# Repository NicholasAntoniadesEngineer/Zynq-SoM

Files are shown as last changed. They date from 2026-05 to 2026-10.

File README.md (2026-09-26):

# Zynq-SoM

A Zynq-7000 system-on-module + carrier board, with `schgen` — a netlist-first
KiCad schematic **and PCB** generator migrating to C++ netlist definitions
into electrically-proven, hand-drawn-quality schematics and a placed,
DRC-clean board (component placement, 3D models, multi-angle renders).

## Native build and test entry point

The C++ migration's Python-free build, dependency bootstrap and complete native
CTest entry point are documented in [`native/ci/README.md`](native/ci/README.md).
Use that path for native production builds. The transitional Python extension
and its build script are retired. Native `schgen check --tests-dir BUILD` runs
the full board, mutation/determinism selftest and complete CTest inventory.
All 393 inventoried tracked Python sources and tests are retired, along with
their dependency and lint configuration. Clean-tree acceptance is still in
progress; the commands below use the native executable.
All verification remains local, as required by the repository's no-CI policy.
No hosted workflow or gate bypass is introduced.

## The layers

1. **`parts/`** — one folder per physical part, named by MPN, GENERATED from
   LCSC/EasyEDA (`native/bin/schgen part-import --parts-root parts --lcsc C…`):
   pin table, symbol, footprint, 3D.
   See `parts/README.md`.
2. **`subsystems/`** — project-agnostic subsystem assets: interface contracts,
   READMEs, SPICE subcircuits and independent reference data. C++ netlist
   factories live in `native/src/authoring_*.cpp`; project adapters supply
   `bind`/`expects`/`buses`/`notes` metadata through the native registry.
   Scaffold a new one with `native/bin/schgen subsystem-new <name>`. See
   `subsystems/README.md`.
3. **`carrier/subsystems/`** — board subsystem assets and generated circuit
   projections. C++ project factories and adapters in `native/src/project_*.cpp`
   define the netlists; the J1/J2/J3 connector contract is extracted live from
   the SoM. Parts are resolved by library identity and named pins. See
   `carrier/README.md` and `carrier/subsystems/README.md`.
4. **The board** — `schgen` derives ALL geometry from netlist topology,
   proves it (netlist-equivalence + ERC + zero-overlap visual gates) and
   links the sheets into one KiCad project.

Plus `som/` — the hand-authored Zynq SoM KiCad project (open
`som/Zynq_SoM.kicad_pro`, KiCad 9+; its custom libs live in `som/lib/`).
The SoM↔carrier contract `carrier/som_interface.json` is extracted
programmatically (`schgen som-interface`), never hand-edited.

## Native regeneration

```bash
native/bin/schgen board --project carrier --timing
native/bin/schgen board --project devkit_mini --timing
# Diagnostic generation without output renders:
native/bin/schgen board --project carrier --no-render --timing
```

`--no-render` is diagnostic: it skips output renders, not mandatory electrical,
geometry or source-policy gates. Omit it for rendered acceptance. Use `--timing`
to measure this native implementation; historical Python timings do not apply.

`schgen build <name>` gates a single sheet (preview into a tempdir, nothing
committed). `schgen board` regenerates the committed outputs in place:
`carrier/Zynq_Carrier.kicad_pro` (open in KiCad), `schematic/`, `renders/`
(golden-snapshot drift detection), `reports/`,
`manufacturing/` (JLC BOM + layout constraints), and
`fpga/Zynq_Carrier_pins.xdc` — Vivado PACKAGE_PIN + IOSTANDARD for every
carrier port on a Zynq PL ball, ball map live-extracted from the SoM and
cross-checked against `som_interface.json` (also standalone: `schgen xdc`).

## The gate model

Every build fails unless every gate passes — the gates are judges, not knobs.
Schematic gates: **netlist** (KiCad's extracted netlist == the declared netlist,
pin for pin, so a junction that merges two nets is caught as a short), **ERC**
(zero errors), **visual** (zero overlap, zero wire crossings, junction-aware
short detection, fits the page). PCB gates: **DRC** (zero KiCad errors),
**3D-model** coverage + placement, **ratsnest** subsystem clustering, and
**connector** mating-face / spacing (off-board mouths, edge-flush). Architecture
+ gate definitions: `schgen/DESIGN.md`.

Local generation always runs its gates; native CTest is an additional check,
not a replacement. `schgen selftest` mutation-tests the gates themselves:
it injects one defect per class (pin swap, deleted wire, relabel, stray
no-connect, foreign-net junction short) and proves a gate kills each, then
builds twice and byte-compares for determinism.

```bash
native/bin/schgen selftest
```

## Process + where to read more

- The working rules and process contract (the immutable LAWs, the gate stack,
  the worktree/commit discipline) live in
  [`WORKING_GUIDELINES.txt`](docs/WORKING_GUIDELINES.txt).
- Layer guides: [`parts/README.md`](parts/README.md),
  [`subsystems/README.md`](subsystems/README.md) (the reusable library),
  [`carrier/README.md`](carrier/README.md),
  [`carrier/subsystems/README.md`](carrier/subsystems/README.md),
  and the engine contract [`schgen/DESIGN.md`](schgen/DESIGN.md).

<!-- schgen:gallery -->
<!-- GENERATED by `schgen gallery` — edits between these markers are overwritten -->
## Generated board + schematics

`schgen board` regenerates the placed-board 3D views, the block diagram and all 37 carrier sheets,
each PNG passing the netlist, ERC and visual gates.

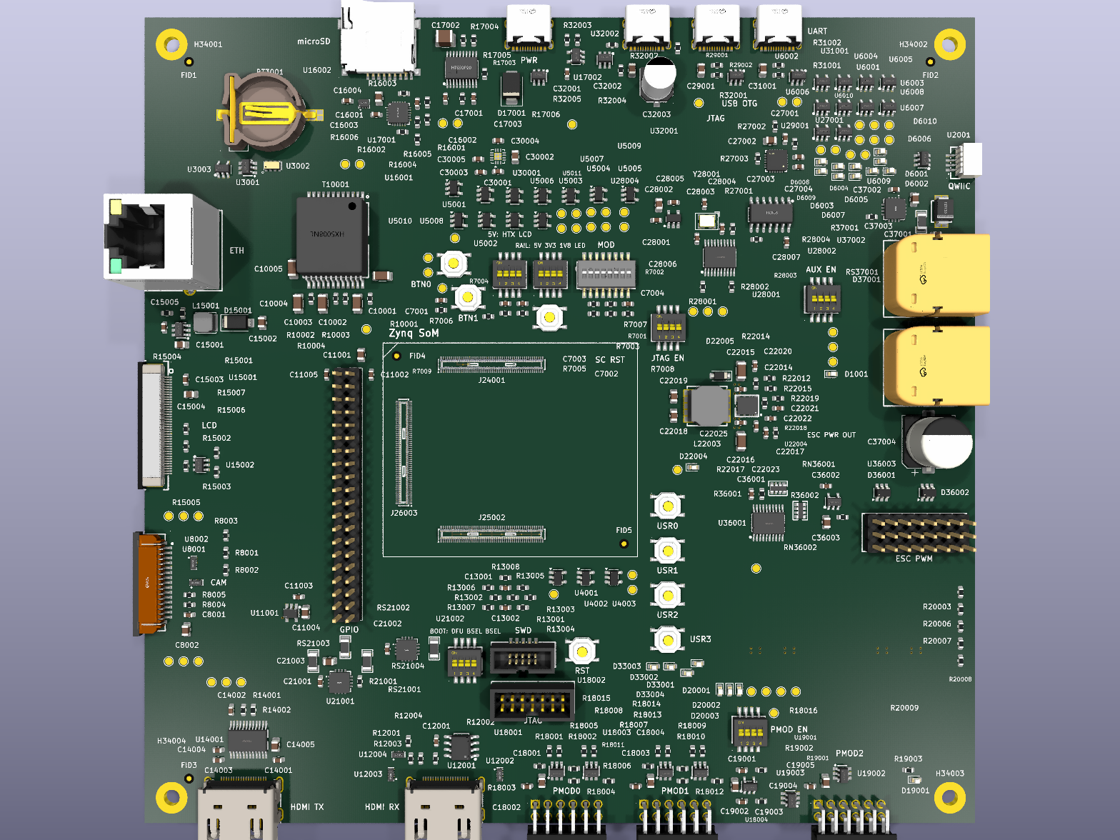
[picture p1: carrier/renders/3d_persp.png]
Generated 3D board render (perspective)


Generated block diagram

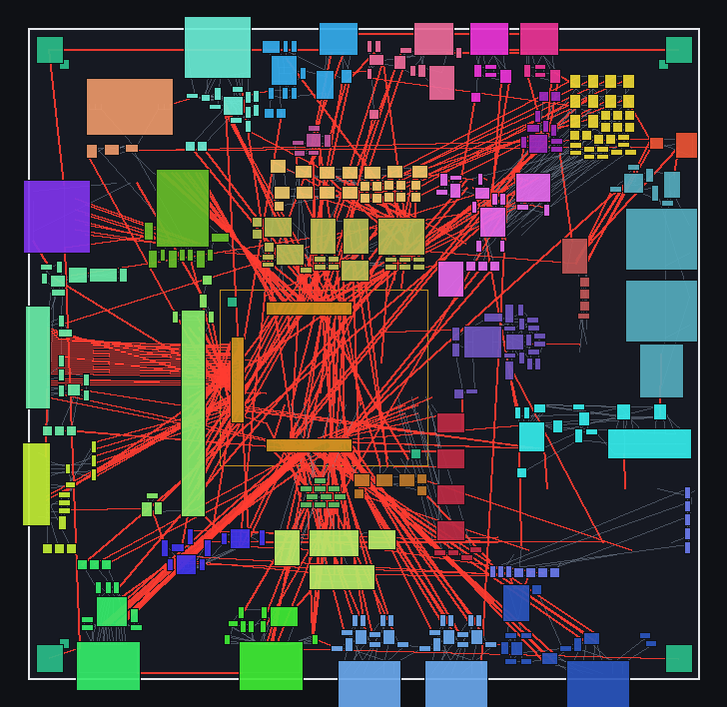
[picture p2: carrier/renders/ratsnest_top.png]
Board ratsnest (top)
[](carrier/README.md#ratsnest-views)<br>**[Ratsnest views](carrier/README.md#ratsnest-views)** — airwires per subsystem.

See **[carrier/README.md](carrier/README.md#generated-3d-board-views)** for all 8 board views + the full sheet gallery (thumbnails + descriptions).
<!-- /schgen:gallery -->

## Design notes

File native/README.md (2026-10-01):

# Native migration

The target is a complete C++ generator, including design loading, placement,
routing, emission, verification, CLI, and tests. The Python extension and the
393 inventoried Python sources/tests are retired. Native kernels alone do not complete the port.
Final acceptance requires zero repository-owned Python sources, tests, helpers,
bindings, or runtime dependencies. KiCad/design data, FPGA HDL, and generated
XDC/Tcl remain in their required hardware formats; generator/tooling code is C++.

## Build without Python

For the native-only full CTest workflow and offline dependency bootstrap, see
[`ci/README.md`](ci/README.md). That additive entry point needs CMake 3.28+ and
explicitly checks installed KiCad libraries. Native contracts retain independent
parity fixtures; no Python test runtime is required.

Install the pinned native zlib-ng compressor using the instructions in
[the manufacturing handoff](tests/data/manufacturing/README.md#explicit-native-installation-and-parent-wiring).
It must be the tested static/PIC compatibility build so existing PNG bytes remain
identical. Supply its installed prefix explicitly; CMake verifies the version
and a compression known-answer test rather than silently selecting system zlib.
The example below uses the local dependency installation under the ignored build
directory. From the repository root:

```sh
cmake -S native -B native/build/standalone -DSCHGEN_BUILD_PYTHON=OFF -DCMAKE_BUILD_TYPE=Release \
  -DSCHGEN_MANUFACTURING_ZLIB_PREFIX="$PWD/native/build/deps/zlib-ng"
cmake --build native/build/standalone --parallel
ctest --test-dir native/build/standalone --output-on-failure
native/bin/schgen --help
```

For repeated local C++ development with Ninja and ccache installed, run these
from `native/` (CMake 3.20+ for presets): `cmake --preset native-fast`, then
`cmake --build --preset native-fast` and `ctest --preset native-fast-offline`.
The preset keeps compiler caches under ignored `native/build/`; it neither
downloads dependencies nor enables Python. Ninja avoids Make's broad object
rebuilds when unrelated per-source compilation options change. Do not build
different build directories concurrently: they currently publish the same CLI
and catalogs in the source tree.

This is also the default configuration: enabling retired Python bindings is an error. The build
uses C++17, libxml2 (for KiCad netlists), native zlib-ng (for exact manufacturing PNGs),
and Poppler C++/libpng (for schematic rasterization), without discovering Python,
installing nanobind, or fetching dependencies. Live SoM extraction requires
`kicad-cli` on PATH; it is invoked directly, never through a shell.

The native CLI supports `self-check`, `catalog-compile`, `circuit-compile`,
`project-check`, `circuit-check`, `som-interface`, `link`, `bom`, `xdc`, `vivado`, `fpga`, and
`devicetree`, `design-rules`, `testpoints`, `constraints`, `powertree`, `thermal`,
`part-rules`, `bom-values`, `footprint-pads`, `pin-completeness`, `symbol-law`,
`spice`, `firmware`, `manual`, `scfw`, `testplan`, `power-sequence`, and `selftest`.
The native `board` command performs full generation with mandatory native audit
providers; its complete source-audit acceptance is still in progress. Other
integrated commands include `build`, the four-sheet `devkit` example, `nets`,
`subsystem-check`, `carrier-check`, and the native experiment commands.
`check --tests-dir BUILD` runs full board generation, mutation/determinism
selftest and every configured native CTest, requiring complete passing JUnit
evidence. It does not build its selected test directory or waive failing gates.
Unsupported commands fail.

`subsystem-new NAME` creates a C++ source/header/test package with retained
README, SPICE and JSON metadata. It never overwrites an existing destination.
New packages are opt-in with `-DSCHGEN_SUBSYSTEM_PACKAGES='name;another'`;
the generated CMake registration connects real factories to the immutable
native registry. The initial unimplemented builder deliberately fails its test.

The PCB verification aggregate now shares one geometry snapshot and MST across
the real placement, connector, ratsnest, fanout, return-stitch and escape gates.
Both live projects are checked against independent committed reports. This is
not yet the full-board verdict: external DRC and non-PCB gates remain separate.
The native DRC runner invokes KiCad directly with a bounded timeout and private
report directory. Missing/malformed reports and nonzero tool exits are errors,
not empty successful findings. Its transitional adapter contains no DRC logic.
Use `native/bin/schgen pcb-drc --project NAME` to check an existing board. The
full build reuses validated severity counts from its first DRC report instead
of refilling and checking the same board twice. Reports lacking severity retain
an explicit errors-only fallback; warning and unrouted findings remain visible.

`selftest` runs the complete 63-mutation suite through real KiCad exports, ERC,
native gates, geometry checks, and fresh native worker processes. It does not
invoke Python. Worker failures and missing footprint libraries fail the run;
they cannot count as mutation kills. The separate `self-check` remains only a
small kernel smoke test. Live contract tests carry the `live-kicad` CTest label.

The native core includes complete floorplan search/compose/export, immutable
PCB-check snapshots, and board/project/design-rule emission. Frozen independent
fixtures verify both projects' exact outputs and mutation/error cases. The
transitional PCB pipeline now uses the native writers and shares one prepared
snapshot across its PCB gates, avoiding repeated source parsing. Standalone gate
calls still prepare fresh inputs; no global cache hides placement or file edits.
The original return-path-v1 failures remain separate from return-stitch coverage;
this migration does not waive them. Standalone `floorplan` and `compose` are
registered native commands: floorplan writes documents or exports a spec;
compose measures, ranks repairs with `--repair --dry-run`, or applies a repair
subject to full board gates and rollback on failure. Their ordinary, live-KiCad
and apply contracts are registered in CTest. This is not a claim of complete
source-audit or whole-board acceptance.

```sh
native/bin/schgen project-check --project carrier
native/bin/schgen project-check --project devkit_mini
native/bin/schgen circuit-check --project devkit_mini
native/bin/schgen design-rules --project devkit_mini
native/bin/schgen testpoints --project devkit_mini
native/bin/schgen fpga --project carrier --output /tmp/carrier-fpga
native/bin/schgen devicetree --project carrier --output /tmp/carrier_pl.dtsi
native/bin/schgen bom --project carrier --qualified-refs --output /tmp/carrier-bom.csv
```

`fpga` generates XDC and Vivado Tcl from one live extraction, validating both
before publication. Each output is atomically replaced. Project selection is
explicit (`--project`), then `SCHGEN_PROJECT`, then `carrier`; use `--repo` when
running outside the repository root. Circuit discovery and loading require
canonical `<project>/subsystems/<name>/circuit.json`, not authoring Python.
Function/rail/strap policy is in each project's `som_mapping.json`.

`circuit-check` resolves actual library symbols and checks every pin and internal
input driver; JSON pin metadata is not a substitute for physical symbol pins.
`link` also enforces symbol-backed completeness before linking. The native core
now includes complete symbol loading, schematic emission, routing, netlist and visual
validation stages, tested against frozen inputs and output bytes. Netlist verification
shares the hardened KiCad process/XML boundary with SoM extraction, and checks
connectivity plus NC markers against embedded symbol geometry. Full board
orchestration is native; complete acceptance is tracked below.
The hierarchical schematic stage is independently available as
`native/bin/schgen board-schematic --project NAME -o DIRECTORY`. It generates
the real routed sheets and root hierarchy, preserves persistent reference bands,
and runs live KiCad connectivity checks. Per-sheet exports use bounded workers
with deterministic result collection. This command is not a substitute for the
remaining PCB, manufacturing and complete-board verification stages. Both
supported projects' native root and child schematics match the committed bytes.

The complete schematic placer now runs natively: topology classification,
fanout, regulator templates, chain layout, probe rows, retry expansion and
pagination all use the same typed engine and router. Frozen full-board and
isolated topology contracts cover ordered geometry and page boundaries. The
legacy Python engine is removed; remaining adapters preserve caller-owned
symbol snapshots and intermediate page metadata without reloading sources.
Native mutation proofs exercise missing-decoupler and incorrect clamp-layout
failures through the real completeness, routing and visual gates.

Design-rule verification (decoupling, I2C pull-ups, reset RC, configuration straps,
exposed pads), test-point coverage and their reports also run in C++. The native
commands print diagnostics, return nonzero on findings, and write a report only
when `--output` is supplied. They accept subsystem selection; board-wide pull-ups
outside the selected sheets are intentionally absent from that check.
Symbol-backed completeness remains a separate mandatory gate (`circuit-check`).
Power-tree analysis and SVG, thermal analysis with emitted-copper evidence, and
part-rating checks now execute in C++. Frozen report contracts cover both projects,
policy mutations and supplied power results. Thermal credit requires real copper
evidence; an absent PCB does not silently grant cooling credit. Transitional
adapters preserve caller-owned policy tables and typed numeric fields.
BOM-value normalization, footprint-pad coverage, pin/NC completeness, symbol
provenance and analytic/SPICE checks also run natively. Their frozen contracts
include poisoned values, disconnected pins and malformed geometry. Optional
ngspice cross-checks use a shell-free bounded process with private temporary
decks and real measurements; absence of ngspice retains the analytic gate.
Connectivity and symbol metadata are indexed once per snapshot. Mutable caller
inputs require a new snapshot; caches never silently reuse a previous board.

Bring-up facts, firmware contracts, SC scaffolds, the manual, test plan and
power-sequence SVG now use native typed inputs. Independent fixtures cover both
projects and changes to GPIOs, feedback values, addresses and required sheets.
Live U9 extraction remains authoritative. The sequence walker rejects reachable
cycles instead of looping indefinitely. Generated SC code still has a known
undefined FMC EEPROM macro, and RTC battery/charging guidance is inconsistent;
these pre-existing output defects are not treated as successful compile checks.

Carrier and devkit XDC/Tcl, and carrier BOM, match the established output bytes.
Device-tree output changes only generator/source provenance comments. Native
contract tests cover extraction, mapping, linking, project isolation, rendering
and validation failures. Clean native full-render acceptance passed for both
boards at `29d43472` on October 1, including the source and ledger audits
(66 C++ files, 155 registered transforms). The devkit's two missing
I2C pull-ups and nine uncovered probe requirements are corrected with physical
parts, without new waivers. Probe-only ports now export hierarchical sheet
connections; regulator discovery excludes measurement pads, and PCB placement
handles connector-sheet auxiliaries without moving the fixed mezzanines.

The transitional Python bindings and build script are retired. The standalone
CLI and native tests link the same `schgen_core` library; engine sources compile
once per build directory. Preserve the per-source floating-point settings:
these are part of the deterministic-output contract.

Build catalogs depend on their JSON inputs and regenerate when those inputs change.
Compilers publish complete catalogs by atomic replacement, so existing mapped
readers retain their snapshot during a rebuild. Close and reopen a catalog to
read its new version. Failed publication leaves the previous file untouched.
The transitional circuit adapter uses project-scoped `native/circuits.bin`
outputs under each project, while the parts catalog is shared. Native project
commands read validated JSON directly and do not depend on interpreter caches.
Build directories share the in-tree binary and catalog outputs, so build them
sequentially.

## Migration acceptance and remaining design work

`run_board_pipeline` is now compiled into the native library, with composed
schematic, electrical, PCB, document and audit stages. Its contracts compare
all 49 live-authored carrier/devkit circuit snapshots with canonical hardware IR,
exercise real KiCad connectivity/ERC, and reject missing mandatory stages.
The caller must open the part catalog before authoring. The native full-board
CLI installs reviewed ledger providers after loading actual board inputs.
Missing declarations or manifests fail explicitly. Clean full-render acceptance
now passes, with all 226 CTests having successful final coverage (222 from the
full run plus four corrected harness reruns, not a single 226/226 run).
See `benchmarks/2026-10-01-migration-acceptance.json` for pinned timings and scope.
Source auditing remains the dominant runtime cost. Advisory return-path,
golden-drift and coverage findings remain visible; neither board is fully routed
or claimed fabrication-ready. Coverage lint uses every wired-sheet part,
including unplaced parts. Successful migration does not certify every historical
hardware or generated-firmware design decision.

Firmware source provenance now reads canonical circuit JSON and compiled factory
registrations rather than checking for Python constructors. Independent source
inventories cover both projects, reject damaged/missing registered inputs, and
remain identical in a Python-free fixture tree. Live contracts separately check
the new provenance and unchanged generated hardware logic.

`part-import --parts-root DIRECTORY --from-json FILE` converts recorded EasyEDA
responses entirely in C++; offline mode never calls a transport. Use `--lcsc ID`
instead for an explicitly online import, `--name NAME` to override the part name,
and `--overwrite` only when replacing existing files is intended. Catalog refresh
is separate and opt-in via `--catalog FILE`. Publication validates all targets
first and replaces each file atomically, but is not a multi-file transaction.
The native tests compare 62 recorded parts (three model variants each) byte for
byte, exercise the real offline CLI and reject malformed input, HTTP failures,
oversized/truncated responses, duplicate models and symlink output targets.

The native `pcb-stage --project NAME -o DIRECTORY` command now performs live
KiCad netlist extraction, immutable input loading, floorplanning, placement,
escape planning and PCB/project/rules emission. It is a construction stage,
not a replacement for the independent full-board gates. Live contracts compare
both project PCBs byte-for-byte with their existing generated references.
Native manufacturing contracts cover assembly planning, Markdown and all 52
reference PNGs. Assembly rendering uses at most four workers with stable output
ordering; a measured 38-image carrier run improved from approximately 0.97 s to
0.39 s, including transitional transport and file publication. This is an image
stage measurement, not an end-to-end board-build speedup claim.
The equivalent ratsnest run (36 PNGs plus SVG) measured approximately 1.79 s
through the previous renderer and 0.68 s through the bounded parallel C++
renderer, with all output bytes unchanged.

Standalone `assembly`, `ratsnest`, `si-constraints`, `fab-profile` and `manifest`
commands now use native implementations. Explicit output directories retain the
project layout (`docs/`, `renders/`, `manufacturing/`). `preflight` uses native
stock/price/alternate analysis and a shell-free HTTPS-only `curl` subprocess;
it requires network access only when that optional command is invoked. Transport
errors fail explicitly instead of being reported as a confirmed missing part.
Its offline contracts use injected provider responses and never contact vendors.

Remaining work is native source-purity/audit integration, standalone geometry
commands, final Python consumer removal and clean-tree full-board acceptance.
The standalone Python experiment scripts are retired; use `chir-rung`,
`w11-sweep`, `w12-bound`, `w12-stageprobe` and `dump-circuits` on the native CLI.
Independent native contracts retain captured reference logic and negative cases.

Each stage must preserve electrical connectivity and its relevant gates, then
compare generated artifacts against the established reference. Record measured
end-to-end performance separately from kernel benchmarks. Remove Python source,
bindings, and Python build dependencies only once their consumers have moved.
Final acceptance requires generating both supported projects and running their
verification from a clean build without Python; pre-existing failures must be
reported, not suppressed.

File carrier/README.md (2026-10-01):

# carrier — the generated carrier board

Open `Zynq_Carrier.kicad_pro` with the KiCad version specified in
[`native/ci/README.md`](../native/ci/README.md). From the repository root,
regenerate the board outputs with `native/bin/schgen board --project carrier`
(the schematics, the placed
`Zynq_Carrier.kicad_pcb`, 3D renders, BOM, FPGA constraints, firmware contract,
and docs).

## Architecture (the locked decisions)

The carrier hosts a Zynq-7000 SoM over the J1/J2/J3 mezzanine:

- **Power input is USB-C PD only**, 20 V / 3 A via the FUSB302B, behind a
  TPS26631 eFuse with soft-start (controlled inrush + inlet OVP/OCP). No
  barrel jack.
- **The SoM is a 4.2–5 V module — it must NEVER see the 20 V rail** (P0, the
  most important electrical decision). An **always-on `+5V_SOM` buck**
  (its own `power_som` sheet) feeds the SoM's J1 VIN pins; always-on because
  PD negotiation is circular (the system controller must boot first).
- **Carrier bucks win over the SoM's exported rails** — the SoM's +3V3/+1V8
  on J1 are isolated (NC / TP-only); carrier rails are +5V, +3V3, +1V8, plus
  per-module **gated rails** (+5V_USB, +3V3_SD, the HDMI/LCD/CAM/PMOD/AUX
  rails) sourced by bring-up load switches.
- **Bring-up is staged with switches**: a DIP switch AND a system-controller
  GPIO override drive every regulator/module enable; per-rail power-good LEDs;
  rails come up one at a time. New board-services HW (ID-EEPROM, RTC, QWIIC,
  watchdog) sits behind the same gated `+3V3_AUX` rail and a PCA9306 I2C
  isolator (so the gated bus can never back-power the always-on management I2C).
- **microSD carries a mandatory 1.8 V ↔ 3.3 V level translator** (TXS02612):
  the SoM exposes SDIO at 1.8 V, but SD cards init at 3.3 V.
- **Stackup is JLCPCB 4-layer JLC04161H-7628**; its impedance geometry drives
  the exported layout constraints (90 Ω USB, 100 Ω TMDS/LVDS/MIPI). The user
  owns the PCB outline + placement — the floorplan kit is a suggestion.

## The subsystem / adapter pattern

A board sheet is one Python netlist under `subsystems/` — **the only
hand-written layer**. There are two flavours:

- **Thin adapters over the reusable library.** A portable subsystem lives in
  the project-agnostic top-level [`subsystems/`](../subsystems/README.md)
  library with ABSTRACT port/rail names; the carrier consumes it with a tiny
  adapter that declares ONE module-level `META` dict and forwards it —
  `return _lib.circuit(META)`. `META["bind"]` renames the abstract nets to the
  carrier's real net names (order-preserving, so the emitted sheet is
  byte-identical to a hand-written one); `expects` / `buses` / `notes` carry
  the project-specific linker deferrals, bus names and house-style prose. The
  contract is `schgen/core/subsystem.py` (`Meta`); a typo'd top-level key is a
  hard `CircuitError`. 17 subsystems use the reusable library this way (usb_pd, usbc_otg,
  uart_bridge, usb_jtag, ethernet, hdmi_tx, hdmi_rx, lcd, microsd, camera, pmod,
  pmod_expansion, pd_input, power, rj45_connector, usb_uart_connector,
  usb_jtag_connector) — see [`subsystems/README.md`](../subsystems/README.md).
- **Carrier-specific glue stays local.** Sheets that only make sense for this
  board — the J1/J2/J3 connector sheets, the bring-up + power + power-monitor
  sheets, the board-services HW, the carrier connectors — are authored directly
  under `subsystems/` as full netlists. See
  [`subsystems/README.md`](subsystems/README.md) for the authoring guide.

Either way the rule is the same: **the .py is the NETLIST, never geometry.**
No coordinates, no wire plans, no text positions; a purity gate AST-scans every
subsystem and fails the build if it defines `placer` or imports a geometry API.
All placement is derived from circuit topology by `schgen/layout/place.py`.

- `subsystems/` — the authored netlists (adapters + local glue), the only
  hand-written layer; see `subsystems/README.md`.
- `Zynq_Carrier.kicad_sch` + `schematic/` — the root sheet + sub-sheets
  (hierarchy mode, board-unique references), committed.
- `renders/` — one PNG per sheet, committed and reviewable on GitHub;
  `golden.json` holds perceptual hashes — drift warns, `schgen board
  --bless` accepts intentional changes.
- `reports/` — per-sheet ERC, gate verdicts, link report, board netlist
  gate: the proof travels with the design.
- `manufacturing/` — `bom_jlc.csv` + JLC04161H-7628 layout constraints.
- `fpga/` — `Zynq_Carrier_pins.xdc`, GENERATED Vivado pin constraints
  (`schgen xdc`): every carrier port on a Zynq PL ball through J2/J3,
  ball map live-extracted from the SoM project (never hand-typed),
  cross-checked against `som_interface.json` (stale contract = build
  FAIL), IOSTANDARD from the PLAN VCCO rail map.
- `som_interface.json` — the SoM↔carrier J1/J2/J3 contract, extracted
  programmatically (`schgen som-interface`), never hand-edited.
- `nets.py` — the GENERATED cross-sheet net-name contract
  (`schgen nets`).
- `research/` — the per-subsystem engineering dossiers (datasheet-grounded,
  hand-written): [`bringup_power_gating.md`](research/bringup_power_gating.md),
  [`camera_csi.md`](research/camera_csi.md),
  [`debug_boot_pmod.md`](research/debug_boot_pmod.md), [`fmc.md`](research/fmc.md),
  [`lcd_backlight.md`](research/lcd_backlight.md), [`power_mon.md`](research/power_mon.md),
  [`thermal_bucks.md`](research/thermal_bucks.md),
  [`usb_jtag_pmod_expansion.md`](research/usb_jtag_pmod_expansion.md),
  [`user_io.md`](research/user_io.md), [`wave3_function_map.md`](research/wave3_function_map.md).
- `docs/` — the design-documentation packet:
  [`DESIGN_SPEC.md`](docs/DESIGN_SPEC.md) (theory of operation: mezzanine
  interface, power architecture + sequencing, every subsystem),
  [`COMPLIANCE.md`](docs/COMPLIANCE.md) (per-interface checklists: HDMI,
  Gigabit Ethernet, USB 2.0, MIPI CSI-2, USB-PD, SoM bank-35 IO header),
  [`BRINGUP.md`](docs/BRINGUP.md), [`TEST_PLAN.md`](docs/TEST_PLAN.md),
  [`FLOORPLAN.md`](docs/FLOORPLAN.md), and the generated diagrams
  `block_diagram.svg` / `power_tree.svg` / `power_sequence.svg`.

## Assembly + bring-up procedure

Human steps the netlist cannot carry. Everything else — every component value
and every bind decision — is a registered basis entry in `carrier/basis.py`
(`REGISTRY` for values, `BINDS` for net binds), not prose.

**Before fab**

- **QWIIC pad order (`board_qwiic` J1).** Pads 1–4 are the QWIIC standard
  GND / +3V3 / SDA / SCL looking into the receptacle; pads 5/6 are the shell
  tabs. Confirm pad 1's location against the J1 footprint silk before release —
  a swapped power pad damages every external module plugged in.
- **Chassis star stitch (`mechanical`).** `GND` ↔ `CHASSIS_GND` must be joined
  at exactly one point in copper. See
  [`subsystems/mechanical/README.md`](subsystems/mechanical/README.md).

**Stuffing**

- **RTC backup cell (`board_services` BT1).** Fit a **rechargeable ML1220**
  (Mn-Li). The SC firmware enables the RV-3028 trickle charger, so the cell
  tops up whenever the board is powered. Do **NOT** fit a primary CR1220 (it
  would be charged) and do **NOT** fit a LIR Li-ion (its 4.2 V charge target
  exceeds the 3.3 V supply). The KH-CR1220-2 holder accepts both 12.5 mm
  chemistries, so the holder will not stop the wrong cell.
- **HDMI-RX termination (`hdmi_rx_term`).** The 8 × 49.9 Ω sink terminations
  belong physically next to Zynq bank 33, not at the connector. An optional
  0 Ω / ferrite may be fitted in the +3V3 → AVCC trace to island the supply.
- **Camera terminations (`camera` R1–R3).** Place the 100 Ω differential
  terminations at the **SoM-connector** end of the traces, not at the FFC.

**Powering up**

- Every rail and module enable is a DIP switch ANDed with a system-controller
  override, so a blank SC still boots "switches only". Bring rails up one at a
  time and read the per-rail power-good LED.
- `+5V_SOM`, `+3V3_SC` and the debug island (`+5V_DBG` / `+3V3_DBG`, alive only
  with the debug USB-C cable plugged) are **always-on by design** — they are not
  gated and will be live before you touch a switch.
- Probe every EN line and every gated rail at its own test point; the gated
  rails are probed at the SY6280 output, on the source side of the module
  connector.
- ESC leads on the `motor_pwm` header use SIG + GND only — keep the ESC's own
  BEC off the +5 V row.

## Build + gate discipline

There is **no CI** — instead every local `schgen build <sheet>` /
`schgen board` runs the full gate stack and exits non-zero on any failure, so
nothing un-gated ever gets committed. The committed `reports/` are the proof.
The gates (never edited to pass — LAW 4; strengthening one is the work,
loosening it is forbidden):

- **PURITY** — the subsystem source is netlist-only (no `placer`, no geometry
  import); AST-scanned before execution.
- **MODEL COMPLETENESS** — every pin is netted or explicitly `c.nc()`'d; every
  input is driven.
- **NETLIST** — KiCad's own extracted netlist == the declared netlist, pin for
  pin (the unfakeable electrical proof — catches shorts, opens, single-pin
  nets, NC-cheats, name drift).
- **ERC** — kicad-cli ERC, zero errors.
- **VISUAL** — zero overlap, zero crossings, fits the page (no exemptions).
- **CC short/open** — an independent net-blind union-find over the emitted
  geometry, a 2nd oracle that agrees with the netlist gate pin-for-pin.
- **BOARD GATE + LINK** — every linked net merges correctly across sheets;
  typed-port contract resolved (diff pairs, I2C, sd_bus levels, `expect=`
  deferrals).
- **POWER-TREE / TEST-POINT / THERMAL / DESIGN-RULE / SPICE** — per-regulator
  headroom, a probe per rail/bus, per-device Tj, decoupling/pull-up/strap
  completeness, and divider/feedback/ramp setpoints.
- **PCB** — the placed `Zynq_Carrier.kicad_pcb` passes DRC (zero KiCad errors),
  3D-model coverage + placement, ratsnest subsystem clustering, connector
  mating-face (off-board mouths) + spacing, and refdes-overlap; multi-angle 3D
  board renders are written for visual review.

`schgen selftest` mutation-tests the gates themselves (it injects one defect
per class — pin swap, deleted wire, relabel, stray NC, foreign-net junction
short — and proves a gate kills each) and builds twice for byte-determinism
(across PYTHONHASHSEED). Reusable subsystem packages also carry an offline
local `test_<name>.py`; cross-board gates stay aggregated at board level.

The working rhythm: build → read the gate verdicts → **open the render PNGs and
inspect them like a PCB reviewer** (the render is the deliverable) → commit per
verified unit. Heavy/parallel work runs in isolated git worktrees harvested
sequentially; deterministic output means a regen on the merged state produces
zero artifact diff. The full process contract is
[`../WORKING_GUIDELINES.txt`](../docs/WORKING_GUIDELINES.txt).

<!-- schgen:gallery -->
<!-- GENERATED by `schgen gallery` — edits between these markers are overwritten -->
## Generated 3D board views

The placed board rendered from 8 angles by `schgen board` (kicad-cli, the real component 3D models) — regenerated and committed every build, just like the sheets below.

| | | | |
|---|---|---|---|
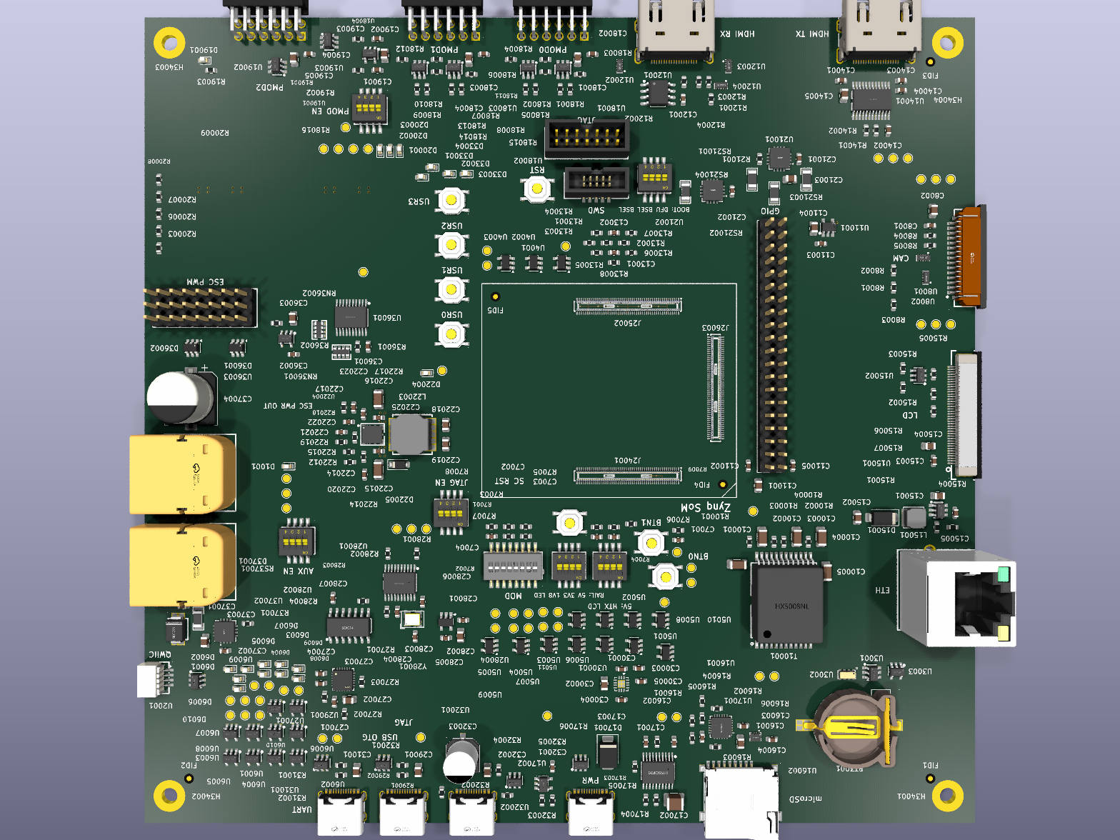
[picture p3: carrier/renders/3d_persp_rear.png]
Perspective (rear)
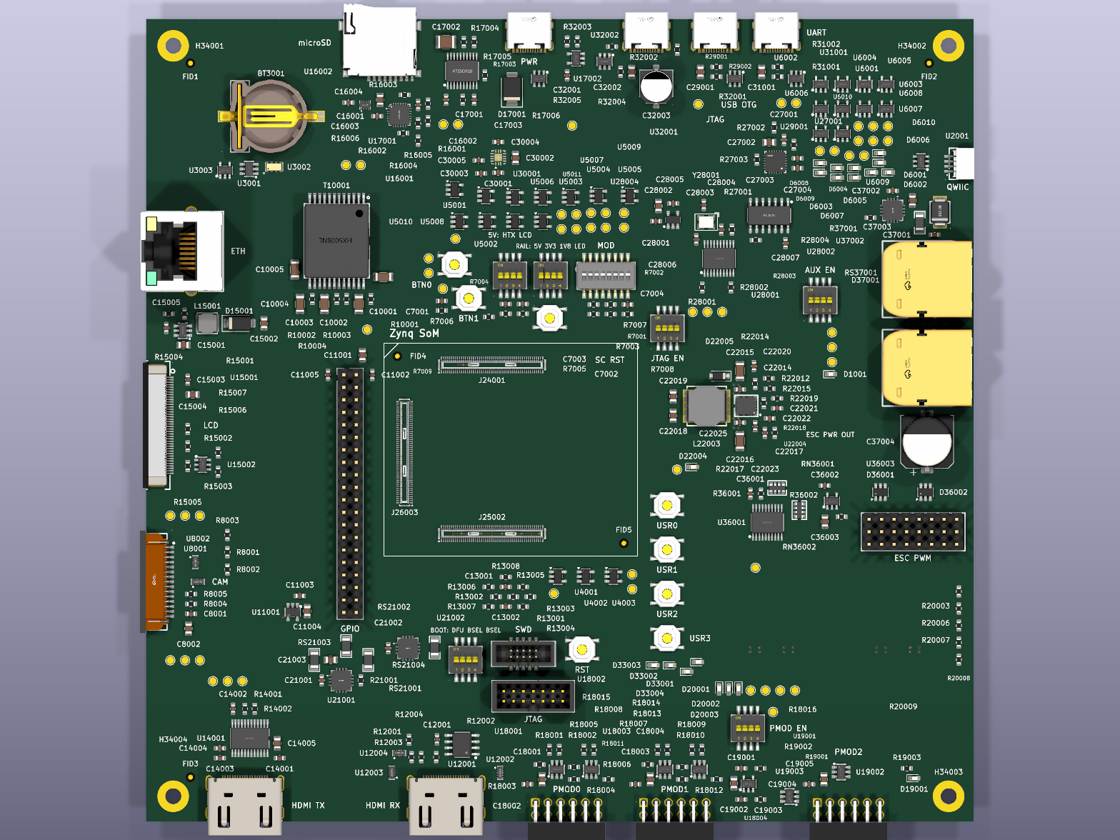
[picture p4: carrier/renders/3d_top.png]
Top
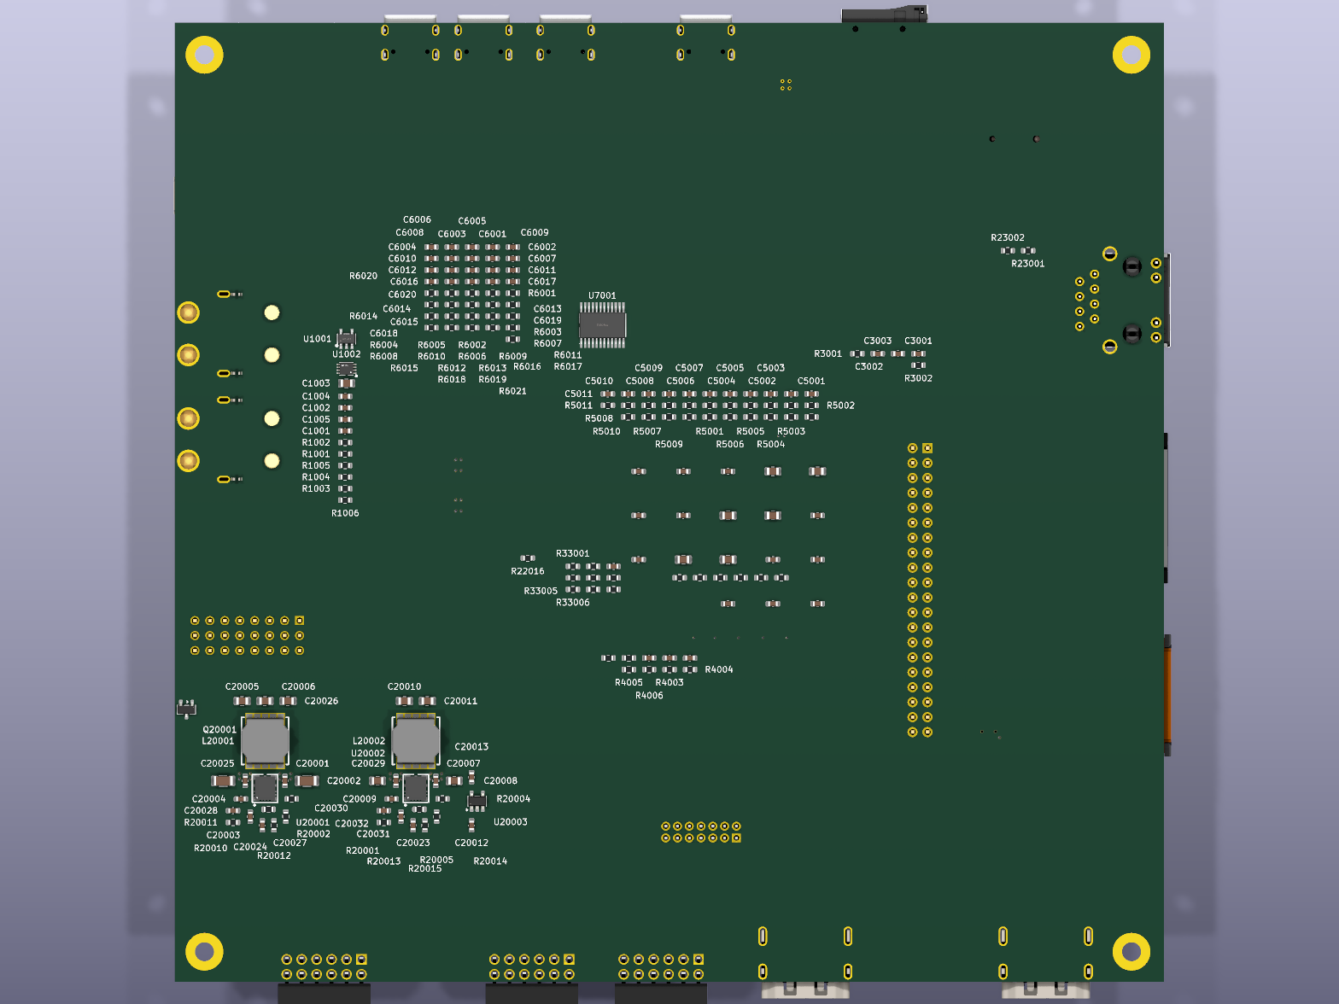
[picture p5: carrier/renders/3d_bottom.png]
Bottom
| [Perspective (front)](renders/3d_persp.png)<br>**Perspective (front)** | [](renders/3d_persp_rear.png)<br>**Perspective (rear)** | [](renders/3d_top.png)<br>**Top** | [](renders/3d_bottom.png)<br>**Bottom** |
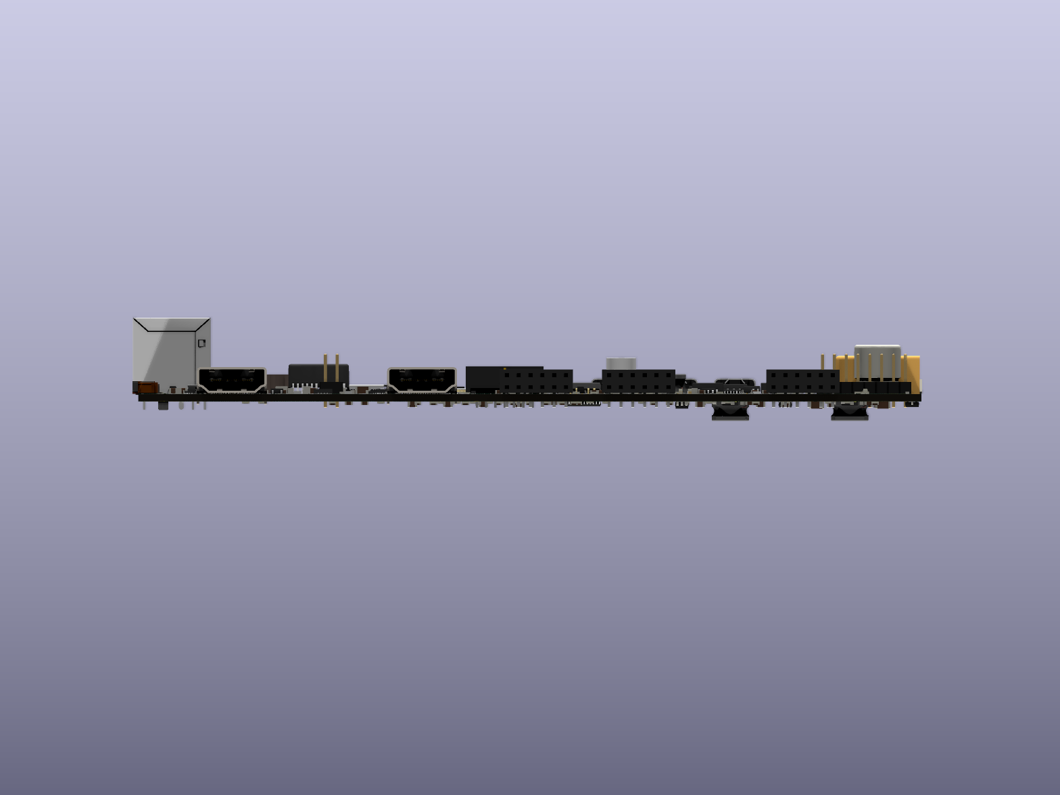
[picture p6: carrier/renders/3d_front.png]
Front edge
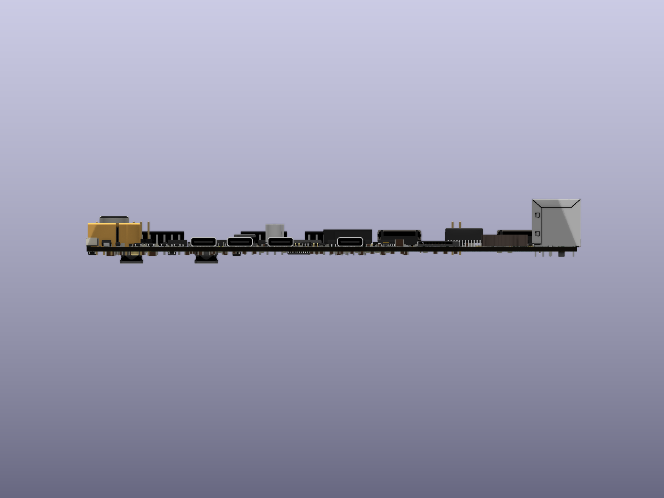
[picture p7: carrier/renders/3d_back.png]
Back edge
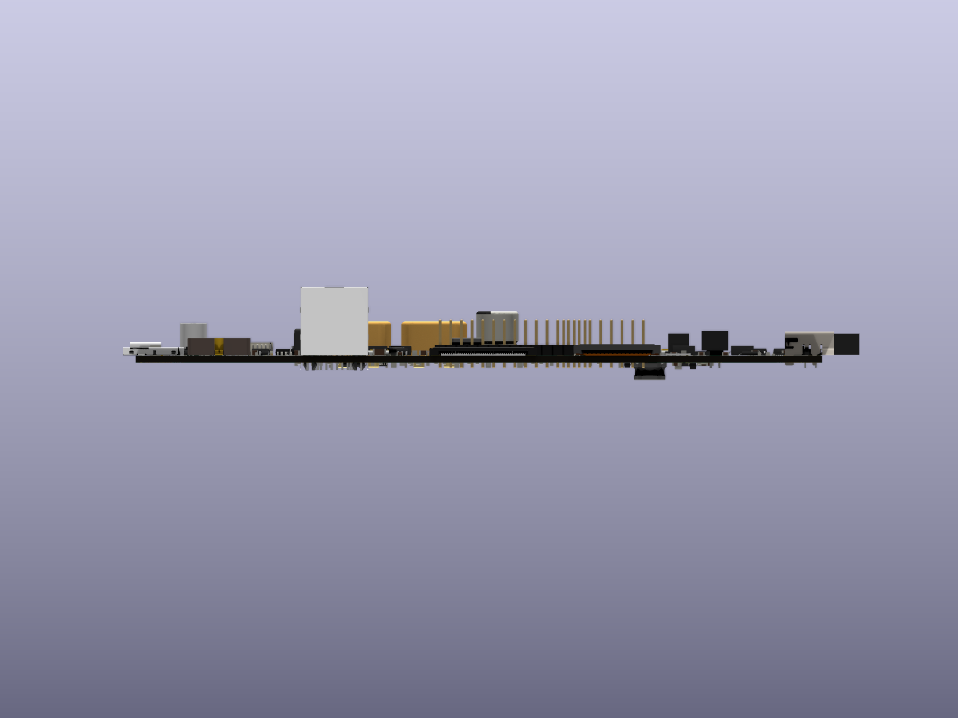
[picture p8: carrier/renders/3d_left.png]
Left edge
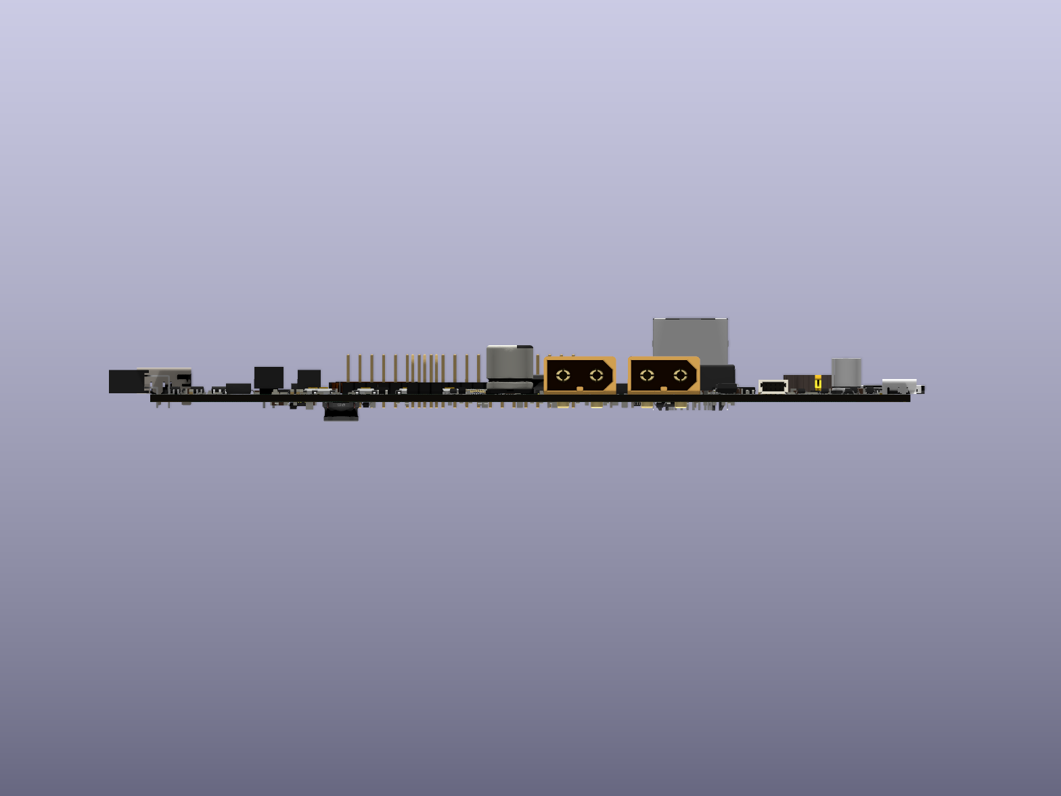
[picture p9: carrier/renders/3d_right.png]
Right edge
| [](renders/3d_front.png)<br>**Front edge** | [](renders/3d_back.png)<br>**Back edge** | [](renders/3d_left.png)<br>**Left edge** | [](renders/3d_right.png)<br>**Right edge** |

## Ratsnest views

Placed-board airwires, regenerated by `schgen board`: blue/orange = the subsystem's parts (top/bottom side), steel = SoM, green = intra-subsystem, red = to the SoM. `wired` = in `placement.wired_sheets`.

| | |
|---|---|
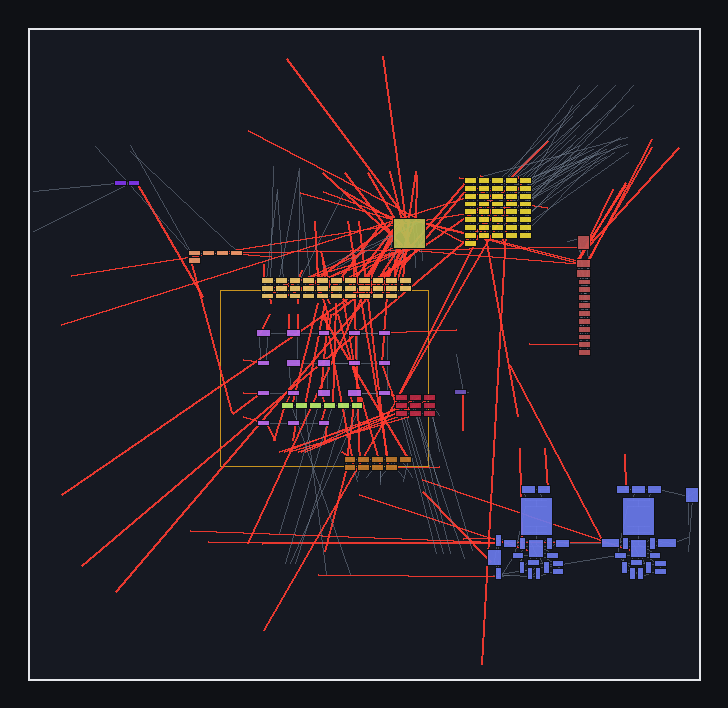
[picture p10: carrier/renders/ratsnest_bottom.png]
Board (bottom)
| [Board (top)](renders/ratsnest_top.png)<br>**Board (top)** | [](renders/ratsnest_bottom.png)<br>**Board (bottom)** |
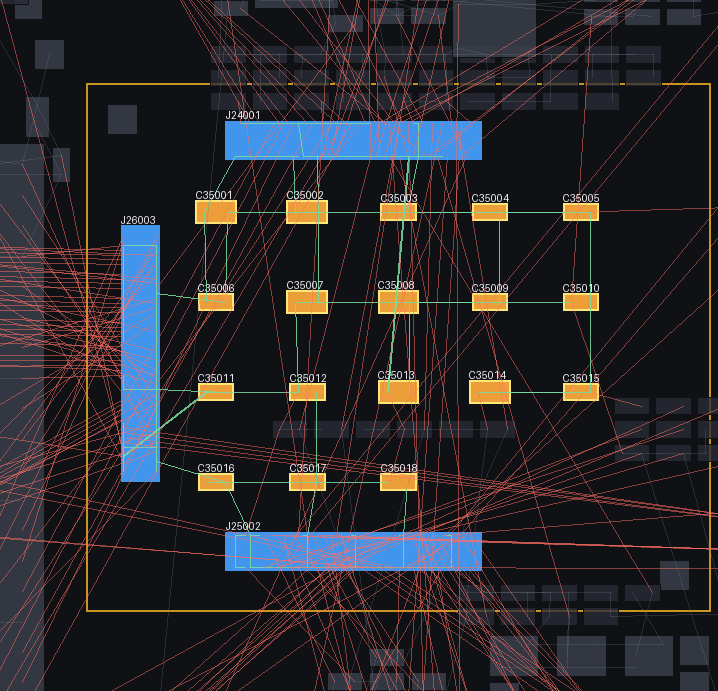
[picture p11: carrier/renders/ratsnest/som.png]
SoM region
| [](renders/ratsnest/som.png)<br>**SoM region** | |

| | | | |
|---|---|---|---|
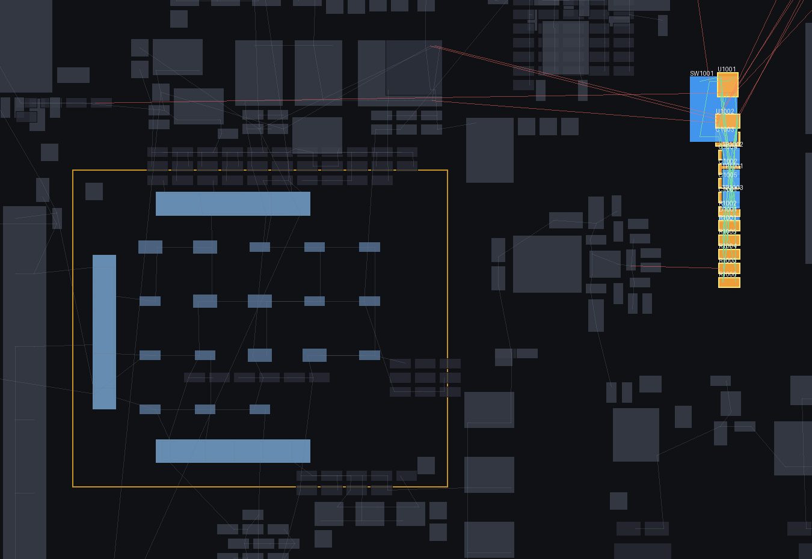
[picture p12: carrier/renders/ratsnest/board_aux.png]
board_aux
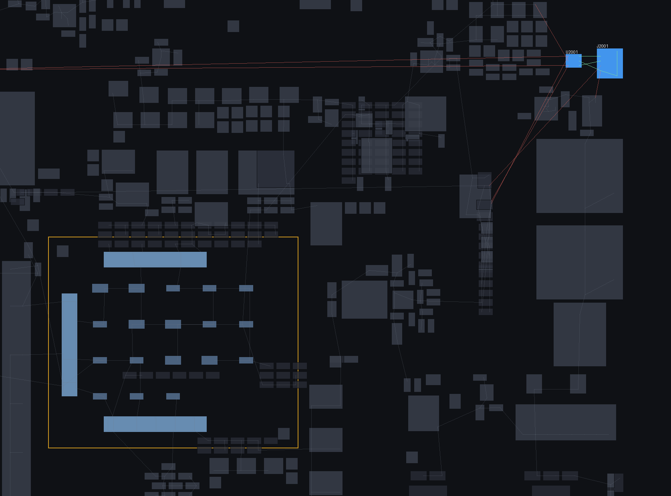
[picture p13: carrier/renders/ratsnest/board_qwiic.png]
board_qwiic
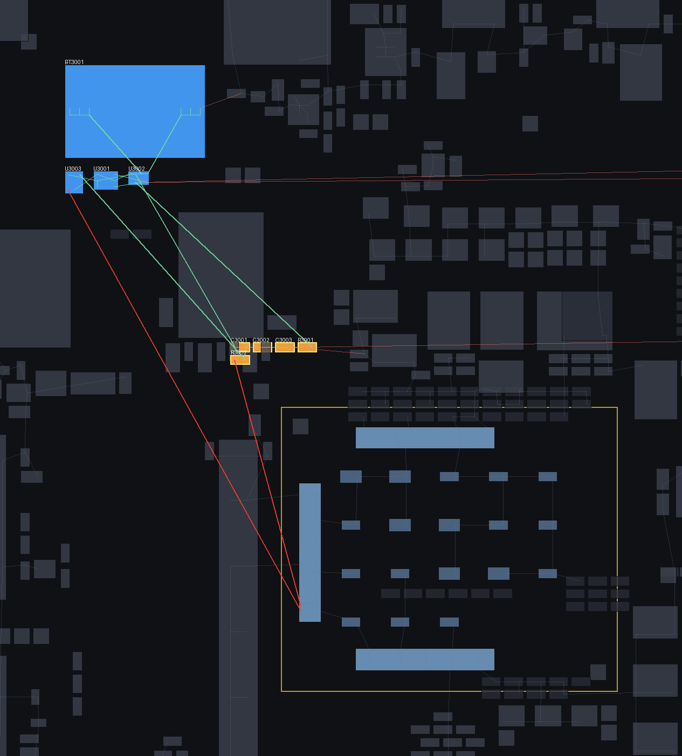
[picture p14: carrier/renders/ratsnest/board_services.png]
board_services
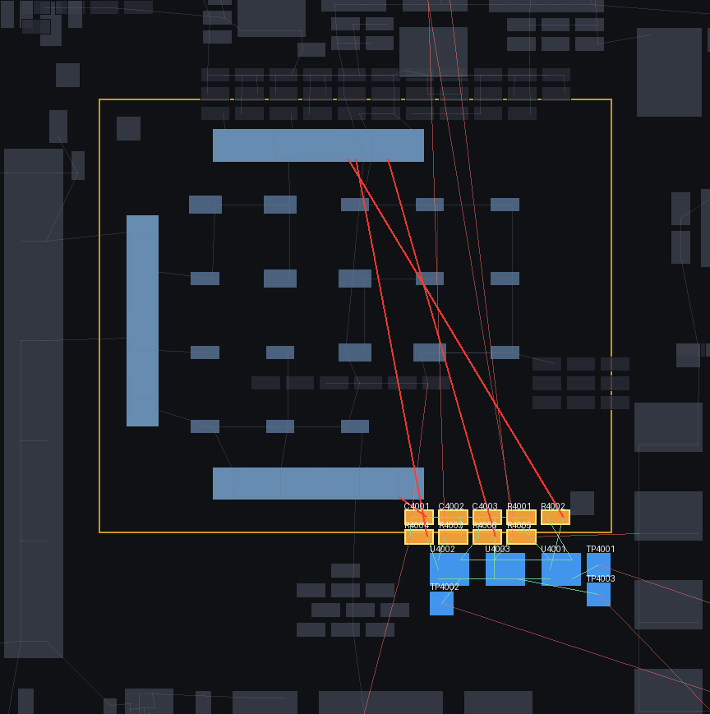
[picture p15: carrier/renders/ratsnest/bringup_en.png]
bringup_en
| [](renders/ratsnest/board_aux.png)<br>**board_aux** | [](renders/ratsnest/board_qwiic.png)<br>**board_qwiic** `wired` | [](renders/ratsnest/board_services.png)<br>**board_services** | [](renders/ratsnest/bringup_en.png)<br>**bringup_en** |
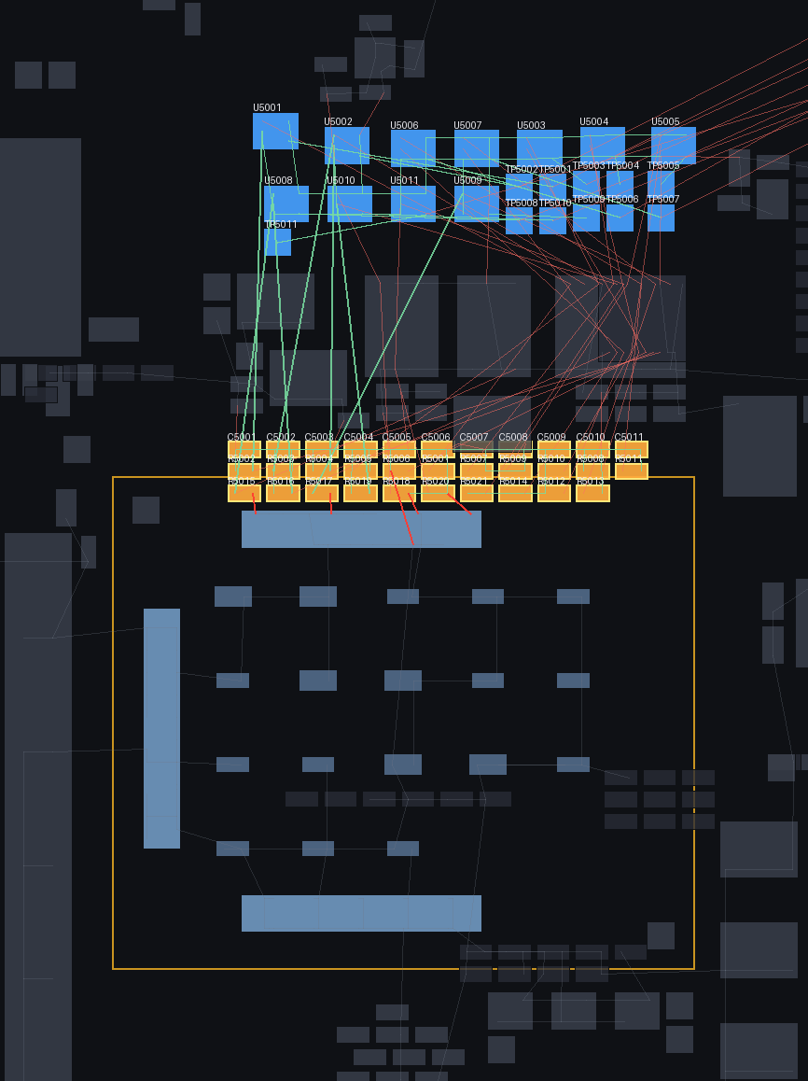
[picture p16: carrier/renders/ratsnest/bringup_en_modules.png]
bringup_en_modules
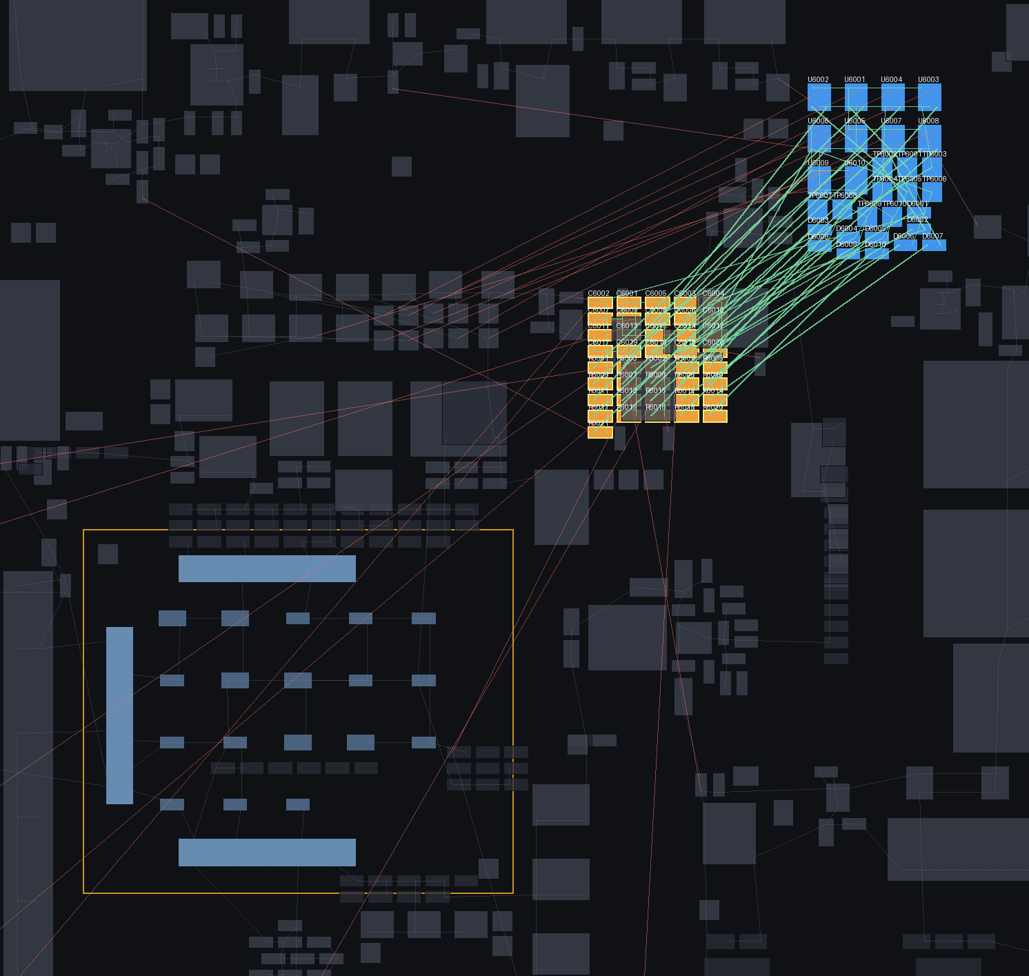
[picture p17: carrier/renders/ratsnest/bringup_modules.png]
bringup_modules
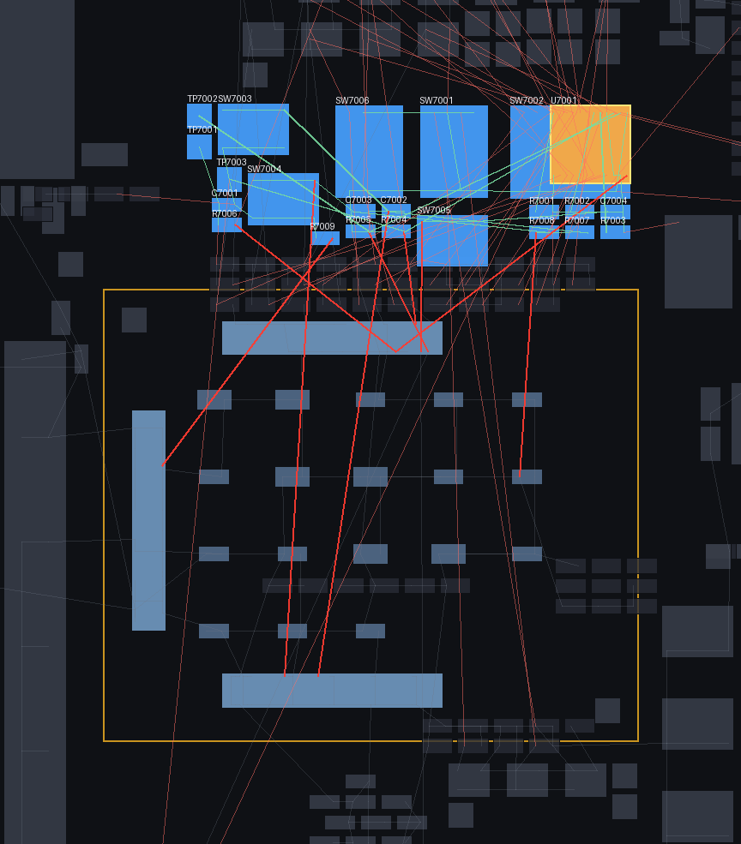
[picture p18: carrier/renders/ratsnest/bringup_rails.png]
bringup_rails
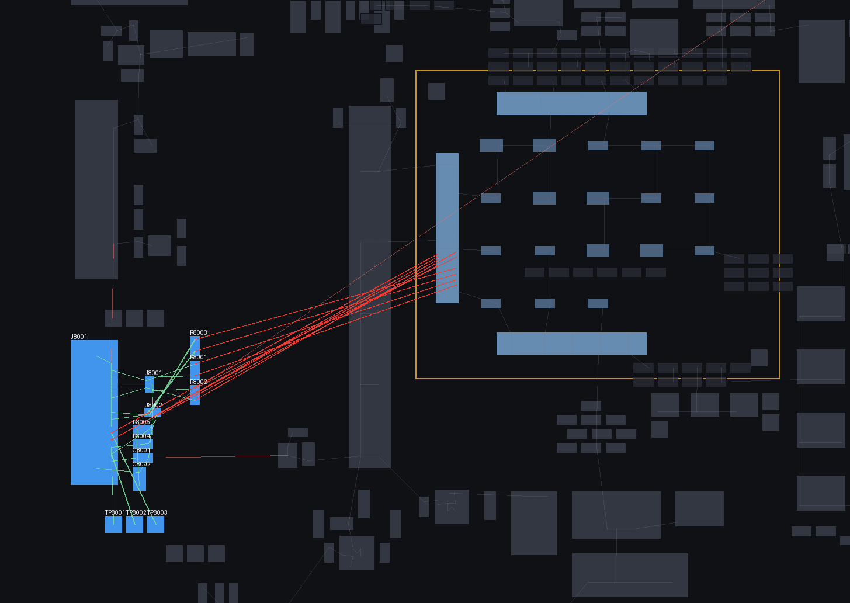
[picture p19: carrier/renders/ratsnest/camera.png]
camera
| [](renders/ratsnest/bringup_en_modules.png)<br>**bringup_en_modules** | [](renders/ratsnest/bringup_modules.png)<br>**bringup_modules** | [](renders/ratsnest/bringup_rails.png)<br>**bringup_rails** | [](renders/ratsnest/camera.png)<br>**camera** `wired` |
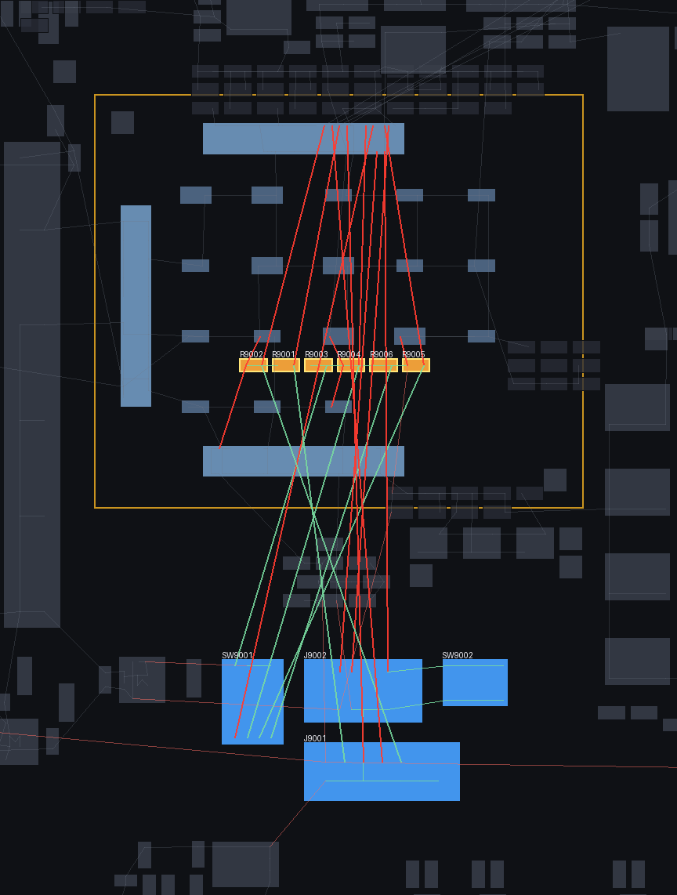
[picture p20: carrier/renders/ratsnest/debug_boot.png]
debug_boot
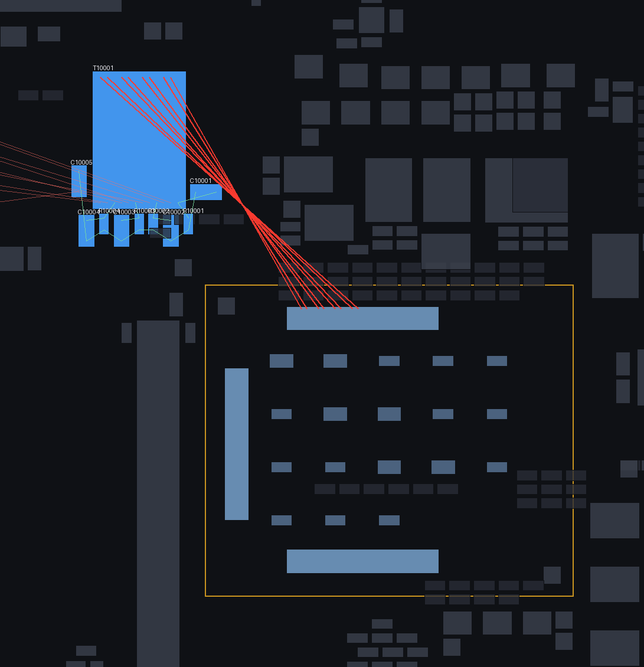
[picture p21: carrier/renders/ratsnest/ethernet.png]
ethernet
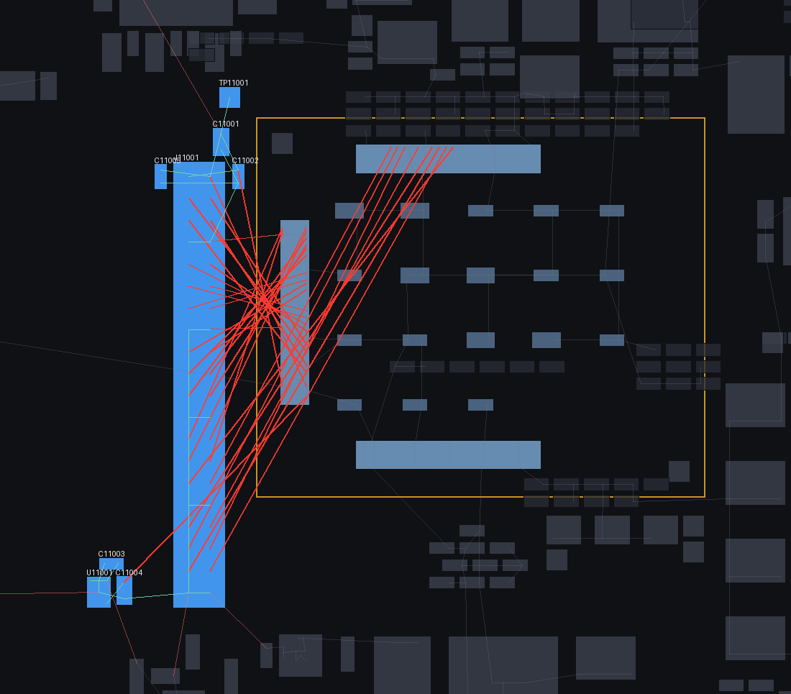
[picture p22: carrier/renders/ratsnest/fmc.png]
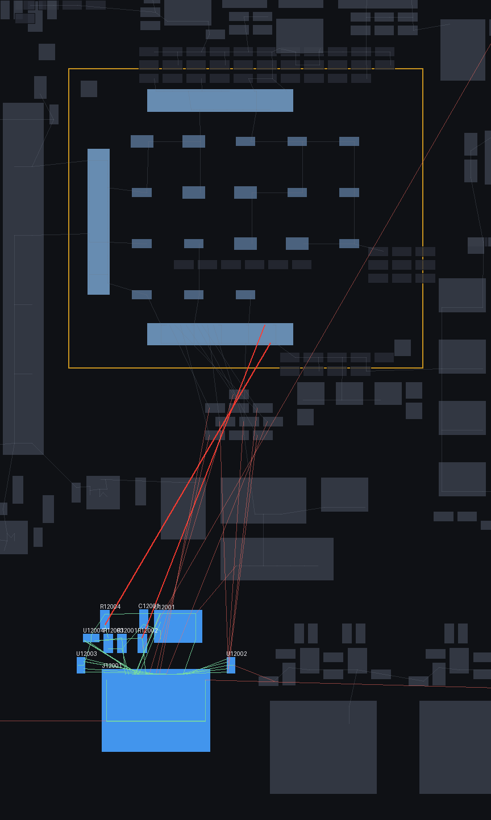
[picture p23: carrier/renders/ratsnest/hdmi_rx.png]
hdmi_rx
| [](renders/ratsnest/debug_boot.png)<br>**debug_boot** | [](renders/ratsnest/ethernet.png)<br>**ethernet** `wired` | [](renders/ratsnest/fmc.png)<br>**fmc** `wired` | [](renders/ratsnest/hdmi_rx.png)<br>**hdmi_rx** `wired` |
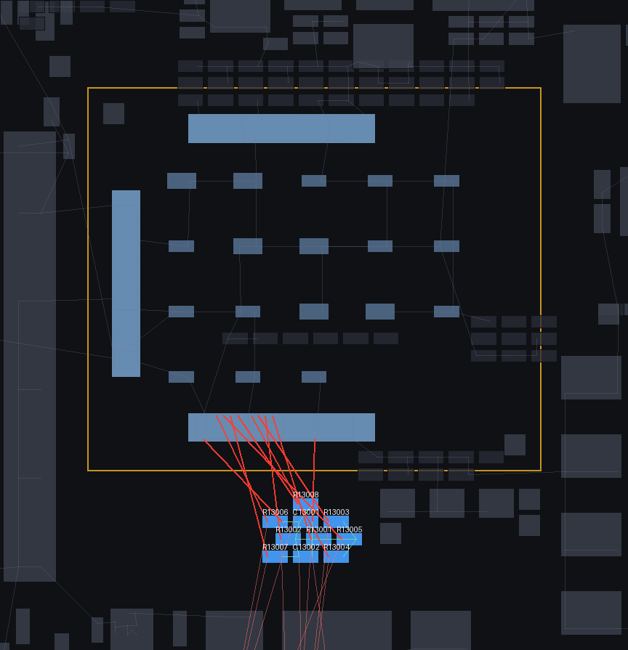
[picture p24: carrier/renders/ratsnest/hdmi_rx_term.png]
hdmi_rx_term
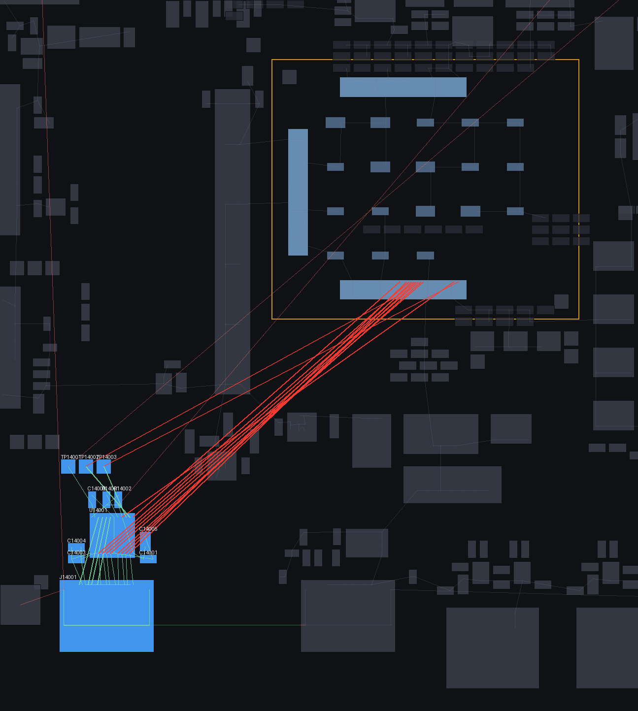
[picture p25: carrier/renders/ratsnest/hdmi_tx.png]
hdmi_tx
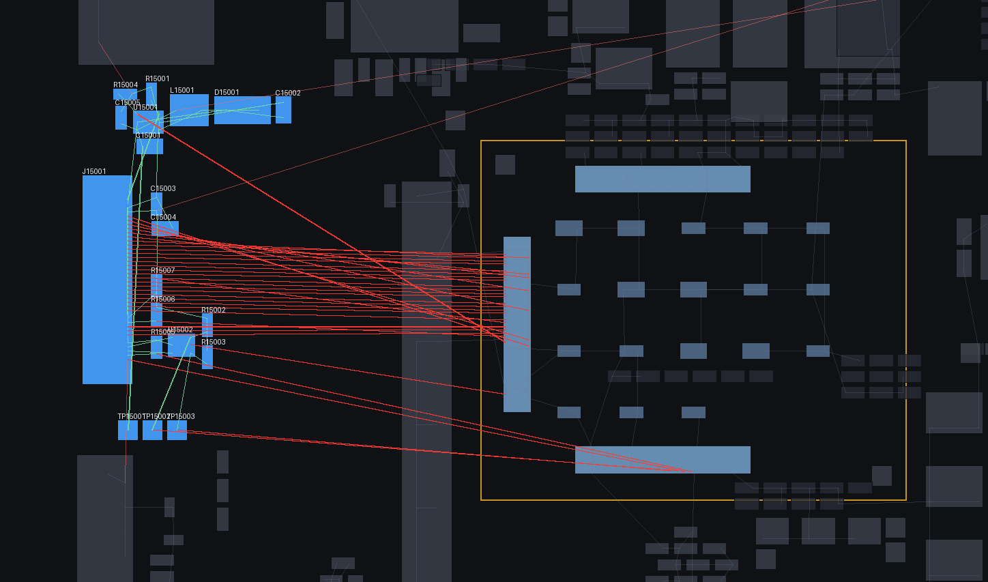
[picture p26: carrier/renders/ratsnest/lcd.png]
| [](renders/ratsnest/hdmi_rx_term.png)<br>**hdmi_rx_term** `wired` | [](renders/ratsnest/hdmi_tx.png)<br>**hdmi_tx** `wired` | [](renders/ratsnest/lcd.png)<br>**lcd** `wired` | [mechanical](renders/ratsnest/mechanical.png)<br>**mechanical** |
| [microsd](renders/ratsnest/microsd.png)<br>**microsd** `wired` | [motor_pwm](renders/ratsnest/motor_pwm.png)<br>**motor_pwm** `wired` | [motor_sense](renders/ratsnest/motor_sense.png)<br>**motor_sense** `wired` | [pd_input](renders/ratsnest/pd_input.png)<br>**pd_input** `wired` |
| [pmod](renders/ratsnest/pmod.png)<br>**pmod** `wired` | [pmod_expansion](renders/ratsnest/pmod_expansion.png)<br>**pmod_expansion** `wired` | [power](renders/ratsnest/power.png)<br>**power** `wired` | [power_mon](renders/ratsnest/power_mon.png)<br>**power_mon** `wired` |
| [power_som](renders/ratsnest/power_som.png)<br>**power_som** `wired` | [rj45_connector](renders/ratsnest/rj45_connector.png)<br>**rj45_connector** | [uart_bridge](renders/ratsnest/uart_bridge.png)<br>**uart_bridge** `wired` | [usb_jtag](renders/ratsnest/usb_jtag.png)<br>**usb_jtag** `wired` |
| [usb_jtag_connector](renders/ratsnest/usb_jtag_connector.png)<br>**usb_jtag_connector** `wired` | [usb_pd](renders/ratsnest/usb_pd.png)<br>**usb_pd** `wired` | [usb_uart_connector](renders/ratsnest/usb_uart_connector.png)<br>**usb_uart_connector** `wired` | [usbc_otg](renders/ratsnest/usbc_otg.png)<br>**usbc_otg** `wired` |
| [user_io](renders/ratsnest/user_io.png)<br>**user_io** | | | |

## Generated schematics

Block diagram and all 37 carrier sheets, regenerated by `schgen board` —
every PNG below passed the netlist, ERC and visual gates.

Generated block diagram

| | | |
|---|---|---|
| [board_aux](renders/board_aux.png)<br>**board_aux** | [board_qwiic](renders/board_qwiic.png)<br>**board_qwiic** | [board_services](renders/board_services.png)<br>**board_services** |
| [bringup_en](renders/bringup_en.png)<br>**bringup_en** | [bringup_en_modules](renders/bringup_en_modules.png)<br>**bringup_en_modules** | [bringup_modules](renders/bringup_modules.png)<br>**bringup_modules** |
| [bringup_rails](renders/bringup_rails.png)<br>**bringup_rails** | [camera](renders/camera.png)<br>**camera** | [debug_boot](renders/debug_boot.png)<br>**debug_boot** |
| [ethernet](renders/ethernet.png)<br>**ethernet** | [fmc](renders/fmc.png)<br>**fmc** | [hdmi_rx](renders/hdmi_rx.png)<br>**hdmi_rx** |
| [hdmi_rx_term](renders/hdmi_rx_term.png)<br>**hdmi_rx_term** | [hdmi_tx](renders/hdmi_tx.png)<br>**hdmi_tx** | [lcd](renders/lcd.png)<br>**lcd** |
| [mechanical](renders/mechanical.png)<br>**mechanical** | [microsd](renders/microsd.png)<br>**microsd** | [motor_pwm](renders/motor_pwm.png)<br>**motor_pwm** |
| [motor_sense](renders/motor_sense.png)<br>**motor_sense** | [pd_input](renders/pd_input.png)<br>**pd_input** | [pmod](renders/pmod.png)<br>**pmod** |
| [pmod_expansion](renders/pmod_expansion.png)<br>**pmod_expansion** | [power](renders/power.png)<br>**power** | [power_mon](renders/power_mon.png)<br>**power_mon** |
| [power_som](renders/power_som.png)<br>**power_som** | [rj45_connector](renders/rj45_connector.png)<br>**rj45_connector** | [som_decoupling](renders/som_decoupling.png)<br>**som_decoupling** |
| [som_j1](renders/som_j1.png)<br>**som_j1** | [som_j2](renders/som_j2.png)<br>**som_j2** | [som_j3](renders/som_j3.png)<br>**som_j3** |
| [uart_bridge](renders/uart_bridge.png)<br>**uart_bridge** | [usb_jtag](renders/usb_jtag.png)<br>**usb_jtag** | [usb_jtag_connector](renders/usb_jtag_connector.png)<br>**usb_jtag_connector** |
| [usb_pd](renders/usb_pd.png)<br>**usb_pd** | [usb_uart_connector](renders/usb_uart_connector.png)<br>**usb_uart_connector** | [usbc_otg](renders/usbc_otg.png)<br>**usbc_otg** |
| [user_io](renders/user_io.png)<br>**user_io** | | |

| sheet | description |
|---|---|
| [board_aux](renders/board_aux.png) | Board services: gated +3V3_AUX rail + PCA9306 I2C isolator |
| [board_qwiic](renders/board_qwiic.png) | QWIIC / STEMMA-QT expansion connector + USBLC6 ESD array |
| [board_services](renders/board_services.png) | Board services: ID-EEPROM, RTC, watchdog, QWIIC |
| [bringup_en](renders/bringup_en.png) | Bring-up EN cells: 3x SN74LVC1G08 rail DIP-AND-override |
| [bringup_en_modules](renders/bringup_en_modules.png) | Bring-up EN cells: 11x SN74LVC1G08 module DIP-AND-override |
| [bringup_modules](renders/bringup_modules.png) | Bring-up module gates: 10x SY6280 + status/user LEDs |
| [bringup_rails](renders/bringup_rails.png) | Bring-up controls: rail/module DIPs + TCA9535 + buttons |
| [camera](renders/camera.png) | RPi camera port: 2-lane MIPI CSI-2 (15P FFC) |
| [debug_boot](renders/debug_boot.png) | JTAG + SWD headers, boot-request DIP, reset |
| [ethernet](renders/ethernet.png) | Ethernet: HX5008NL magnetics + Bob-Smith |
| [fmc](renders/fmc.png) | SoM bank-35 IO breakout (2x20 2.54mm header, VADJ 2.5V) |
| [hdmi_rx](renders/hdmi_rx.png) | HDMI RX: HDMI-A sink + EDID EEPROM |
| [hdmi_rx_term](renders/hdmi_rx_term.png) | HDMI-RX TMDS sink termination (8x49.9R to AVCC=+3V3) |
| [hdmi_tx](renders/hdmi_tx.png) | HDMI TX: TPD12S016 + HDMI-A receptacle (source) |
| [lcd](renders/lcd.png) | 40-pin TTL RGB LCD + SY7201 backlight boost |
| [mechanical](renders/mechanical.png) | Mechanical: M3 mounts + chassis-GND bond (fiducials are PCB-only, emitted by the placer) |
| [microsd](renders/microsd.png) | microSD slot (1.8V SoM <-> 3.3V card, TXS02612) |
| [motor_pwm](renders/motor_pwm.png) | 8-ch PWM/ESC output buffer (5V, PL-isolating) |
| [motor_sense](renders/motor_sense.png) | ESC motor-rail telemetry: INA3221 + 10mR shunt (I2C 0x42) |
| [pd_input](renders/pd_input.png) | Power inlet: USB-C PD 20V/3A + TPS26631 eFuse |
| [pmod](renders/pmod.png) | 2x Pmod host ports (bank 13, 200R series, gated 3V3) |
| [pmod_expansion](renders/pmod_expansion.png) | Pmod expansion (2x6, bank 13, ESD, gated 3V3) |
| [power](renders/power.png) | Power: +VIN->+5V->+3V3 bucks + +1V8 LDO, PG LEDs |
| [power_mon](renders/power_mon.png) | Rail telemetry: 2x INA3221 + shunts (I2C 0x40/41) |
| [power_som](renders/power_som.png) | Power: +VIN -> +5V_SOM always-on buck |
| [rj45_connector](renders/rj45_connector.png) | RJ45 8P8C jack (plain, ext. magnetics) |
| [som_decoupling](renders/som_decoupling.png) | SoM power-entry decoupling under the DF40 mezzanine |
| [som_j1](renders/som_j1.png) | SoM J1: power / USB / STM32 / JTAG / SDIO / ETH MDI |
| [som_j2](renders/som_j2.png) | SoM J2: FPGA bank 13/33 IO + VCCO rails |
| [som_j3](renders/som_j3.png) | SoM J3: FPGA bank 33/34/35 IO + VCCO rails |
| [uart_bridge](renders/uart_bridge.png) | UART bridge: CP2102N USB-UART |
| [usb_jtag](renders/usb_jtag.png) | USB-JTAG/UART bridge: CH347T, isolated |
| [usb_jtag_connector](renders/usb_jtag_connector.png) | USB-C UFP debug port -> CH347T (protected) |
| [usb_pd](renders/usb_pd.png) | USB-PD: FUSB302B Type-C controller |
| [usb_uart_connector](renders/usb_uart_connector.png) | USB-C UFP console port -> CP2102N |
| [usbc_otg](renders/usbc_otg.png) | USB 2.0 HS OTG port (Type-C, host) |
| [user_io](renders/user_io.png) | User IO: 4 LEDs (gated rail) + 4 buttons, bank 13 |
<!-- /schgen:gallery -->

## Top-level file index

Authored build INPUTS (edit these):

| File | Role |
|---|---|
| `floorplan.json` | Declarative floorplan: connector edge lists (order = order along the edge) + interior anchors — drives the PCB placement |
| `som_interface.json` | The SoM DF40 pin contract (J1/J2/J3) every subsystem binds against |
| `nets.py` | Carrier net registry (generated by `schgen nets`, reviewed/committed) |
| `som_conn_gen.py` | Generator for the som_j* connector sheets |
| `subsystems/` | Carrier subsystems — flat `<name>.py`+`test_<name>.py` ADAPTER pairs bind the portable `subsystems/` library; carrier-only LOCALS are full folders (shape enforced by the hard `carrier-check` gate) |

Generated build OUTPUTS (rebuilt by `schgen board`, committed as the reviewed design):

| File | Role |
|---|---|
| `Zynq_Carrier.kicad_pro/.kicad_sch/.kicad_pcb` | The openable KiCad project / schematic / placed board |
| `sheet_index.json` | Frozen per-sheet refdes band index (the lib-ref -> board-ref rename) |
| `manifest.json` | Build manifest (inputs, hashes, gate verdicts) |
| `escape_block.json` | DF40 escape/return-stitch plan (LAW-0 — never hand-edit) |
| `schematic/` `renders/` `reports/` `docs/` `manufacturing/` `fpga/` `firmware/` | Per-sheet schematics, golden renders + 3D views, gate reports, floorplan/ratsnest docs, JLC BOM/CPL, XDC pins |

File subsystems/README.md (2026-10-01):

# subsystems — the reusable subsystem library

Project-agnostic, self-contained schgen subsystems. Each
`subsystems/<name>/` package declares its interface as **abstract** port and
rail names and knows nothing about any board: no carrier net names, no reads of
`carrier/nets.py` or `som_interface.json`. A consuming project drops the
subsystem onto its real nets with a thin adapter (e.g.
`carrier/subsystems/<name>.py`) that declares ONE module-level `META` dict and
forwards it to the library's `circuit(meta)`:

```python
from subsystems.usb_pd import usb_pd

META = {
    "bind":    {"+VDD_LOGIC": "+3V3_SC", "GND": "GND",
                "CC1": "USB_PD_CC1", "CC2": "USB_PD_CC2"},
    "expects": {"CC1": "usb_pd_connector"},     # per-port linker deferral
    "buses":   {"i2c": "STM32_I2C2"},           # rename a named bus group
    "notes":   {"draws": "FUSB302B VDD (<1 mA); ..."},  # house-style prose
}

def circuit():
    return usb_pd.circuit(META)
```

Called with `meta=None` (standalone) the library keeps its abstract names, so
each package's `test_<name>.py` runs offline against the abstract interface.

## The Meta contract

The adapter ↔ library contract is **`schgen/core/subsystem.py`** (the `Meta`
class). A `META` dict has exactly four legal top-level keys, all optional; any
other key is a hard `CircuitError`, so a typo like `"bus"` for `"buses"` can
never be silently dropped. Every value must be a `{str: str}` mapping.

- **`bind`** `{abstract_net: real_net}` — rename the externally-visible
  POWER / GROUND / PORT nets (a subsystem's rails and ports) to the project's
  real net names. Applied LAST, via `Meta.finish(c)` → `Circuit.bind`.
- **`expects`** `{abstract_port: deferral}` — attach an explicit linker
  deferral string to a port, declaring which of the project's other sheets
  will supply that net. Splatted into the port via `Meta.expect_kw(port)`.
- **`buses`** `{role: real_bus_name}` — rename a named bus group (e.g.
  `{"i2c": "STM32_I2C2"}`) so a board can place the subsystem on one of its own
  named buses. Read by the library via `Meta.bus(role, default)`.
- **`notes`** `{key: prose}` — house-style prose overrides (e.g. the
  power-tree `draws` note) so a project's derived artifacts stay byte-stable.
  Read by the library via `Meta.note(key, default)`.

### bind: rules and the byte-identical guarantee

`bind` is the binding half of the reuse contract, enforced by `Circuit.bind`:

- **Only externals are bindable.** POWER, GROUND and PORT nets are the
  subsystem's edge. A SIGNAL net is the subsystem's private internal wiring and
  is never renamed; a SIGNAL key in the map is a hard error.
- **A typo is a hard error.** An abstract name not present on the circuit
  raises `CircuitError` rather than passing silently. A binding may be the
  identity (`abstract == real`), and a project may bind a subset (unbound
  externals keep their abstract names).
- **No collisions.** Two distinct externals may not bind onto one real net
  (that would silently merge two nets — a LAW-0 short), and a bind target may
  not collide with an existing un-renamed net of a different name.
- **Byte-identical.** The rename is in place and order-preserving: the `nets`
  dict is rebuilt with the new keys in the same insertion order, and parts,
  refs, NCs, pins, port-type payloads and draw budgets are untouched. Binding
  the abstract names to the exact net names a hand-written sheet used yields a
  byte-for-byte identical emitted sheet.

## Package layout and the structure gate

Every `subsystems/<name>/` carries exactly four artifacts, enforced by the
structure gate `schgen/verify/subsystem_structure.py`:

| file | role |
|---|---|
| `<name>.py` | the netlist — `circuit(meta=None)` with abstract ports/rails and a declared `INTERFACE = RAILS + PORTS` |
| `README.md` | the abstract-interface table and design notes |
| `test_<name>.py` | the offline local-correctness test (gate slices on just this subsystem) |
| `<name>.cir` | the SPICE subckt — the passive network with the abstract ports as subckt pins |

Active parts are **referenced, never vendored**: symbol, footprint and LCSC
come from the global `parts/<MPN>/` dossier (or a deliberate stock-symbol
override declared in the library file). Cross-board gates (link, full SI
constraints, board ERC, board netlist merge, power-tree headroom) stay
aggregated at board level and are not duplicated in the package tests.

Scaffold a new native C++ package, then run the package gate from the repository root:

```bash
native/bin/schgen subsystem-new <name>
native/bin/schgen subsystem-check
```

The scaffold writes C++ source/header/test, SPICE, metadata, CMake and README
files, never overwriting an existing package. Follow its generated README to
select and build the package; its initial unimplemented builder intentionally
fails acceptance. The Python package shape above describes the former model,
not the current scaffold output.

## The library

| package | purpose |
|---|---|
| [`camera`](camera/README.md) | RPi 15-pin FFC, 2-lane MIPI CSI-2 camera port |
| [`ethernet`](ethernet/README.md) | HX5008NL 1000BASE-T magnetics + Bob-Smith termination |
| [`hdmi_rx`](hdmi_rx/README.md) | HDMI sink port (low-cap TMDS RX ESD + EDID EEPROM) |
| [`hdmi_tx`](hdmi_tx/README.md) | TPD12S016 HDMI source port |
| [`lcd`](lcd/README.md) | 40-pin TTL RGB888 panel + SY7201 backlight boost + touch I2C |
| [`microsd`](microsd/README.md) | TXS02612 microSD slot (1.8 V SoM ↔ 3.3 V card translator) |
| [`pd_input`](pd_input/README.md) | USB-C PD power inlet (receptacle + TPS26631 eFuse → +VIN) |
| [`pmod`](pmod/README.md) | 2× Digilent-standard Pmod host ports |
| [`pmod_expansion`](pmod_expansion/README.md) | manual-gated Digilent Pmod expansion port |
| [`power`](power/README.md) | +VIN → +5V buck (LM61460) → +3V3 buck (LM61460) → +1V8 LDO (AP2112K), each rail with an enable port and a power-good LED |
| [`rj45_connector`](rj45_connector/README.md) | RJ45 jack (line-side MDI pairs + housing LEDs) |
| [`uart_bridge`](uart_bridge/README.md) | CP2102N USB-to-UART bridge |
| [`usb_jtag`](usb_jtag/README.md) | CH347T USB-JTAG/UART debug bridge |
| [`usb_jtag_connector`](usb_jtag_connector/README.md) | USB-C UFP debug receptacle + ESD (for `usb_jtag`) |
| [`usb_pd`](usb_pd/README.md) | FUSB302B USB Type-C / Power-Delivery sink PHY |
| [`usb_uart_connector`](usb_uart_connector/README.md) | USB-C receptacle + ESD (for `uart_bridge`) |
| [`usbc_otg`](usbc_otg/README.md) | USB 2.0 HS OTG port (USB-C receptacle, host-capable) |

Carrier-specific sheets that only make sense for this board (the SoM-mezzanine
connectors, bring-up sequencing, the power-monitor / always-on SoM buck,
board-services hardware, FMC, user IO) are not in this library; they live under
`carrier/subsystems/` as hand-written local glue. See
[`carrier/subsystems/README.md`](../carrier/subsystems/README.md).

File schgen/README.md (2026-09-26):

# schgen — netlist-first KiCad schematic + PCB generator

> Migration note: the Python interfaces/examples here are retained for parity.
> Current Python-free build/CTest instructions and the infrastructure retirement
> checklist live in [`native/ci/README.md`](../native/ci/README.md). Do not remove
> the Python tests or their dependencies until their independent coverage has
> been accepted in native contracts.

`schgen` turns hand-authored Python **netlists** into electrically-correct,
visually-clean KiCad schematics **and a placed PCB** for the Zynq-7000 SoM
**carrier** board. You author one subsystem (an active part + all its passives)
as a single `.py` file that declares every part and every pin→net assignment;
`schgen` places and routes the schematic, emits each `.kicad_sch`, places the
board (footprints + 3D models, edge-flush connectors), and **gates** every
artifact against immutable judges.

It is the source of truth for the board: the committed `carrier/` schematics,
BOM, FPGA constraints, firmware contract, bring-up manual, power tree, and
renders are all **generated** — never hand-edited.

> Deep architecture & rationale: [`DESIGN.md`](DESIGN.md). This README is the
> entry point — what it is, how to run it, and where things live.

---

## The laws (immutable — the gates are judges, not knobs)

1. **LAW 0 — electrical integrity.** The netlist is sacred. The netlist KiCad
   extracts from the emitted sheet must be **graph-identical** to the netlist
   the `.py` declared — net-by-net, pin-by-pin (`kicad-cli sch export netlist`,
   not gameable "ERC=0"). A short or an open is the worst possible defect. An
   exposed/thermal pad is a **real pad + pin + GND net**, never a prose layout
   note.
2. **LAW 1 — visual correctness.** Datasheet-reference-circuit style, wire-heavy,
   hand-drawn quality. **Zero** overlap of anything; **zero** wire crossings.
3. **LAW 4 — never soften a validator.** If a route/label/derate fails, place or
   route it better, or expand the candidate set — never suppress, exempt, or
   relax the rule. Improving the algorithm is the work. Every waiver is explicit,
   author-declared, and printed verbatim in the gate report.

A change is done only when **every focused sheet is hand-drawn-clean in the
render AND every gate is green.**

---

## Quickstart

```bash
# Build + gate ONE subsystem sheet into a throwaway dir (preview/CI of one sheet):
python3 -m schgen build power            # model -> place -> route -> emit -> 3 gates -> render

# Build the WHOLE board (the authoritative regen of everything committed under carrier/):
python3 -m schgen board                  # every sheet gated + link + KiCad project + BOM
                                         # + xdc + firmware + manual + power tree + renders ...

# The full regression bar (run before every commit — see scripts/check.sh):
scripts/check.sh                         # board + selftest (mutation+determinism) + m1_rc + pytest
```

`build` persists nothing (transient tempdir, auto-removed) — pass `-o OUTDIR` to
keep its artifacts. Only `schgen board` writes the committed `carrier/` tree.

---

## Authoring model

A subsystem lives in `carrier/subsystems/<name>.py` and returns a `Circuit`.
Every part and net is explicit; helper macros expand to parts+nets so authoring
stays concise but the result is always a fully-explicit netlist:

```python
def circuit() -> Circuit:
    c = Circuit("power", "+VIN -> +5V buck")
    c.use_part("LM61460AANRJRR", ref="U1")           # FAITHFUL dossier symbol (no override)
    c.net("+VIN_SYS", "U1.8", "U1.12")               # VIN1/VIN2 -> rail
    c.net("GND", "U1.9", "U1.11", "U1.3")            # PGND1/PGND2/AGND -> GND (LAW 0 heat path)
    c.port("EN_5V0", "U1.7", expect=EXPECT_BRINGUP)  # EN/SYNC -> external interface (hier label)
    c.decouple("U1.8", "10u")                        # macro: cap pin->GND
    return c
```

Net classes drive everything downstream: `POWER` (+3V3, +VIN…), `GROUND` (GND
family), `SIGNAL` (internal), `PORT` (external interface → hier label + the
board-level link graph). `port(..., expect=...)` declares which other sheet (or
the SoM J-connector) supplies the peer — the linker and the board's
undriven-input gate honor it.

---

## The pipeline (correct by construction)

Per sheet (schematic):
```
 model.py        place.py            route.py          emit.py           verify/
 ────────        ────────            ────────          ───────           ───────
 Circuit  ──▶  feasibility-loop ──▶  exclusive-grid ──▶ .kicad_sch  ──▶  netlist == declared
 (explicit     placement            wire router        (content-          ERC errors == 0
  netlist)     (templates per       (no two nets        derived            visual zero-overlap,
               part topology)        share a track)     uuid5 ids)         junction-aware)
```

Then the board (PCB): `generate/pcb.py` places every footprint (subsystem
clustering, connectors edge-flush with mating faces off-board), embeds the real
3D models, emits `Zynq_Carrier.kicad_pcb`, and gates it (DRC, 3D-model coverage +
placement, ratsnest grouping, connector mating-face / spacing);
`output/render3d.py` renders the multi-angle 3D views.

Geometry is **derived from** the netlist, never the source of electrical truth.
Emission is deterministic: ids are content-derived `uuid5`, so the same model
emits byte-identical output across runs and `PYTHONHASHSEED`s.

---

## Command surface

Run `python3 -m schgen <cmd> --help` for any command.

**Build / board**
| command | does |
|---|---|
| `build <sheet>` | generate + 3-gate one subsystem (preview; writes nothing unless `-o`) |
| `board` | the authoritative whole-board regen: every sheet gated + link + KiCad project + all downstream artifacts (`--bless` rebaselines the render goldens) |
| `link` | board-level port graph + constraints + block diagram + hierarchical root |
| `nets` | regenerate `carrier/nets.py` (the cross-sheet net-name contract) |

**Generated artifacts** (all netlist-derived, all under `carrier/`)
| command | output |
|---|---|
| `bom` | JLCPCB assembly CSV (Comment,Designator,Footprint,LCSC) |
| `xdc` | `fpga/Zynq_Carrier_pins.xdc` — PACKAGE_PIN + IOSTANDARD per port (Zynq ball map live-extracted from the SoM) |
| `vivado` | `fpga/create_project.tcl` |
| `firmware` | `firmware/zynq_carrier_contract.h` — SC-firmware HW contract (J1 pins, STM32 GPIOs, BOOTSEL decode, I2C map, rail/module EN map) |
| `devicetree` | `firmware/carrier_pl.dtsi` |
| `manual` | `docs/BRINGUP.md` — ordered bring-up procedure derived from the netlists |
| `floorplan` | `docs/FLOORPLAN.svg` + `.md` — to-scale 2D placement suggestion |
| `manifest` | `manifest.json` |
| `testplan` | `docs/TEST_PLAN.md` — probe/measure plan from the spice gate |
| `gallery` | render-gallery sections in `README.md` + `carrier/README.md` |

**Gates** (also run inside `board`; standalone for focused checks)
| command | judges |
|---|---|
| `design-rules` | completeness: every IC supply pin bypassed, every i2c bus pulled, every reset has its RC, no floating config strap, **every exposed pad netted to GND** |
| `part-rules` | per-part datasheet ratings: CAP_VOLTAGE derate, IC_VIN abs-max, RES_POWER |
| `powertree` | rail budget: every rail sourced, no regulator/eFuse over its current limit (series-shunt-aware) |
| `thermal` | per-device junction temperature vs guard band |
| `spice` | analytic + ngspice `.op` cross-check on every divider (1% agreement) |
| `selftest` | **gate mutation testing** (every injected fault must be killed) + cross-`PYTHONHASHSEED` build determinism |
| `preflight` | consolidated readiness report |

`schgen board` additionally enforces the **PCB gates** — DRC (zero KiCad errors),
3D-model coverage + placement, ratsnest subsystem clustering, connector
mating-face / spacing, refdes-overlap — and `schgen render3d` writes the
multi-angle 3D board views.

**Parts pipeline**
| command | does |
|---|---|
| `part add <LCSC>` | import a part from LCSC/EasyEDA into `parts/<MPN>/` (symbol + footprint + 3D + pins), with allowlist-keyed EP-pad and polarity-silk synthesis |

---

## Package layout (by concern)

The modules live in role-named subpackages under `schgen/`:

- **`core/`** — `model.py` (`Circuit`, parts, nets, macros, waivers, `subset`),
  `symbols.py` (KiCad symbol library + pin tables), `link.py` (board port graph),
  `sexpr.py` (S-expression read/write), `som_interface.py` (SoM J-connector contract).
- **`layout/`** — `place.py` (`_Engine`, per-topology templates:
  regulator / stack-columns / chain / connector-fan / shunt cells; congestion
  auto-pagination), `route.py` (exclusive-grid router), `textmetrics.py`.
- **`output/`** — `emit.py` (deterministic content-derived uuid5),
  `render.py` (kicad-cli schematic PNG), `render3d.py` (multi-angle 3D board
  renders), `diagram.py` (block diagram).
- **`verify/`** — schematic gates: `netlist_gate.py`, `visual_gate.py`,
  `design_rules.py`, `part_rules.py`, `cc_gate.py`, `powertree.py`,
  `thermal.py`, `spice.py`, `ratings.py` (LCSC-keyed datasheet limits),
  `testpoints.py`, `pin_completeness.py`, `symbol_law.py`, `bom_values.py`.
  PCB gates: `model3d_gate.py` (3D coverage + placement), `ratsnest_gate.py`
  (subsystem clustering), `connector_model_gate.py` / `connector_spacing_gate.py`
  (mating-face / spacing), `placement_mech.py`, `refdes_overlap_gate.py`,
  `footprint_pads.py`. Structure: `carrier_structure.py`,
  `subsystem_structure.py`. Meta: `selftest.py` (mutation + determinism),
  `preflight.py`.
- **`generate/`** — `board.py` (whole-board orchestrator), **`pcb.py`** (board
  footprint placement + 3D-model embed + `.kicad_pcb` emit), `ratsnest.py`,
  `si_constraints.py`, `power_sequence.py`, `firmware.py`, `manual.py`,
  `testplan.py`, `floorplan.py`, `gallery.py`, `devicetree.py`, `manifest.py`,
  `xdc.py`, `vivado.py`, `constraints.py`, `bringup_facts.py` (shared
  netlist-derived facts the firmware/manual/testplan generators consume).
- **`partlib/`** — `part_gen.py` (LCSC/EasyEDA → `parts/<MPN>/` conversion).
- **CLI (package root)** — `__main__.py`.

---

## Determinism & the regression bar

`scripts/check.sh` is the bar that must be green before every commit:

1. **board** — every sheet gated (netlist==declared, ERC=0, visual zero-overlap)
   + the board-level cross-sheet link/merge gate + a geometry-only connected-
   components short/open detector.
2. **selftest** — gate mutation testing (every injected defect must be killed by
   a gate) + byte-identical determinism across `PYTHONHASHSEED ∈ {0, …}`.
3. **m1_rc** — the M1 RC-spine smoke sheet (engine sanity).
4. **pytest** — unit tests (model, gates, part_gen EP synthesis, pagination, …).

Local only — no online CI by project policy.

---

## Where things are

- `carrier/subsystems/*.py` — the authored subsystems (the input).
- `carrier/research/*.md` — per-subsystem engineering dossiers (the "why").
- `carrier/` — the generated, committed output (schematics, BOM, fpga, firmware,
  docs, reports, renders).
- `parts/<MPN>/` — the imported part library (symbol, footprint, 3D, pins).
- `schgen/tests/` — pytest suite.

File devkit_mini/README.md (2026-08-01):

<!-- schgen:gallery -->
<!-- GENERATED by `schgen gallery` — edits between these markers are overwritten -->
## Generated 3D board views

The placed board rendered from 8 angles by `schgen board` (kicad-cli, the real component 3D models) — regenerated and committed every build, just like the sheets below.

| | | | |
|---|---|---|---|
| [Perspective (front)](renders/3d_persp.png)<br>**Perspective (front)** | [Perspective (rear)](renders/3d_persp_rear.png)<br>**Perspective (rear)** | [Top](renders/3d_top.png)<br>**Top** | [Bottom](renders/3d_bottom.png)<br>**Bottom** |
| [Front edge](renders/3d_front.png)<br>**Front edge** | [Back edge](renders/3d_back.png)<br>**Back edge** | [Left edge](renders/3d_left.png)<br>**Left edge** | [Right edge](renders/3d_right.png)<br>**Right edge** |

## Ratsnest views

Placed-board airwires, regenerated by `schgen board`: blue/orange = the subsystem's parts (top/bottom side), steel = SoM, green = intra-subsystem, red = to the SoM. `wired` = in `placement.wired_sheets`.

| | |
|---|---|
| [Board (top)](renders/ratsnest_top.png)<br>**Board (top)** | [Board (bottom)](renders/ratsnest_bottom.png)<br>**Board (bottom)** |
| [SoM region](renders/ratsnest/som.png)<br>**SoM region** | |

| | | | |
|---|---|---|---|
| [debug_boot](renders/ratsnest/debug_boot.png)<br>**debug_boot** | [mechanical](renders/ratsnest/mechanical.png)<br>**mechanical** | [pd_input](renders/ratsnest/pd_input.png)<br>**pd_input** `wired` | [power](renders/ratsnest/power.png)<br>**power** `wired` |
| [power_mon](renders/ratsnest/power_mon.png)<br>**power_mon** | [power_som](renders/ratsnest/power_som.png)<br>**power_som** | [uart_bridge](renders/ratsnest/uart_bridge.png)<br>**uart_bridge** `wired` | [usb_uart_connector](renders/ratsnest/usb_uart_connector.png)<br>**usb_uart_connector** `wired` |

## Generated schematics

Block diagram and all 12 devkit_mini sheets, regenerated by `schgen board` —
every PNG below passed the netlist, ERC and visual gates.

Generated block diagram

| | | |
|---|---|---|
| [debug_boot](renders/debug_boot.png)<br>**debug_boot** | [mechanical](renders/mechanical.png)<br>**mechanical** | [pd_input](renders/pd_input.png)<br>**pd_input** |
| [power](renders/power.png)<br>**power** | [power_mon](renders/power_mon.png)<br>**power_mon** | [power_som](renders/power_som.png)<br>**power_som** |
| [som_decoupling](renders/som_decoupling.png)<br>**som_decoupling** | [som_j1](renders/som_j1.png)<br>**som_j1** | [som_j2](renders/som_j2.png)<br>**som_j2** |
| [som_j3](renders/som_j3.png)<br>**som_j3** | [uart_bridge](renders/uart_bridge.png)<br>**uart_bridge** | [usb_uart_connector](renders/usb_uart_connector.png)<br>**usb_uart_connector** |

| sheet | description |
|---|---|
| [debug_boot](renders/debug_boot.png) | JTAG + SWD headers, boot-request DIP, reset |
| [mechanical](renders/mechanical.png) | Mechanical: M3 mounts + chassis-GND bond (fiducials are PCB-only, emitted by the placer) |
| [pd_input](renders/pd_input.png) | Power inlet: USB-C PD 20V/3A + TPS26631 eFuse |
| [power](renders/power.png) | Power: +VIN->+5V->+3V3 bucks + +1V8 LDO, PG LEDs |
| [power_mon](renders/power_mon.png) | Rail telemetry: 2x INA3221 + shunts (I2C 0x40/41) |
| [power_som](renders/power_som.png) | Power: +VIN -> +5V_SOM always-on buck |
| [som_decoupling](renders/som_decoupling.png) | SoM power-entry decoupling under the DF40 mezzanine |
| [som_j1](renders/som_j1.png) | SoM J1: power / USB / STM32 / JTAG / SDIO / ETH MDI |
| [som_j2](renders/som_j2.png) | SoM J2: FPGA bank 13/33 IO + VCCO rails |
| [som_j3](renders/som_j3.png) | SoM J3: FPGA bank 33/34/35 IO + VCCO rails |
| [uart_bridge](renders/uart_bridge.png) | UART bridge: CP2102N USB-UART |
| [usb_uart_connector](renders/usb_uart_connector.png) | USB-C UFP console port -> CP2102N |
<!-- /schgen:gallery -->

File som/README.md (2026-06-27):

# som/ — Zynq-7000 System-on-Module

A hand-authored Zynq-7000 system-on-module (SoM) KiCad project. Open
`som/Zynq_SoM.kicad_pro` in KiCad 9 or later. This project is maintained by
hand in the KiCad schematic and board editors; it is not generated.

## Layout

```
som/
  Zynq_SoM.kicad_pro / .kicad_sch / .kicad_pcb   # the module project
  Zynq_SoM.pdf                                    # rendered schematic
  schematic/                                      # the 16 hierarchical sub-sheets
  lib/                                            # custom symbols, footprints, 3D models
  manufacturing/                                  # fabrication + assembly outputs
  fp-lib-table                                    # project footprint library table
  Zynq_SoM.kicad_dru                              # design-rule constraints
  Jobset.kicad_jobset                             # KiCad jobset for output generation
```

`Zynq_SoM.kicad_sch` is the root sheet; the design is split across the 16
hierarchical sub-sheets in `schematic/`, organized by function: the Zynq PS/PL
banks (`zynq_PS_b500_b501`, `zynq_PL_b13`, `zynq_b33_b34_b35`, `zynq_config`,
`zynq_ddr`, `zynq_power`), DDR3L memory (`DDR3L`), Ethernet PHY, USB HS PHY,
eMMC, power (`Power`, `power_architecture`), the system controller, sensors,
and the J1/J2/J3 mezzanine connectors (`connectors`).

## Custom libraries (`lib/`)

The project pins its own libraries so the design is self-contained:

- `lib/zynq_eda.kicad_sym` — schematic symbols for the SoM's parts (Zynq,
  DDR, PHYs, sensors, regulators).
- `lib/generated/` — generated interface symbols (FMC, HDMI, MIPI, PMOD,
  LVDS-LCD, XADC, STM32 breakout) and the `connector_banks/` symbols that
  pin out the mezzanine connector banks.
- `lib/zynq_som.pretty/` — the custom footprints, including the
  `HRS_DF40C-100DP-0.4V_51_` mezzanine connector and the Zynq/DDR BGAs.
  Registered via `fp-lib-table` as the `fp` library.
- `lib/3d/` — STEP/WRL models for the custom and passive footprints.

## SoM ↔ carrier interface contract

The SoM mates to the carrier board over three Hirose DF40 100-pin mezzanine
connectors, **J1**, **J2**, and **J3** — 300 pins total. The pin assignment on
these connectors is the electrical contract between the two boards:

- J1 carries the supply rails (VIN, +3V3, +1V8), USB, JTAG, SDIO, the STM32
  system-controller signals, and the Ethernet MDI pairs.
- J2 and J3 carry the Zynq bank I/O (VCCO rails plus the bank 13/33/34/35
  IO_Lxx differential and single-ended lines).

This contract is **extracted programmatically** from this project, never
hand-copied. `schgen som-interface` reads `som/Zynq_SoM.kicad_sch` and writes
`carrier/som_interface.json` — the per-connector pin→net map the carrier
subsystems bind against. The carrier's FPGA pin constraints
(`carrier/fpga/Zynq_Carrier_pins.xdc`, produced by `schgen xdc`) are derived
and cross-checked against the same contract, so the Vivado pin map cannot drift
from the module's actual pinout.

The dependency runs one way: this SoM project is the upstream source of truth.
Edits here flow into `som_interface.json` and the carrier on the next
extraction; the SoM is never edited to match the carrier.

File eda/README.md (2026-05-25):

# zynq_eda — Programmatic KiCad schematic generator

Generates production-grade KiCad 9.0 `.kicad_sch` projects for the Zynq-SoM
carrier (today) and other Zynq-family boards (future). Driven by Python; the
output is pristine, ERC-clean, BOM-ready KiCad — no manual layout pass needed
after generation.

## Install

From `eda/`:

```bash
make install        # editable install + hidden-flag fix
make install-dev    # + pytest, ruff
make test
```

The `Makefile` wraps `pip install -e . --config-settings editable_mode=compat`
and strips the macOS `UF_HIDDEN` flag that hatchling sets on its `.pth` file
(Python 3.13+ silently refuses to load hidden `.pth` files).

## Run

```bash
python -m zynq_eda --board carrier --output boards/carrier
python -m zynq_eda --board carrier --audit-only          # Stage 0: completeness check
python -m zynq_eda --board carrier --only power          # build a single block
python -m zynq_eda --board carrier --skip-erc            # skip kicad-cli ERC
```

## Package layout

```
src/zynq_eda/
  core/         # board-agnostic infrastructure (model, layout, route, rules, emit, validate)
  catalog/      # shared component catalog (parts, refcircuits, datasheets, symbols)
  projects/     # per-board project definitions (carrier, som)
```

See the top-level repo `README.md` for the full architecture and roadmap.

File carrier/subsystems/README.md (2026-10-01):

# carrier/subsystems — the carrier design layer

This directory is the only hand-written layer of the carrier board. Everything
else (placement, routing, the KiCad schematic, the PCB, the renders) is
generated. Here you author the **electrical design**: one Python netlist per
schematic sheet, and nothing else.

A netlist is **netlist-only** — it declares parts and nets and ports. It carries
no coordinates, no wire plans, no text positions. The placement engine derives
all geometry from the netlist's topology. This is enforced (see [Purity](#purity)
below), not a convention.

## Two kinds of carrier sheet

Every name in this directory is exactly one of two kinds. The kind is mechanical:
a sheet is an **adapter** if and only if a reusable library package exists at
`../../subsystems/<name>/`; otherwise it is a carrier **local**. The two kinds
have different on-disk shapes, and the gate below proves each one matches.

### Adapter — a thin bind over the reusable library

When the design is portable, its circuit lives once in the project-agnostic
library at [`../../subsystems/<name>/`](../../subsystems/README.md) with abstract
net names. The library package already owns the README, the SPICE model, and the
tests, so the carrier side must not duplicate them. An adapter is therefore a
**flat pair**, not a folder:

```
carrier/subsystems/<name>.py        the bind (circuit() + META)
carrier/subsystems/test_<name>.py   the local bind guard
```

The `.py` declares one module-level `META` dict and forwards it:

```python
from subsystems.ethernet import ethernet as _lib
from schgen.core.model import Circuit

META = {
    "bind":    {"MDI0_P": "ETH_PHY_MDI0_P", "MDI0_N": "ETH_PHY_MDI0_N", ...},
    "expects": {"MX0_P": "rj45_connector (wave 2)", ...},
}

def circuit() -> Circuit:
    return _lib.circuit(META)
```

`META["bind"]` maps each abstract library net to this carrier's real net name,
so the emitted sheet matches a hand-written one. `META["expects"]` records
deferrals — ports that bind on another sheet — so a standalone link reports them
as awaiting that sheet instead of a silent open. The contract is
`schgen.core.subsystem.Meta`; an unknown top-level key is a hard error.

Current adapters: `camera`, `ethernet`, `hdmi_rx`, `hdmi_tx`, `lcd`, `microsd`,
`pd_input`, `pmod`, `pmod_expansion`, `rj45_connector`, `uart_bridge`,
`usb_jtag`, `usb_jtag_connector`, `usb_pd`, `usb_uart_connector`, `usbc_otg`.

### Local — carrier-specific glue authored from `parts/`

When a sheet only makes sense for this board, there is no library to point at.
It is authored here directly, composed from the generated `parts/` folders, and
kept as a self-contained **foldered package** with the same four-artifact parity
the library uses:

```
carrier/subsystems/<name>/<name>.py        the netlist
carrier/subsystems/<name>/__init__.py      re-exports circuit()
carrier/subsystems/<name>/README.md        purpose / interface / parts
carrier/subsystems/<name>/test_<name>.py   the local correctness test
carrier/subsystems/<name>/<name>.cir       the SPICE passive network
```

The locals cover the things unique to this carrier:

- **Mezzanine** — `som_j1`, `som_j2`, `som_j3`: the three DF40 SoM connectors.
  Their pinout is generated from `carrier/som_interface.json`, not hand-typed.
- **Power** — `power_som` (always-on +VIN→+5V_SOM buck feeding the SoM),
  `power_mon` (INA3221 rail telemetry), `som_decoupling` (power-entry decoupling
  under the mezzanine).
- **Bring-up** — `bringup_rails`, `bringup_en`, `bringup_en_modules`,
  `bringup_modules`: the DIP-switch / STM32-override gate cells, per-module power
  gates, and status LEDs.
- **Board services** — `board_aux` (gated +3V3_AUX rail), `board_services`
  (board-management peripherals on that rail), `debug_boot` (JTAG/SWD headers,
  boot-request DIP, reset).
- **Carrier connectors and IO** — `fmc`, `board_qwiic`, `user_io`, `mechanical`
  (mounting holes + chassis bond), `motor_pwm`, `motor_sense`, `hdmi_rx_term`.

## Purity

A subsystem `.py` is netlist-only, enforced by an AST scan of the source before
the module is even imported. The build fails if the source:

- defines or binds a name `placer` (manual placement is banned — the engine
  derives all geometry from topology), or
- imports any geometry / placement API.

The runtime is checked too: a module that exposes a `placer` attribute fails.
Because the scan is on the source, a broken geometry import is still rejected.

## The structure gate

`schgen/verify/carrier_structure.py` is a hard gate (it fails the board). For
every subsystem it determines the kind — adapter iff `../../subsystems/<name>/`
exists, else local — and proves:

- the on-disk shape the kind requires is present (an adapter is the flat pair and
  has **no** leftover folder; a local is the foldered four-artifact package),
- `circuit()` is importable and runs without raising, and
- an adapter additionally exposes a `META` dict.

Run it standalone:

```bash
native/bin/schgen carrier-check --project carrier
```

The generic library packages under `../../subsystems/` are policed by the mirror
gate `schgen/verify/subsystem_structure.py`.

## Adding a sheet

The following describes the historical Python adapter layout, not native
registration. For a new native library package, run
`native/bin/schgen subsystem-new <name>` from the repository root and follow
its generated README for explicit CMake selection and builder registration.

In the former implementation there was no registration list: every
non-test `.py` module and every folder here is a subsystem. Expose a top-level
`def circuit() -> Circuit:` and name the circuit to match
(`Circuit("<name>", "…")`); the circuit name becomes the sheet and render name.

- A new **adapter**: scaffold the portable circuit into the library
  (the former `schgen subsystem <name>` command), then add the flat `<name>.py` bind plus
  `test_<name>.py` here.
- A new **local**: create the `<name>/` folder with all four artifacts and
  compose the netlist from `parts/`.

Build one sheet (all gates) or the whole board:

```bash
native/bin/schgen build <name> --project carrier
native/bin/schgen board --project carrier
```

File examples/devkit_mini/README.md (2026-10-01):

# devkit_mini — a second consumer of the `subsystems/` library

`devkit_mini` is a small, hypothetical baseboard whose purpose is to be a second,
independent consumer of the project-agnostic `subsystems/` library — alongside the
real `carrier/`. It imports the same library packages the carrier imports and binds
them to a deliberately different set of project net names. The only project-specific
code is the per-subsystem `META` dict in `devkit_mini.py`; the library files under
`subsystems/<name>/` are unchanged. If the subsystem abstraction holds, the same
`circuit()` builds onto two different boards with no library edits.

This is not a manufacturable board: it has no SoM, no power tree, and no connector
glue sheets. It is a portability proof — the four library subsystems compose into a
believable mini devkit under a fresh net-name binding, and the gates pass on the
composed result.

## Structure

| path | role |
|---|---|
| `devkit_mini.py` | the consumer: one thin adapter per subsystem (import the library module, declare a `META` dict, forward it to `circuit(META)`), plus `subsystem_circuits()` returning all bound `Circuit`s and `PROJECT` / `SHARED_RAILS` declarations |
| `__init__.py` | re-exports `PROJECT`, `subsystem_circuits`, and the four `*_circuit()` builders |
| `test_devkit_mini.py` | offline reuse proof (no kicad-cli, no network) |
| `schematic/<name>.kicad_sch` | per-subsystem schematics emitted by the build |
| `renders/<name>.png` | per-sheet PNG renders emitted by the build |
| `reports/` | gate outputs: `cc_gate.txt`, `board_gate.txt`, `board.erc.rpt` |
| `devkit_mini.kicad_pro`, `devkit_mini.kicad_prl`, `devkit_mini.kicad_sch` | the openable KiCad hierarchy project (root + per-sheet schematics) |

## The four reused subsystems

`devkit_mini.py` binds four library packages, in this order (`PROJECT`):

| `subsystems/<name>/` | function | key parts |
|---|---|---|
| `usb_pd` | FUSB302B USB Type-C / PD sink PHY | FUSB302BMPX |
| `usbc_otg` | USB 2.0 HS host port (Type-C) | TYPE-C receptacle, TPS2051C power switch, USBLC6-2SC6 ESD |
| `microsd` | TXS02612 level-translated microSD slot | TXS02612, microSD socket, TPD6E001 ESD |
| `uart_bridge` | CP2102N USB-UART console bridge | CP2102N-A02-GQFN24R |

Each adapter is the same shape as `carrier/subsystems/<name>.py`: import the library
module, declare one module-level `META` (`bind` / `expects` / `buses` / `notes`, the
`schgen.core.subsystem.Meta` contract), and return `_lib.circuit(META)`.

## Net-naming convention (distinct from the carrier)

The devkit chooses its own project net names so the re-bind is genuine rather than a
copy of the carrier's map. The devkit's host is treated as a hypothetical FPGA SoC,
which is why the host-side names read `+1V8_FPGA` and `FPGA_UART0_*`.

### Rails

| library abstract | devkit net | carrier net | meaning |
|---|---|---|---|
| `+VDD_LOGIC` (usb_pd, usbc_otg) | `+3V3_MINI` | `+3V3_SC` | shared 3.3 V logic rail |
| `+VDD_IO` (uart_bridge) | `+3V3_MINI` | `+3V3` | same shared rail |
| `+VDD_CARD` (microsd) | `+3V3_MINI` | `+3V3_SD` | same shared rail (carrier keeps a dedicated SD rail) |
| `+VDD_HOST` (microsd) | `+1V8_FPGA` | `+1V8` | SDIO host-signalling level |
| `+VBUS_SUPPLY` (usbc_otg) | `+5V_DEV` | `+5V_USB` | 5 V sourced onto the OTG cable |
| `+VBUS_SENSE` (usb_pd) | `+VBUS_RAW` | `+VBUS_IN` | raw receptacle VBUS the PD PHY senses |
| `GND`, `CHASSIS_GND` | `GND`, `CHASSIS_GND` | identity | the nets every board agrees on |

The defining choice: the carrier spreads its 3.3 V-class supplies over three rails
(`+3V3_SC`, `+3V3`, `+3V3_SD`), while the devkit collapses them onto one `+3V3_MINI`
rail shared by all four subsystems. That shared rail, together with `GND`, is the
cross-subsystem composition the test and the board netlist gate verify (`+3V3_MINI`
spans 4 sheets / 26 pins; `GND` spans 4 sheets / 37 pins).

### Buses and signal groups

| library abstract | devkit name | carrier name |
|---|---|---|
| I2C bus (`buses["i2c"]`) | `MINI_I2C0` | `STM32_I2C2` |
| `CC1` / `CC2` | `PD_CC1` / `PD_CC2` | `STM32_USB_CC1/2` |
| `SD_CLK/CMD/D0..D3` | `SD0_CLK/CMD/DAT0..3` | `SDIO_*` |
| `UART_TXD/RXD/RTS_N/CTS_N` | `FPGA_UART0_*` (post-crossover) | `ZYNQ_PS_UART0_*` |
| USB data / VBUS | `USB2_HOST_*` / `USB2_UART_*` | `USB_D+/-`, `USB_UART_*` |

The bridge↔host UART null-modem crossover (bridge `TXD` → host `RXD`, bridge `RTS_N`
→ host `CTS_N`, and vice versa) lives in the devkit's bind map, exactly as it lives
in the carrier's. Host-side wiring is a consumer decision, not part of the library.

## Build it

```sh
native/bin/schgen devkit --output /absolute/private/devkit-example
# Add --no-render to skip the PNGs; run from the repository root.
```

The native `devkit` command builds the four bound library subsystems through
`native/src/example_devkit_build.cpp`, using shared schematic placement,
emission, hierarchy, gate and rendering machinery. This example is distinct from
the full 12-sheet `board --project devkit_mini` project. The carrier-specific
steps (SoM DF40 contract, `sheet_index.json`,
carrier-structure gate, SoM-centered floorplan) do not apply because the devkit has
no SoM.

It writes under the required `--output` directory:

- `schematic/<name>.kicad_sch` — one schematic per subsystem,
- the `devkit_mini.kicad_pro` hierarchy root that opens them together,
- `renders/<name>.png` — per-sheet renders (best-effort; skipped with `--no-render`),
- `reports/cc_gate.txt`, `reports/board_gate.txt` and `reports/example_devkit.txt` — gate/build results.

The build passes only if every gate passes:

- the board netlist gate (`build_board`) confirms every linked net merges across
  sheets — the shared `+3V3_MINI` and `GND` rails span all four sheets, root ERC is
  clean;
- the geometry-only connected-components gate (`cc_gate`) confirms 0 shorts and 0
  opens across the composed board (each sheet's declared nets agree with its emitted
  geometry components).

## Test it

```sh
ctest --test-dir native/build/ci --output-on-failure --no-tests=error \
  -R '^native_example_devkit(_live)?_contracts$'
```

Configure and build first using [the native build guide](../../native/ci/README.md).
The native contracts are in `native/tests/example_devkit_contracts.cpp`; the live
contract requires KiCad and checks the hierarchy and mutations with rendering
disabled. These focused tests are not a
substitute for whole-board acceptance.

The retired `test_devkit_mini.py` supplied the historical offline coverage below,
parametrized over all four subsystems unless noted:

1. each library subsystem builds under the devkit `META` with no library edit;
2. every external net is a devkit name — no abstract interface name leaks (except
   identity-bound `GND`/`CHASSIS_GND`), and no carrier name appears (a real re-bind);
3. binding is a pure rename: bound rails still classify POWER/GROUND, bound ports
   still classify PORT;
4. the bind contract holds — it rejects an unknown name, a private SIGNAL net, a
   collision of two externals onto one net, and a typo'd top-level `META` key;
5. local gate slices pass on each bound circuit — `design_rules` DECAP/EP/STRAP,
   `part_rules`, and model completeness (every pin netted or NC); the DECAP rule is
   confirmed non-trivial at the project aggregate (`checked["decap"] >= 1`);
6. the bind is byte-stable — same parts, refs, and no-connects, and the net
   insertion order is preserved versus the standalone abstract build, so each power
   draw budget follows its renamed rail;
7. composition — `+3V3_MINI` and `GND` are the same net (same name, same class)
   across all four subsystems, and the only externals shared between subsystems are
   those two declared shared rails (no accidental private-signal clash);
8. library unchanged — binding the same `usb_pd.circuit()` to the carrier's names
   versus the devkit's names yields the carrier versus devkit net sets from one
   untouched source; the two sets overlap only on `GND`, and the part topology is
   identical;
9. the four bound subsystems place, route, and compose into one board with 0 shorts
   / 0 opens (`cc_gate`).

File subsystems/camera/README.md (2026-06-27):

# camera — Raspberry-Pi 15-pin FFC, 2-lane MIPI CSI-2 port (reusable subsystem)

A project-agnostic, self-contained schgen subsystem: a Raspberry-Pi 15-pin FFC
camera port carrying **2 data + 1 clock** MIPI CSI-2 D-PHY lanes, with fixed
external host-side differential terminations, low-capacitance ESD clamps, a
camera-control I2C bus, and a gated module-power rail. It declares its interface
as **abstract** port + rail names and knows nothing about any consuming board; a
project supplies a **bind map** (`abstract -> real net`) to drop it onto real
nets. It is the camera input for the Zynq-7000 SoM carrier.

## Interface

A consuming project supplies one standard `META` dict (`schgen.core.subsystem.Meta`)
and forwards it to `camera.circuit(META)`. The four keys are universal across every
reusable subsystem; an unknown top-level key is a hard `CircuitError`.

| key | role |
|-----|---|
| `bind` | `{abstract_net: board_net}` — rebinds every externally-visible net (`+VDD_CAM`, `GND`, and the 10 ports) to the project's real names. Applied last, order-preserving, so binding to a hand-written sheet's names yields a byte-identical sheet. POWER/GROUND/PORT only; a SIGNAL key or a collision is a hard error. |
| `expects` | `{abstract_port: deferral}` — attaches an explicit linker deferral declaring which project sheet binds a deferred port (CSI lanes / control lines). |
| `buses` | `{"i2c": name}` — the camera-control I2C bus-group name for `CAM_SCL`/`CAM_SDA` (defaults to abstract `CAM_CCI`, 400 kHz). |
| `notes` | `{"draws": prose}` — the power-tree draw-note prose (defaults to the RPi V2/IMX219 budget). |

With `meta=None` the subsystem keeps its abstract names so `test_camera.py` runs offline.

### Rails

| abstract | class | meaning / constraint |
|---|---|---|
| `+VDD_CAM` | POWER  | gated camera module rail (3.3 V class), FFC pin 15. A project **must** supply a gated rail here: the I2C pull-ups land on it, so a powered-down camera is not back-fed through its own bus pull-ups. Local 100n + 10u bypass at the connector live in this subsystem. Budget ~300 mA. |
| `GND` | GROUND | ground — FFC grounds (1/4/7/10), the two mounting-plate tabs (16/17), and the ESD-array GND pads. |

### Ports

| abstract | type | FFC pin(s) | meaning |
|---|---|---|---|
| `CSI_D0_P` / `CSI_D0_N` | diff_pair @100R | 3 / 2 | CSI-2 data lane 0 (N before P on the FFC). |
| `CSI_D1_P` / `CSI_D1_N` | diff_pair @100R | 6 / 5 | CSI-2 data lane 1. |
| `CSI_CLK_P` / `CSI_CLK_N` | diff_pair @100R | 9 / 8 | CSI-2 clock lane. |
| `CAM_SCL` / `CAM_SDA` | i2c (bus `CAM_CCI`, 400 kHz) | 13 / 14 | camera-control I2C (MIPI CCI class); 4k7 pull-ups to `+VDD_CAM` live here. |
| `CAM_EN`  | single | 11 | module power-enable / shutdown (RPi `CAM_GPIO0`). |
| `CAM_LED` | single | 12 | LED indicator (RPi `CAM_GPIO1`, v1-module only — kept routed). |

D-PHY pairs are **not** polarity-swappable (P→P, N→N). The diff-pair typing is
authored reciprocally so a router/linker sees the pairing both ways; binding
preserves it, keeping the derived `layout_constraints.csv` pair_with / length-match
group and the XDC pair byte-stable.

## Design

- **Reference connector — Amphenol SFW15R-1STE1LF (LCSC C3168538).** 1.0 mm pitch,
  15-position, **bottom-contact** FFC (contact orientation verified against Amphenol
  drawing 10172241). FFC pad *n* = RPi camera FFC pin *n*; the bare-number FFC pins
  stay numeric. The connector symbol/footprint and MPN come from the global parts
  library entry, and the board-level netlist gate proves KiCad sees every FFC pad.

- **HS-RX termination (Xilinx XAPP894).** The host uses the Xilinx XAPP894
  "7-series + external passives" topology to receive MIPI D-PHY: a **fixed external
  100R** differential termination per pair (R1–R3), placed at the FPGA/SoM-connector
  **end** of each trace — not at the FFC. R1–R3 stay **populated**: a 7-series HR-bank
  RX cannot gate `DIFF_TERM`, so the fixed 100R is required for HS reception and is
  not redundant. Low-Power (LP) observability — driving/sensing the lanes single-ended
  below the HS burst — is handled by the XAPP894 LP resistor-divider DNP stuffing
  option, which lives off this FFC sheet (CAM-1).

- **ESD — two TI TPD4E02B04DQAR low-cap arrays (LCSC C106794).** 0.2 pF/line typ
  (well under the D-PHY budget), 8 kV contact / IEC 61000-4-2. U1 clamps the 4 CSI
  data lines (D0 + D1, channels IO1–IO4); U2 clamps the CLK pair (IO1/IO2). The two
  spare U2 channels (IO3 = pad 4, IO4 = pad 5) clamp the cable-facing I2C control
  lines `CAM_SCL`/`CAM_SDA` — the same FFC, so the slow lines get GND-referenced ESD
  for free (0.2 pF negligible at 400 kHz). All clamps are DC-coupled **shunt taps**
  added to the existing line nets (never in series), so the netlist proves
  `{J1.pin, term, U.IOn}` per line. The arrays are GND-referenced (no VCC), so they
  remain valid and cannot be back-powered when the gated `+VDD_CAM` is off. The
  remaining USON-10 spare pads stay NC (U1: 6/7/9/10; U2: 6/7/9/10). `CAM_EN`/`CAM_LED`
  stay unclamped — no spare channels remain, an accepted trade for static GPIO.

- **Gated rail + pull-ups (back-feed).** The 4k7 I2C pull-ups (R4, R5) tie to the
  gated `+VDD_CAM`, so a powered-down camera is not back-fed through its own bus
  pull-ups. `CAM_EN` gives a logic-level shutdown independent of the rail gate. At
  the connector: 100n (C1) + 10u (C2) local bypass.

- **Bring-up.** Testpoints on `CAM_SCL`, `CAM_SDA`, and `CAM_EN` make the control
  bus and the module enable probeable. Power-tree budget: 300 mA on `+VDD_CAM`
  (RPi V2/IMX219 typ ~250 mA incl. the I2C pull-ups).

## Parts

| ref | value | lib / part | LCSC |
|-----|---|---|---|
| J1 | SFW15R-1STE1LF | `parts/SFW15R-1STE1LF/` (1.0 mm 15P bottom-contact FFC) | C3168538 |
| R1–R3 | 100R | `Device:R` (D-PHY diff terminations) | C22775 |
| R4, R5 | 4k7 | `Device:R` (`CAM_SCL`/`CAM_SDA` pull-ups to `+VDD_CAM`) | C23162 |
| C1 | 100n | `Device:C` (`+VDD_CAM` bypass) | C14663 |
| C2 | 10u  | `Device:C` (`+VDD_CAM` bulk) | C15850 |
| U1, U2 | TPD4E02B04DQAR | `parts/TPD4E02B04DQAR/` (low-cap 4-ch ESD array, 0.2 pF/line) | C106794 |

## Build & test

`test_camera.py` runs the subsystem-local slices offline: declared abstract
interface, reciprocal diff-pair typing, model completeness (every FFC pad netted),
the I2C-pull-up design rule, part-rating + per-rail cap-derating coverage, the SPICE
subckt ↔ netlist passive match, and the bind/meta contract. Cross-board gates (link
graph, full power-tree headroom, board ERC, netlist merge) run at board level via
`schgen board`.

```bash
PYTHONPATH=. python3 -m pytest subsystems/camera/test_camera.py -q
```

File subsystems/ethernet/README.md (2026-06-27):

# ethernet — HX5008NL 1000BASE-T magnetics + Bob-Smith termination

A project-agnostic, reusable schgen subsystem providing the Pulse HX5008NL single-port
1:1 gigabit Ethernet magnetics module with its media-side Bob-Smith (IEEE 802.3 §40.7.1)
HF common-mode termination. It supplies the transformer isolation between the Zynq-7000
SoM's PHY and the RJ45 jack on the carrier. The RJ45 jack itself is a separate subsystem
(`rj45_connector`); this package owns only the magnetics and the Bob-Smith network and
exposes the media-side pairs as ports for the jack to bind.

## Interface

The subsystem declares its interface as abstract net names and knows nothing about any
consuming board. A project supplies the standard `META` dict (`schgen.core.subsystem.Meta`)
and forwards it to `ethernet.circuit(meta)`.

- `bind` — `{abstract_net: real_board_net}`, renames every externally-visible net in
  place, order-preserving. POWER/GROUND/PORT only; a SIGNAL key, a typo, or a collision is
  a hard `CircuitError`. Binding to the exact names a hand-written sheet uses yields a
  byte-identical emitted sheet.
- `expects` — `{abstract_port: deferral}`, threads a project's linker deferral onto a port
  via `meta.expect_kw`. Used to tell the linker which sheet binds the media-side pairs
  (the `rj45_connector` sheet). Only the P net of a pair is named; the reciprocal N
  inherits the deferral.

With `meta=None` the subsystem keeps its abstract names so `test_ethernet.py` runs offline.

**Rail (GROUND)**

| abstract | meaning |
|---|---|
| `CHASSIS_GND` | chassis-ground island, kept separate from any signal GND; the Bob-Smith trunk bypasses to it through the single barrier cap C5. Star-bonded to signal ground by the consuming board. |

**Ports (PORT — all 100 Ω differential pairs)**

| abstract | side | meaning |
|---|---|---|
| `MDI0_P/N` … `MDI3_P/N` | CHIP (PHY-facing) | the four 1000BASE-T pairs facing the SoC/PHY; bind to the host PHY's MDI lanes. |
| `MX0_P/N` … `MX3_P/N` | MEDIA (RJ45-facing) | the four pairs facing the RJ45 jack; bind to the `rj45_connector` subsystem via `expects`. |

The 1:1 winding is in phase, so `+` couples to `+` (`MDIn_P ↔ MXn_P`).

`MCT1..MCT4` (media centre taps) and `BS_COMMON` (the Bob-Smith trunk) are private SIGNAL
wiring and are never part of the interface.

The carrier adapter is `carrier/subsystems/ethernet.py`.

## Design

- **Magnetics part.** T1 is the Pulse HX5008NLT (LCSC C962544), a 24-pad single-port 1:1
  gigabit magnetics module, referenced from the global `parts/HX5008NLT/` dossier (verified
  pad-for-pad against Pulse datasheet PS-0118.001-D Rev A, Sheet 2). Its `ALT_LCSC` field
  carries the HX5008NLTP-CND clone C47575004 as a stock-floor fallback. The pinout is:

  ```
      CHIP / PHY side                MEDIA / RJ45 side
      1  TCT1                        24 MCT1
      2  TD1+   3  TD1-              23 MX1+   22 MX1-
      4  TCT2                        21 MCT2
      5  TD2+   6  TD2-              20 MX2+   19 MX2-
      7  TCT3                        18 MCT3
      8  TD3+   9  TD3-              17 MX3+   16 MX3-
      10 TCT4                        15 MCT4
      11 TD4+  12 TD4-              14 MX4+   13 MX4-
  ```

  Per channel the chip pair `TDn` maps to abstract `MDIn`, the media pair `MXn` to abstract
  `MXn`, the media centre tap `MCTn` to the Bob-Smith trunk, and the chip centre tap `TCTn`
  to a no-connect.

- **Differential typing.** Every MDI and MX pair is typed as a 100 Ω `diff_pair` for
  1000BASE-T. Typing is done in abstract names; `bind` rebinds each pair's `pair_with`
  complement through the rename map so bound pairs stay consistent for the SI pair-join.

- **Bob-Smith termination.** Each media centre tap carries a 75 Ω ∥ 1 nF into the shared
  `BS_COMMON` trunk (IEEE 802.3 §40.7.1 common-mode HF return). The trunk bypasses to the
  chassis island through one 1 nF / 2 kV barrier cap (C5). C5 is the single element bridging
  the signal and chassis domains and is the isolation barrier.

- **Caps are 2 kV.** All five 1 nF caps (C1..C5) are genuine 2 kV X7R 1206 parts
  (IEC 60950/62368 hi-pot); the 2 kV rating forces the 1206 body. The value is drawn `1n`
  for schematic economy.

- **Chip-side centre taps are no-connects.** A voltage-mode-driver PHY (e.g. RTL8211F)
  self-biases its own transmit common mode, and a typical mezzanine exposes only the MDI
  pairs, so the four chip-side taps (pins 1/4/7/10) are explicit no-connects.

- **Chassis ground.** `CHASSIS_GND` is a separate island, star-bonded to signal ground by
  the consuming board; it is not a signal GND. It is the only externally-visible non-port
  net, since the magnetics are passive and self-isolating.

## Parts

| ref | value | lib / part | LCSC |
|-----|---|---|---|
| T1 | HX5008NLT | `parts/HX5008NLT/` (24-pad 1:1 gigabit magnetics) | C962544 (alt C47575004) |
| R1..R4 | 75R | `Device:R` 0603 (Bob-Smith) | C4275 |
| C1..C4 | 1n | `Device:C` 1206 / 2 kV (Bob-Smith HF) | C9196 |
| C5 | 1n | `Device:C` 1206 / 2 kV (BS trunk → chassis, the isolation barrier) | C9196 |

## Build & test

`test_ethernet.py` runs the subsystem-local gate slices offline (abstract interface and
net classes, the pin-faithful HX5008NL mapping, model completeness, diff-pair typing, the
Bob-Smith network, part ratings incl. the 2 kV caps, the SPICE-subckt ↔ netlist passive
match, and the bind contract). Cross-board gates (link/port-driver graph, full SI
constraint set, board ERC, netlist merge) run at board level via `schgen board`.

```bash
PYTHONPATH=. python3 -m pytest subsystems/ethernet/test_ethernet.py -q
```

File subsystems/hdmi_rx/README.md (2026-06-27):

# hdmi_rx — HDMI Type-A sink: receptacle + TMDS-RX ESD + EDID EEPROM

A project-agnostic, reusable schgen subsystem providing an HDMI Type-A receptacle
as a video **sink** on the Zynq-7000 SoM carrier. It carries the four DC-coupled
TMDS RX lanes into the receiver bank behind low-cap ESD, a cable-5V-powered EDID
EEPROM on the source-mastered DDC bus, passive hot-plug-detect assert, a 5V
presence divider, and CEC. It declares its interface as abstract port/rail names
and knows nothing about any board; a consuming project supplies a bind map.

## Interface

The subsystem exposes abstract net names; a consuming project binds them via the
standard `META` adapter contract (`schgen.core.subsystem.Meta`). Rails classify by
name (leading `+` → POWER; `GND`/`CHASSIS_GND` → GROUND), so standalone and bound
builds share net classes. `bind` rebinds externally-visible nets in place and
order-preserving, so binding to the names a hand-written sheet used yields a
byte-identical emitted sheet.

**Rails:** `+VDD_LOGIC` (POWER, gated module rail — only the CEC pull-up draws
here), `GND`, `CHASSIS_GND` (the four HDMI shell legs; star-bonded to `GND` by
the consuming board).

**Ports:** `TMDS_RX_{D2,D1,D0,CLK}_{P,N}` (four RX differential pairs, typed
`tmds_pair`, into the receiver bank), `HDMI_5V_DET` (cable-5V presence-detect
divider output), `CEC` (3V3-domain CEC to the receiver).

The DDC I2C (`HDMI_RX_SDA`/`HDMI_RX_SCL`), HPD assert (`HDMI_RX_HPD`) and the
cable-5V quasi-rail (`HDMI_RX_5V`) are **private SIGNAL wiring** — they run
entirely connector ↔ EEPROM ↔ ESD on this sheet and are never part of the
contract. HDMI pin 14 (HEC/Utility) is reserved → author no-connect.

```python
from subsystems.hdmi_rx import hdmi_rx

META = {
    "bind": {
        "+VDD_LOGIC": "+3V3_HDMI_RX", "GND": "GND", "CHASSIS_GND": "CHASSIS_GND",
        "TMDS_RX_D2_P": "MY_TMDS_2_P", "TMDS_RX_D2_N": "MY_TMDS_2_N",
        # ... D1 / D0 / CLK ...
        "HDMI_5V_DET": "MY_5V_DET", "CEC": "MY_CEC",
    },
    # optional: tell the linker which sheet binds a deferred port
    # (the P line of each TMDS pair carries the pair's deferral)
    "expects": {"TMDS_RX_D2_P": "my_connector", "CEC": "my_connector"},
    # optional power-tree draw-note override
    "notes": {"draws": "CEC 27k pull-up (...)"},
}

def circuit():
    return hdmi_rx.circuit(META)
```

The carrier adapter is `carrier/subsystems/hdmi_rx.py`.

## Design

**Connector.** J1 is the SOFNG HDMI-019S receptacle, drawn from its faithful
`parts/HDMI-019S/` dossier symbol. The dossier box lays its 23 pins out by package
edge (1–9 left, 10–23 right, +5V top, GND bottom), with each shield pad distinct:
TMDS shields (2/5/8/11) and pin 17 to `GND`; the four shell tabs (20–23) to
`CHASSIS_GND`. Pin 14 is reserved → no-connect.

**DC-coupled TMDS RX + ESD.** Each of the eight single-ended TMDS lines is one net
from the receptacle to the receiver bank — DC-coupled, with ESD applied as a shunt
TAP, not a series break (the netlist proves each lane is `{J1.pin, U.IOn}`). Two
TI TPD4E02B04DQAR 4-channel GND-referenced arrays cover the eight lines (D2+D1 on
U2, D0+CLK on U3); chosen for 0.2 pF/line typ I/O capacitance (≪ the 0.5 pF/line
TMDS budget) and 8 kV contact (IEC 61000-4-2). Spare USON-10 pads are no-connect.

**Sink termination lives at the receiver.** TMDS sink termination (2×49.9 Ω/pair
to a local 3.3 V AVCC island, 8 R for the 4 pairs) is a mandatory **layout
requirement placed at the FPGA bank balls**, not on this sheet. A 7-series HR bank
cannot self-terminate TMDS_33 (only HP banks implement DIFF_TERM, UG471), so
external sink termination is required — but terminating at the far connector end
would stub the line and reflect, so it must sit at the receiver end.

**EDID EEPROM, cable-5V powered.** U1 is an ST M24C02 (2-Kbit I2C EEPROM, stock
`Memory_EEPROM:M24C02-WMN` symbol) on the source-mastered DDC bus. It runs from
the cable's +5V (pin 18) so the sink presents EDID even when the consuming board
is off (HDMI 1.4 §8.5). E0/E1/E2 are grounded (address 0xA0/0x50). DDC pull-ups
live on the source side per spec — none are duplicated here. C1 (100n) bypasses
the EEPROM VCC.

**EDID write-protect.** WC# (U1.7) is hardwired to the EEPROM's own cable-5V VCC
node (U1.8), so a runtime DDC write can never corrupt the fixed EDID. This is a
permanently write-protected EDID by design, with no field-reprogram path. A gated
3.3 V rail would be wrong twice — domain (dead in the board-off EDID-read case →
WC# floats → write-enabled) and level (the 5 V-VCC EEPROM's VIH(min) =
0.7·VCC ≈ 3.5 V > 3.3 V).

**HPD assert + presence detect.** R1 (1k) from cable 5V to HPD (pin 19) asserts
hot-plug passively, so a plugged source reads EDID with zero board involvement.
HPD is 5-V-domain and stays private (not routed to a 3V3 bank). R3/R4 form a
10k/15k divider on the cable 5V giving `HDMI_5V_DET` (3.15 V max at 5.25 V,
LVCMOS33-safe) for off-sheet source-presence sensing.

**CEC.** Routed to the receiver with the spec 27k pull-up (R2) to the gated module
rail `+VDD_LOGIC` — the only load on that rail (~0.12 mA when CEC is driven low).

**Slow-line ESD.** U4 is one TI TPD4E05U06DQAR (4-channel, GND-referenced, no VCC
pin) protecting the four slow lines as detached shunt taps: D1+ = SCL, D1- = SDA
(DDC, 3.3 V); D2+ = CEC (3.3 V), D2- = HPD (5 V). Its VRWM = 5.5 V is above the
5.25 V max cable rail, so the one part safely serves both the 3.3 V DDC pair and
the 5 V CEC/HPD lines (a 3.6 V-standoff part would conduct at 5 V, which is why
the TMDS array is not reused here). 0.5 pF/line typ, ±12 kV IEC 61000-4-2. Spare
USON-10 pads are no-connect.

## Parts

| ref | value | lib / part | LCSC |
|-----|---|---|---|
| J1 | HDMI-019S | `HDMI-019S:HDMI-019S` (dossier) | C111617 |
| U1 | M24C02-WMN6TP | `Memory_EEPROM:M24C02-WMN` | C7562 |
| U2 | TPD4E02B04DQAR | `TPD4E02B04DQAR` (dossier) | C106794 |
| U3 | TPD4E02B04DQAR | `TPD4E02B04DQAR` (dossier) | C106794 |
| U4 | TPD4E05U06DQAR | `TPD4E05U06DQAR` (dossier) | C138714 |
| R1 | 1k | `Device:R` | C21190 |
| R2 | 27k | `Device:R` | C22967 |
| R3 | 10k | `Device:R` | C25804 |
| R4 | 15k | `Device:R` | C22809 |
| C1 | 100n | `Device:C` | C14663 |

LCSC for J1/U1/U2/U3/U4 come from the global `parts/<MPN>/` dossiers.

## Build & test

`test_hdmi_rx.py` runs the subsystem-local electrical slices offline: abstract
interface + TMDS-pair types, model completeness (every pin netted-or-NC, ESD pads
NC), the EDID WC#-to-cable-5V hardwire, decoupling/strap rules, part-rating
coverage, the SPICE-subckt ↔ netlist passive match, the dossier symbol, and the
bind contract. Cross-board gates (DDC source pull-ups, receiver TMDS termination,
link graph, power-tree headroom, ERC, board netlist merge) run at board level.

```bash
PYTHONPATH=. python3 -m pytest subsystems/hdmi_rx/test_hdmi_rx.py -q
```

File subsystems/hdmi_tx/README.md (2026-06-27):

# hdmi_tx — HDMI source port (TPD12S016 + HDMI Type-A receptacle)

This subsystem is the HDMI **source** front-end for the Zynq-7000 SoM carrier: a
TI **TPD12S016** level-shift / ESD-clamp / +5V load-switch device driving a
**HDMI Type-A receptacle** (SOFNG HDMI-019S). The host TMDS lines flow through
the TPD's clamps to the connector, while DDC/CEC/HPD pass through its level
shifters between the controller-side V_CCA domain and the cable's 5 V. It is a
project-agnostic, reusable subsystem: it declares its interface as abstract port
and rail names and knows nothing about any consuming board.

## Interface

A consuming project supplies a single standard `META` dict
(`schgen.core.subsystem.Meta`) and forwards it to `circuit(meta)`. With
`meta=None` the abstract names are kept so `test_hdmi_tx.py` runs offline.

**Rails** (classified POWER/GROUND by name; leading `+` = POWER):
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

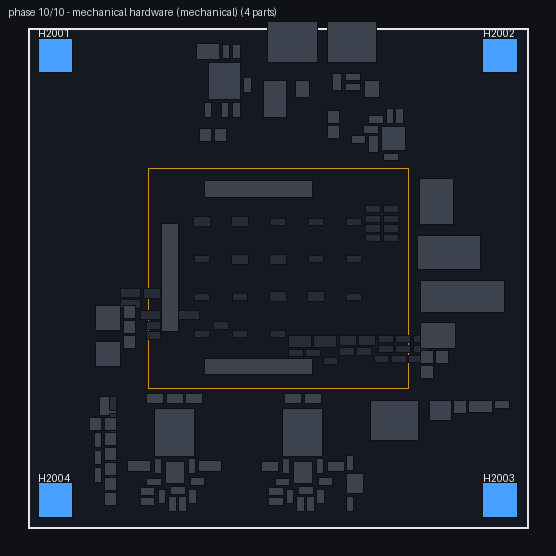
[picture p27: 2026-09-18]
devkit_mini/renders/assembly/phase_10_mechanical.png

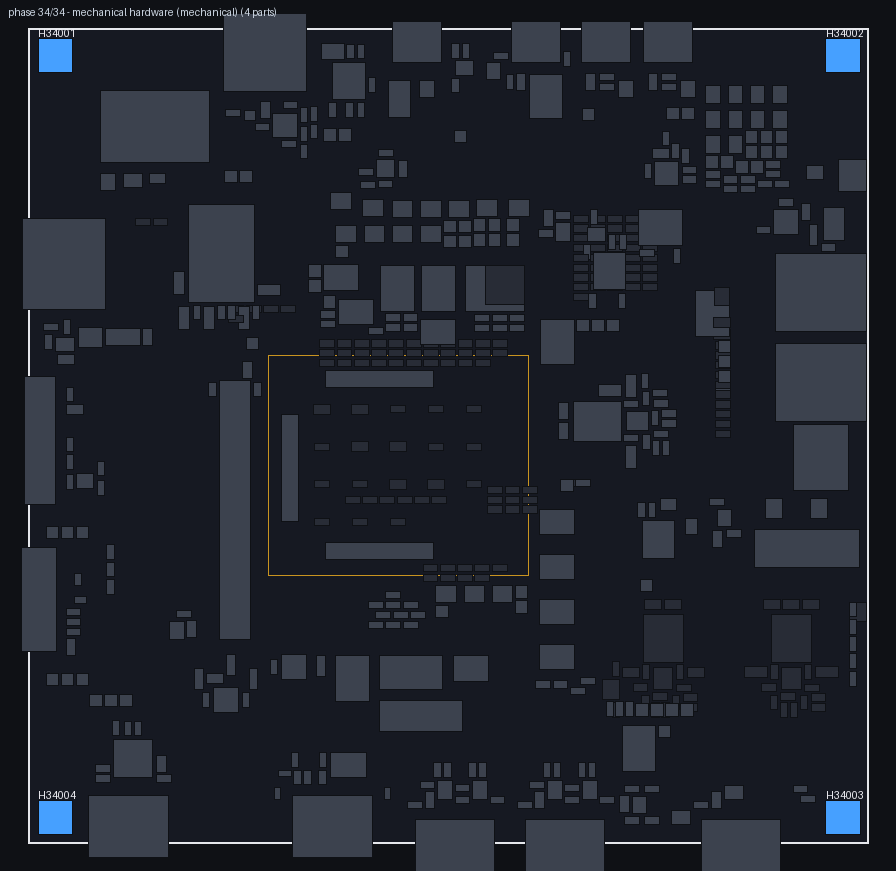
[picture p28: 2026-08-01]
carrier/renders/assembly/phase_34_mechanical.png

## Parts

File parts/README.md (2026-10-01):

# parts/ — the component library

One folder per physical component, named by its **manufacturer part number**
(MPN). Each folder is self-contained and fully **generated** from the part's
LCSC/EasyEDA data — nothing here is hand-edited; re-run the generator to update
a part.

```
parts/FUSB302BMPX/
  part.json                 # metadata + pin table (compiled into native/catalog.bin)
  FUSB302BMPX.kicad_sym     # schematic symbol
  FUSB302BMPX.kicad_mod     # footprint (pads exact to the physical part)
  FUSB302BMPX.step          # 3D model (MCAD)
  FUSB302BMPX.wrl           # 3D model (KiCad viewer)
  FUSB302BMPX.easyeda.json  # raw EasyEDA API response (provenance + offline regen)
```

`part.json` is the authored electrical contract (`schema: schgen.part/1`).
The native CMake build described in [the build guide](../native/ci/README.md)
compiles every `parts/*/part.json` into
`native/catalog.bin` (interned strings, pin tables, mmap). Runtime `use_part`
looks up that binary — it does not parse JSON or exec Python. Required fields:
`mpn`, `safe_name`, `lcsc`, `description`, `manufacturer`, `package`,
`jlc_class`, `prefix`, `datasheet`, `product_url`, `lib_id`, `footprint`,
`models_3d`, and `pins` (`num` / `name` / `etype`). Unknown keys fail the
compile. Footprint copper stays in `.kicad_mod` (sexpr).

## Adding a part

Find the part on lcsc.com / jlcpcb.com/parts, note its `C`-number, and run:

```bash
native/bin/schgen part-import --parts-root parts --lcsc C132291 --catalog native/catalog.bin
```

This is the native part-import pipeline: fetch the CAD
payload from the public EasyEDA component API, parse it, and write the
`parts/<MPN>/` folder. It either produces a complete folder or fails — no
partial package output. Existing packages require explicit `--overwrite`.
The optional `--catalog` refresh happens after package publication; a catalog
refresh failure returns an error but does not undo the published package.

For a network-free, byte-stable regeneration, point it at the cached payload:

```bash
native/bin/schgen part-import --parts-root parts \
  --from-json parts/FUSB302BMPX/FUSB302BMPX.easyeda.json \
  --overwrite --catalog native/catalog.bin
```

Run these commands from the repository root. The cached-payload command explicitly
replaces an existing package; omit `--overwrite` when replacement is not intended.
To refresh only the catalog after changing part metadata:

```sh
native/bin/schgen catalog-compile parts native/catalog.bin
```

## What the generator produces

- **Symbol (`.kicad_sym`)** — drawn by the generator's own layout rules, not a
  copy of the EasyEDA drawing. Every pin connection point sits on the 1.27 mm
  grid; pins are grouped left = inputs, right = outputs/signals, top = power
  rails, bottom = GND/NC; the body is sized so pin-name text from opposite sides
  can never collide. Two-pin parts and R/C/L/FB prefixes are forced `passive`,
  and protection/ESD arrays that EasyEDA mislabels as all-`input` are
  normalized to `passive` (an all-input table is electrically impossible).
  Before the folder is accepted the symbol is loaded through
  `schgen.core.symbols.Library`, so the build never ships a symbol its own
  loader would reject.

- **Footprint (`.kicad_mod`)** — a faithful conversion of the EasyEDA land:
  pad positions, shapes, drills, slots, and silk/fab/courtyard graphics are
  converted exactly; only decorative lead/paste fills are dropped. A large SMD
  pad (>= 2.0 mm on both sides — exposed/thermal pads, connector tabs) gets
  copper + mask plus a windowed paste grid instead of one full aperture, so it
  does not float or squeeze out under reflow (IPC-7525 paste-volume control).

- **3D model (`.step` + `.wrl`)** — downloaded from EasyEDA when hosted. The
  footprint references the `.wrl` for the KiCad viewer and carries the `.step`
  for MCAD export. An implausible model offset (an EasyEDA unit mismatch that
  would plant a centered package a metre off its pads) is reset to the origin.

### Synthesized EP pad and polarity silk

Some EasyEDA lands omit a center exposed/thermal pad that the datasheet does
dimension, or drop a polarity `+` glyph on the import. The generator
re-synthesizes these from a **datasheet-cited, LCSC-keyed allowlist**
(`PACKAGE_EP`, `PACKAGE_SILK_PLUS` in `part_gen.py`), so the EP lands as a real
pad **and** a real symbol pin nettable to GND — never a prose layout note — and
the `+` lands on `F.SilkS` so a polarized part cannot be inserted reversed. Any
part not on the allowlist regenerates byte-identically; this keeps both fixes
auditable and scoped to the exact parts that need them.

## How parts are used

Subsystems never vendor a symbol into a sheet. They reference a part by MPN:

```python
self.use_part("FUSB302BMPX", "U1")
```

`use_part()` (`schgen/core/model.py`) mmaps `native/catalog.bin` and takes the
`lib_id`, `footprint`, reference prefix, LCSC code, and the **named** pin table
from the compiled record. Inline part metadata is rejected. A missing
`part.json` or a stale/absent catalog is a build error that names
the native import/catalog workflow above. Because the pin table is named,
sheets wire pins by name and the build validates them against the symbol. The
`LCSC` code carried on every part keys the BOM and the datasheet ratings
checks, so a part's orderable identity can never drift from its library folder.

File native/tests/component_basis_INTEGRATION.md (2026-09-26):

# Native component basis and copper provenance

Worker scope: new audit sources, native contracts and authoring adapter cleanup.
Parent owns CMake, module, CLI, catalogs, shared builds and commits.

## Parent integration

Add exactly these new sources to `schgen_core`:

* `src/component_basis.cpp`
* `src/component_basis_registry.cpp`
* `src/copper_debt.cpp`

Use strict C++17 and `-Wall -Wextra -Wpedantic -Werror -ffp-contract=off`.
No third-party dependency, subprocess, Python interpreter or source parser is
needed by these production sources. Existing thermal/PCB/authoring core APIs
are reused. Do not add `circuit_helpers.cpp` or other authoring sources again.

Transitional extension: include `schgen/authoring_audit_bindings.hpp` in module.cpp
and call `schgen::bind_authoring_audits(m)` once. The header reuses existing
thermal/emitter policy transports; it does not register those bindings twice.
It exposes `component_basis_policy`, `component_basis_inputs`,
`component_basis_audit`, `copper_debt_scan`, `copper_debt_analyze`, and
`copper_debt_report`.

Add contract executables from `tests/component_basis_contracts.cpp` and
`tests/copper_debt_contracts.cpp`, linked to schgen_core. Both take one argument:
the absolute repository path. Register as CTest tests with the same strict
flags. The worker-only runner `run_component_basis_contracts.sh` builds private
executables against a copied archive; `AUTHORING_AUDIT_UBSAN=1` instruments the
new audit sources and contracts without modifying shared binaries.

## Native pipeline calls

Open the current part catalog through the normal explicit boundary. Build the
66 live circuits using `author_component_basis_inputs(repository)`, or supply
caller-owned `ComponentBasisInput {scope, sheet, circuit}` records.
Call `audit_component_basis(inputs)`; a false `ok()` must fail the component
basis gate. Publish `component_basis_report(result)` if desired.

The scopes library/carrier/devkit_mini are independently manifested. Missing,
extra or duplicate sheets fail. For a selected scope, pass its explicit set;
include every sheet expected by that scope. No empty/unrecognized-scope PASS.
The default registry contains 214 declarations and 685 expanded obligations.
The obligations are independent of the authoring functions: changing a builder
does not silently update its expectations.

For copper provenance, `author_copper_debt_sources(repository)` creates the live
global claim universe plus native policies. Before analysis, replace matching
project circuits with the actual IR sent to netlisting, and supply the actual
board's `ThermalPolicy`, `PcbEmitPolicy`, and researched differential geometry.
Do not overwrite caller edits by reloading circuit snapshots.

Scan actual output with `scan_thermal_copper(pcb_path)`, then call
`analyze_copper_debt(&scan, sources)`; a null scan preserves UNMEASURED status.
`CopperProvenanceError` is a hard provenance failure; emitted/partial/nothing
debt remains report-only. Write `copper_debt_report(result) + "\n"` to the normal
report location using the pipeline's atomic publication helper.

This is a global claim ledger: a claim can describe a component absent on one
board (e.g. FMC on devkit). Its native library/project definition is still
verified, and the actual PCB scan determines the reported copper evidence.
The provenance never searches C++ strings or trusts a source filename as proof.
Native claim lines are diagnostic source links only.

## Compatibility and rollout

The parent has integrated the sources, contract targets and extension bindings.
The Python adapters now use them: native component basis replaces the default
repository census, and native copper scanning/analysis/reporting replaces the
production Python ledger. Explicit custom-Python-package source census and
`_where` helper APIs retain compatibility for existing callers/tests; neither
is a fallback after native failure, and standalone gates never call them.
Public Python component constants/registrations remain API-compatible.
The 64 inactive constructor/helper bodies (2,044 lines) have been removed
without deleting their modules or changing immutable fixtures.

Parent-owned Python CLI wiring: change the ledger call to
`copper_debt.run(rep_dir, _pcb_file, sheets=sheets)`. The optional `project=`
argument identifies the project scope when it differs from PROJECT_ROOT.name.
The entire supplied project replaces its native default scope, so missing/extra
sheets cannot be concealed by filling gaps from factory defaults. Mutations in
the actual netlisted connections are verified before copper reporting.

Copper report titles, assumptions, statuses, emitted evidence, risks and
inventory remain Python-equivalent. Native source locations and the provenance
introduction intentionally change, so both copper_debt reports and their
manifest hashes need the parent's normal artifact-validation/commit workflow.

## Current stable handoff

The native audit suites pass 1,936 component-basis and 1,522 copper-debt
contracts with strict C++17 and again with UBSan. Binding-header syntax was
checked with the same warning policy. All three fixture hashes are unchanged.
Audit adapters and legacy-constructor cleanup are now implemented and tested.

The separate twin-parity fix is ready: all 43 Python project adapters obtain
`PROJECT` from their owning project's basis module, whose key is derived from
its own file location. Detached gate copies retain their owner through that
import; their asset root still comes from the adapter's own location.
No process-selected project or original-root fallback is used.

Ten actual source twins retain the original verbatim parity check. Power,
debug_boot and power_mon deliberately differ between boards and now have
complete independent pre-migration IR comparisons instead of a false claim of
source identity. Equivalent fixture checks also cover the shared circuits.
The post-cleanup authoring suite passes 991 existing focused tests: all library
and project package tests, twin/variant parity, detached adapters, Circuit
model/IR/meta helpers, structure, component basis, copper and thermal gates.
New `schgen/tests/test_authoring_native_audits.py` covers every original library
parameter case through both dict and Meta transport, all 49 project circuits,
eight dynamic connector cases, live registration/constant/component drift,
actual netlisted connection edits and policy drift. It also proves production
audits do not call the retained Python-source compatibility helpers.
No board artifacts were rewritten. Use fresh pytest processes after import
changes; a process that cached the old basis module lacks its PROJECT export.

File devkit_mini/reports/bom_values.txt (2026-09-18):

bom value gate (LCSC actual value == declared value)
============================================================
catalog: 102 LCSC codes; 106 inline-passive checks
mismatches: none

UNVERIFIED — reported, NOT failing (3):
  som_j1:J1 'DF40C-100DP-0.4V(51)' LCSC C531031 (not in catalog)
  som_j2:J2 'DF40C-100DP-0.4V(51)' LCSC C531031 (not in catalog)
  som_j3:J3 'DF40C-100DP-0.4V(51)' LCSC C531031 (not in catalog)

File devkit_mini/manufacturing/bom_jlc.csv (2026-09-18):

Comment | Designator | Footprint | LCSC
100R | debug_boot:R3 | Resistor_SMD:R_0603_1608Metric | C22775
100k | pd_input:R3,pd_input:R6,power:R8 | Resistor_SMD:R_0603_1608Metric | C25803
100n | pd_input:C1,power:C1,power:C25,power:C29,power:C4,power:C7,power:C9,power_mon:C1,power_mon:C2,power_som:C14,power_som:C17,power_som:C20,power_som:C25,som_decoupling:C10,som_decoupling:C11,som_decoupling:C12,som_decoupling:C15,som_decoupling:C16,som_decoupling:C17,som_decoupling:C18,som_decoupling:C3,som_decoupling:C4,som_decoupling:C5,som_decoupling:C6,som_decoupling:C9,uart_bridge:C1,uart_bridge:C3,uart_bridge:C4 | Capacitor_SMD:C_0603_1608Metric | C14663
10R | power:R11,power:R13,power_som:R17 | Resistor_SMD:R_0603_1608Metric | C22859
10k | debug_boot:R4,debug_boot:R5,debug_boot:R6,power:R2,power:R5,power_mon:R1,power_som:R12 | Resistor_SMD:R_0603_1608Metric | C25804
10mR | power_mon:RS1,power_mon:RS2,power_mon:RS3 | RLM12FTCMR010:RLM12FTCMR010 | C188070
10u | power_mon:C3,uart_bridge:C2,usb_uart_connector:C1 | Capacitor_SMD:C_0805_2012Metric | C15850
10u | power:C2,power:C3,power_som:C15,power_som:C16 | Capacitor_SMD:C_1206_3216Metric | C13585
10u | pd_input:C2 | Capacitor_SMD:C_1210_3225Metric | C596319
10uH | power:L1,power:L2,power_som:L3 | SWPA8040S100MT:SWPA8040S100MT | C37429
13k | power_som:R15 | Resistor_SMD:R_0603_1608Metric | C22797
1k | power:R12,power:R15,power:R3,power:R7,power_som:R16,power_som:R19,uart_bridge:R1 | Resistor_SMD:R_0603_1608Metric | C21190
1u | power:C12,power:C13,power:C24,power:C28,power:C31,power:C32,power_som:C22,power_som:C23 | Capacitor_SMD:C_0603_1608Metric | C15849
20mR | power_mon:RS4 | RLM12FTCMR020:RLM12FTCMR020 | C393094
22k | power:R10,power:R14,power_som:R18 | Resistor_SMD:R_0603_1608Metric | C31850
22k1 | uart_bridge:R2 | Resistor_SMD:R_0603_1608Metric | C25961
22p | power:C23,power:C27,power_som:C21 | Capacitor_SMD:C_0603_1608Metric | C1653
22u | power:C10,power:C11,power:C26,power:C30,power:C5,power:C6,power:C8,power_som:C18,power_som:C19,som_decoupling:C1,som_decoupling:C13,som_decoupling:C14,som_decoupling:C2,som_decoupling:C7,som_decoupling:C8 | Capacitor_SMD:C_0805_2012Metric | C45783
23.2k | power:R4 | Resistor_SMD:R_0603_1608Metric | C23346
330R | power:R6,power:R9 | Resistor_SMD:R_0603_1608Metric | C23138
40.2k | power:R1 | Resistor_SMD:R_0603_1608Metric | C12447
47.5k | power_som:R14 | Resistor_SMD:R_0603_1608Metric | C23061
47k5 | uart_bridge:R3 | Resistor_SMD:R_0603_1608Metric | C23061
47n | pd_input:C3 | Capacitor_SMD:C_0603_1608Metric | C1622
4k7 | debug_boot:R1,debug_boot:R2,debug_boot:R7,debug_boot:R8 | Resistor_SMD:R_0603_1608Metric | C23162
5.1k | pd_input:R5,usb_uart_connector:R1,usb_uart_connector:R2 | Resistor_SMD:R_0603_1608Metric | C23186
5.49k | pd_input:R4 | Resistor_SMD:R_0603_1608Metric | C188263
878311420 | debug_boot:J1 | 878311420:878311420 | C240854
AO3400A | power:Q1 | Package_TO_SOT_SMD:SOT-23 | C20917
AP2112K-1.8 | power:U3 | Package_TO_SOT_SMD:SOT-23-5 | C176944
CP2102N-A02 | uart_bridge:U1 | CP2102N-A02-GQFN24R:CP2102N-A02-GQFN24R | C969151
DF40C-100DP-0.4V(51) | som_j1:J1,som_j2:J2,som_j3:J3 | DF40C-100DP-0.4V_51:DF40C-100DP-0.4V_51 | C531031
DIP-4 | debug_boot:SW1 | DSHP04TSGER:DSHP04TSGER | C3293144
HX_JN1.27-2x5 | debug_boot:J2 | HX_JN1.27-2x5_TP_H4.9:HX_JN1.27-2x5_TP_H4.9 | C42372555
INA3221AIRGVR | power_mon:U1,power_mon:U2 | INA3221AIRGVR:INA3221AIRGVR | C181255
LM61460AANRJRR | power:U1,power:U2,power_som:U4 | LM61460AANRJRR:LM61460AANRJRR | C2864505
MMSZ5231B | power_som:D5 | Diode_SMD:D_SOD-123 | C85181
RESET | debug_boot:SW2 | TS-1187A-B-A-B:TS-1187A-B-A-B | C318884
SMBJ22A | pd_input:D1 | Diode_SMD:D_SMB | C10214
TPS26631PWPR | pd_input:U1 | TPS26631PWPR:TPS26631PWPR | C2866319
TYPE-C-31-M-12 | pd_input:J1,usb_uart_connector:J1 | TYPE-C-31-M-12:TYPE-C-31-M-12 | C165948
USBLC6-2SC6 | pd_input:U2,usb_uart_connector:U1 | USBLC6-2SC6:USBLC6-2SC6 | C7519
red | power:D1,power:D2,power:D3,power_som:D4 | LED_SMD:LED_0603_1608Metric | C2286

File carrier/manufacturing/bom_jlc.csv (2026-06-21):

Comment | Designator | Footprint | LCSC
1.5R | lcd:R1 | Resistor_SMD:R_0603_1608Metric | C22769
100R | camera:R1,camera:R2,camera:R3,debug_boot:R3 | Resistor_SMD:R_0603_1608Metric | C22775
100k | board_aux:R2,board_aux:R4,bringup_en:R1,bringup_en:R2,bringup_en:R3,bringup_en:R4,bringup_en:R5,bringup_en:R6,bringup_en_modules:R1,bringup_en_modules:R10,bringup_en_modules:R11,bringup_en_modules:R12,bringup_en_modules:R13,bringup_en_modules:R14,bringup_en_modules:R15,bringup_en_modules:R16,bringup_en_modules:R17,bringup_en_modules:R18,bringup_en_modules:R19,bringup_en_modules:R2,bringup_en_modules:R20,bringup_en_modules:R21,bringup_en_modules:R3,bringup_en_modules:R4,bringup_en_modules:R5,bringup_en_modules:R6,bringup_en_modules:R7,bringup_en_modules:R8,bringup_en_modules:R9,bringup_rails:R1,bringup_rails:R2,bringup_rails:R3,lcd:R4,lcd:R5,microsd:R1,microsd:R2,microsd:R3,microsd:R4,microsd:R5,pd_input:R3,pd_input:R6,pmod_expansion:R2,power:R8,usb_jtag:R4,usbc_otg:R3,usbc_otg:R5 | Resistor_SMD:R_0603_1608Metric | C25803
100n | board_aux:C1,board_aux:C2,board_aux:C4,board_aux:C5,board_services:C1,board_services:C2,board_services:C3,bringup_en:C1,bringup_en:C2,bringup_en:C3,bringup_en_modules:C1,bringup_en_modules:C10,bringup_en_modules:C11,bringup_en_modules:C2,bringup_en_modules:C3,bringup_en_modules:C4,bringup_en_modules:C5,bringup_en_modules:C6,bringup_en_modules:C7,bringup_en_modules:C8,bringup_en_modules:C9,bringup_modules:C1,bringup_modules:C10,bringup_modules:C11,bringup_modules:C12,bringup_modules:C13,bringup_modules:C14,bringup_modules:C15,bringup_modules:C16,bringup_modules:C17,bringup_modules:C18,bringup_modules:C19,bringup_modules:C2,bringup_modules:C20,bringup_modules:C3,bringup_modules:C4,bringup_modules:C5,bringup_modules:C6,bringup_modules:C7,bringup_modules:C8,bringup_modules:C9,bringup_rails:C1,bringup_rails:C2,bringup_rails:C3,bringup_rails:C4,camera:C1,fmc:C2,fmc:C5,hdmi_rx:C1,hdmi_rx_term:C1,hdmi_tx:C1,hdmi_tx:C2,hdmi_tx:C3,lcd:C3,microsd:C1,microsd:C2,microsd:C4,motor_pwm:C1,motor_pwm:C2,motor_sense:C1,motor_sense:C2,pd_input:C1,pmod:C1,pmod:C3,pmod_expansion:C1,pmod_expansion:C3,pmod_expansion:C4,power:C1,power:C25,power:C29,power:C4,power:C7,power:C9,power_mon:C1,power_mon:C2,power_som:C14,power_som:C17,power_som:C20,power_som:C25,som_decoupling:C10,som_decoupling:C11,som_decoupling:C12,som_decoupling:C15,som_decoupling:C16,som_decoupling:C17,som_decoupling:C18,som_decoupling:C3,som_decoupling:C4,som_decoupling:C5,som_decoupling:C6,som_decoupling:C9,uart_bridge:C1,uart_brid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 | Capacitor_SMD:C_0603_1608Metric | C14663
100u | usbc_otg:C3 | RVT1C101M0605_100UF_16V:RVT1C101M0605_100UF_16V | C970684
10R | power:R11,power:R13,power_som:R17 | Resistor_SMD:R_0603_1608Metric | C22859
10k | board_services:R1,bringup_modules:R21,bringup_rails:R6,bringup_rails:R7,bringup_rails:R8,bringup_rails:R9,debug_boot:R4,debug_boot:R5,debug_boot:R6,hdmi_rx:R3,hdmi_tx:R1,hdmi_tx:R2,lcd:R6,microsd:R6,motor_pwm:R1,motor_sense:R1,power:R2,power:R5,power_mon:R1,power_som:R12,usb_jtag:R1,usb_jtag:R2,usb_jtag:R3,user_io:R5,user_io:R6,user_io:R7,user_io:R8 | Resistor_SMD:R_0603_1608Metric | C25804
10mR | motor_sense:RS1,power_mon:RS1,power_mon:RS2,power_mon:RS3 | RLM12FTCMR010:RLM12FTCMR010 | C188070
10u | board_aux:C3,camera:C2,fmc:C1,fmc:C4,hdmi_tx:C5,lcd:C1,lcd:C4,motor_pwm:C3,motor_sense:C3,pmod:C2,pmod:C4,pmod_expansion:C2,pmod_expansion:C5,power_mon:C3,uart_bridge:C2,usb_jtag:C2,usb_jtag_connector:C1,usb_pd:C2,usb_uart_connector:C1 | Capacitor_SMD:C_0805_2012Metric | C15850
10u | power:C2,power:C3,power_som:C15,power_som:C16 | Capacitor_SMD:C_1206_3216Metric | C13585
10u | pd_input:C2 | Capacitor_SMD:C_1210_3225Metric | C596319
10uH | lcd:L1 | SWPA4030S100MT:SWPA4030S100MT | C38117
10uH | power:L1,power:L2,power_som:L3 | SWPA8040S100MT:SWPA8040S100MT | C37429
13k | board_aux:R1,bringup_modules:R1,bringup_modules:R13,bringup_modules:R15,bringup_modules:R17,bringup_modules:R3,bringup_modules:R7,motor_pwm:R2,pmod_expansion:R1,power_som:R15 | Resistor_SMD:R_0603_1608Metric | C22797
15k | hdmi_rx:R4 | Resistor_SMD:R_0603_1608Metric | C22809
16p | usb_jtag:C5,usb_jtag:C6 | Capacitor_SMD:C_0603_1608Metric | C162205
1k | board_services:R2,bringup_modules:R12,bringup_modules:R18,bringup_modules:R20,hdmi_rx:R1,power:R12,power:R15,power:R3,power:R7,power_som:R16,power_som:R19,uart_bridge:R1,usbc_otg:R4,user_io:R1 | Resistor_SMD:R_0603_1608Metric | C21190
1n | ethernet:C1,ethernet:C2,ethernet:C3,ethernet:C4,ethernet:C5 | Capacitor_SMD:C_1206_3225Metric | C9196
1u | fmc:C3,hdmi_rx_term:C2,hdmi_tx:C4,lcd:C5,power:C12,power:C13,power:C24,power:C28,power:C31,power:C32,power_som:C22,power_som:C23,usb_jtag:C1 | Capacitor_SMD:C_0603_1608Metric | C15849
2.2u | lcd:C2 | Capacitor_SMD:C_0805_2012Metric | C125847
200R | pmod:R1,pmod:R10,pmod:R11,pmod:R12,pmod:R13,pmod:R14,pmod:R15,pmod:R16,pmod:R2,pmod:R3,pmod:R4,pmod:R5,pmod:R6,pmod:R7,pmod:R8,pmod:R9,user_io:R2,user_io:R3,user_io:R4 | Resistor_SMD:R_0603_1608Metric | C8218
200p | usb_pd:C4,usb_pd:C5 | Capacitor_SMD:C_0603_1608Metric | C113796
20mR | power_mon:RS4 | RLM12FTCMR020:RLM12FTCMR020 | C393094
22R | lcd:R7 | Resistor_SMD:R_0603_1608Metric | C23345
22k | power:R10,power:R14,power_som:R18 | Resistor_SMD:R_0603_1608Metric | C31850
22k1 | uart_bridge:R2 | Resistor_SMD:R_0603_1608Metric | C25961
22p | power:C23,power:C27,power_som:C21 | Capacitor_SMD:C_0603_1608Metric | C1653
22u | microsd:C3,power:C10,power:C11,power:C26,power:C30,power:C5,power:C6,power:C8,power_som:C18,power_som:C19,som_decoupling:C1,som_decoupling:C13,som_decoupling:C14,som_decoupling:C2,som_decoupling:C7,som_decoupling:C8,usbc_otg:C2 | Capacitor_SMD:C_0805_2012Metric | C45783
23.2k | power:R4 | Resistor_SMD:R_0603_1608Metric | C23346
24AA025E48T-I/OT | board_services:U1 | 24AA025E48T-I_OT:24AA025E48T-I_OT | C129895
27k | hdmi_rx:R2 | Resistor_SMD:R_0603_1608Metric | C22967
330R | board_aux:R3,bringup_modules:R10,bringup_modules:R14,bringup_modules:R16,bringup_modules:R2,bringup_modules:R4,bringup_modules:R6,bringup_modules:R8,pmod_expansion:R3,power:R6,power:R9,rj45_connector:R1,rj45_connector:R2 | Resistor_SMD:R_0603_1608Metric | C23138
40.2k | power:R1 | Resistor_SMD:R_0603_1608Metric | C12447
47.5k | power_som:R14 | Resistor_SMD:R_0603_1608Metric | C23061
470uF/35V | motor_sense:C4 | Capacitor_SMD:CP_Elec_10x10.5 | C976030
47k5 | uart_bridge:R3 | Resistor_SMD:R_0603_1608Metric | C23061
47n | pd_input:C3 | Capacitor_SMD:C_0603_1608Metric | C1622
49.9R | hdmi_rx_term:R1,hdmi_rx_term:R2,hdmi_rx_term:R3,hdmi_rx_term:R4,hdmi_rx_term:R5,hdmi_rx_term:R6,hdmi_rx_term:R7,hdmi_rx_term:R8 | Resistor_SMD:R_0603_1608Metric | C114625
4D03WGJ0330T5E | motor_pwm:RN1,motor_pwm:RN2 | 4D03WGJ0330T5E:4D03WGJ0330T5E | C25508
4k7 | board_aux:R5,board_aux:R6,bringup_rails:R4,bringup_rails:R5,camera:R4,camera:R5,debug_boot:R1,debug_boot:R2,lcd:R2,lcd:R3 | Resistor_SMD:R_0603_1608Metric | C23162
5.1k | pd_input:R5,usb_jtag_connector:R1,usb_jtag_connector:R2,usb_uart_connector:R1,usb_uart_connector:R2 | Resistor_SMD:R_0603_1608Metric | C23186
5.49k | pd_input:R4 | Resistor_SMD:R_0603_1608Metric | C188263
56k | usbc_otg:R1,usbc_otg:R2 | Resistor_SMD:R_0603_1608Metric | C23206
6.8k | bringup_modules:R11,bringup_modules:R19,bringup_modules:R5,bringup_modules:R9 | Resistor_SMD:R_0603_1608Metric | C23212
75R | ethernet:R1,ethernet:R2,ethernet:R3,ethernet:R4 | Resistor_SMD:R_0603_1608Metric | C4275
878311420 | debug_boot:J1 | 878311420:878311420 | C240854
8MHz | usb_jtag:Y1 | 1C208000BC0R:1C208000BC0R | C57131
AFC07-S40FCA-00 | lcd:J1 | AFC07-S40FCA-00:AFC07-S40FCA-00 | C262572
AO3400A | power:Q1 | Package_TO_SOT_SMD:SOT-23 | C20917
AP2112K-1.8 | power:U3 | Package_TO_SOT_SMD:SOT-23-5 | C176944
AP2112K-3.3TRG1 | usb_jtag:U4 | AP2112K-3.3TRG1:AP2112K-3.3TRG1 | C51118
CH347T | usb_jtag:U1 | CH347T:CH347T | C5122332
CP2102N-A02 | uart_bridge:U1 | CP2102N-A02-GQFN24R:CP2102N-A02-GQFN24R | C969151
DF40C-100DP-0.4V(51) | som_j1:J1,som_j2:J2,som_j3:J3 | DF40C-100DP-0.4V_51:DF40C-100DP-0.4V_51 | C531031
DIP-4 | debug_boot:SW1 | DSHP04TSGER:DSHP04TSGER | C3293144
DS1024-2x6R2 | pmod:J1,pmod:J2,pmod_expansion:J1 | DS1024-2x6R2:DS1024-2x6R2 | C49284652
DSHP04TSGER | board_aux:SW1,bringup_rails:SW1,bringup_rails:SW6,pmod_expansion:SW1,usb_jtag:SW1 | DSHP04TSGER:DSHP04TSGER | C3293144
DSHP08TSGER | bringup_rails:SW2 | DSHP08TSGER:DSHP08TSGER | C3293147
FUSB302BMPX | usb_pd:U1 | Package_DFN_QFN:WQFN-14-1EP_2.5x2.5mm_P0.5mm_EP1.45x1.45mm | C132291
HDMI-019S | hdmi_rx:J1,hdmi_tx:J1 | HDMI-019S:HDMI-019S | C111617
HX PZ2.54-3x8P ZZ | motor_pwm:J1 | HX_PZ2.54-3x8P_ZZ:HX_PZ2.54-3x8P_ZZ | C32713295
HX5008NLT | ethernet:T1 | HX5008NLT:HX5008NLT | C962544
HX_JN1.27-2x5 | debug_boot:J2 | HX_JN1.27-2x5_TP_H4.9:HX_JN1.27-2x5_TP_H4.9 | C42372555
Header_2x20_2.54mm | fmc:J1 | Connector_PinHeader_2.54mm:PinHeader_2x20_P2.54mm_Vertical
INA3221AIRGVR | motor_sense:U2,power_mon:U1,power_mon:U2 | INA3221AIRGVR:INA3221AIRGVR | C181255
KH-5224-8P8C-D | rj45_connector:J1 | KH-5224-8P8C-D:KH-5224-8P8C-D | C2828085
KH-CR1220-2 | board_services:BT1 | KH-CR1220-2:KH-CR1220-2 | C5365933
LM61460AANRJRR | power:U1,power:U2,power_som:U4 | LM61460AANRJRR:LM61460AANRJRR | C2864505
M24C02-WMN6TP | hdmi_rx:U1 | M24C02-WMN6TP:M24C02-WMN6TP | C7562
MMSZ5231B | power_som:D5 | Diode_SMD:D_SOD-123 | C85181
PCA9306DCUR | board_aux:U2 | PCA9306DCUR:PCA9306DCUR | C33196
RESET | debug_boot:SW2 | TS-1187A-B-A-B:TS-1187A-B-A-B | C318884
RV-3028-C7-32.768kHz-1ppm-TA-QC | board_services:U2 | RV-3028-C7-32.768kHz-1ppm-TA-QC:RV-3028-C7-32.768kHz-1ppm-TA-QC | C3019759
SFW15R-1STE1LF | camera:J1 | SFW15R-1STE1LF:SFW15R-1STE1LF | C3168538
SMBJ22A | pd_input:D1 | Diode_SMD:D_SMB | C10214
SMBJ28A | motor_sense:D1 | SMBJ28A:SMBJ28A | C42440491
SN74HCT245PWR | motor_pwm:U1 | SN74HCT245PWR:SN74HCT245PWR | C6779
SN74LVC125ADR | usb_jtag:U2 | SN74LVC125ADR:SN74LVC125ADR | C7661
SN74LVC1G08 | bringup_en:U1,bringup_en:U2,bringup_en:U3,bringup_en_modules:U1,bringup_en_modules:U10,bringup_en_modules:U11,bringup_en_modules:U2,bringup_en_modules:U3,bringup_en_modules:U4,bringup_en_modules:U5,bringup_en_modules:U6,bringup_en_modules:U7,bringup_en_modules:U8,bringup_en_modules:U9 | Package_TO_SOT_SMD:SOT-23-5 | C7666
SRV05-4 | motor_pwm:D1,motor_pwm:D2 | Package_TO_SOT_SMD:SOT-23-6 | C2836319
SS34 | lcd:D1 | Diode_SMD:D_SMA | C8678
SY6280AAC | board_aux:U1,bringup_modules:U1,bringup_modules:U10,bringup_modules:U2,bringup_modules:U3,bringup_modules:U4,bringup_modules:U5,bringup_modules:U6,bringup_modules:U7,bringup_modules:U8,bringup_modules:U9,motor_pwm:U3,pmod_expansion:U1 | SY6280AAC:SY6280AAC | C55136
SY7201ABC | lcd:U1 | SY7201ABC:SY7201ABC | C82173
TCA9535PWR | bringup_rails:U1 | TCA9535PWR:TCA9535PWR | C130204
TF-01A | microsd:J1 | TF-01A:TF-01A | C91145
TLV75725PDYDR | fmc:U1 | TLV75725PDYDR:TLV75725PDYDR | C35209004
TPD12S016PWR | hdmi_tx:U1 | TPD12S016PWR:TPD12S016PWR | C201665
TPD4E02B04DQAR | camera:U1,camera:U2,hdmi_rx:U2,hdmi_rx:U3 | TPD4E02B04DQAR:TPD4E02B04DQAR | C106794
TPD4E05U06DQAR | hdmi_rx:U4 | TPD4E05U06DQAR:TPD4E05U06DQAR | C138714
TPD4E1U06 | pmod:U1,pmod:U2,pmod:U3,pmod:U4,pmod_expansion:U2,pmod_expansion:U3 | TPD4E1U06DBVR:TPD4E1U06DBVR | C124691
TPD6E001RSER | microsd:U2 | TPD6E001RSER:TPD6E001RSER | C1973318
TPS2051CDBVR | usbc_otg:U1 | TPS2051CDBVR:TPS2051CDBVR | C129581
TPS26631PWPR | pd_input:U1 | TPS26631PWPR:TPS26631PWPR | C2866319
TPS3823-33DBVR | board_services:U3 | TPS3823-33DBVR:TPS3823-33DBVR | C7719
TS-1187A-B-A-B | bringup_rails:SW3,bringup_rails:SW4,bringup_rails:SW5 | TS-1187A-B-A-B:TS-1187A-B-A-B | C318884
TXS02612RTWR | microsd:U1 | TXS02612RTWR:TXS02612RTWR | C140276
TYPE-C-31-M-12 | pd_input:J1,usb_jtag_connector:J1,usb_uart_connector:J1,usbc_otg:J2 | TYPE-C-31-M-12:TYPE-C-31-M-12 | C165948
USBLC6-2SC6 | board_qwiic:U1,lcd:U2,pd_input:U2,usb_jtag_connector:U1,usb_uart_connector:U1,usbc_otg:U2 | USBLC6-2SC6:USBLC6-2SC6 | C7519
USER | user_io:SW1,user_io:SW2,user_io:SW3,user_io:SW4 | TS-1187A-B-A-B:TS-1187A-B-A-B | C318884
XT60PW-M | motor_sense:J2,motor_sense:J3 | XT60PW-M:XT60PW-M | C98732
ZX-SH1.0-4PWT | board_qwiic:J1 | ZX-SH1.0-4PWT:ZX-SH1.0-4PWT | C7430446
blue | user_io:D3 | LED_SMD:LED_0603_1608Metric | C2288
green | user_io:D2 | LED_SMD:LED_0603_1608Metric | C12624
red | board_aux:D1,bringup_modules:D1,bringup_modules:D10,bringup_modules:D2,bringup_modules:D3,bringup_modules:D4,bringup_modules:D5,bringup_modules:D6,bringup_modules:D7,bringup_modules:D8,bringup_modules:D9,pmod_expansion:D1,power:D1,power:D2,power:D3,power_som:D4,user_io:D1 | LED_SMD:LED_0603_1608Metric | C2286
white | user_io:D4 | LED_SMD:LED_0603_1608Metric | C2290

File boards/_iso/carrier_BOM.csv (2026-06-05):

Reference | Qty | Value | Footprint | LCSC | MPN | Description | Datasheet
R103, R104, R203, R303 | 4 | 100k | Resistor_SMD:R_0402_1005Metric | C60491 | RC0402FR-07100KL | 100 kohm 1% 1/16W 0402 (HPD pull-up) | https://datasheet.lcsc.com/lcsc/YAGEO-RC0402FR-07100KL_C60491.pdf
C101, C102, C108, C110, C200, C202, C302 | 7 | 100n | Capacitor_SMD:C_0402_1005Metric | C1525 | CL05B104KO5NNNC | 100nF 16V X7R MLCC 0402 | https://www.lcsc.com/datasheet/lcsc_datasheet_2304140030_Samsung-Electro-Mechanics-CL05B104KO5NNNC_C1525.pdf
C107, C109 | 2 | 10u | Capacitor_SMD:C_0603_1608Metric | C19702 | CL10A106KP8NNNC | 10uF 6.3V X7R MLCC 0603 (VCONN bulk) | https://datasheet.lcsc.com/lcsc/1810181513_Samsung-Electro-Mechanics-CL10A106KP8NNNC_C19702.pdf
R103 | 1 | 1M | Resistor_SMD:R_0402_1005Metric | C25741 | 0402WGF1004TCE | 1 Mohm 1% 1/16W 0402 (shield to GND, high-impedance) | https://datasheet.lcsc.com/lcsc/UNI-ROYAL-Uniroyal-Elec-0402WGF1004TCE_C25741.pdf
R101, R103, R105, R107, R108 | 5 | 1n_2kV | Capacitor_SMD:C_0603_1608Metric | C70133 | GRM188R72E102KW07D | 1nF 250V X7R safety MLCC 0603 (Bob Smith termination) | https://datasheet.lcsc.com/lcsc/GRM188R72E102KW07D_C70133.pdf
C100, C101, C200, C201, C300, C301 | 6 | 1u | Capacitor_SMD:C_0402_1005Metric | C52923 | CL05A105KP5NNNC | 1uF 10V X5R MLCC 0402 | https://datasheet.lcsc.com/lcsc/1810171717_Samsung-Electro-Mechanics-CL05A105KP5NNNC_C52923.pdf
C105, C106 | 2 | 200p | Capacitor_SMD:C_0402_1005Metric | C1546 | 0402CG201J500NT | 200pF 50V C0G MLCC 0402 (USB-PD CC cReceiver) | https://datasheet.lcsc.com/lcsc/FH-Guangdong-Fenghua-AdvanTech-0402CG201J500NT_C1546.pdf
R111, R112, R113 | 3 | 4k7 | Resistor_SMD:R_0402_1005Metric | C25900 | 0402WGF4701TCE | 4.7 kohm 1% 1/16W 0402 (I2C pull-up) | https://datasheet.lcsc.com/lcsc/UNI-ROYAL-Uniroyal-Elec-0402WGF4701TCE_C25900.pdf
R100, R102, R104, R106 | 4 | 75R | Resistor_SMD:R_0603_1608Metric | C22790 | 0603WAF750JT5E | 75 ohm 1% 1/10W 0603 (Bob Smith Ethernet termination) | https://datasheet.lcsc.com/lcsc/UNI-ROYAL-Uniroyal-Elec-0603WAF750JT5E_C22790.pdf
U1 | 1 | FUSB302BMPX | Package_DFN_QFN:WQFN-14-1EP_2.5x2.5mm_P0.5mm_EP1.45x1.45mm | C442699 | FUSB302BMPX | USB Type-C PD controller, I2C, WQFN-14 (2.5x2.5mm) | https://www.onsemi.com/pdf/datasheet/fusb302b-d.pdf
T1 | 1 | HX5008NLT | Package_SO:SOIC-24W_7.5x15.4mm_P1.27mm | C962544 | HX5008NLT | 1000BASE-T 4-port LAN magnetics module, SOIC-24 | https://productfinder.pulseeng.com/files/datasheets/HX5008NL.pdf
J1 | 1 | RJHSE5380 | Connector_RJ:RJ45_Amphenol_RJHSE5380_Horizontal | C464586 | RJHSE5380 | RJ45 8P8C bare shielded jack, integrated LEDs (no magnetics) | https://www.amphenol-cs.com/product-series/rjhse5380.html
U3 | 1 | TLV75718PDBVR | Package_TO_SOT_SMD:SOT-23-5 | C507270 | TLV75718PDBVR | 1.8V 1A LDO SOT-23-5 (VCCO 1.8V bank supply) | https://www.ti.com/lit/ds/symlink/tlv757p.pdf
U2 | 1 | TLV75725PDBVR | Package_TO_SOT_SMD:SOT-23-5 | C2872563 | TLV75725PDBVR | 2.5V 1A LDO SOT-23-5 (VCCO 2.5V bank supply) | https://www.ti.com/lit/ds/symlink/tlv757p.pdf
U1 | 1 | TLV75733PDBVR | Package_TO_SOT_SMD:SOT-23-5 | C485517 | TLV75733PDBVR | 3.3V 1A LDO SOT-23-5 (VCCO 3.3V bank supply, default) | https://www.ti.com/lit/ds/symlink/tlv757p.pdf
J1 | 1 | TYPE-C-31-M-12 | Connector_USB:USB_C_Receptacle_HRO_TYPE-C-31-M-12 | C165948 | TYPE-C-31-M-12 | USB Type-C 16-pin SMD receptacle, USB 2.0 + power | https://datasheet.lcsc.com/lcsc/2304140030_Korean-Hroparts-Elec-TYPE-C-31-M-12_C165948.pdf
U2 | 1 | USBLC6-4SC6 | Package_TO_SOT_SMD:SOT-23-6 | C111212 | USBLC6-4SC6 | USB 2.0 ESD protection 4-line SOT-23-6 (rev 6) | https://www.st.com/resource/en/datasheet/usblc6-4.pdf

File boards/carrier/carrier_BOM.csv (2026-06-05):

Reference | Qty | Value | Footprint | LCSC | MPN | Description | Datasheet
#PWR800 | 1 | +VADJ |  | ? | ?
R100 | 1 | 0R01 | Resistor_SMD:R_2010_5025Metric | C7126 | RL2010FK-070R01L | 10 milliohm 1% 0.5W 2010 current-sense shunt (INA226 R_SENSE for rails up to 8A) | https://datasheet.lcsc.com/lcsc/YAGEO-RL2010FK-070R01L_C7126.pdf
J1 | 1 | 1.0-15P | Connector_FFC-FPC:FFC_15P_1mm | ? | ?
R103, R104, R203, R303 | 4 | 100k | Resistor_SMD:R_0402_1005Metric | C60491 | RC0402FR-07100KL | 100 kohm 1% 1/16W 0402 (HPD pull-up) | https://datasheet.lcsc.com/lcsc/YAGEO-RC0402FR-07100KL_C60491.pdf
C100, C101, C102, C103, C104, C108, C110, C200, C202, C302 | 10 | 100n | Capacitor_SMD:C_0402_1005Metric | C1525 | CL05B104KO5NNNC | 100nF 16V X7R MLCC 0402 | https://www.lcsc.com/datasheet/lcsc_datasheet_2304140030_Samsung-Electro-Mechanics-CL05B104KO5NNNC_C1525.pdf
C102 | 1 | 100u | Capacitor_SMD:C_1206_3216Metric | C15008 | CL31A107MQHNNNE | 100uF 6.3V X5R MLCC 1206 | https://datasheet.lcsc.com/lcsc/1810181513_Samsung-Electro-Mechanics-CL31A107MQHNNNE_C15008.pdf
R100, R101, R102, R103, R104 | 5 | 10k | Resistor_SMD:R_0402_1005Metric | C25744 | 0402WGF1002TCE | 10 kohm 1% 1/16W 0402 (general pull-up) | https://datasheet.lcsc.com/lcsc/UNI-ROYAL-Uniroyal-Elec-0402WGF1002TCE_C25744.pdf
C107, C109 | 2 | 10u | Capacitor_SMD:C_0603_1608Metric | C19702 | CL10A106KP8NNNC | 10uF 6.3V X7R MLCC 0603 (VCONN bulk) | https://datasheet.lcsc.com/lcsc/1810181513_Samsung-Electro-Mechanics-CL10A106KP8NNNC_C19702.pdf
R103 | 1 | 1M | Resistor_SMD:R_0402_1005Metric | C25741 | 0402WGF1004TCE | 1 Mohm 1% 1/16W 0402 (shield to GND, high-impedance) | https://datasheet.lcsc.com/lcsc/UNI-ROYAL-Uniroyal-Elec-0402WGF1004TCE_C25741.pdf
R107 | 1 | 1k | Resistor_SMD:R_0402_1005Metric | C11702 | 0402WGF1001TCE | 1 kohm 1% 1/16W 0402 | https://datasheet.lcsc.com/lcsc/UNI-ROYAL-Uniroyal-Elec-0402WGF1001TCE_C11702.pdf
R101, R103, R105, R107, R108 | 5 | 1n_2kV | Capacitor_SMD:C_0603_1608Metric | C70133 | GRM188R72E102KW07D | 1nF 250V X7R safety MLCC 0603 (Bob Smith termination) | https://datasheet.lcsc.com/lcsc/GRM188R72E102KW07D_C70133.pdf
C100, C101, C200, C201, C300, C301 | 6 | 1u | Capacitor_SMD:C_0402_1005Metric | C52923 | CL05A105KP5NNNC | 1uF 10V X5R MLCC 0402 | https://datasheet.lcsc.com/lcsc/1810171717_Samsung-Electro-Mechanics-CL05A105KP5NNNC_C52923.pdf
C105, C106 | 2 | 200p | Capacitor_SMD:C_0402_1005Metric | C1546 | 0402CG201J500NT | 200pF 50V C0G MLCC 0402 (USB-PD CC cReceiver) | https://datasheet.lcsc.com/lcsc/FH-Guangdong-Fenghua-AdvanTech-0402CG201J500NT_C1546.pdf
R105 | 1 | 22k1 | Resistor_SMD:R_0402_1005Metric | C25768 | 0402WGF2212TCE | 22.1 kohm 1% 1/16W 0402 (CP2102N VBUS sense divider upper) | https://datasheet.lcsc.com/lcsc/UNI-ROYAL-Uniroyal-Elec-0402WGF2212TCE_C25768.pdf
U2 | 1 | 24LC256T-I/SN | Package_SO:SOIC-8_3.9x4.9mm_P1.27mm | C5458 | 24LC256T-I/SN | 256 kbit I2C EEPROM (board ID / EDID), SOIC-8 | https://ww1.microchip.com/downloads/aemDocuments/documents/MPD/ProductDocuments/DataSheets/21203P.pdf
R106 | 1 | 47k5 | Resistor_SMD:R_0402_1005Metric | C25819 | 0402WGF4752TCE | 47.5 kohm 1% 1/16W 0402 (CP2102N VBUS sense divider lower) | https://datasheet.lcsc.com/lcsc/UNI-ROYAL-Uniroyal-Elec-0402WGF4752TCE_C25819.pdf
R102, R103, R104, R111, R112, R113 | 6 | 4k7 | Resistor_SMD:R_0402_1005Metric | C25900 | 0402WGF4701TCE | 4.7 kohm 1% 1/16W 0402 (I2C pull-up) | https://datasheet.lcsc.com/lcsc/UNI-ROYAL-Uniroyal-Elec-0402WGF4701TCE_C25900.pdf
C100, C102 | 2 | 4u7 | Capacitor_SMD:C_0402_1005Metric | C368809 | CL05A475KP5NRNC | 4.7uF 10V X5R MLCC 0402 | https://datasheet.lcsc.com/lcsc/1809181722_Samsung-Electro-Mechanics-CL05A475MP5NSNC_C368809.pdf
R100, R102, R104, R106 | 4 | 75R | Resistor_SMD:R_0603_1608Metric | C22790 | 0603WAF750JT5E | 75 ohm 1% 1/10W 0603 (Bob Smith Ethernet termination) | https://datasheet.lcsc.com/lcsc/UNI-ROYAL-Uniroyal-Elec-0603WAF750JT5E_C22790.pdf
U1 | 1 | CP2102N-A02-GQFN24R | Package_DFN_QFN:QFN-24-1EP_4x4mm_P0.5mm_EP2.6x2.6mm | C969151 | CP2102N-A02-GQFN24R | USB-to-UART bridge, internal oscillator, QFN-24 | https://www.silabs.com/documents/public/data-sheets/cp2102n-datasheet.pdf
J1 | 1 | DM3AT-SF-PEJM5 | Connector_Card:microSD_HiroseDM3AT-SF-PEJM5_Push-Push | C114218 | DM3AT-SF-PEJM5 | microSD push-push socket with card-detect switch | https://www.hirose.com/en/product/document?clcode=CL0540-1284-2-51&productname=DM3AT-SF-PEJM5(51)&series=DM3
SW1 | 1 | DS-04P | Switch_SMD:DIP_Switch_x4 | ? | ?
J5A, J5B | 1 | FPC-05F-40PH20 | Connector_FFC-FPC:FPC-05F-40PH20 | ? | ?
U1 | 1 | FUSB302BMPX | Package_DFN_QFN:WQFN-14-1EP_2.5x2.5mm_P0.5mm_EP1.45x1.45mm | C442699 | FUSB302BMPX | USB Type-C PD controller, I2C, WQFN-14 (2.5x2.5mm) | https://www.onsemi.com/pdf/datasheet/fusb302b-d.pdf
J1A, J2A, J3A, J4A, J1B, J2B, J3B, J4B, J1C, J2C, J3C, J4C | 4 | FX10A-168P-SV(91) | Connector_FFC-FPC:FX10A-168P-SV1 | ? | ?
J1 | 1 | HDMI-019S | Connector_HDMI:HDMI_A_SOFNG_HDMI-019S | C111617 | HDMI-019S | HDMI Type-A receptacle 19-pin SMD right-angle | https://datasheet.lcsc.com/lcsc/SOFNG-HDMI-019S_C111617.pdf
J2 | 1 | HX-PZ1.27-2x5P-TP | Connector_PinHeader_1.27mm:PinHeader_2x05_P1.27mm_Vertical | ? | ?
T1 | 1 | HX5008NLT | Package_SO:SOIC-24W_7.5x15.4mm_P1.27mm | C962544 | HX5008NLT | 1000BASE-T 4-port LAN magnetics module, SOIC-24 | https://productfinder.pulseeng.com/files/datasheets/HX5008NL.pdf
U1 | 1 | INA226AIDGSR | Package_SO:VSSOP-10_3x3mm_P0.5mm | C49851 | INA226AIDGSR | Bidirectional I2C current/power monitor, 36V common-mode | https://www.ti.com/lit/ds/symlink/ina226.pdf
J1, J2 | 2 | PM254R-12-08-H85 | Connector_PinHeader_2.54mm:PinHeader_2x06_P2.54mm_Vertical | C53026548 | PM254R-12-08-H85 | 2x6 0.1in pin header right-angle (Digilent PMOD) | https://datasheet.lcsc.com/lcsc/XFCN-PM254R-12-08-H85_C53026548.pdf
J1 | 1 | RJHSE5380 | Connector_RJ:RJ45_Amphenol_RJHSE5380_Horizontal | C464586 | RJHSE5380 | RJ45 8P8C bare shielded jack, integrated LEDs (no magnetics) | https://www.amphenol-cs.com/product-series/rjhse5380.html
U3 | 1 | TLV75718PDBVR | Package_TO_SOT_SMD:SOT-23-5 | C507270 | TLV75718PDBVR | 1.8V 1A LDO SOT-23-5 (VCCO 1.8V bank supply) | https://www.ti.com/lit/ds/symlink/tlv757p.pdf
U2 | 1 | TLV75725PDBVR | Package_TO_SOT_SMD:SOT-23-5 | C2872563 | TLV75725PDBVR | 2.5V 1A LDO SOT-23-5 (VCCO 2.5V bank supply) | https://www.ti.com/lit/ds/symlink/tlv757p.pdf
U1 | 1 | TLV75733PDBVR | Package_TO_SOT_SMD:SOT-23-5 | C485517 | TLV75733PDBVR | 3.3V 1A LDO SOT-23-5 (VCCO 3.3V bank supply, default) | https://www.ti.com/lit/ds/symlink/tlv757p.pdf
U1 | 1 | TPD12S016PWR | Package_SO:TSSOP-24_4.4x7.8mm_P0.65mm | C201665 | TPD12S016PWR | HDMI companion: I2C level shifter, 12-ch ESD, 5V load switch | https://www.ti.com/lit/ds/symlink/tpd12s016.pdf
U1 | 1 | TPS2051CDBVR | Package_TO_SOT_SMD:SOT-23-5 | C129581 | TPS2051CDBVR | USB load switch 0.5A current-limit, fault flag, SOT-23-5 | https://www.ti.com/lit/ds/symlink/tps2051c.pdf
SW2 | 1 | TS-1002S-06026C | Button_Switch_SMD:SW_SPST_Tactile_6x6mm | ? | ?
J1 | 1 | TYPE-C-31-M-12 | Connector_USB:USB_C_Receptacle_HRO_TYPE-C-31-M-12 | C165948 | TYPE-C-31-M-12 | USB Type-C 16-pin SMD receptacle, USB 2.0 + power | https://datasheet.lcsc.com/lcsc/2304140030_Korean-Hroparts-Elec-TYPE-C-31-M-12_C165948.pdf
U2 | 1 | USBLC6-4SC6 | Package_TO_SOT_SMD:SOT-23-6 | C111212 | USBLC6-4SC6 | USB 2.0 ESD protection 4-line SOT-23-6 (rev 6) | https://www.st.com/resource/en/datasheet/usblc6-4.pdf
J1 | 1 | ZX-PM2.54-2-7PY | Connector_PinHeader_2.54mm:PinHeader_2x07_P2.54mm_Vertical | C7499342 | ZX-PM2.54-2-7PY | 2x7 0.1in pin header (Xilinx JTAG header) | https://datasheet.lcsc.com/lcsc/Megastar-ZX-PM2-54-2-7PY_C7499342.pdf

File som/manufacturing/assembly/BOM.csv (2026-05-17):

Comment | Designator | Footprint | LCSC Part # | Qty | Manufacturer Part | Status
4u7 | C1,C7,C8,C9,C10,C11,C12,C15,C32,C34,C36,C38,C40,C44,C45,C52,C57,C59,C66,C70,C71,C77,C78,C79,C87,C88,C95,C97,C103,C123,C128,C129,C139,C141 | C_0402_1005Metric | C368809 | 34 |  | JLCPCB
100n | C2,C3,C4,C5,C6,C16,C17,C18,C19,C20,C21,C22,C138,C142 | C_0402_1005Metric | C1525 | 14 |  | JLCPCB
470n | C13,C23,C33,C35,C37,C39,C41,C43,C46,C47,C48,C50,C53,C54,C55,C56,C61,C62,C67,C69,C72,C76,C80,C81,C82,C83,C84,C85,C89,C90,C91,C92,C94,C98,C99,C100,C101,C102,C107,C108,C112,C114,C130,C131,C132,C133,C134,C135,C136,C137 | C_0201_0603Metric | C85926 | 50 |  | JLCPCB
100n | C14 | C_0402_1005Metric |  | 1 |  | DNP
47u | C24,C27,C28,C29,C31,C49,C73,C74,C75,C86,C127 | C_0805_2012Metric | C16780 | 11 |  | JLCPCB
22u | C25,C26,C30 | C_0805_2012Metric | C98190 | 3 |  | JLCPCB
100u | C42,C51,C58,C60,C63,C64,C68,C93,C96 | C_1206_3216Metric | C15008 | 9 |  | JLCPCB
10u | C65 | C_0402_1005Metric | C15525 | 1 |  | JLCPCB
47n | C104,C105,C106,C109,C110,C111,C113,C118,C119,C120,C121,C122,C124,C125,C126 | C_0201_0603Metric | C85925 | 15 |  | JLCPCB
LED_Small | D2 | LED_0603_1608Metric | C19273151 | 1 |  | JLCPCB
MountingHole | H1,H2,H3,H4 | MountingHole_2.7mm_M2.5_ISO14580_MOD |  | 4 |  | DNP
DF40C-100DS-0.4V_51 | J1,J2,J3 | HRS_DF40C-100DS-0.4V_51_ | C597931 | 3 | DF40HC(3.0)-100DS-0.4V(51) | JLCPCB
3u3 | L1 | L_0806_2.0x1.6mm | C3002532 | 1 |  | JLCPCB
120R | L2,L3,L4,L6,L7,L8,L9 | L_0402_1005Metric | C275478 | 7 |  | JLCPCB
600@100MHz | L5 | L_0402_1005Metric | C337875 | 1 |  | JLCPCB
NMOS | Q3 | SOT-23 | C8545 | 1 |  | JLCPCB
10k | R1,R5,R6,R13,R15,R39,R40,R41,R42,R43,R44,R74,R75,R76,R77,R86,R87,R88,R89,R90,R92,R93,R94,R97,R100 | R_0402_1005Metric | C25744 | 25 |  | JLCPCB
22R | R2,R20,R21,R22,R49,R51,R52,R53,R54,R55,R56,R57,R58,R59,R60,R61,R62,R63,R64,R65,R66,R67,R68,R69,R70,R71,R72,R73,R95,R96 | R_0402_1005Metric | C25105 | 30 |  | JLCPCB
1k5 | R3,R4,R14 | R_0402_1005Metric | C25867 | 3 |  | JLCPCB
4k7 | R7,R8,R9,R10,R11,R12,R17,R18,R19,R48,R98,R99 | R_0402_1005Metric | C25900 | 12 |  | JLCPCB
2k49 | R16 | R_0402_1005Metric | C25884 | 1 |  | JLCPCB
100k | R23,R27,R28,R29,R30,R31,R32,R35,R36,R78,R79,R80,R81,R82,R83,R84,R85 | R_0402_1005Metric | C60491 | 17 |  | JLCPCB
8k06 | R24 | R_0402_1005Metric | C25923 | 1 |  | JLCPCB
28k7 | R25 | R_0402_1005Metric | C26972 | 1 |  | JLCPCB
200k | R26,R33,R37 | R_0402_1005Metric | C137903 | 3 |  | JLCPCB
44k2 | R34 | R_0402_1005Metric | C25895 | 1 |  | JLCPCB
160k | R38 | R_0402_1005Metric | C25757 | 1 |  | JLCPCB
240R | R45 | R_0402_1005Metric | C25094 | 1 |  | JLCPCB
100R | R46,R47 | R_0201_0603Metric | C270336 | 2 |  | JLCPCB
100R | R50 | R_0402_1005Metric | C25076 | 1 |  | JLCPCB
330 | R91 | R_0402_1005Metric | C25104 | 1 |  | JLCPCB
TestPoint | TP1,TP2,TP3,TP4,TP5,TP6,TP7,TP8,TP9,TP10,TP11,TP12,TP13,TP14,TP15,TP16 | TestPoint_Pad_D0.7mm |  | 16 |  | DNP
MT41K256M16TW-107_P | U1 | BGA96C80P9X16_1400X800X120 | C253882 | 1 |  | JLCPCB
XC7Z020-CLG484 | U2 | CLG484_XIL-L_new | C1519066 | 1 |  | JLCPCB
RTL8211F | U3 | RTL8211F-CG_RTK-L | C187932 | 1 |  | JLCPCB
MPM3834 | U4,U6 | MPM3834 | C6675417 | 2 | MPM3834CGPA-Z | JLCPCB
USB3318 | U5 | QFN-24-1EP_4x4mm_P0.5mm_EP2.6x2.6mm |  | 1 | USB3318C-CP-TR | Consign
IS21ES08G | U7 | BGA153N50P14X14_1150X1300X100 | C499918 | 1 | IS21ES08GA-JCLI-TR | JLCPCB
TPSM82864 | U8 | B0QFN_RDJ | C5219321 | 1 |  | JLCPCB
STM32G431CBUx | U9 | STM32G431CBU6 | C529356 | 1 |  | JLCPCB
MPM3822 | U10 | QFN_2p5x3p5x1p6_MNP | C5799652 | 1 |  | JLCPCB
W25Q128JVS | U11 | WSON-8-1EP_8x6mm_P1.27mm_EP3.4x4.3mm |  | 1 | W25Q128JVPIQ | Consign
TPS7A20 | U13 | TLV707 | C2862740 | 1 |  | JLCPCB
BMI323 | U14 | BMI323_BOS | C5368700 | 1 |  | JLCPCB
ASCO | X1 | Oscillator_SMD_Kyocera_4PIN_2.0x1.6mm |  | 1 | KC2016Z13.0000C1KX00 | Consign
ASE-xxxMHz | X2 | Oscillator_SMD_Kyocera_4PIN_2.0x1.6mm | C669080 | 1 | KC2016Z25.0000C1KX00 | JLCPCB
CMOS_OSC | X3 | Oscillator_SMD_Kyocera_4PIN_2.0x1.6mm |  | 1 | KC2016Z33.0000C15XXK | Consign

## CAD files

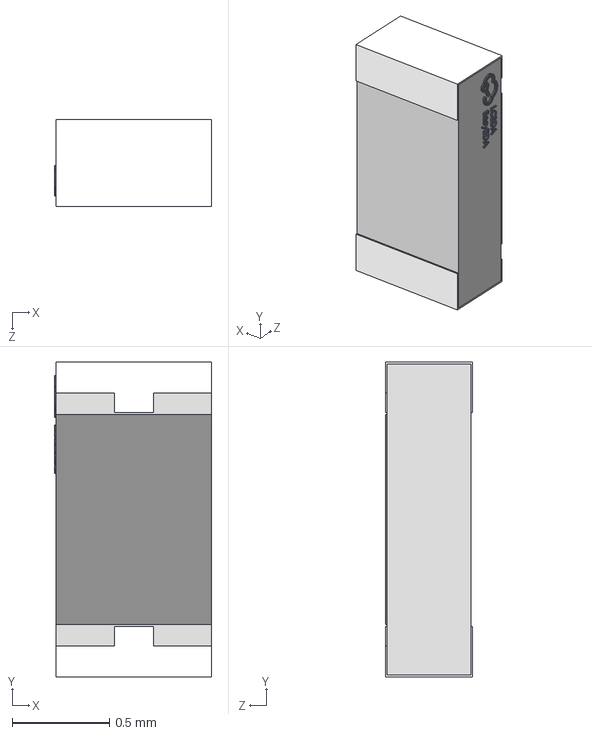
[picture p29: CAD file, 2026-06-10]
parts/0603WAF1001T5E/0603WAF1001T5E.step
0.81 x 1.62 x 0.45 mm

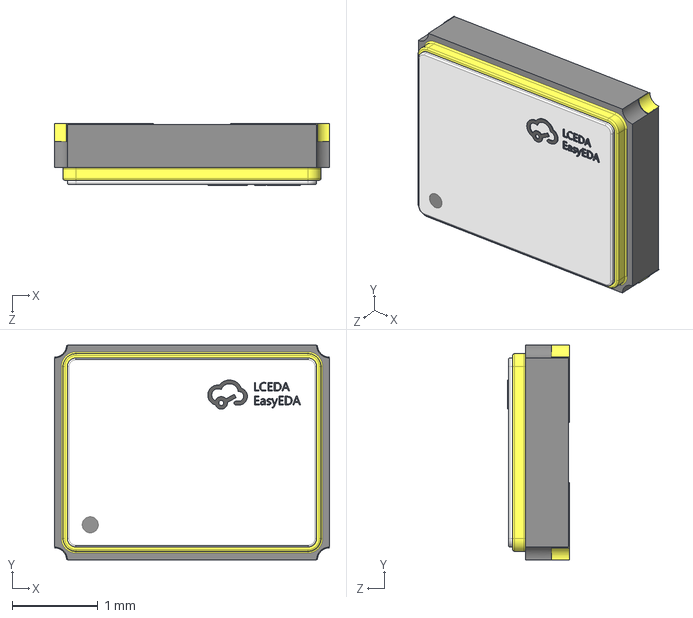
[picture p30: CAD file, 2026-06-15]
parts/1C208000BC0R/1C208000BC0R.step
3.20 x 2.50 x 0.72 mm

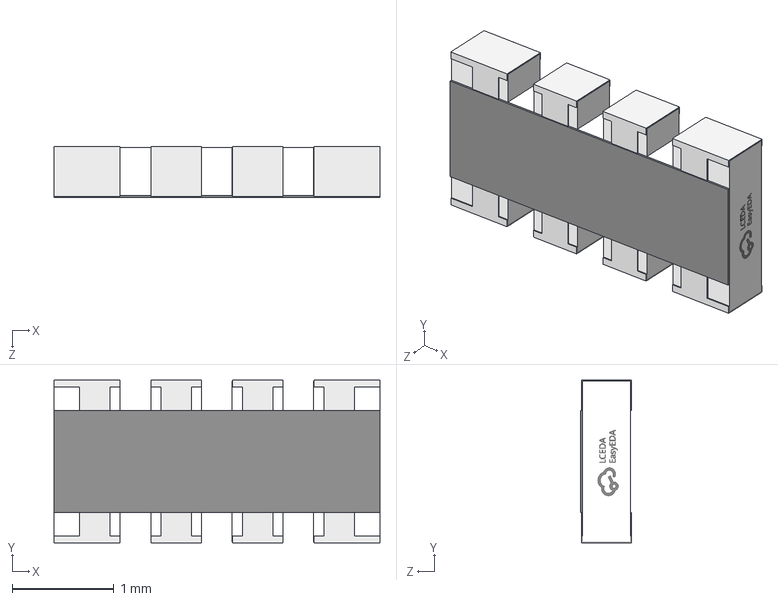
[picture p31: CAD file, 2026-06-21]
parts/4D03WGJ0330T5E/4D03WGJ0330T5E.step
3.20 x 1.60 x 0.5 mm

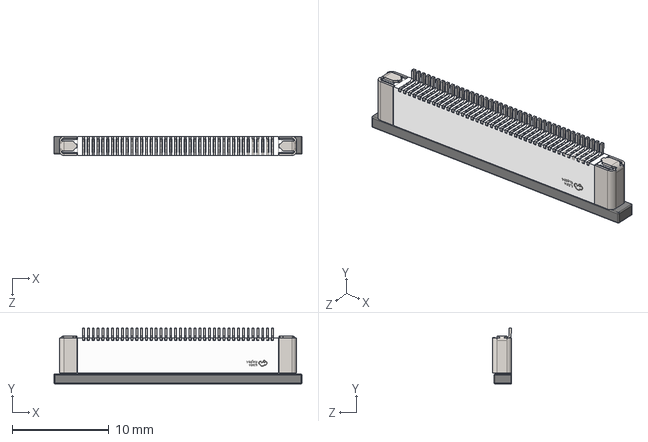
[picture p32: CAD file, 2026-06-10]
parts/AFC07-S40FCA-00/AFC07-S40FCA-00.step
25.6 x 5.75 x 2.01 mm

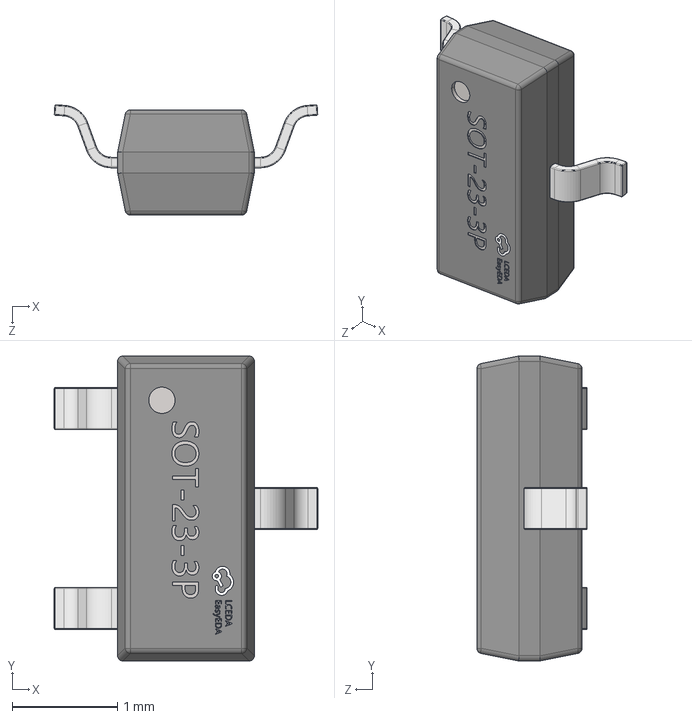
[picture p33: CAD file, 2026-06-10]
parts/AO3400A/AO3400A.step
2.51 x 2.90 x 1.05 mm

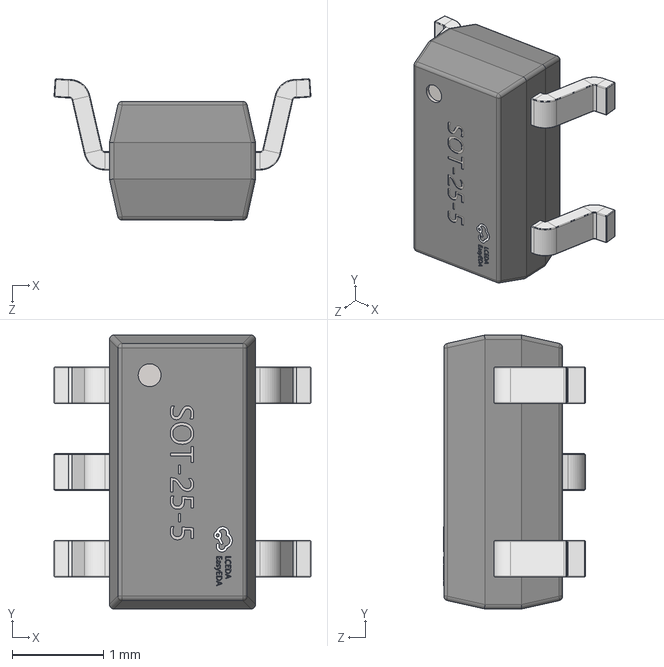
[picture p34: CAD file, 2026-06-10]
parts/AP2112K-1.8TRG1/AP2112K-1.8TRG1.step
2.81 x 3.00 x 1.55 mm

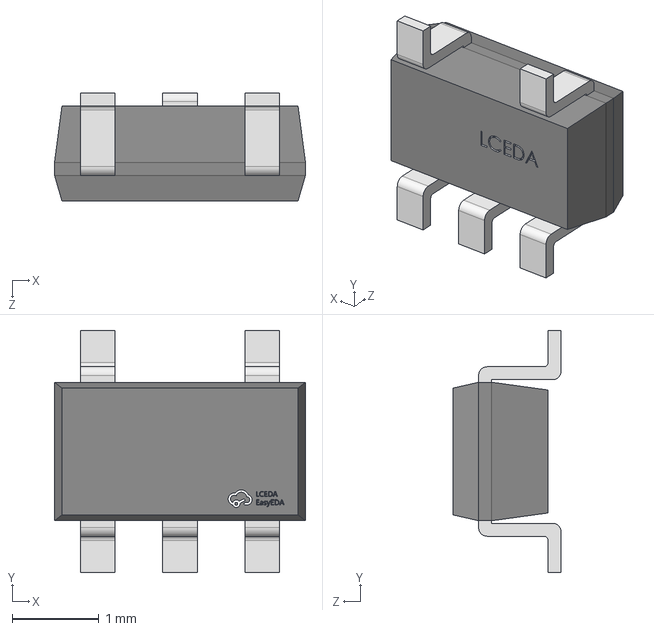
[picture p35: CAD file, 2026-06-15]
parts/AP2112K-3.3TRG1/AP2112K-3.3TRG1.step
2.90 x 2.80 x 1.25 mm

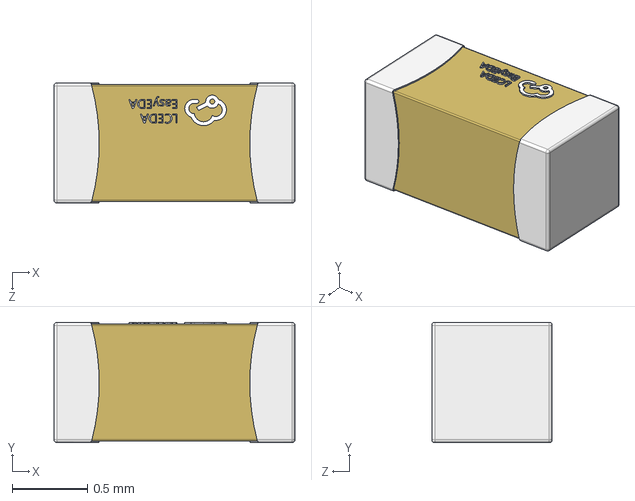
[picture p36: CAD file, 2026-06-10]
parts/CC0603KRX7R9BB104/CC0603KRX7R9BB104.step
1.60 x 0.8 x 0.8 mm

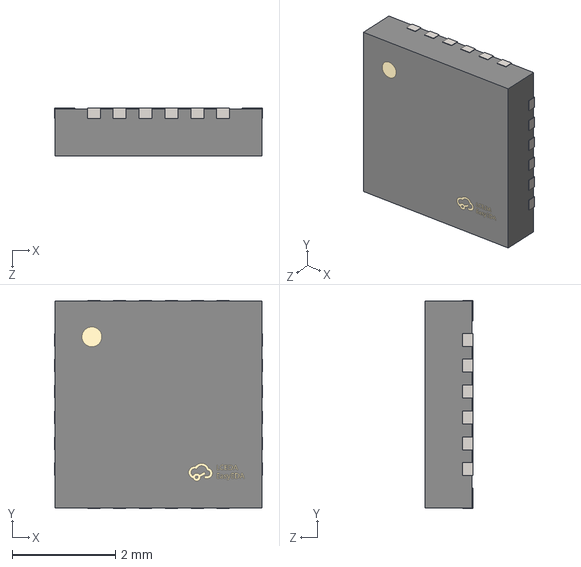
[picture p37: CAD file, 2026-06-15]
parts/CP2102N-A02-GQFN24R/CP2102N-A02-GQFN24R.step
4.02 x 4.02 x 0.92 mm

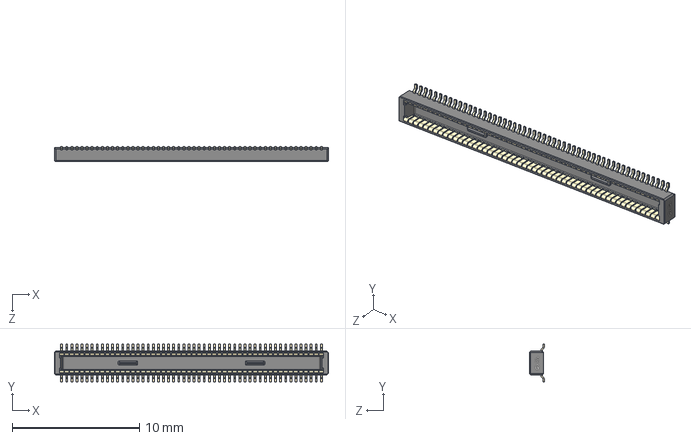
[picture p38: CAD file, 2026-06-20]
parts/DF40C-100DP-0.4V_51/DF40C-100DP-0.4V_51.step
21.5 x 2.97 x 1.14 mm
DF40C-100DP翋极
DF40C-100DP竘褐 x 52

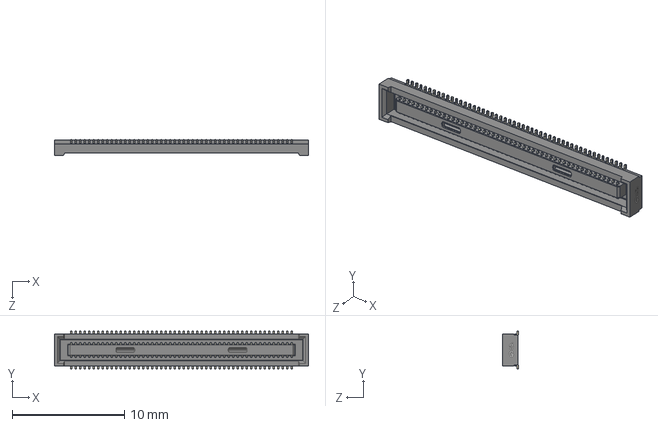
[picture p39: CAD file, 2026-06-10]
parts/DF40C-100DS-0.4V_51/DF40C-100DS-0.4V_51.step
22.6 x 3.38 x 1.45 mm

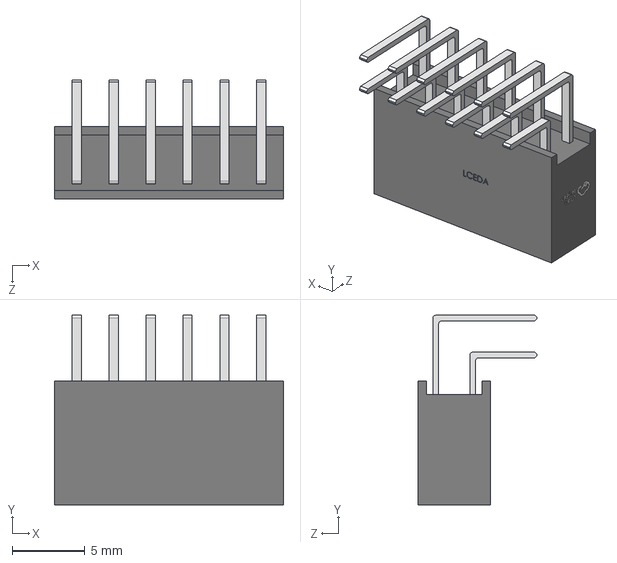
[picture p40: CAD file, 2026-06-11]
parts/DS1024-2x6R2/DS1024-2x6R2.step
15.8 x 13.0 x 8.20 mm

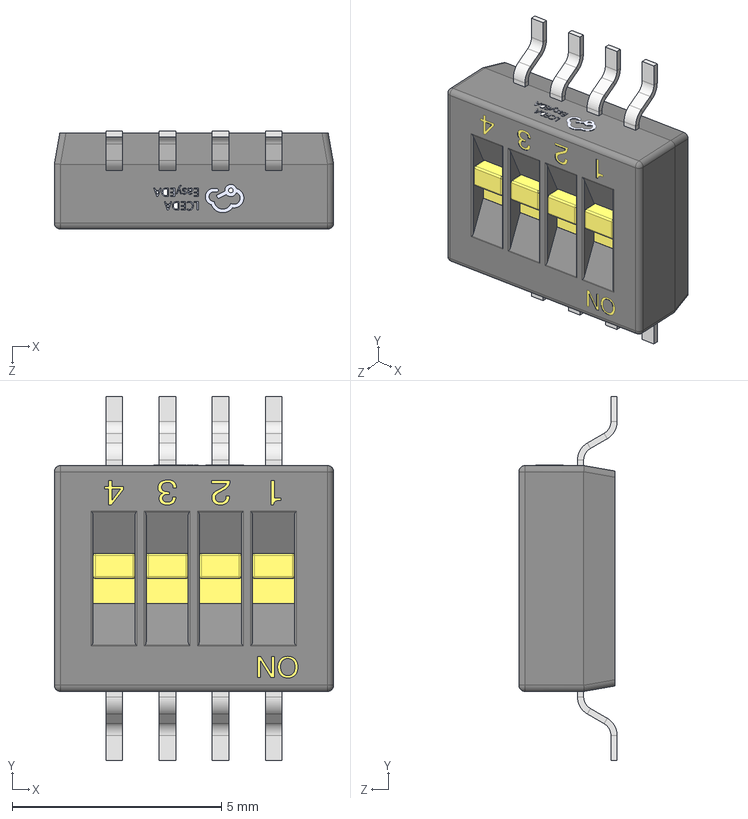
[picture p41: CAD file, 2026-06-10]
parts/DSHP04TSGER/DSHP04TSGER.step
6.68 x 8.70 x 2.35 mm

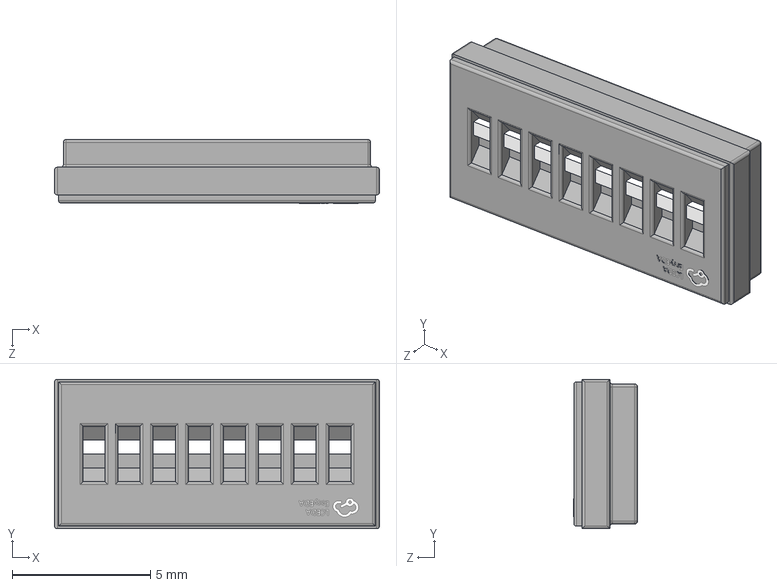
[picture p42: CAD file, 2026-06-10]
parts/DSHP08TSGER/DSHP08TSGER.step
11.7 x 5.40 x 2.31 mm

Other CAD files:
parts/FUSB302BMPX/FUSB302BMPX.step
parts/HDMI-019S/HDMI-019S.step
parts/878311420/878311420.step
parts/HX5008NLT/HX5008NLT.step
parts/HX_JN1.27-2x5_TP_H4.9/HX_JN1.27-2x5_TP_H4.9.step
parts/INA3221AIRGVR/INA3221AIRGVR.step
parts/KH-5224-8P8C-D/KH-5224-8P8C-D.step
parts/KH-CR1220-2/KH-CR1220-2.step
parts/LM61460AANRJRR/LM61460AANRJRR.step
parts/M24C02-WMN6TP/M24C02-WMN6TP.step
parts/PCA9306DCUR/PCA9306DCUR.step
parts/RLM12FTCMR010/RLM12FTCMR010.step
parts/RLM12FTCMR020/RLM12FTCMR020.step
parts/RV-3028-C7-32.768kHz-1ppm-TA-QC/RV-3028-C7-32.768kHz-1ppm-TA-QC.step
parts/RVT1C101M0605_100UF_16V/RVT1C101M0605_100UF_16V.step
parts/SFW15R-1STE1LF/SFW15R-1STE1LF.step
parts/SMBJ28A/SMBJ28A.step
parts/SN74HCT245PWR/SN74HCT245PWR.step
parts/SN74LVC125ADR/SN74LVC125ADR.step
parts/SWPA4030S100MT/SWPA4030S100MT.step
parts/SWPA8040S100MT/SWPA8040S100MT.step
parts/TCA9535PWR/TCA9535PWR.step
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

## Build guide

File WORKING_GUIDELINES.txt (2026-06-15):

================================================================================
 WORKING GUIDELINES — Zynq SoM Carrier + schgen
 The complete set of instructions, rules, restrictions, and process discipline
 the AI assistant operates under for this repository.
 Written 2026-06-12. This is a human-readable contract, not a generated file.
================================================================================

This document exists so that anyone (human or AI) picking up this project knows
EXACTLY the rules the work has been done under. It is verbose on purpose. If any
instruction here ever conflicts with a newer explicit instruction from the repo
owner, the newer explicit instruction wins — but it should then be recorded here
and in the archived decision log (carrier/HISTORY.md, formerly carrier/PLAN.md).

--------------------------------------------------------------------------------
0. WHAT THIS PROJECT IS
--------------------------------------------------------------------------------
Three things live at the top level, deliberately separated:

  som/      The Zynq-7000 System-on-Module. HAND-AUTHORED KiCad project. It is
            the upstream SOURCE OF TRUTH: the carrier extracts its J1/J2/J3
            mezzanine contract and its FPGA pin/ball map LIVE from this project
            (never hand-copied). Edits here ripple downstream; the dependency
            runs one way only.

  carrier/  The carrier board. Its schematics are GENERATED, never hand-drawn.
            carrier/subsystems/*.py are the only hand-written design files (pure
            netlists). Everything else under carrier/ (schematic/, renders/,
            reports/, manufacturing/, fpga/, firmware/, docs/, the .kicad_pro)
            is generated by the tool and committed for review.

  schgen/   The schematic generator and the entire toolchain (model, place,
            route, emit, gates, board assembler, and the system-output
            generators: BOM, XDC, firmware header, bring-up manual, gallery,
            floorplan, selftest, power-tree / test-point / SPICE gates).

  parts/    The component library: ONE folder per physical part, named by
            manufacturer part number (MPN), everything in it generated from LCSC.

The origin story (THE RESET): the previous generator was abandoned by owner
decree — "everything can be reworked, no backwards compatibility." The goal of
the rebuild: model one active component plus all its passives as a .py file and
have a KiCad schematic generated that is (a) ELECTRICALLY correct — proven by
KiCad's own extracted netlist equalling the declared netlist, not merely "0 ERC
errors" (the old AI cheated that) — and (b) VISUALLY correct, as if a human
engineer drew it.

--------------------------------------------------------------------------------
1. THE IMMUTABLE LAWS (highest authority, never weakened)
--------------------------------------------------------------------------------
These were established by the owner and are stored in the assistant's persistent
memory. They outrank convenience, speed, and token cost.

LAW 0 — ELECTRICAL INTEGRITY OUTRANKS EVERYTHING.
  The netlist is sacred. A render that shorts or opens nets is WORSE than
  useless, no matter how clean it looks. A junction is legal ONLY where the SAME
  net merges; a junction at the crossing of two DIFFERENT nets is a short, and
  ERC=0 / overlap=0 do NOT catch it. The netlist must be proven (KiCad's own
  extraction == the declared netlist, pin for pin) BEFORE any visual claim is
  made. Text/label changes must never move a wire or a junction.

LAW 1 — VISUAL CORRECTNESS IS THE ONLY JUDGE.
  The rendered PNG is the supreme and only arbiter. ZERO overlap of anything: no
  wire over a wire, no label over a label or over pin/value/reference text, no
  symbol over a symbol. NO wire crossings at all — never "resolved" by a junction
  dot (that is a short risk, LAW 0). Validator "overlap=0" / "ERC=0" are
  NECESSARY BUT NOT SUFFICIENT. Every render is opened and inspected like a human
  PCB engineer would. If two things touch in the render, it is wrong.

LAW 2 — NEVER STOP UNTIL IT IS ACTUALLY, VERIFIABLY DONE.
  Execute continuously to the done-bar. No premature stopping, no asking for
  permission to continue obvious next steps. "Done" means every targeted sheet is
  hand-drawn-clean in the render AND every gate is green. Stopping early with work
  left undone is the failure mode to avoid.

LAW 3 — FOCUS (historical, from the early phase).
  Originally: drive the most complex sheets (ethernet, usb_pd, power) to 100%
  before the rest. Now satisfied — the entire board is built — but the principle
  stands: finish a thing to perfection before spreading attention.

LAW 4 — NEVER SOFTEN A VALIDATOR.
  Gates stay strict. If a route/label/placement fails, place or route it better,
  or widen the candidate set — never suppress, exempt, or relax a rule to make it
  pass. STRENGTHENING a gate to catch more is encouraged and is "the work";
  loosening one is forbidden. When a strengthened gate exposes an existing
  defect, fix the defect, do not weaken the gate.

--------------------------------------------------------------------------------
2. OWNER STANDING DIRECTIVES (explicit, repeated instructions)
--------------------------------------------------------------------------------
- FULL AUTONOMY, NO QUESTIONS (granted 2026-06-12). Decide and solve everything
  independently based on the deep context already established. When choosing
  between options, take the best one (historically the assistant's recommended
  option has matched the owner's choice every time). Record each non-trivial
  decision in the decision log (carrier/HISTORY.md, the archived carrier/PLAN.md)
  tagged "(autonomous, per full-autonomy directive)" with its rationale, so it
  can be audited after the fact.

- COMMIT AND PUSH AFTER EVERY VERIFIED STEP. After each unit of work whose gates
  are green and whose render has been eyeballed: commit and push to origin
  immediately. Never batch many milestones unpushed (a power-loss lesson). The
  branch in use is the active feature branch (currently holistic-placement-
  rebuild); the default/main branch is master.

- NO CI, EVER — BUT EVERY GENERATION MUST PASS ALL GATES. There is no CI service.
  Instead, every local `schgen build` / `schgen board` enforces ALL gates and
  exits non-zero on any failure. The gates are the safety net; they run locally,
  every time.

- RESEARCH EVERY PART AND SUBSYSTEM INDEPENDENTLY. Do not blindly copy a previous
  design. Read datasheets. Every part must be available on LCSC/JLCPCB so the
  board can be manufactured quickly (the owner does the PCB layout). Prefer JLC
  "Basic" parts; record the LCSC C-number; verify stock live (ghosts exist — a
  C-number from memory has been wrong before, so each is checked against the live
  JLC API for value + package before use).

- EVERYTHING PROGRAMMATICALLY GENERATED. No hand-assembled implementations, no
  hand-copied pinouts. Pin maps and contracts are extracted from source projects
  by the tool. "Nothing legacy must be kept."

- VISUALLY CHECK EVERY GENERATED SCHEMATIC. The assistant opens and reviews every
  render PNG itself; the render is the deliverable.

- TOKEN-WINDOW AWARENESS. The owner is on a time-boxed token plan. Do not over-
  parallelise: too many concurrent threads have, in the past, all stalled at once
  and made zero progress. The ceiling is ~3 disjoint agents at a time.

--------------------------------------------------------------------------------
3. ARCHITECTURAL RULES (how the generator must be built)
--------------------------------------------------------------------------------
- NETLIST-FIRST, CORRECT BY CONSTRUCTION. The .py Circuit IS the spec. Geometry
  is DERIVED from netlist topology by the engine — it is never authored by hand.

- NO MANUAL PLACEMENT (owner-caught violation, now a hard gate). A subsystem .py
  contains the NETLIST plus, at most, declarative hints (e.g. c.hint(net,
  "trunk")) — NEVER coordinates, wire plans, or text positions. A PURITY GATE
  AST-scans every subsystem before executing it and FAILS the build if it defines
  a `placer` or imports any geometry API. All placement patterns (signal-flow
  chains, trunk buses, regulator stages, connector fans, divider stacks, probe
  rows, etc.) are derived generically by schgen/place.py from circuit topology.

- EXCLUSIVE-OWNERSHIP ROUTER. A grid cell belongs to at most one net, ever — so
  shorts and crossings are STRUCTURALLY impossible, not merely checked-for. Pins
  land exactly on the 1.27 mm grid; there is exactly one coordinate transform; no
  epsilon fudging anywhere.

- LIBRARY-FIRST AUTHORING ("authoring v2"). Active parts come from parts/<MPN>/
  via c.use_part("MPN", ref="U1"); lib_id / footprint / LCSC / pin table all come
  from the part folder. Pins connect BY NAME (e.g. "U1.SDA"), validated against
  the part's pin table (bare-number connector pins may stay numeric). A missing
  passive folder is a build error that prints the exact `schgen part add C…` fix.
  use_part(lib_id=…, footprint=…) is the explicit-override form for the few parts
  that deliberately draw a different symbol than their folder's.

- DETERMINISTIC OUTPUT. Every emitted UUID is content-derived; building twice
  produces byte-identical files. Generated outputs are committed; a regen must
  produce zero git diff. Generated files carry DO-NOT-EDIT provenance headers.

- SINGLE SOURCE OF TRUTH, GENERATED EVERYTHING DOWNSTREAM. The board project,
  renders, reports, BOM, FPGA .xdc, firmware contract header, bring-up manual,
  README gallery, and floorplan are all PROJECTIONS of the same gated netlists,
  so they cannot drift from each other or from the schematic.

--------------------------------------------------------------------------------
4. THE GATES (the immutable judges — never edited to pass)
--------------------------------------------------------------------------------
Run on every build; non-zero exit on any failure:

  PURITY            subsystem source is netlist-only (no placer / geometry).
  MODEL COMPLETENESS every pin is netted or explicitly c.nc()'d; inputs driven.
  NETLIST           KiCad's extracted netlist == the declared netlist, pin for
                    pin (catches shorts, opens, single-pin nets, NC-cheats,
                    name drift). This is the unfakeable electrical proof.
  ERC               kicad-cli ERC, zero errors.
  VISUAL            zero overlap, zero crossings, fits the page — no exemptions.
  BOARD GATE        every linked net merges correctly across sheets in the
                    assembled hierarchy.
  LINK              typed-port contract: diff pairs, I2C, sd_bus levels, every
                    cross-sheet expect= deferral resolved (target: 0 unresolved).
  POWER-TREE        per-regulator current headroom proven from declared draws;
                    fails on overrun; emits a numbered power-tree diagram.
  TEST-POINT        every rail and key bus has a probe point or an explicit
                    waiver.
  SPICE / ANALYTIC  dividers, RC ramps, feedback setpoints, ISET, BOOT0 VIH —
                    closed-form gate plus an ngspice cross-check when available.
  SELFTEST          gate MUTATION testing: injected pin-swaps, dropped wires, net
                    aliases, stray NCs, junction shorts, and geometry defects
                    must ALL be caught by the gate stack; plus a build-twice
                    byte-determinism check. This is the "who watches the
                    watchmen" answer in lieu of CI.

--------------------------------------------------------------------------------
5. DESIGN DECISIONS LOCKED (summary; full detail in carrier/HISTORY.md)
--------------------------------------------------------------------------------
- Power input: USB-C PD only, 20 V / 3 A, via FUSB302, behind a TPS26631 eFuse
  with soft-start (controlled inrush, OVP/OCP at the inlet). No barrel jack.
- P0 (critical, fixed): the SoM is a 4.2–5 V module; it must NEVER see the 20 V
  rail. An ALWAYS-ON +5V_SOM buck feeds the SoM's J1 VIN pins (always-on because
  PD negotiation is circular — the system controller must boot first).
- Carrier rails: +5V, +3V3, +1V8; gated per-module rails (+5V_USB, +3V3_SD, the
  HDMI/LCD/CAM/PMOD/USER_LED rails) sourced by bring-up load switches.
- Bring-up architecture: DIP switches AND STM32 override into every regulator and
  module enable; per-rail power-good LEDs; staged power-on.
- Subsystems on the board: USB-PD, USB-C OTG, UART bridge, Ethernet (Bob-Smith,
  2 kV barrier caps), HDMI TX + RX, 40-pin TTL LCD + backlight boost, microSD
  (with mandatory 1.8 V<->3.3 V level translator), RPi camera (CSI), PMOD x2,
  user IO, power monitor (INA3221), debug/boot (JTAG + SWD + boot DIP), FMC LPC,
  power tree, bring-up, and the J1/J2/J3 connector sheets.
- Stackup: JLCPCB 4-layer JLC04161H-7628; impedance geometry drives the exported
  layout constraints.
- The owner does the PCB layout. The floorplan kit is a SUGGESTION, not a
  constraint.

--------------------------------------------------------------------------------
6. PROCESS / WORKFLOW DISCIPLINE (how multi-agent work is run)
--------------------------------------------------------------------------------
- ISOLATED WORKTREES. Heavy or parallel work runs in isolated git worktrees so it
  cannot disturb the main checkout.

- COMMIT PER UNIT / PER GROUP. Each agent commits after every verified unit, so a
  stall or kill (which has happened) can never wipe more than the in-flight step.
  An agent that bundles too much into one un-committed run risks losing
  everything — this has happened and is explicitly designed against.

- AT MOST ~3 DISJOINT AGENTS AT ONCE. They must touch non-overlapping files. At
  most ONE pusher per wave; the others commit locally and are harvested. This
  ceiling exists because larger fan-outs have stalled the entire fleet on the
  token window.

- HARVEST PATTERN. When an agent finishes: cherry-pick its SOURCE changes onto the
  current origin tip, then REGENERATE all artifacts fresh on the merged state
  (deterministic, so this avoids artifact merge conflicts), re-run the full gate
  stack + selftest, eyeball any changed render, then commit and push.

- STALL WATCHERS. Long agents are monitored; a transcript idle beyond a threshold
  is treated as a stall and the work is recovered from its worktree or relaunched
  (smaller-scoped) rather than waited on indefinitely.

- READ-ONLY RECON vs FIX AGENTS. Audits run first as read-only reconnaissance that
  returns VERIFIED findings (each reproduced, not speculative); fixes are then
  applied by separate agents, each finding re-verified, every fix behind the full
  gate stack.

- DECISIONS ARE RECORDED. Every meaningful decision goes into the decision log
  (carrier/HISTORY.md, the archived carrier/PLAN.md) with rationale; cross-session
  state and the rules go into the assistant's persistent memory.

--------------------------------------------------------------------------------
7. GENERAL SAFETY / CONDUCT RESTRICTIONS (always in force)
--------------------------------------------------------------------------------
- Report outcomes FAITHFULLY. If a gate fails, say so with the output. If a step
  was skipped, say that. State "done and verified" only when it actually is.
  Honesty about state is non-negotiable, even under pressure to show progress.

- NO SILENT SOFTENING OR FAKING. Never make something appear to work that does
  not (this is the exact sin of the abandoned old generator). A WIP commit that
  honestly quotes the error it is blocked on is preferred over a green-looking
  lie.

- HARD-TO-REVERSE OR OUTWARD-FACING ACTIONS get confirmed unless already durably
  authorized for this project. Pushing to the owner's own branch and committing
  are pre-authorized here; anything that publishes outside this repo, deletes
  owner-created content, or is otherwise hard to undo is treated with care and
  surfaced rather than assumed.

- SECURITY POSTURE: defensive / authorized work only. This is a hardware design
  repo; the assistant assists with the design, tooling, and documentation, and
  does not produce anything outside that scope.

- DON'T DESTROY WHAT YOU DIDN'T CREATE without looking. Before deleting or
  overwriting, inspect the target; if it contradicts how it was described, or was
  not assistant-created, surface it instead of proceeding. (A LICENSE file was
  once nearly lost to a bulk delete and had to be restored — hence this rule.)

--------------------------------------------------------------------------------
8. QUICK REFERENCE — KEY FILES
--------------------------------------------------------------------------------
  carrier/HISTORY.md .............. the archived decision log (was carrier/PLAN.md
                                    + OVERNIGHT_PLAN.md + MORNING_REPORT.md) —
                                    read it for the WHY behind the design
  schgen/DESIGN.md ................ the engine architecture contract
  README.md / carrier/README.md ... how to generate; the layer READMEs
  parts/README.md ................. how to add a part from LCSC
  subsystems/README.md ............ the reusable subsystem-library index
  subsystems/<name>/README.md ..... a reusable subsystem's abstract interface
  carrier/subsystems/README.md .... how to author/adapt a subsystem (the META
                                    adapter -> reusable library contract)
  carrier/research/*.md ........... per-subsystem engineering dossiers
  WORKING_GUIDELINES.txt .......... this file

  Generate one sheet:   PYTHONPATH=. python -m schgen build <name>
  Generate everything:  PYTHONPATH=. python -m schgen board
  Audit the gates:      PYTHONPATH=. python -m schgen selftest

================================================================================
 End of WORKING_GUIDELINES.txt
================================================================================

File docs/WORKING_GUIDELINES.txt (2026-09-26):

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

This document exists so that anyone (human or AI) picking up this project knows
EXACTLY the rules the work has been done under. It is verbose on purpose. If any
instruction here ever conflicts with a newer explicit instruction from the repo
owner, the newer explicit instruction wins — but it should then be recorded here
and in the archived decision log (HISTORY.md, formerly carrier/PLAN.md).

CURRENT OWNER AMENDMENTS (2026-09 migration):
  - Replace all repository Python tooling, generators, tests and runtime
    dependencies with C++; retain required hardware/design formats, HDL,
    XDC/Tcl and generated firmware. Historical .py authoring references below
    describe the old implementation, not permission to retain it indefinitely.
  - Work on the existing perf-native migration branch; commit proven changes
    in reasonably large coherent batches. Preserve unrelated uncommitted work.
  - At most FIVE active subagents going forward (supersedes the historical
    three-agent ceiling). Existing idle agents need not be closed.
  - Electrical, visual and source-policy gates remain mandatory; never claim
    completion from a partial test run or remove reference coverage unproven.
  - The no-hosted-CI directive remains in force. CMake/CTest aggregation is local.

--------------------------------------------------------------------------------
0. WHAT THIS PROJECT IS
--------------------------------------------------------------------------------
Three things live at the top level, deliberately separated:

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

--------------------------------------------------------------------------------
2. OWNER STANDING DIRECTIVES (explicit, repeated instructions)
--------------------------------------------------------------------------------
- FULL AUTONOMY, NO QUESTIONS (granted 2026-06-12). Decide and solve everything
  independently based on the deep context already established. When choosing
  between options, take the best one (historically the assistant's recommended
  option has matched the owner's choice every time). Record each non-trivial
  decision in the decision log (HISTORY.md, the archived carrier/PLAN.md)
  tagged "(autonomous, per full-autonomy directive)" with its rationale, so it
  can be audited after the fact.

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

--------------------------------------------------------------------------------
5. DESIGN DECISIONS LOCKED (summary; full detail in HISTORY.md)
--------------------------------------------------------------------------------
- Power input: USB-C PD only, 20 V / 3 A, via FUSB302, behind a TPS26631 eFuse
  with soft-start (controlled inrush, OVP/OCP at the inlet). No barrel jack.
- P0 (critical, fixed): the SoM is a 4.2–5 V module; it must NEVER see the 20 V
  rail. An ALWAYS-ON +5V_SOM buck feeds the SoM's J1 VIN pins (always-on because
  PD negotiation is circular — the system controller must boot first).
- Carrier rails: +5V, +3V3, +1V8; gated per-module rails (+5V_USB, +3V3_SD, the
  HDMI/LCD/CAM/PMOD/USER_LED rails) sourced by bring-up load switches.
- Bring-up architecture: DIP switches AND STM32 override into every regulator and
  module enable; per-rail power-good LEDs; staged power-on.
- Subsystems on the board: USB-PD, USB-C OTG, UART bridge, Ethernet (Bob-Smith,
  2 kV barrier caps), HDMI TX + RX, 40-pin TTL LCD + backlight boost, microSD
  (with mandatory 1.8 V<->3.3 V level translator), RPi camera (CSI), PMOD x2,
  user IO, power monitor (INA3221), debug/boot (JTAG + SWD + boot DIP), FMC LPC,
  power tree, bring-up, and the J1/J2/J3 connector sheets.
- Stackup: JLCPCB 4-layer JLC04161H-7628; impedance geometry drives the exported
  layout constraints.
- The owner does the PCB layout. The floorplan kit is a SUGGESTION, not a
  constraint.

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

- DECISIONS ARE RECORDED. Every meaningful decision goes into the decision log
  (HISTORY.md, the archived carrier/PLAN.md) with rationale; cross-session
  state and the rules go into the assistant's persistent memory.

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

--------------------------------------------------------------------------------
8. QUICK REFERENCE — KEY FILES
--------------------------------------------------------------------------------
  HISTORY.md .............. the archived decision log (was carrier/PLAN.md
                                    + OVERNIGHT_PLAN.md + MORNING_REPORT.md) —
                                    read it for the WHY behind the design
  schgen/DESIGN.md ................ the engine architecture contract
  README.md / carrier/README.md ... how to generate; the layer READMEs
  parts/README.md ................. how to add a part from LCSC
  subsystems/README.md ............ the reusable subsystem-library index
  subsystems/<name>/README.md ..... a reusable subsystem's abstract interface
  carrier/subsystems/README.md .... how to author/adapt a subsystem (the META
                                    adapter -> reusable library contract)
  carrier/research/*.md ........... per-subsystem engineering dossiers
  WORKING_GUIDELINES.txt .......... this file

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

================================================================================
 End of WORKING_GUIDELINES.txt
================================================================================

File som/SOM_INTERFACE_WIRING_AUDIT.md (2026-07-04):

# SOM Interface & Wiring Audit

> **Run:** 65-agent adversarial interface-by-interface verification (`.som_interfaces.js`), 2.58 M tokens — every Zynq↔peripheral bus traced at the pin / bit-order / direction / protocol level vs UG585 + device datasheets.
>
> **Orchestrator reconciliation (checked vs netlist + prior passes — read this first):**
> - ✅ **All high-speed data buses CLEAN** (verified): DDR addr/cmd/ctrl/clk, QSPI bit-order, eMMC 4-bit, RGMII (no swaps, delay self-consistent), ULPI (data order + CLK direction), BMI323 SPI, Zynq↔STM32 I2C, JTAG TAP, clocks/reset domains. This is the main result — the wiring of the chip-to-peripheral interfaces is sound.
> - ✅ **BOOT_MODE[2]/[0] no fixed POR strap → HIGH, CONFIRMED & VALID.** `R1`/`R6` are 10k *series* to STM32 PA7/PB2 with no rail pull; `PS_POR_B` is pulled to +3V3 by `R100`, releasing independent of the STM32 → cold-boot the BootROM can sample floating MIO4/MIO5. Fix: add ~20k strap (MIO4↓, MIO5↑) keeping R1/R6 series for STM32 override. **This supersedes Pass-3's INFO rating.**
> - ⚠️ **DONE no pull-up → real, MEDIUM (corrects Pass-1).** `ZYNQ_PL_DONE` has no pull-up (only Q3 gate/TP3/U2.T12); UG585 Table 6-21 requires an external pull-up to VCCO_0. The Q3 DONE-indicator can't pull high without it. Pass-1's "internal pull-up makes it fine" was optimistic. Fix: add pull-up to +3V3.
> - ❌ **PS_SRST_B 3.3V→1.8V "overdrive" (claimed HIGH) — DISMISSED.** The schematic carries an explicit **DESIGN NOTE: "configure …ZYNQ_PS_SRST… as open drain"** — so 3.3V open-drain + R94 1.8V pull-up is correct by design. Firmware-conformance only (matches Pass-2's ruling). Not a hardware defect.
> - ❌ **eMMC DAT4-7 floating (claimed MEDIUM) — reconciled DOWN.** 4-bit is the correct max for Zynq PS SDIO; DAT4-7 NC is right (Pass-2 already settled this). At most LOW.
>
> Net new actionable from this pass: **1 HIGH (boot-strap determinism)** + **1 MEDIUM (DONE pull-up)**. Everything else either confirms a bus is clean or was already covered. Full agent report below.

# SOM Interface & Wiring Audit

## Executive summary

Interface-level verification (every chip↔peripheral pin/bit/direction/protocol-level traced end-to-end against UG585 v1.7, the device datasheets, and the emitted netlist `/tmp/som_netlist.net`) **did find new wiring defects beyond the two known board-dead DDR CRITICALs**, but all of them are in the **boot/config/reset/strap supervision domain**, not in the high-speed data paths. The bulk-data interfaces are clean.

Counts by severity (NEW, beyond the prior-audit knowns):

| Severity | Count | Items |
|---|---|---|
| CRITICAL | 0 | — |
| HIGH | 3 | PS_SRST_B 3.3V-into-1.8V overdrive; PL DONE has no pull-up; BOOT_MODE[2]/[0] have no fixed POR strap (boot-device undefined at cold POR) |
| MEDIUM | 2 | (same boot-strap root cause, restated from the boot-determinism angle); eMMC DAT4–7 + DS left floating |
| LOW | 2 | BMI323 SPI lines no external idle pull; STM32 config supervisor open-loop (DONE/INIT_B not fed back) |
| INFO | 3 | U11 value W25Q128JVS vs WSON LCSC; eMMC RST MCU-owned; MIO6 PLL strap set indirectly via QSPI_CLK pull |

**Single most important NEW finding:** the boot-device select straps **BOOT_MODE[2] (MIO4) and BOOT_MODE[0] (MIO5) have no fixed pull resistor to any rail** — they are biased only through 10k *series* resistors out to STM32 GPIOs (PA7/PB2), while `PS_POR_B` is held high by R100→+3V3 and therefore releases on power-good **independent of STM32 state**. At a cold power-up where the STM32 has not yet driven the straps, the BootROM samples two floating boot-select bits and the boot source is undefined. This is the closest thing to a board-bring-up blocker in this pass.

**Clean interfaces — stated explicitly:** DDR addr/cmd/ctrl/clock (address A0–A14, BA0–2, RAS/CAS/WE/CS/CKE/ODT, CK_P/CK_N polarity, ZQ=240R, VREF=VDDQ/2) is **CLEAN**; QSPI bus bit-order is **CLEAN** (only the strap *bias mechanism* is suspect); eMMC 4-bit data path (D0–D3/CMD/CLK) is **CLEAN**; RGMII (all 12 data/ctrl + MDC/MDIO, delay strategy self-consistent) is **CLEAN**; ULPI/USB (8-bit data, DIR/STP/NXT/CLK direction, REFCLK level, RBIAS, DP/DM polarity) is **CLEAN**; BMI323 SPI4W (SDI/SDO/SCK/CS not swapped) is **CLEAN**; Zynq↔STM32 I2C0 is **CLEAN**; JTAG TAP (no TDI/TDO swap) is **CLEAN**; clocks/reset domains all match their banks.

---

## NEW confirmed wiring defects

### HIGH-1 — PS_SRST_B (1.8V VCCO_MIO1 input) driven directly by a 3.3V STM32 GPIO — input overdrive
- **What/where:** `NET ZYNQ_PS_SRST` = {R94.2 (10k), TP5.1, **U2.C9 [PS_SRST_B_501]**, **U9.26 [PB13]**}. R94.1 sits in `NET +1V8`. No series resistor, no level shifter between PB13 and PS_SRST_B. By contrast the sibling `NET ZYNQ_PS_POR` = {R100→+3V3, U2.B5, U9.PB12} — correctly matched to 3.3V.
- **Why:** UG585 Table 2-2 (verified, line ~2318): **PS_SRST_B `Voltage Node = VCCO_MIO1`**; on this SOM VCCO_MIO1 = +1V8 (R94 pulls to +1V8, consistent). The same table's CAUTION (line ~2304): "the allowable Vin High level voltage depends on the settings of … [IO_Type]/[DisableRcvr] … Damage to the input buffer can occur when the limits are exceeded." The STM32 runs on +3V3_SC and a push-pull GPIO swings to 3.3V — well above a 1.8V-banked input's recommended VIH (the absolute limit is set by the Zynq-7000 DC datasheet).
- **Impact:** If STM32 firmware configures PB13 as push-pull and drives it high, ~3.3V is forced into the 1.8V-domain PS_SRST_B input → long-term input-buffer damage / leakage / out-of-spec operation. Correctness then silently depends on firmware always using open-drain.
- **Fix:** Drive PB13 as **open-drain** (low / Hi-Z only) and let R94's 1.8V pull-up form the high level — mirroring the PS_POR_B 3.3V-domain approach; enforce in firmware. Or add an open-drain buffer / level shifter. A hard 3.3V push-pull drive is incompatible with the 1.8V bank.
- **Panel vote:** 3/3.

### HIGH-2 — PL DONE has no pull-up to VCCO_0; config-done can never read High
- **What/where:** `NET ZYNQ_PL_DONE` = {Q3.2 [G] (NMOS gate, high-Z), TP3.1, **U2.T12 [DONE_0]**}. There is **no pull-up resistor anywhere on the net** (verified — only 3 nodes).
- **Why:** UG585 Table 6-21 (verified verbatim, line 11409–11412): "DONE — Active-High open-drain output … The PL drives the DONE signal Low until the PL is successfully configured. **Board Connection: External 330 kΩ pull-up resistor to VCCO_0.**" VCCO_0 on this board = +3V3. DONE releases (tri-states) after config and *requires* an external pull-up to be read High.
- **Impact:** After successful PL configuration the DONE net floats instead of going High → the done-indicator LED (via Q3) never lights, and any supervisor/FSBL/JTAG-programmer/carrier logic polling DONE mis-reads "not done." Configuration itself still completes (the Low→release is internal); only done-status sensing is broken.
- **Fix:** Add a pull-up from `ZYNQ_PL_DONE` to +3V3 (VCCO_0) — 330k per UG585 (a stronger 4.7k–10k is commonly used and also fine).
- **Panel vote:** 3/3.

### HIGH-3 — BOOT_MODE[2] (MIO4) and BOOT_MODE[0] (MIO5) have NO fixed POR strap; boot device is undefined at cold POR
- **What/where:** `NET QSPI_D2{slash}BM2` = {R1.2 (10k), U11.3 [IO2], **U2.E4 [PS_MIO4]**}; `NET QSPI_D3{slash}BM0` = {R6.2 (10k), U11.7 [IO3], **U2.A3 [PS_MIO5]**}. R1.1/R6.1 do **not** go to a rail — they go to `NET ZYNQ_BMODE_2` (={R1.1, TP9, **U9.15 PA7**}) and `NET ZYNQ_BMODE_0` (={R6.1, TP10, **U9.19 PB2**}). So R1/R6 are 10k **series** isolators to STM32 GPIOs; neither MIO4 nor MIO5 has any pull to +3V3/GND. By contrast MIO2 (R76→GND), MIO3 (R77→GND), MIO6 (via QSPI_CLK→R13→GND) *are* statically strapped. `NET ZYNQ_PS_POR` is held high by R100→+3V3, so POR deasserts on power-good regardless of STM32 readiness.
- **Why:** UG585 §6.2.5 / Chapter 2 (verified, line ~2660): "The strapping pins are sampled a few PS_CLK clock cycles after the PS_POR_B reset signal de-asserts. **The board design ties these signals to VCC or ground using 20 KΩ pull-up and pull-down resistors.**" Per Table 6-4, Quad-SPI boot needs {MIO5,MIO4,MIO3} = {BOOT_MODE[0],[2],[1]} = {1,0,0} — i.e. **MIO5 must be pulled UP** and MIO4 pulled down. The Zynq provides no internal default on strap pins; ST confirms STM32 GPIOs are Hi-Z floating inputs out of the MCU's own reset.
- **Impact:** At a cold power cycle, if U9 firmware has not driven PA7=0 / PB2=1 before PS_POR_B releases, MIO4/MIO5 float and the BootROM samples indeterminate BOOT_MODE[2]/[0] → boot device undefined (may resolve to JTAG/NAND/SD/QSPI by noise/leakage). The board can fail to boot or boot from the wrong source on a fraction of power-ups. It is a race between U9 readiness and Zynq POR with no hardware QSPI fallback.
- **Fix (preferred = boots with no MCU):** Strap directly on the MIO pin and keep the STM32 series-isolated: add a ~20k pull-**down** on MIO4 (=0) and a ~20k pull-**up** on MIO5 (=1) to the bank rail, keeping R1/R6 as the dominant series so PA7/PB2 can still override. Alternative: change R100 to a pull-**down** so PS_POR_B defaults asserted (Zynq held in reset) until firmware sets the straps and releases PB12 — and verify the ordering. Also confirm U9 tri-states PA7/PB2 after POR sampling so they do not inject through 10k into flash IO2/IO3 during quad reads.
- **Panel vote:** 3/3. (The two MEDIUM entries "QSPI boot-mode straps…no passive pull" and "Boot-device straps MIO4/MIO5…no fail-safe default" are the same root cause restated from the boot-*determinism* angle; treat them as the MEDIUM-severity framing of HIGH-3, not independent defects.)

### MEDIUM — eMMC U7 DAT4–DAT7 and DS left floating (no pull/termination) on an 8-bit-capable part
- **What/where:** U7 = IS21ES08G (8-bit-capable eMMC). Verified single-node floating nets: `unconnected-(U7C-DAT4-PadB3)`, `…DAT5-PadB4`, `…DAT6-PadB5`, `…DAT7-PadB6`, `…DS-PadH5`. The 4-bit lower byte is correct: D0–D3/CMD each carry a 10k pull-up to +1V8 (R39–R43), CLK correctly un-pulled.
- **Why:** Per JEDEC eMMC, DAT lines are high-Z after reset; any DAT line not driven by the host must be biased to a defined level (pull-up to VCCQ conventional). DAT4–7/DS are real device I/O on this part, not true NC pins. The host can only run 4-bit anyway: the Zynq PS SDIO1 MIO mux exposes only DATA[0:3] (UG585 SDIO1 options DATA0={10,22,34,46}…DATA3={15,27,39,51}); there is no MIO path for DATA[4:7].
- **Impact:** Floating CMOS inputs on the eMMC die → idle leakage / possible indeterminate internal state / reduced EMC-SI margin (not boot-fatal). Also permanently caps throughput at 4-bit.
- **Fix:** Add 10k pull-ups to VCCQ(+1V8) on DAT4(B3)/DAT5(B4)/DAT6(B5)/DAT7(B6) and on DS(H5); pin the FSBL/u-boot eMMC bus width to 4-bit (no `MMC_CAP_8_BIT_DATA`). 8-bit on XC7Z020 would require routing CLK/CMD/DAT[7:0] via EMIO to PL pins — a respin, not a stuff option.
- **Panel vote:** 2/3.

### LOW — BMI323 SPI CSB (and SDX/SCX/SDO) have no external idle pull during the PL-unconfigured window
- **What/where:** `NET IO_L9_DQS_N_33` = {U14.12 [CSB], U2.Y21} — a pure 2-pin net, no resistor. SDX/SCX/SDO likewise pure point-to-point. PL SelectIO is tri-stated from power-up until the bitstream loads (can be 100s of ms–seconds).
- **Why:** Bosch BMI323 DS §7.2.1: powers up in I2C; "a rising edge on CSB is needed before starting SPI." During the float window CSB is held only by the internal 75/100/140k pull-up to VDDIO (keeps the safe I2C-default), and the first firmware CSB low→high supplies the SPI-arming edge — so the part won't latch the wrong protocol. Best practice is still an explicit external pull-up on CSB against pre-config noise.
- **Impact:** Not board-dead; functions once the PL drives the bus. Residual robustness risk only.
- **Fix:** Add ~10k pull-up on CSB to +VCCO_33 (=VDDIO), or constrain the PL IO with PULLUP + defined initial drive (no-cost FPGA-config alternative). No change to SDX/SCX/SDO required.
- **Panel vote:** 3/3.

### LOW — STM32 config supervisor is open-loop (DONE and INIT_B not routed back)
- **What/where:** STM32 drives PROGRAM_B (PA6→`ZYNQ_PL_PROGB`), PS_POR_B, PS_SRST_B, and the straps, but `ZYNQ_PL_DONE` (only Q3 gate + TP3) and `ZYNQ_PL_INITB` (only R99 4k7→+3V3 + TP2) reach **no** STM32 GPIO.
- **Why:** A controller that pulses PROGRAM_B normally monitors INIT_B (config-cleared/error) and DONE (complete) to sequence/detect failures — recommended supervisory practice (not strictly required by UG585 for boot to function).
- **Impact:** STM32 cannot detect a failed/aborted PL config or know when config finished → no recovery/retry/fault reporting from the system controller. Functional gap, not a boot-blocker.
- **Fix:** If respun, route DONE and INIT_B to spare STM32 GPIOs (both are 3.3V bank-0 config pins, compatible). Otherwise document that config supervision is open-loop.
- **Panel vote:** 3/3.

### INFO items
- **U11 value W25Q128JVS (SOIC) vs footprint+LCSC WSON (W25Q128JVEIQ, C401662):** label-only; same die/pinout/2.7–3.6V, footprint correctly WSON-8. Update the value string. (3/3)
- **eMMC RST_n owned by STM32 PC4** (`eMMC_~{RST}` = {R97→+1V8, U7.K5, U9.16/PC4}): single driver, pull-up holds it deasserted (JEDEC-safe), Zynq PS-SDIO has no RST MIO. Correct-but-unusual: Zynq cannot independently hardware-reset the eMMC. Document as MCU-owned. (2/3)
- **MIO6 PLL strap set indirectly via QSPI_CLK:** `NET QSPI_CLK_T/BM4` = {R95.2 (22R), U2.A4}; R95.1 joins `QSPI_CLK` which has R13(10k)→GND. Net MIO6 = 0 = PLL enabled (correct), but strapped through the shared clock node rather than a dedicated 20k. Reliable because the flash CLK is idle at strap sampling. Accept or add a dedicated 20k for clarity. (2/3)

---

## Per-interface verdict table

| Interface | Verdict | Key evidence |
|---|---|---|
| **DDR addr/cmd/ctrl/clk** | **CLEAN** | A0–A14 via 22R series R53–R67 (1:1 names), BA0–2 via R68/69/70, RAS/CAS/WE/CS/CKE/ODT each via series R to correct U1 pin; CK_P=U2.N4→U1.J7(CK), CK_N=U2.N5→U1.K7(CK#) correct polarity, R50=100R diff term; ZQ=U1.L8→R45 240R→GND; VREF=+0V675=VDDQ/2 to all four VREF pins. No swap/inversion/missing. (DDR x16-byte-lane + VRP/VRN R46/R47 swap are the *prior-audit* CRITICALs, excluded here.) |
| **QSPI (U11 W25Q128)** | **CLEAN bus / strap mechanism SUSPECT** | CS=MIO1, IO0=MIO2, IO1=MIO3, IO2=MIO4, IO3=MIO5, CLK=MIO6 — exact ascending bit-order, canonical QSPL0 single-device boot group (UG585 ~9968-9970), CS pull-up R44→+3V3, CLK 22R(R95)+10k(R13)→GND. Only defect = MIO4/MIO5 strap bias (HIGH-3). |
| **eMMC (U7 SDIO1)** | **DEFECT (MEDIUM)** | D0→MIO46, D1→MIO49, D2→MIO50, D3→MIO51, CMD→MIO47, CLK→MIO48 — each in its own UG585 SDIO1 index-locked set, pull-ups R39–R43→+1V8 (=VCCQ, bank 501), CLK un-pulled. DAT4–7+DS floating (MEDIUM). RST MCU-owned (INFO). |
| **RGMII (U3 RTL8211F)** | **CLEAN** | TXC=MIO16, TXD0–3=MIO17–20, TXCTL=MIO21, RXC=MIO22, RXD0–3=MIO23–26, RXCTL=MIO27, MDC=MIO52, MDIO=MIO53 (R14 1.5k→+1V8). No Tx/Rx group swap, no nibble swap; PHYAD=001; both 2ns delays sourced by PHY (rxdly/txdly straps up) → GEM must be plain `rgmii`. X2 25MHz 1.8Vpp amplitude is the *prior-audit* HIGH, excluded. |
| **ULPI (U5 USB3318)** | **CLEAN** | DATA0–7 → MIO32/33/34/35/28/37/38/39 (UG585 Table 15-50 1:1, no transposition); DIR=MIO29(in), NXT=MIO31(in), STP=MIO30(out); CLK = PHY CLKOUT→R22→MIO36(in) (output-clock mode correct); REFCLK 13MHz X1→R21, threshold scales with 1.8V VDD18 so 1.8Vpp compliant; RBIAS R24=8.06k; RESETB R5→+1V8; DP/DM polarity preserved to J1, not crossed with STM32 USB. |
| **BMI323 SPI (PL bank33)** | **CLEAN (LOW idle-pull note)** | SDI=pin14→Y21, SCK=pin13→Y22-area(AA22), SDO=pin1→AA21, CSB=pin12→Y21; MOSI/MISO and SCK/CS not swapped; INT1/INT2 on real PL IO; VDDIO=+VCCO_33 matches the PL bank rail. Only LOW = no external idle pull. |
| **Zynq↔STM32** | **CLEAN (I2C) / reset has HIGH-1** | I2C0 SCL=MIO14(via R96 22R)+R86 10k→+3V3, SDA=MIO15+R87 10k→+3V3; dedicated 2-node bus, no address collision, all 3.3V. PS_POR_B 3.3V-matched (correct); PS_SRST_B = HIGH-1 overdrive. |
| **Config/JTAG** | **DEFECT (DONE) / rest CLEAN** | TCK/TMS/TDI/TDO → bank-0 dedicated JTAG pins, TDO is output, no swap, route to J1. PROGRAM_B R98 4k7→+3V3 ✓, INIT_B R99 4k7→+3V3 ✓ (UG585 Table 6-21), CFGBVS=+3V3 ✓. **DONE = HIGH-2 (no 330k pull-up).** MIO4/5 straps = HIGH-3. VMODE: MIO7→R75→GND=LVCMOS33 (bank500=3V3 ✓), MIO8→R74→+3V3=LVCMOS18 (bank501=1V8 ✓) — consistent. |
| **Clocks/reset** | **CLEAN** | X1 13MHz(1V8)→USB REFCLK, X2 25MHz(1V8)→PHY EXT_CLK (XTAL_IN=GND, single-ended), X3 33MHz(3V3)→PS_CLK MIO bank500=3V3 (domain match), all 22R series, all EN tied to own Vdd (free-running). Resets: POR/SRST/PHY/USB/eMMC pulls all match their banks; DDR_RST R48 4k7→GND (asserted-safe); STM32_NRST RC. No clock on non-clock pin, no stuck reset, no domain mismatch (except SRST drive = HIGH-1). |
| **Pulls/term/power (cross)** | **CLEAN + reset domain HIGH-1** | Bank VCCO map: 500=+3V3, 501=+1V8, 502=+1V35; 13/33/34/35 carrier-supplied. All pull rails match their bank/peripheral I/O supply; decoupling present on every rail. RTL8211F INT/PMEB pulled to carrier +VCCO_35 = *prior-audit* LOW. |

---

## Rejected candidates (panel-killed)

1. **"MIO6 BOOT_MODE[4]/PLL strap floats at sampling" (HIGH, 0/3 — REFUTED).** `NET QSPI_CLK_T/BM4` = {R95.2 (22R series), U2.A4}; R95.1 joins `NET QSPI_CLK` = {R13.1 (10k), R95.1, TP11, U11.6 [CLK]}; R13.2 is in GND. So MIO6 *is* DC-held to 0 (PLL enabled) through the 22R+10k path; the flash CLK is idle at strap sampling. Not floating. (Captured as INFO instead.)
2. **"RTL8211F INT/PMEB pulled to carrier VCCO_35 → PHY overstress if 3.3V" (LOW, 0/3 — REFUTED).** Per the RTL8211F pin table, INT/PMEB is open-drain and tolerant; the receiver (Zynq bank-35 PL pin) shares the same +VCCO_35 pull rail, so it is domain-self-consistent. Already noted as a carrier-supplied documentation item in the prior audit.
3. **"eMMC on SDIO1 is non-bootable → eMMC boot fails silently" (INFO/MEDIUM, 1/3 — premises true, severity rejected).** Confirmed: eMMC is on SDIO1 (MIO46-51) which the BootROM cannot boot from (SD boot is hardcoded to SDIO0/MIO40-45 → carrier SD on J1). But primary boot is QSPI by design; FSBL mounts the eMMC afterward. Correct-but-noted topology, not a wiring defect → downgraded to a documentation INFO.
4. **"STM32 PA7/PB2 stay DC-coupled to flash IO2/IO3 through 10k" (LOW, 1/3).** Netlist reproduced exactly (R1/R6 are series), but the residual injection is folded into HIGH-3's fix note (tri-state PA7/PB2 after POR), so not raised as a standalone defect.

---

**Verification basis:** every NEW finding and every CLEAN verdict above was re-derived from `/tmp/som_netlist.net` / `/tmp/som_nets.txt` and cross-checked against `/tmp/ug585.txt` primary lines (Table 2-2 reset domains ~2300-2325; strap-20k/POR-sampling ~2658-2664; Table 6-21 DONE 330k @ 11409-11412) plus the device datasheets — no claim is taken on faith from the input JSON. Source files of record: `/Users/nicholasantoniades/Documents/GitHub/Zynq-SoM/som/Zynq_SoM.kicad_sch`, prior reports `/Users/nicholasantoniades/Documents/GitHub/Zynq-SoM/som/SOM_ELECTRICAL_AUDIT.md` and `/Users/nicholasantoniades/Documents/GitHub/Zynq-SoM/som/SOM_CARRIER_COORDINATION.md`.

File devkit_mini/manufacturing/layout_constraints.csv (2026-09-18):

net | sheet | kind | net_class | impedance_ohm | track_width_mm | pair_gap_mm | pair_with | length_match_group | match_tolerance_mm | notes
ETH_PHY_MDI0_N | som_j1 | diff_pair | DP100_DIFF | 100 | 0.2052 | 0.2032 | ETH_PHY_MDI0_P | PAIR:ETH_PHY_MDI0_N/ETH_PHY_MDI0_P | 1.27 | JLCPCB calculator, JLC04161H-7628 outer/L2; skew: IEEE 802.3 Clause 40 (1000BASE-T, 100Ω±15% MDI); ANSI/TIA-568 link; PHY-vendor (RTL8211F / TI SNLA387) layout: intra-pair ≤ 50 mil, inter-pair ≤ 50 mm (~330 ps)
ETH_PHY_MDI0_P | som_j1 | diff_pair | DP100_DIFF | 100 | 0.2052 | 0.2032 | ETH_PHY_MDI0_N | PAIR:ETH_PHY_MDI0_N/ETH_PHY_MDI0_P | 1.27 | JLCPCB calculator, JLC04161H-7628 outer/L2; skew: IEEE 802.3 Clause 40 (1000BASE-T, 100Ω±15% MDI); ANSI/TIA-568 link; PHY-vendor (RTL8211F / TI SNLA387) layout: intra-pair ≤ 50 mil, inter-pair ≤ 50 mm (~330 ps)
ETH_PHY_MDI1_N | som_j1 | diff_pair | DP100_DIFF | 100 | 0.2052 | 0.2032 | ETH_PHY_MDI1_P | PAIR:ETH_PHY_MDI1_N/ETH_PHY_MDI1_P | 1.27 | JLCPCB calculator, JLC04161H-7628 outer/L2; skew: IEEE 802.3 Clause 40 (100Ω±15%); RTL8211F/TI SNLA387 layout: intra-pair ≤50 mil, inter-pair ≤50 mm
ETH_PHY_MDI1_P | som_j1 | diff_pair | DP100_DIFF | 100 | 0.2052 | 0.2032 | ETH_PHY_MDI1_N | PAIR:ETH_PHY_MDI1_N/ETH_PHY_MDI1_P | 1.27 | JLCPCB calculator, JLC04161H-7628 outer/L2; skew: IEEE 802.3 Clause 40 (100Ω±15%); RTL8211F/TI SNLA387 layout: intra-pair ≤50 mil, inter-pair ≤50 mm
ETH_PHY_MDI2_N | som_j1 | diff_pair | DP100_DIFF | 100 | 0.2052 | 0.2032 | ETH_PHY_MDI2_P | PAIR:ETH_PHY_MDI2_N/ETH_PHY_MDI2_P | 1.27 | JLCPCB calculator, JLC04161H-7628 outer/L2; skew: IEEE 802.3 Clause 40 (100Ω±15%); RTL8211F/TI SNLA387 layout: intra-pair ≤50 mil, inter-pair ≤50 mm
ETH_PHY_MDI2_P | som_j1 | diff_pair | DP100_DIFF | 100 | 0.2052 | 0.2032 | ETH_PHY_MDI2_N | PAIR:ETH_PHY_MDI2_N/ETH_PHY_MDI2_P | 1.27 | JLCPCB calculator, JLC04161H-7628 outer/L2; skew: IEEE 802.3 Clause 40 (100Ω±15%); RTL8211F/TI SNLA387 layout: intra-pair ≤50 mil, inter-pair ≤50 mm
ETH_PHY_MDI3_N | som_j1 | diff_pair | DP100_DIFF | 100 | 0.2052 | 0.2032 | ETH_PHY_MDI3_P | PAIR:ETH_PHY_MDI3_N/ETH_PHY_MDI3_P | 1.27 | JLCPCB calculator, JLC04161H-7628 outer/L2; skew: IEEE 802.3 Clause 40 (100Ω±15%); RTL8211F/TI SNLA387 layout: intra-pair ≤50 mil, inter-pair ≤50 mm
ETH_PHY_MDI3_P | som_j1 | diff_pair | DP100_DIFF | 100 | 0.2052 | 0.2032 | ETH_PHY_MDI3_N | PAIR:ETH_PHY_MDI3_N/ETH_PHY_MDI3_P | 1.27 | JLCPCB calculator, JLC04161H-7628 outer/L2; skew: IEEE 802.3 Clause 40 (100Ω±15%); RTL8211F/TI SNLA387 layout: intra-pair ≤50 mil, inter-pair ≤50 mm
STM32_USB_D_N | pd_input | usb_hs_pair | DP90_USB | 90 | 0.2611 | 0.2032 | STM32_USB_D_P | PAIR:STM32_USB_D_N/STM32_USB_D_P | 3.81 | JLCPCB calculator, JLC04161H-7628 outer/L2; skew: USB 2.0 Spec Sec 7.1.1.3 / 7.1.6 (90Ω±15%); USB-IF HS layout intra-pair ≤150 mil
STM32_USB_D_P | pd_input | usb_hs_pair | DP90_USB | 90 | 0.2611 | 0.2032 | STM32_USB_D_N | PAIR:STM32_USB_D_N/STM32_USB_D_P | 3.81 | JLCPCB calculator, JLC04161H-7628 outer/L2; skew: USB 2.0 Spec Sec 7.1.1.3 / 7.1.6 (90Ω±15%); USB-IF HS layout intra-pair ≤150 mil
STM32_USB_D_N | som_j1 | usb_hs_pair | DP90_USB | 90 | 0.2611 | 0.2032 | STM32_USB_D_P | PAIR:STM32_USB_D_N/STM32_USB_D_P | 3.81 | JLCPCB calculator, JLC04161H-7628 outer/L2; skew: USB 2.0 Spec Sec 7.1.1.3 / 7.1.6 (90Ω±15%); USB-IF HS layout intra-pair ≤150 mil
STM32_USB_D_P | som_j1 | usb_hs_pair | DP90_USB | 90 | 0.2611 | 0.2032 | STM32_USB_D_N | PAIR:STM32_USB_D_N/STM32_USB_D_P | 3.81 | JLCPCB calculator, JLC04161H-7628 outer/L2; skew: USB 2.0 Spec Sec 7.1.1.3 / 7.1.6 (90Ω±15%); USB-IF HS layout intra-pair ≤150 mil
USB_D+ | som_j1 | usb_hs_pair | DP90_USB | 90 | 0.2611 | 0.2032 | USB_D- | PAIR:USB_D+/USB_D- | 3.81 | JLCPCB calculator, JLC04161H-7628 outer/L2; skew: USB 2.0 Spec Sec 7.1.1.3 / 7.1.6 (90Ω±15% differential HS); USB-IF/HS layout: intra-pair ≤150 mil (~1.6 mm), target ≤5 mm
USB_D- | som_j1 | usb_hs_pair | DP90_USB | 90 | 0.2611 | 0.2032 | USB_D+ | PAIR:USB_D+/USB_D- | 3.81 | JLCPCB calculator, JLC04161H-7628 outer/L2; skew: USB 2.0 Spec Sec 7.1.1.3 / 7.1.6 (90Ω±15% differential HS); USB-IF/HS layout: intra-pair ≤150 mil (~1.6 mm), target ≤5 mm
USB_UART_DM | uart_bridge | usb_hs_pair | DP90_USB | 90 | 0.2611 | 0.2032 | USB_UART_DP | PAIR:USB_UART_DM/USB_UART_DP | 3.81 | deferred: usb_uart_connector (wave 2); JLCPCB calculator, JLC04161H-7628 outer/L2; skew: USB 2.0 Spec Sec 7.1.1.3 (90Ω±15% diff); USB-IF FS/HS layout intra-pair ≤150 mil
USB_UART_DP | uart_bridge | usb_hs_pair | DP90_USB | 90 | 0.2611 | 0.2032 | USB_UART_DM | PAIR:USB_UART_DM/USB_UART_DP | 3.81 | deferred: usb_uart_connector (wave 2); JLCPCB calculator, JLC04161H-7628 outer/L2; skew: USB 2.0 Spec Sec 7.1.1.3 (90Ω±15% diff); USB-IF FS/HS layout intra-pair ≤150 mil
USB_UART_DM | usb_uart_connector | usb_hs_pair | DP90_USB | 90 | 0.2611 | 0.2032 | USB_UART_DP | PAIR:USB_UART_DM/USB_UART_DP | 3.81 | JLCPCB calculator, JLC04161H-7628 outer/L2; skew: USB 2.0 Spec Sec 7.1.1.3 (90Ω±15% diff); USB-IF FS/HS layout intra-pair ≤150 mil
USB_UART_DP | usb_uart_connector | usb_hs_pair | DP90_USB | 90 | 0.2611 | 0.2032 | USB_UART_DM | PAIR:USB_UART_DM/USB_UART_DP | 3.81 | JLCPCB calculator, JLC04161H-7628 outer/L2; skew: USB 2.0 Spec Sec 7.1.1.3 (90Ω±15% diff); USB-IF FS/HS layout intra-pair ≤150 mil
STM32_BOOT0 | debug_boot | single | Default |  |  |  |  |  |  | deferred: som_j1_connector
STM32_GPIO5 | debug_boot | single | Default |  |  |  |  |  |  | deferred: som_j1_connector
STM32_GPIO6 | debug_boot | single | Default |  |  |  |  |  |  | deferred: som_j1_connector
STM32_GPIO7 | debug_boot | single | Default |  |  |  |  |  |  | deferred: som_j1_connector
STM32_GPIO8 | debug_boot | single | Default |  |  |  |  |  |  | deferred: som_j1_connector
STM32_NRST | debug_boot | single | Default |  |  |  |  |  |  | deferred: som_j1_connector
VBUS_OUT_EN | debug_boot | single | Default |  |  |  |  |  |  | deferred: som_j1_connector
ZYNQ_TCK | debug_boot | single | Default |  |  |  |  |  |  | deferred: som_j1_connector
ZYNQ_TDI | debug_boot | single | Default |  |  |  |  |  |  | deferred: som_j1_connector
ZYNQ_TDO | debug_boot | single | Default |  |  |  |  |  |  | deferred: som_j1_connector
ZYNQ_TMS | debug_boot | single | Default |  |  |  |  |  |  | deferred: som_j1_connector
PD_FLT_N | pd_input | single | Default |  |  |  |  |  |  | deferred: bringup (TCA9535 expander port P15)
STM32_USB_CC1 | pd_input | single | Default
STM32_USB_CC2 | pd_input | single | Default
EN_1V8 | power | single | Default |  |  |  |  |  |  | deferred: bringup (wave 2 rail-enable cells, dossier section 3.1)
EN_3V3 | power | single | Default |  |  |  |  |  |  | deferred: bringup (wave 2 rail-enable cells, dossier section 3.1)
EN_5V0 | power | single | Default |  |  |  |  |  |  | deferred: bringup (wave 2 rail-enable cells, dossier section 3.1)
PMON_ALERT_N | power_mon | single | Default |  |  |  |  |  |  | deferred: bringup (TCA9535 spare port P11)
ETH_LED1 | som_j1 | single | Default
ETH_LED2 | som_j1 | single | Default
IO_0_35 | som_j1 | single | Default
IO_L1_N_35 | som_j1 | single | Default
IO_L1_P_35 | som_j1 | single | Default
IO_L2_N_35 | som_j1 | single | Default
IO_L4_N_35 | som_j1 | single | Default
IO_L4_P_35 | som_j1 | single | Default
IO_L5_N_35 | som_j1 | single | Default
IO_L5_P_35 | som_j1 | single | Default
IO_L6_P_35 | som_j1 | single | Default
IO_L6_VREF_N_35 | som_j1 | single | Default
STM32_BOOT0 | som_j1 | single | Default
STM32_GPIO1 | som_j1 | single | Default
STM32_GPIO2 | som_j1 | single | Default
STM32_GPIO3 | som_j1 | single | Default
STM32_GPIO4 | som_j1 | single | Default
STM32_GPIO5 | som_j1 | single | Default
STM32_GPIO6 | som_j1 | single | Default
STM32_GPIO7 | som_j1 | single | Default
STM32_GPIO8 | som_j1 | single | Default
STM32_I2C2_SCL | som_j1 | single | Default
STM32_I2C2_SDA | som_j1 | single | Default
STM32_NRST | som_j1 | single | Default
STM32_USB_CC1 | som_j1 | single | Default
STM32_USB_CC2 | som_j1 | single | Default
USB_ID | som_j1 | single | Default
USB_VBUS | som_j1 | single | Default
VBUS_OUT_EN | som_j1 | single | Default
ZYNQ_PS_MIO0 | som_j1 | single | Default
ZYNQ_PS_MIO12 | som_j1 | single | Default
ZYNQ_PS_MIO7/VM0 | som_j1 | single | Default
ZYNQ_PS_MIO8\VM1 | som_j1 | single | Default
ZYNQ_PS_MIO9 | som_j1 | single | Default
ZYNQ_PS_UART0_RXD | som_j1 | single | Default
ZYNQ_PS_UART0_TXD | som_j1 | single | Default
ZYNQ_TCK | som_j1 | single | Default
ZYNQ_TDI | som_j1 | single | Default
ZYNQ_TDO | som_j1 | single | Default
ZYNQ_TMS | som_j1 | single | Default
IO_25_13 | som_j2 | single | Default
IO_25_33 | som_j2 | single | Default
IO_L10_N_13 | som_j2 | single | Default
IO_L10_N_33 | som_j2 | single | Default
IO_L10_P_13 | som_j2 | single | Default
IO_L10_P_33 | som_j2 | single | Default
IO_L11_SRCC_N_13 | som_j2 | single | Default
IO_L11_SRCC_N_33 | som_j2 | single | Default
IO_L11_SRCC_P_13 | som_j2 | single | Default
IO_L11_SRCC_P_33 | som_j2 | single | Default
IO_L12_MRCC_N_13 | som_j2 | single | Default
IO_L12_MRCC_N_33 | som_j2 | single | Default
IO_L12_MRCC_P_13 | som_j2 | single | Default
IO_L12_MRCC_P_33 | som_j2 | single | Default
IO_L13_MRCC_N_13 | som_j2 | single | Default
IO_L13_MRCC_P_13 | som_j2 | single | Default
IO_L14_N_SRCC_13 | som_j2 | single | Default
IO_L14_P_SRCC_13 | som_j2 | single | Default
IO_L14_SRCC_N_33 | som_j2 | single | Default
IO_L14_SRCC_P_33 | som_j2 | single | Default
IO_L15_N_33 | som_j2 | single | Default
IO_L15_P_13 | som_j2 | single | Default
IO_L15_P_33 | som_j2 | single | Default
IO_L16_N_13 | som_j2 | single | Default
IO_L16_N_33 | som_j2 | single | Default
IO_L16_P_13 | som_j2 | single | Default
IO_L17_N_13 | som_j2 | single | Default
IO_L17_N_33 | som_j2 | single | Default
IO_L17_P_13 | som_j2 | single | Default
IO_L17_P_33 | som_j2 | single | Default
IO_L18_N_33 | som_j2 | single | Default
IO_L18_P_33 | som_j2 | single | Default
IO_L19_P_13 | som_j2 | single | Default
IO_L19_P_33 | som_j2 | single | Default
IO_L19_VREF_N_33 | som_j2 | single | Default
IO_L1P_13 | som_j2 | single | Default
IO_L1_N_13 | som_j2 | single | Default
IO_L20_N_33 | som_j2 | single | Default
IO_L20_P_33 | som_j2 | single | Default
IO_L21_DQS_N_33 | som_j2 | single | Default
IO_L21_DQS_P_33 | som_j2 | single | Default
IO_L21_P_13 | som_j2 | single | Default
IO_L22_N_33 | som_j2 | single | Default
IO_L22_P_13 | som_j2 | single | Default
IO_L22_P_33 | som_j2 | single | Default
IO_L23_N_13 | som_j2 | single | Default
IO_L23_N_33 | som_j2 | single | Default
IO_L23_P_13 | som_j2 | single | Default
IO_L23_P_33 | som_j2 | single | Default
IO_L24_N_13 | som_j2 | single | Default
IO_L24_N_33 | som_j2 | single | Default
IO_L24_P_13 | som_j2 | single | Default
IO_L24_P_33 | som_j2 | single | Default
IO_L2_N_13 | som_j2 | single | Default
IO_L2_P_13 | som_j2 | single | Default
IO_L3_N_13 | som_j2 | single | Default
IO_L3_P_13 | som_j2 | single | Default
IO_L4_N_13 | som_j2 | single | Default
IO_L4_P_13 | som_j2 | single | Default
IO_L5P_13 | som_j2 | single | Default
IO_L5_N_13 | som_j2 | single | Default
IO_L6_N_VREF_13 | som_j2 | single | Default
IO_L6_P_13 | som_j2 | single | Default
IO_L6_P_33 | som_j2 | single | Default
IO_L7_N_13 | som_j2 | single | Default
IO_L7_P_13 | som_j2 | single | Default
IO_L8_N_13 | som_j2 | single | Default
IO_L8_P_13 | som_j2 | single | Default
IO_L9_DQS_N_13 | som_j2 | single | Default
IO_L9_DQS_P_13 | som_j2 | single | Default
ZYNQ_PS_UART0_CTS_N | som_j2 | single | Default
ZYNQ_PS_UART0_RTS_N | som_j2 | single | Default
IO_L10_N_34 | som_j3 | single | Default
IO_L10_N_35 | som_j3 | single | Default
IO_L10_P_34 | som_j3 | single | Default
IO_L10_P_35 | som_j3 | single | Default
IO_L11_SRCC_N_34 | som_j3 | single | Default
IO_L11_SRCC_N_35 | som_j3 | single | Default
IO_L11_SRCC_P_34 | som_j3 | single | Default
IO_L11_SRCC_P_35 | som_j3 | single | Default
IO_L12_MRCC_N_34 | som_j3 | single | Default
IO_L12_MRCC_N_35 | som_j3 | single | Default
IO_L12_MRCC_P_34 | som_j3 | single | Default
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

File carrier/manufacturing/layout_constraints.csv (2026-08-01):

net | sheet | kind | net_class | impedance_ohm | track_width_mm | pair_gap_mm | pair_with | length_match_group | match_tolerance_mm | notes
CAM_CLK_N | camera | diff_pair | DP100_DIFF | 100 | 0.2052 | 0.2032 | CAM_CLK_P | PAIR:CAM_CLK_N/CAM_CLK_P | 0.508 | deferred: som_j3_connector (PL bank 35, LVDS_25, +VCCO_35=2.5V); JLCPCB calculator, JLC04161H-7628 outer/L2; skew: MIPI D-PHY (CSI-2): Zdiff=100Ω±20%; HS-RX 100Ω diff termination at receiver; clock-to-data lane skew is the timing reference, intra-pair tight (~±0.5 mm / 20 mil)
CAM_CLK_P | camera | diff_pair | DP100_DIFF | 100 | 0.2052 | 0.2032 | CAM_CLK_N | PAIR:CAM_CLK_N/CAM_CLK_P | 0.508 | deferred: som_j3_connector (PL bank 35, LVDS_25, +VCCO_35=2.5V); JLCPCB calculator, JLC04161H-7628 outer/L2; skew: MIPI D-PHY (CSI-2): Zdiff=100Ω±20%; HS-RX 100Ω diff termination at receiver; clock-to-data lane skew is the timing reference, intra-pair tight (~±0.5 mm / 20 mil)
CAM_D0_N | camera | diff_pair | DP100_DIFF | 100 | 0.2052 | 0.2032 | CAM_D0_P | PAIR:CAM_D0_N/CAM_D0_P | 0.508 | deferred: som_j3_connector (PL bank 35, LVDS_25, +VCCO_35=2.5V); JLCPCB calculator, JLC04161H-7628 outer/L2; skew: MIPI D-PHY (CSI-2): Zdiff=100Ω±20%; lane-to-clock skew budget governs inter-lane match; intra-pair ~±0.5 mm
CAM_D0_P | camera | diff_pair | DP100_DIFF | 100 | 0.2052 | 0.2032 | CAM_D0_N | PAIR:CAM_D0_N/CAM_D0_P | 0.508 | deferred: som_j3_connector (PL bank 35, LVDS_25, +VCCO_35=2.5V); JLCPCB calculator, JLC04161H-7628 outer/L2; skew: MIPI D-PHY (CSI-2): Zdiff=100Ω±20%; lane-to-clock skew budget governs inter-lane match; intra-pair ~±0.5 mm
CAM_D1_N | camera | diff_pair | DP100_DIFF | 100 | 0.2052 | 0.2032 | CAM_D1_P | PAIR:CAM_D1_N/CAM_D1_P | 0.508 | deferred: som_j3_connector (PL bank 35, LVDS_25, +VCCO_35=2.5V); JLCPCB calculator, JLC04161H-7628 outer/L2; skew: MIPI D-PHY (CSI-2): Zdiff=100Ω±20%; intra-pair ~±0.5 mm; inter-lane match to clock
CAM_D1_P | camera | diff_pair | DP100_DIFF | 100 | 0.2052 | 0.2032 | CAM_D1_N | PAIR:CAM_D1_N/CAM_D1_P | 0.508 | deferred: som_j3_connector (PL bank 35, LVDS_25, +VCCO_35=2.5V); JLCPCB calculator, JLC04161H-7628 outer/L2; skew: MIPI D-PHY (CSI-2): Zdiff=100Ω±20%; intra-pair ~±0.5 mm; inter-lane match to clock
ETH_LINE_MDI_0_N | ethernet | diff_pair | DP100_DIFF | 100 | 0.2052 | 0.2032 | ETH_LINE_MDI_0_P | PAIR:ETH_LINE_MDI_0_N/ETH_LINE_MDI_0_P | 1.27 | deferred: rj45_connector (wave 2); JLCPCB calculator, JLC04161H-7628 outer/L2; skew: IEEE 802.3 Clause 40 (100Ω±15% MDI); TIA-568 1000BASE-T pair order; Bob-Smith term IEEE 802.3 Sec 40.7.1
ETH_LINE_MDI_0_P | ethernet | diff_pair | DP100_DIFF | 100 | 0.2052 | 0.2032 | ETH_LINE_MDI_0_N | PAIR:ETH_LINE_MDI_0_N/ETH_LINE_MDI_0_P | 1.27 | deferred: rj45_connector (wave 2); JLCPCB calculator, JLC04161H-7628 outer/L2; skew: IEEE 802.3 Clause 40 (100Ω±15% MDI); TIA-568 1000BASE-T pair order; Bob-Smith term IEEE 802.3 Sec 40.7.1
ETH_LINE_MDI_1_N | ethernet | diff_pair | DP100_DIFF | 100 | 0.2052 | 0.2032 | ETH_LINE_MDI_1_P | PAIR:ETH_LINE_MDI_1_N/ETH_LINE_MDI_1_P | 1.27 | deferred: rj45_connector (wave 2); JLCPCB calculator, JLC04161H-7628 outer/L2; skew: IEEE 802.3 Clause 40 (100Ω±15%); TIA-568; 802.3 Sec 40.7.1
ETH_LINE_MDI_1_P | ethernet | diff_pair | DP100_DIFF | 100 | 0.2052 | 0.2032 | ETH_LINE_MDI_1_N | PAIR:ETH_LINE_MDI_1_N/ETH_LINE_MDI_1_P | 1.27 | deferred: rj45_connector (wave 2); JLCPCB calculator, JLC04161H-7628 outer/L2; skew: IEEE 802.3 Clause 40 (100Ω±15%); TIA-568; 802.3 Sec 40.7.1
ETH_LINE_MDI_2_N | ethernet | diff_pair | DP100_DIFF | 100 | 0.2052 | 0.2032 | ETH_LINE_MDI_2_P | PAIR:ETH_LINE_MDI_2_N/ETH_LINE_MDI_2_P | 1.27 | deferred: rj45_connector (wave 2); JLCPCB calculator, JLC04161H-7628 outer/L2; skew: IEEE 802.3 Clause 40 (100Ω±15%); TIA-568; 802.3 Sec 40.7.1
ETH_LINE_MDI_2_P | ethernet | diff_pair | DP100_DIFF | 100 | 0.2052 | 0.2032 | ETH_LINE_MDI_2_N | PAIR:ETH_LINE_MDI_2_N/ETH_LINE_MDI_2_P | 1.27 | deferred: rj45_connector (wave 2); JLCPCB calculator, JLC04161H-7628 outer/L2; skew: IEEE 802.3 Clause 40 (100Ω±15%); TIA-568; 802.3 Sec 40.7.1
ETH_LINE_MDI_3_N | ethernet | diff_pair | DP100_DIFF | 100 | 0.2052 | 0.2032 | ETH_LINE_MDI_3_P | PAIR:ETH_LINE_MDI_3_N/ETH_LINE_MDI_3_P | 1.27 | deferred: rj45_connector (wave 2); JLCPCB calculator, JLC04161H-7628 outer/L2; skew: IEEE 802.3 Clause 40 (100Ω±15%); TIA-568; 802.3 Sec 40.7.1
ETH_LINE_MDI_3_P | ethernet | diff_pair | DP100_DIFF | 100 | 0.2052 | 0.2032 | ETH_LINE_MDI_3_N | PAIR:ETH_LINE_MDI_3_N/ETH_LINE_MDI_3_P | 1.27 | deferred: rj45_connector (wave 2); JLCPCB calculator, JLC04161H-7628 outer/L2; skew: IEEE 802.3 Clause 40 (100Ω±15%); TIA-568; 802.3 Sec 40.7.1
ETH_PHY_MDI0_N | ethernet | diff_pair | DP100_DIFF | 100 | 0.2052 | 0.2032 | ETH_PHY_MDI0_P | PAIR:ETH_PHY_MDI0_N/ETH_PHY_MDI0_P | 1.27 | JLCPCB calculator, JLC04161H-7628 outer/L2; skew: IEEE 802.3 Clause 40 (1000BASE-T, 100Ω±15% MDI); ANSI/TIA-568 link; PHY-vendor (RTL8211F / TI SNLA387) layout: intra-pair ≤ 50 mil, inter-pair ≤ 50 mm (~330 ps)
ETH_PHY_MDI0_P | ethernet | diff_pair | DP100_DIFF | 100 | 0.2052 | 0.2032 | ETH_PHY_MDI0_N | PAIR:ETH_PHY_MDI0_N/ETH_PHY_MDI0_P | 1.27 | JLCPCB calculator, JLC04161H-7628 outer/L2; skew: IEEE 802.3 Clause 40 (1000BASE-T, 100Ω±15% MDI); ANSI/TIA-568 link; PHY-vendor (RTL8211F / TI SNLA387) layout: intra-pair ≤ 50 mil, inter-pair ≤ 50 mm (~330 ps)
ETH_PHY_MDI1_N | ethernet | diff_pair | DP100_DIFF | 100 | 0.2052 | 0.2032 | ETH_PHY_MDI1_P | PAIR:ETH_PHY_MDI1_N/ETH_PHY_MDI1_P | 1.27 | JLCPCB calculator, JLC04161H-7628 outer/L2; skew: IEEE 802.3 Clause 40 (100Ω±15%); RTL8211F/TI SNLA387 layout: intra-pair ≤50 mil, inter-pair ≤50 mm
ETH_PHY_MDI1_P | ethernet | diff_pair | DP100_DIFF | 100 | 0.2052 | 0.2032 | ETH_PHY_MDI1_N | PAIR:ETH_PHY_MDI1_N/ETH_PHY_MDI1_P | 1.27 | JLCPCB calculator, JLC04161H-7628 outer/L2; skew: IEEE 802.3 Clause 40 (100Ω±15%); RTL8211F/TI SNLA387 layout: intra-pair ≤50 mil, inter-pair ≤50 mm
ETH_PHY_MDI2_N | ethernet | diff_pair | DP100_DIFF | 100 | 0.2052 | 0.2032 | ETH_PHY_MDI2_P | PAIR:ETH_PHY_MDI2_N/ETH_PHY_MDI2_P | 1.27 | JLCPCB calculator, JLC04161H-7628 outer/L2; skew: IEEE 802.3 Clause 40 (100Ω±15%); RTL8211F/TI SNLA387 layout: intra-pair ≤50 mil, inter-pair ≤50 mm
ETH_PHY_MDI2_P | ethernet | diff_pair | DP100_DIFF | 100 | 0.2052 | 0.2032 | ETH_PHY_MDI2_N | PAIR:ETH_PHY_MDI2_N/ETH_PHY_MDI2_P | 1.27 | JLCPCB calculator, JLC04161H-7628 outer/L2; skew: IEEE 802.3 Clause 40 (100Ω±15%); RTL8211F/TI SNLA387 layout: intra-pair ≤50 mil, inter-pair ≤50 mm
ETH_PHY_MDI3_N | ethernet | diff_pair | DP100_DIFF | 100 | 0.2052 | 0.2032 | ETH_PHY_MDI3_P | PAIR:ETH_PHY_MDI3_N/ETH_PHY_MDI3_P | 1.27 | JLCPCB calculator, JLC04161H-7628 outer/L2; skew: IEEE 802.3 Clause 40 (100Ω±15%); RTL8211F/TI SNLA387 layout: intra-pair ≤50 mil, inter-pair ≤50 mm
ETH_PHY_MDI3_P | ethernet | diff_pair | DP100_DIFF | 100 | 0.2052 | 0.2032 | ETH_PHY_MDI3_N | PAIR:ETH_PHY_MDI3_N/ETH_PHY_MDI3_P | 1.27 | JLCPCB calculator, JLC04161H-7628 outer/L2; skew: IEEE 802.3 Clause 40 (100Ω±15%); RTL8211F/TI SNLA387 layout: intra-pair ≤50 mil, inter-pair ≤50 mm
FMC_CLK0_M2C_N | fmc | diff_pair | DP100_DIFF | 100 | 0.2052 | 0.2032 | FMC_CLK0_M2C_P | PAIR:FMC_CLK0_M2C_N/FMC_CLK0_M2C_P | 0.127 | deferred: som_j3/j1 bank-35 pin map (dossier fmc.md section 1, P3 linker); JLCPCB calculator, JLC04161H-7628 outer/L2; skew: ANSI/VITA 57.1 FMC (LA/CLK differential pairs 100Ω); Samtec/TE FMC layout guideline: 100Ω diff, intra-pair ±5 mil, tight inter-pair within LA bus
FMC_CLK0_M2C_P | fmc | diff_pair | DP100_DIFF | 100 | 0.2052 | 0.2032 | FMC_CLK0_M2C_N | PAIR:FMC_CLK0_M2C_N/FMC_CLK0_M2C_P | 0.127 | deferred: som_j3/j1 bank-35 pin map (dossier fmc.md section 1, P3 linker); JLCPCB calculator, JLC04161H-7628 outer/L2; skew: ANSI/VITA 57.1 FMC (LA/CLK differential pairs 100Ω); Samtec/TE FMC layout guideline: 100Ω diff, intra-pair ±5 mil, tight inter-pair within LA bus
FMC_CLK1_M2C_N | fmc | diff_pair | DP100_DIFF | 100 | 0.2052 | 0.2032 | FMC_CLK1_M2C_P | PAIR:FMC_CLK1_M2C_N/FMC_CLK1_M2C_P | 0.127 | deferred: som_j3/j1 bank-35 pin map (dossier fmc.md section 1, P3 linker); JLCPCB calculator, JLC04161H-7628 outer/L2; skew: ANSI/VITA 57.1 FMC (100Ω diff); Samtec/TE layout: intra-pair ±5 mil
FMC_CLK1_M2C_P | fmc | diff_pair | DP100_DIFF | 100 | 0.2052 | 0.2032 | FMC_CLK1_M2C_N | PAIR:FMC_CLK1_M2C_N/FMC_CLK1_M2C_P | 0.127 | deferred: som_j3/j1 bank-35 pin map (dossier fmc.md section 1, P3 linker); JLCPCB calculator, JLC04161H-7628 outer/L2; skew: ANSI/VITA 57.1 FMC (100Ω diff); Samtec/TE layout: intra-pair ±5 mil
FMC_LA00_CC_N | fmc | diff_pair | DP100_DIFF | 100 | 0.2052 | 0.2032 | FMC_LA00_CC_P | PAIR:FMC_LA00_CC_N/FMC_LA00_CC_P | 0.127 | deferred: som_j3/j1 bank-35 pin map (dossier fmc.md section 1, P3 linker); JLCPCB calculator, JLC04161H-7628 outer/L2; skew: ANSI/VITA 57.1 (LA pairs 100Ω diff); Samtec/TE FMC layout: 100Ω, intra-pair ±5 mil, match LA bus to CLK
FMC_LA00_CC_P | fmc | diff_pair | DP100_DIFF | 100 | 0.2052 | 0.2032 | FMC_LA00_CC_N | PAIR:FMC_LA00_CC_N/FMC_LA00_CC_P | 0.127 | deferred: som_j3/j1 bank-35 pin map (dossier fmc.md section 1, P3 linker); JLCPCB calculator, JLC04161H-7628 outer/L2; skew: ANSI/VITA 57.1 (LA pairs 100Ω diff); Samtec/TE FMC layout: 100Ω, intra-pair ±5 mil, match LA bus to CLK
FMC_LA01_CC_N | fmc | diff_pair | DP100_DIFF | 100 | 0.2052 | 0.2032 | FMC_LA01_CC_P | PAIR:FMC_LA01_CC_N/FMC_LA01_CC_P | 0.127 | deferred: som_j3/j1 bank-35 pin map (dossier fmc.md section 1, P3 linker); JLCPCB calculator, JLC04161H-7628 outer/L2; skew: ANSI/VITA 57.1 (100Ω diff); Samtec/TE layout ±5 mil
FMC_LA01_CC_P | fmc | diff_pair | DP100_DIFF | 100 | 0.2052 | 0.2032 | FMC_LA01_CC_N | PAIR:FMC_LA01_CC_N/FMC_LA01_CC_P | 0.127 | deferred: som_j3/j1 bank-35 pin map (dossier fmc.md section 1, P3 linker); JLCPCB calculator, JLC04161H-7628 outer/L2; skew: ANSI/VITA 57.1 (100Ω diff); Samtec/TE layout ±5 mil
FMC_LA02_N | fmc | diff_pair | DP100_DIFF | 100 | 0.2052 | 0.2032 | FMC_LA02_P | PAIR:FMC_LA02_N/FMC_LA02_P | 0.127 | deferred: som_j3/j1 bank-35 pin map (dossier fmc.md section 1, P3 linker); JLCPCB calculator, JLC04161H-7628 outer/L2; skew: ANSI/VITA 57.1 (100Ω diff); Samtec/TE FMC layout ±5 mil
FMC_LA02_P | fmc | diff_pair | DP100_DIFF | 100 | 0.2052 | 0.2032 | FMC_LA02_N | PAIR:FMC_LA02_N/FMC_LA02_P | 0.127 | deferred: som_j3/j1 bank-35 pin map (dossier fmc.md section 1, P3 linker); JLCPCB calculator, JLC04161H-7628 outer/L2; skew: ANSI/VITA 57.1 (100Ω diff); Samtec/TE FMC layout ±5 mil
FMC_LA03_N | fmc | diff_pair | DP100_DIFF | 100 | 0.2052 | 0.2032 | FMC_LA03_P | PAIR:FMC_LA03_N/FMC_LA03_P | 0.127 | deferred: som_j3/j1 bank-35 pin map (dossier fmc.md section 1, P3 linker); JLCPCB calculator, JLC04161H-7628 outer/L2; skew: ANSI/VITA 57.1 (100Ω diff); Samtec/TE FMC layout ±5 mil
FMC_LA03_P | fmc | diff_pair | DP100_DIFF | 100 | 0.2052 | 0.2032 | FMC_LA03_N | PAIR:FMC_LA03_N/FMC_LA03_P | 0.127 | deferred: som_j3/j1 bank-35 pin map (dossier fmc.md section 1, P3 linker); JLCPCB calculator, JLC04161H-7628 outer/L2; skew: ANSI/VITA 57.1 (100Ω diff); Samtec/TE FMC layout ±5 mil
FMC_LA04_N | fmc | diff_pair | DP100_DIFF | 100 | 0.2052 | 0.2032 | FMC_LA04_P | PAIR:FMC_LA04_N/FMC_LA04_P | 0.127 | deferred: som_j3/j1 bank-35 pin map (dossier fmc.md section 1, P3 linker); JLCPCB calculator, JLC04161H-7628 outer/L2; skew: ANSI/VITA 57.1 (100Ω diff); Samtec/TE FMC layout ±5 mil
FMC_LA04_P | fmc | diff_pair | DP100_DIFF | 100 | 0.2052 | 0.2032 | FMC_LA04_N | PAIR:FMC_LA04_N/FMC_LA04_P | 0.127 | deferred: som_j3/j1 bank-35 pin map (dossier fmc.md section 1, P3 linker); JLCPCB calculator, JLC04161H-7628 outer/L2; skew: ANSI/VITA 57.1 (100Ω diff); Samtec/TE FMC layout ±5 mil
FMC_LA05_N | fmc | diff_pair | DP100_DIFF | 100 | 0.2052 | 0.2032 | FMC_LA05_P | PAIR:FMC_LA05_N/FMC_LA05_P | 0.127 | deferred: som_j3/j1 bank-35 pin map (dossier fmc.md section 1, P3 linker); JLCPCB calculator, JLC04161H-7628 outer/L2; skew: ANSI/VITA 57.1 (100Ω diff); Samtec/TE FMC layout ±5 mil
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

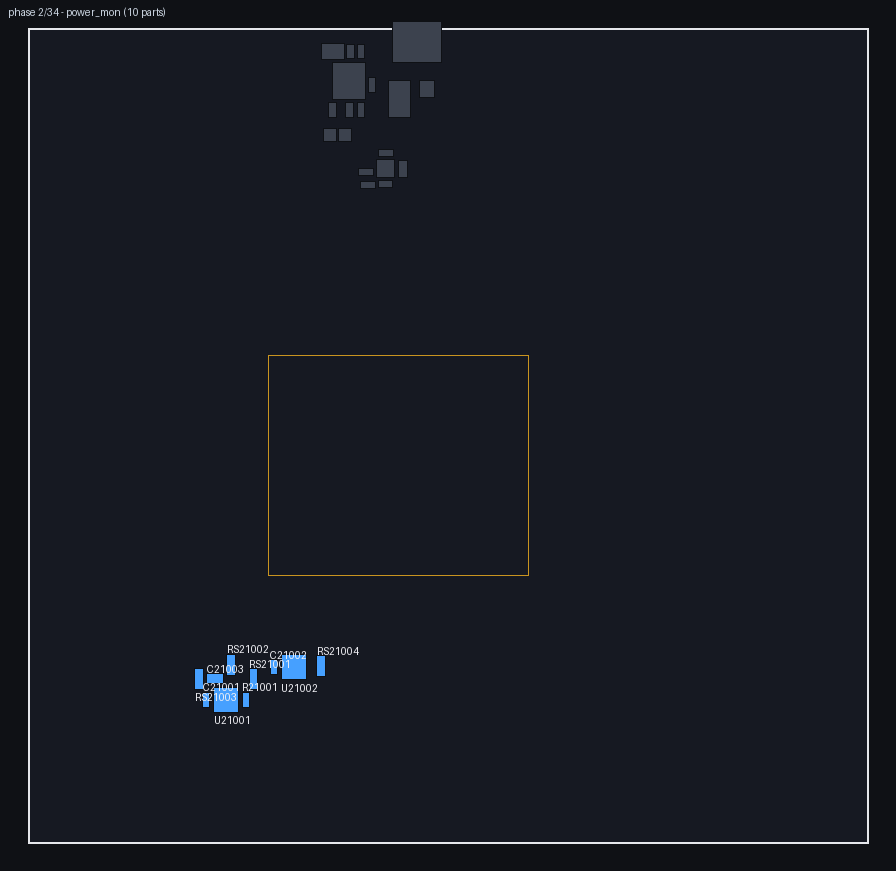
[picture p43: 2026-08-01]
carrier/renders/assembly/phase_02_power_mon.png

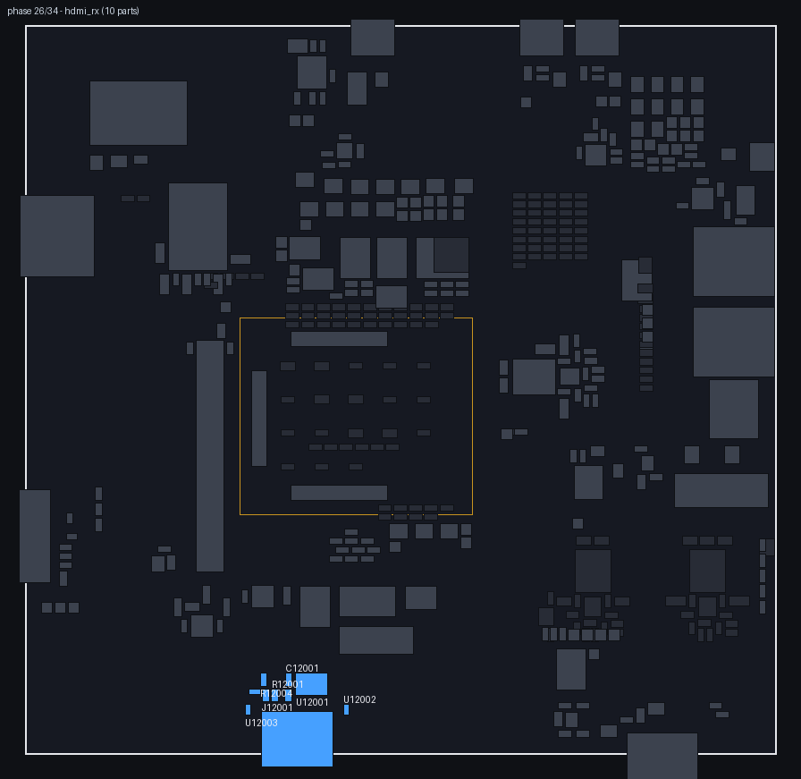
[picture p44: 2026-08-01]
carrier/renders/assembly/phase_26_hdmi_rx.png

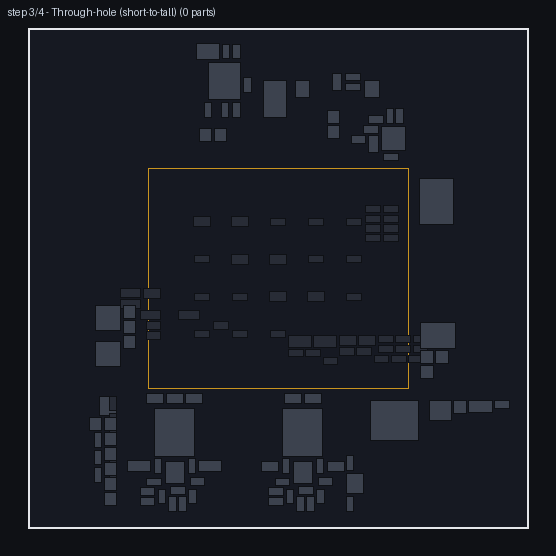
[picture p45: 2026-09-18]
devkit_mini/renders/assembly/step_3_tht.png

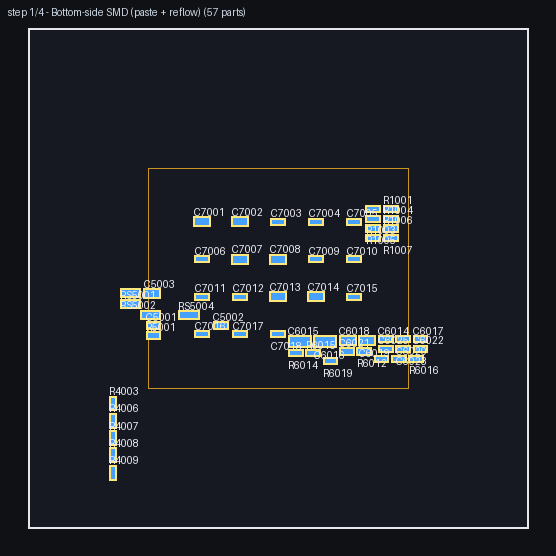
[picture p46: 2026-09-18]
devkit_mini/renders/assembly/step_1_bottom_smd.png

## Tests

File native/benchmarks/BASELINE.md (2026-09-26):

# Migration performance baseline

The owner's sole authorized comparison baseline is
`0e9bbc913bab77f9cd228940db2a332d25d6bfa1`.

Earlier observations against `4bd47c33` are retained as historical evidence,
not as the requested Python-versus-C++ comparison. That later revision already
used native geometry kernels and must not substitute for the authorized commit.

## Measurement rules

- Run the original baseline implementation in its exact isolated checkout.
  Do not copy later geometry extensions, authoring code, fixtures or generated
  inputs into it. Keep the active migration checkout Python-free.
- Measure carrier and devkit_mini separately, sequentially, with the same
  render policy and external tool versions. Keep all required checks enabled.
- Record full command wall time, exit status, gate results, revision, runtime,
  concurrency and raw log paths. Never call a failed or incomplete run a
  successful build. Never substitute README estimates for observations.
- Record clean generator compilation separately from each board invocation.
  The native generator is shared by both boards, not compiled once per board.
- Native timing rows are exclusive wall intervals: nested scopes pause their
  parent and parallel work is measured around launch/join, not by adding worker
  CPU times. Source auditing, authoring auditing and actual generation calls
  are separately labelled. Mixed generation/validation stages remain mixed.
- The baseline's built-in lap labels are not pure operation timings: its PCB
  worker overlaps document/validation work, and the later PCB lap includes only
  the remaining join wait. Its lap total also excludes final ledger validation.
  External process time is the complete-command measurement.
- Original baseline and current designs differ. Preserve both original
  workloads and disclose sheet/part/net counts, dimensions and design-input
  differences; revision-to-revision elapsed changes are not by themselves
  same-input language speedups.
- Percentage change is `(current_seconds - baseline_seconds) /
  baseline_seconds * 100`; negative is faster. Publish no percentage until
  both named measurements exist, and retain every raw sample.

Timing instrumentation never disables a gate or turns a failed audit green.

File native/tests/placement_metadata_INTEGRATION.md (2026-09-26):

# Native package retirement and placement-metadata contracts

Owned files only: the existing `authoring_gates_contracts.cpp`, new
`placement_metadata_contracts.cpp`, and this handoff. No production authoring,
geometry, gates, regression sources, CMake, main/CLI, shared builds or commits
were changed. The metadata checker is test-local repository policy, replacing
the corresponding pytest assertions, not a new production geometry validator.

## Parent registration

The existing `schgen_authoring_gates_contracts` / `native_authoring_gates_contracts`
target, registration and REPOSITORY argument are unchanged. Rebuild it coherently.
Add only this new family:

```cmake
add_executable(schgen_placement_metadata_contracts tests/placement_metadata_contracts.cpp)
target_link_libraries(schgen_placement_metadata_contracts PRIVATE schgen_core)
target_compile_options(schgen_placement_metadata_contracts PRIVATE
    -Wall -Wextra -Wpedantic -Werror -ffp-contract=off)
add_test(NAME native_placement_metadata_contracts
    COMMAND schgen_placement_metadata_contracts "${CMAKE_CURRENT_SOURCE_DIR}/..")
set_tests_properties(native_placement_metadata_contracts PROPERTIES TIMEOUT 120)
```

Both commands require the built native part catalog and actual repository data.
They require no Python, shell, KiCad subprocess, rendering or cached board. Missing
catalogs, contracts, factories, metadata or policy evidence fail; there are no
skip paths or expected-failure waivers.

## Existing authoring gate cleanup

Actual repository checks now explicitly use `AuthoringPackageMode::native_assets`
for all 17 library and 49 project packages, using the real native registry.
Canonical JSON companions are still compared against freshly authored circuits,
and original independently captured circuit expectations remain intact.

Legacy layout/discovery and exact report checks now run only in an inert private
fixture tree. The immutable oracle chooses its package population and adapter/
local shape; `.py` names contain a deliberately non-executable marker, never a
copy of a retained Python implementation. Actual native factories still produce
the circuits. Independent companion JSON bytes are copied as test input, not
used as constructor implementations. Legacy summary comparisons are exact;
published bytes must also match exactly including the final newline. Only the
expected package path prefix is relocated, as in the original contract helper.

Existing isolated mutation cases are retained. The no-Python native asset tests
still exercise missing files/factories, malformed or changed companions, changed
factory output, duplicate registrations/interfaces, missing adapters, bad
metadata, exceptions and unregistered folders.

The three independent report/circuit oracle files were not edited. SHA-256:

```text
810621d8f44e273ee946683a3af9cb7b714e26ab3f1378c4e2db5c499c213703  gate_library.json
8690dccb5809506c3e7b9ebe5948635e90bf57fc5867c662da2f47907fe3a57a  gate_carrier.json
56c12f2515b40d63e3a67adac60734b8c679bbcebbc9c9a7ee5aa8b33976ed75  gate_devkit_mini.json
```

## New metadata coverage

Original non-geometric policy sources were inspected in full before the port:

```text
d30bd37ed723b8e1979159de88b548b700887096f543095368a56628d3695beb  schgen/tests/test_lightweight_contracts.py
3d2eeb47434f384cb99706fd6ee2e0ac5ab366b126168bee9b78517889c48239  schgen/tests/test_hs_family_contracts.py
```

The native test constructs ten fresh carrier circuits through
`native_project_factories`, consuming the live part catalog. It reads actual
library-first placement-contract JSON and native project configuration. It never
loads a circuit catalog or `circuit.json` for these circuits.

- Lightweight: `lcd`, `microsd`, `uart_bridge`, `usb_jtag`, `usbc_otg`,
  `pd_input`, `pmod`. Covers sheet/subsystem identity, lightweight tier,
  external near-max-only policy, allowed structure types, judgment/nonblank basis,
  proximity anchor/members/positive distance, same-side IC population, references,
  roles, dossier anchor-pin membership and configured wiring.
- Critical: `hdmi_tx`, `camera`, `hdmi_rx_term`. Covers placement/v2,
  non-lightweight status, citations, every structure and near/far threshold basis,
  known structure types, authored references and configured wiring.
- USB-JTAG: exactly one proximity structure whose members are exactly `Y1`,
  anchored at `U1`, pins exactly `19`/`20` (order-independent), exactly 5.0 mm,
  and crystal-specific basis. A one-ULP distance mutation fails.
- Additional defensive assertions reject malformed typed JSON shapes, nonfinite
  distances and blank evidence. They do not change any production gate/API.

Every named policy has a negative mutation; an explicit 33-policy census catches
missing mutation coverage. The 696 negative cases mutate JSON and separately
remove authored parts/pin tables, proving that fresh IR matters. Every original
input is rechecked after its copied mutations. Valid swapped crystal pins and
evidenced external terms are positive controls. Existing placement/flow geometry,
footprint-pad, real-board discovery and report contracts remain the responsibility
of their existing native families; none of those algorithms is duplicated here.

## Isolated proof

- Authoring: **4,196 assertions PASS**, strict and ASan/UBSan.
- Metadata: **1,563 assertions PASS**, strict and ASan/UBSan; ten fresh circuits,
  696 rejected mutations, 33 policies.
- Both suites also pass with identical counts against a private 245-file asset
  tree containing **no `.py`, `.pyc` or `.so` files**. This proves Python-file
  deletion readiness without changing the user's checkout.
- Metadata additionally passes strict and sanitized with every canonical
  `circuit.json` in a second Python-free asset tree deliberately invalid. Thus a
  cached circuit snapshot cannot be its circuit source.

Proof directory: `/private/tmp/native-retirement-contracts.XgEtuG`.
Executables: `authoring-strict`, `metadata-strict`, `authoring_gates-asan`,
`placement_metadata-asan`.
Python-free input tree: `/private/tmp/schgen-no-python-assets-hEsZHK`.
Python-free poisoned-circuit tree: `/private/tmp/schgen-no-python-assets-KDEv1Y`.
The C++ asset-copy proof helper and sanitizer build script are retained privately.

Strict tests used a private immutable copy of the existing core archive, SHA-256
`e26211c85bc7434300e96d5f0be26db2fa71998f32aaf2ffdf26eda9e8832786`.
Sanitizer tests freshly compiled **all 60 repository sources in the union of
their link-map closures**, plus each test, from a private source/header snapshot.
No uninstrumented repository archive was used for sanitizer proof. System LibXml2
and OS libraries remain system binaries. The source snapshot also includes the
concurrent production author's header separation; no edits to it were needed.

Compiler flags: C++17, `-O1 -g -Wall -Wextra -Wpedantic -Werror -ffp-contract=off`,
with `-fsanitize=address,undefined -fno-omit-frame-pointer` for sanitizer builds.
Runtime options: `ASAN_OPTIONS=abort_on_error=1 UBSAN_OPTIONS=halt_on_error=1`.
This macOS proof does not claim unsupported LeakSanitizer coverage.

Run either test executable with exactly one argument: repository/input-tree root.
Do not run the authoring companion-consistency suite against the deliberately
poisoned metadata-only tree; rejecting those companions is its correct behavior.
None of these focused results claims full-board pipeline acceptance.

Frozen source SHA-256:

```text
2a423fa07ea6279897c2018c10ed5b83309a8960b072e84a5fd985ed2288bb35  authoring_gates_contracts.cpp
c2e440c1e96a614b3f9aef68c3dfb3bc35b815434af53805dd69acf310f96bf4  placement_metadata_contracts.cpp
```

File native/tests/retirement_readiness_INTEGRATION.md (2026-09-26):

# Tracked Python retirement inventory and independent SI-unit contracts

The original SI/inventory batch consists of these NEW files:

- `native/tests/si_units_contracts.cpp`
- `native/tests/data/retirement_readiness/tracked_python.json`
- this handoff

Parent subsequently approved the exact deletion plan in
`native/tests/data/retirement_readiness/approved_batch.json`: retire **389** of
the 393 tracked Python paths now, while preserving the four explicitly listed
build-twice/render/downstream-I2C/SI tests until their native proof/registration
is accepted. This is a plan only; this worker executed no deletion. The SI test
below is frozen for registration; the next approved new-only test closes the
downstream-I2C join. Parent owns the other two acceptance boundaries.

No production source, existing test, CMake, CLI, shared build, Python file or
previous oracle was changed. Previous regression/authoring/placement-metadata
files remain byte-identical to their accepted hashes. No commits or Python
processes were run.

## Complete bounded inventory

The JSON inventory maps **all 393 tracked Python files**, with individual source
SHA-256, role, native-family references and explicit exceptions. There are
**151 test modules**, **173 production modules**, **61 package entrypoints**, two
pytest infrastructure modules, two RC smoke helpers, two SoM generation tools,
one basis-audit tool and one CLI module. All 393 paths are unique and match the
sorted `git ls-files '*.py'` census exactly. The map names 48 native families and
126 existing evidence files. Snapshot HEAD:
`567621c9e75522a30e88a10e48537d6c29365f2d`; hashes describe its working-tree files.

Of the 151 test modules, 146 have existing native-family evidence, one Python
extension/import-only module retires with the extension, one gap is closed by
this SI test, and three carry explicit remaining join/acceptance/baseline work
below. This is a family-level retirement map, **not** a claim of a literal native
twin for every Python assertion or that pending parent acceptance has passed.

The inventory reuses port handoffs, immutable fixtures and native registrations.
Original tests were inspected selectively where mappings were ambiguous; the
entire redundant ported suite was not reread or executed.

Condensed mapping:

- 66 library/project subsystem test modules plus project-twin parity:
  fresh native authoring, independent complete IR oracles, invalid-meta/helper
  mutations and native-assets package gates. Literal Python module shape and
  textual twin-source identity disappear with those adapters.
- Model, symbols, netlist, schematic, route, pagination and part import:
  circuit/model/validation, symbols, schematic-place/route, netlist and importer
  contracts (including exposed-pad construction, not just part metadata).
- PCB, mirror, packing, stages, floorplan, compose, placement/flow and return
  checks: existing primitive/placement/emitter/gate families and precision
  fixtures. Fresh placement-metadata policy is the previous accepted batch;
  register it as planned. No geometry algorithm was duplicated here.
- Electrical, power, SI, procurement, firmware and outputs: verification,
  design-rules, SPICE, BOM/procurement, constraints/manufacturing, firmware/docs
  and rendering families; the new SI policy closes the research-unit join.
- Governance/ledger/purity/docs/CLI: native accounting and producer accounting,
  C++/AST/precision audits, authoring-boundary work, doc consistency, command help,
  regression and RC smoke. Other owners' pending registrations remain necessary.

There are **no tracked `scripts/*.py` or `tools/*.py`** among the 393 files.
The earlier chir_rung/w11/w12/dump utilities have native experiment-tools and
observer contracts, but ignored/cloud duplicates are outside this census and
are not deletion targets. `testplan.py` and `verify/testpoints.py` are correctly
classified as production modules, not tests.

## Remaining actionable work (do not disguise as a missing whole core port)

1. **Small I2C cross-consumer join** — `test_downstream_i2c.py`.
   Firmware/test-plan address and collision mutants already exist in
   `firmware_docs_contracts.cpp:377` onward. Manufacturing checks exact original
   manifest bytes (`manufacturing_contracts.cpp:59`), but that is not a dedicated
   fresh `board_services`-only join. Add a native test feeding one freshly
   authored circuit to `bringup_id_eeprom_addr`, `testplan_i2c_devices` and the
   manufacturing manifest. Pin EEPROM 0x51 / RTC 0x52, AUX bus/conditional flags
   and part identity, then rewire straps and require all consumers to observe
   the same address. No new production algorithm appears needed.
2. **Same-project double-build acceptance** — `test_build_twice.py`.
   `board_live_contracts.cpp` genuinely does live extraction -> native placement
   -> exact PCB and reports, once for each project; it is not merely schematic
   coverage. It does not build the *same* project twice in one process, the old
   global-state/race contract. Parent should add/run that acceptance after the
   coherent full-board audit is green, comparing dimensions and complete emitted
   bytes, without suppressing any live gate. Separately retain the module's
   warning-only thermal-evidence mutation: raising
   `PcbEmitPolicy::thermal_credit_needs` must change the shortfall diagnostics
   while leaving PCB bytes identical. Native `pcb_embed.cpp:180` consumes that
   policy and copper-debt tests mutate provenance; neither alone proves this
   specific output/diagnostic separation.
3. **Official render-baseline policy** — `test_render_baseline.py`.
   New native model/render fixtures and real KiCad views do not reproduce the
   original tracked-artifact union against `origin/master`, approved FUSB302
   model-repair normalization, PCB digest and zero-distance golden aHash bar.
   Preserve that as a native artifact policy contract, or obtain explicit
   approval for a new baseline if the historical baseline has been superseded.
   Do not silently equate a successful renderer with passing this policy.

These are evidenced uncovered **test boundaries**, not evidence that their
production implementations are still Python. The SI gap below was the highest
independent, cheap-to-run policy gap that could close here without entering the
parent's full-board/render acceptance or another owner's production source.

Final retirement also requires parent integration/green native CTest and actual
native `check` acceptance; this batch does not claim those. CMake now rejects
`SCHGEN_BUILD_PYTHON=ON`. Python lint/pytest configuration and requirements still
need parent cleanup with deletion. Both `scripts/build_native.sh` and
`scripts/check.sh` are already deleted in the current working tree. CMake builds
only C++; the old option is solely a fatal compatibility guard, not a Python
build branch. Native regression/selftest/RC/CTest replace the old check driver.
The remaining `native/tests/run_authoring_contracts.sh` and
`run_component_basis_contracts.sh` are private worker build recipes, not unique
production behavior or CTest dependencies: their subsystem-authoring,
authoring-gates, component-basis and copper-debt executables are registered
natively. They can retire with the old orchestration; preserve the C++ sources,
fixtures, CTest registrations and recorded sanitizer proof instead.
Do **not** delete the whole `schgen/` directory: native symbols still read
`schgen/lib`, and board checks still read `schgen/verify/data/lcsc_values.json`
and `nc_allowlist.json`. Preserve or explicitly relocate those non-Python assets.

## New SI coverage and independent expectations

The existing constraints/manufacturing tests compare immutable output bytes and
exercise missing research/impedance errors. The missing layer was the full
repository research-unit policy joined across *fresh native authoring* and all
three native consumers, from `schgen/tests/test_si_units.py`.

The new contract authors all 37 carrier circuits through the real registry and
catalog. It reads actual `carrier/research/si_spec.json`; it never loads saved
circuit IR, PCB snapshots or generated golden outputs. Independent literal
expectations are transcribed from the original test, not generated by C++:

- FMC 5 mil / 0.127 mm; MIPI 20 / 0.508; BASE-T 50 / 1.27;
  HDMI 118 / 2.9972; USB 150 / 3.81, with ten exact cited-net examples.
- HDMI's 0.15 bit-period fraction is not a length; one `diff_pair` kind carries
  three distinct budgets, precluding a kind-wide default.
- Group policy reuses the conservative pair skew, and actual heterogeneous group
  construction takes the minimum; SD remains the explicit uncited 2.5 mm policy.
- Zero single-ended maximum length requires an explicit `n/a` note.
- All 148 emitted pair rows carry the researched length and citation; both
  halves appear in the SI model, and each pair's own DRU condition and Markdown
  row carry the same physical length. Empty SI output cannot pass vacuously.
- Missing research is rejected by the real CSV generator and SI gate; impedance
  drift fails the real gate. Changed live research reaches all three consumers.

**49 negative mutations** exercise the independent research and consumer checks,
including uniformly wrong units across otherwise self-consistent outputs,
citations, missing rows/halves, model population, per-kind collapse, SD policy,
group minimum and dimensionless/length confusion. Copied mutations never alter
the original inputs. A heterogeneous 4-mil live row is a positive parameter
control, not permission to change repository policy.

Original Python AST literal-spelling assertions are not recreated against C++.
Their semantic no-default policy is exercised here; native via-cost literal-bit
and structured physical-provenance contracts remain in board-policy migration
and native audits. This adds no production validator, geometry or quantization
implementation.

Independent source hashes (unchanged):

```text
2b66c0a7cf0abc6c26b706d9a2bda8dcb4903341691de618fd58de7b0a974aff  schgen/tests/test_si_units.py
185ce61dc07aac0f96cdf8cddd86c55dee61af7b0938f0a796473d6bf626a0a4  carrier/research/si_spec.json
```

## Parent registration

```cmake
add_executable(schgen_si_units_contracts tests/si_units_contracts.cpp)
target_link_libraries(schgen_si_units_contracts PRIVATE schgen_core)
target_compile_options(schgen_si_units_contracts PRIVATE
    -Wall -Wextra -Wpedantic -Werror -ffp-contract=off)
add_test(NAME native_si_units_contracts
    COMMAND schgen_si_units_contracts "${CMAKE_CURRENT_SOURCE_DIR}/..")
set_tests_properties(native_si_units_contracts PROPERTIES TIMEOUT 120)
```

Exactly one argument: repository/input-tree root. Requires the actual native
part catalog, project mapping/interface data and researched SI JSON. Missing
inputs fail; no skip, fixture-fallback, external process or repository write.

## Isolated proof / source freeze

- **212 assertions, 49 rejected mutations PASS** with strict C++17.
- Same counts PASS with **ASan + UBSan**, all 61 repository translation units
  in the actual link-map closure instrumented, no uninstrumented core archive
  in that sanitizer executable. System LibXml2/OS libraries remain system code;
  no LeakSanitizer claim on this macOS host.
- Both strict and sanitizer binaries also PASS against a private **246-file
  asset tree containing no `.py`, `.pyc` or `.so`**, with every canonical
  `circuit.json` deliberately invalid. That proves fresh native circuit
  provenance without deleting anything in the checkout.
- Current repository headers pass a separate strict `-fsyntax-only` check.

Proof directory: `/private/tmp/native-si-retirement.PuFQ4a`.
Executables: `si-strict`, `si-asan`; reproducible private `build-asan.sh` and
`strict.map` retained. Python-free poisoned input:
`/private/tmp/native-si-assets.LPr9ZJ`.

Strict linking used the accepted private frozen core archive from the previous
authoring/metadata proof, SHA-256
`e26211c85bc7434300e96d5f0be26db2fa71998f32aaf2ffdf26eda9e8832786`.
Sanitizer linking reused that proof's instrumented source snapshot objects and
compiled its additional constraints/manufacturing-SI closure privately. This is
not a claim to have rebuilt the concurrently edited shared authoring core;
parent's next coherent build remains the integration check.

Flags: `-std=c++17 -O1 -g -Wall -Wextra -Wpedantic -Werror -ffp-contract=off`;
sanitizer adds `-fsanitize=address,undefined -fno-omit-frame-pointer`.
Runtime: `ASAN_OPTIONS=abort_on_error=1 UBSAN_OPTIONS=halt_on_error=1`.

Frozen new test SHA-256:
`48429a6fcf695d773f3291e29629f5097d371935d42475dc75a9509fead23d4f`.
Inventory SHA-256:
`86679c056141c5e2899184036652fe2d9586ece0a6e4c79459453cacd5241b38`.

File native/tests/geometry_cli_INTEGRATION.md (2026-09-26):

# Native floorplan / compose CLI handoff

Owned new files only: `include/schgen/geometry_cli.hpp`, `src/geometry_cli.cpp`,
`tests/geometry_cli_contracts.cpp`, and `tests/data/geometry_cli/legacy_cli.json`.
No existing solver, gate, project loader, CLI, CMake, board pipeline, fixture or
generated project artifact is edited by this family.

## Parent integration

Add `src/geometry_cli.cpp` to `schgen_core` with C++17 and
`-Wall -Wextra -Wpedantic -Werror -ffp-contract=off`. It uses only existing native
core dependencies (board authoring, schematic extraction, board inputs, floorplan,
compose repair and full board pipeline). No new library or existing ABI change.

In `main.cpp`, include `schgen/geometry_cli.hpp` and dispatch **before**
`run_project_command`, whose leading `--repo`/`--project` handling would otherwise
claim geometry invocations:

```cpp
if (const auto status = schgen::run_geometry_command(argc, argv)) return *status;
```

Add main help entries for `floorplan [--export]` and
`compose [--measure | --repair [--dry-run] [--allow-intent NAME:FROM->TO] ...]`.
The new dispatcher owns command-specific parser/help. It throws normal exceptions
for the existing main error boundary, returns nullopt for other commands, and does
not need a module binding or modifications inside project_cli.

```cmake
add_executable(schgen_geometry_cli_contracts tests/geometry_cli_contracts.cpp)
target_link_libraries(schgen_geometry_cli_contracts PRIVATE schgen_core)
target_compile_options(schgen_geometry_cli_contracts PRIVATE
    -Wall -Wextra -Wpedantic -Werror -ffp-contract=off)
add_test(NAME native_geometry_cli_contracts COMMAND schgen_geometry_cli_contracts
    "${CMAKE_CURRENT_SOURCE_DIR}/.."
    --system-temp)
add_test(NAME native_geometry_cli_live_contracts COMMAND schgen_geometry_cli_contracts
    "${CMAKE_CURRENT_SOURCE_DIR}/.."
    --system-temp --live-kicad)
add_test(NAME native_geometry_cli_apply_contracts COMMAND schgen_geometry_cli_contracts
    "${CMAKE_CURRENT_SOURCE_DIR}/.."
    --system-temp --live-apply)
set_tests_properties(native_geometry_cli_live_contracts
    native_geometry_cli_apply_contracts PROPERTIES LABELS "live-kicad")
set_tests_properties(native_geometry_cli_apply_contracts PROPERTIES TIMEOUT 300)
```

Each invocation makes a unique child scratch directory; proof outputs are retained.
Use `--system-temp` for CTest, since native builds inside the repository are
correctly forbidden production geometry output roots. Explicit private scratch
parents outside the repository remain supported for independent runs.
Offline mode does not open a catalog or run KiCad. Live modes require the normal
already-built catalog, KiCad and installed symbol/footprint assets. The bounded
`--live-apply` negative proof requires real ngspice, selects the real KiCad executable
by absolute path, and deliberately makes the trusted audit compiler unavailable.
It verifies the actual compiler-spawn error is a mandatory failure and the edit is
rolled back. This is NOT full-board acceptance or a substitute for the parent's
future green source-audit/full-apply proof. Missing prerequisites in other modes
are failures, never successful skips. `--live-apply` includes the read-only tests.

## Production input and output contract

`load_geometry_board_inputs(paths, extraction)` is reusable by the parent's probe
CLI: replace its local author/link/private-schematic block with this function.
The caller must open and retain `paths.part_catalog_file`. The geometry command
does that itself. It returns a value-owned `PcbPlacementInput` after:

1. `author_board_pipeline_inputs(paths)` executes every registered native project
   factory. Native authoring validates the fresh IR; canonical circuit.json is NOT
   loaded as a circuit source.
2. Stable sheet bands are extended in memory, never written back.
3. Actual authored sheets are linked against selected SoM contract/mapping; invalid
   links throw before schematic emission.
4. `build_board_schematic` emits, extracts and gates a fresh hierarchy in a mode-700
   mkdtemp directory, with RAII cleanup on success and failure.
5. Its root is independently extracted, passed with the authored circuits/valid
   link to the existing `load_board_inputs`, and the extended bands are retained.

No cached schematic, netlist, placed board, fixture model or gate callback exists.
The existing loader supplies config, SoM outline, exact footprint documents,
contracts, signal specs, return-path dossiers and prior escape sidecar. No loader
field additions or schema changes are required. Floorplan uses the existing
zone/prepare/build/report APIs; compose uses the existing full placement builder.

Artifact root is `--output DIRECTORY`, default selected project:

- `floorplan`: `docs/FLOORPLAN.svg` and `docs/FLOORPLAN.md`.
- `floorplan --export`: `floorplan.json` only, derived from the CURRENT spec/inputs.
- `compose`: `reports/compose_ledger.json` and `.md`.
- `compose --repair` without dry-run: spec mutation is ALWAYS the selected
  **PROJECT/floorplan.json**, even with a separate artifact root. The existing
  driver performs optimistic concurrency checks and exact rollback. Full-board
  outputs go to the selected artifact root. This distinction is stated in help.

Output directories and individual destinations are preflighted before expensive
work and rechecked before publication. Symlinks, special files, hard-linked output
files, source-tree overlaps, ancestors of inputs and other project roots are
rejected. Full apply preflights the complete existing board output tree. Output
replacement is explicit, individually atomic, not an all-files transaction. Failed
repairs restore the spec, NOT artifacts already emitted by the full board pipeline.

The fixed apply host calls `run_board_pipeline` with `native_policy=true`, no
blessing, no supplied declarations/verdicts, no conditional mandatory-gate bypass.
`--no-render` has the same optional-render meaning as the existing board command
and is valid only for apply. In-place board generation retains the existing common
carrier fanout ratchet behavior; isolated output preserves that source baseline.
The common in-place ratchet path is also preflighted and disclosed in help.

## Legacy semantics / explicit native differences

Original `cmd_floorplan`, nested `_cmd_compose`, parser registration and existing
native compose driver were inspected before implementation. The unmodified old
compose argparse registration was independently AST-executed for eleven cases.
Reference SHA-256:
`e2ae44430d9e1b471d27f952453642cbe77653c4df20a7c4143a93e2c9453911`.

Preserved: default measure; repair wins over measure; dry-run records ledgers but
does not apply; repeated intent order; intent/dry-run flags are inert without
repair; max-steps remains reserved (ONE selected edit); original terminal floorplan
notices; current-plan export; advisory floors trigger repairs but do not become hard
gates. The existing independent compose fixtures/contracts retain edit, prediction,
ranking, measurement, acceptance, concurrent-edit and rollback coverage unchanged.

Explicit native parser differences: duplicates (except repeatable intent/help),
unknown/cross-command options and empty values reject; max-steps is a checked signed
32-bit decimal token (no overflow, Python underscore/Unicode numeral coercion).
Help works without project/catalog/KiCad inputs. Printed artifact paths are absolute
so private `--output` roots remain usable outside the repository. Fresh private
schematic gating is stricter than relying on the old previously built schematic.

## Proof checkpoint

Strict isolated compilation passed against a private copy of the parent's coherent
fast archive (precision + bulk process update), SHA-256
`22d1dcf3745f89d87da370f93228d4b33118ccb313595aa5993cb92a953dab6b`.
No shared build or artifact regeneration was invoked.

Offline: **182 assertions PASS**. Live render/export/measure/dry-run passed with all
canonical circuit JSON and cached schematic/PCB/netlist inputs poisoned, preserving
all source bytes. A live advisory-contract mutation produces six eligible ranked
repair candidates; no fixture model or predicted verdict is used as board proof.

The two old-archive, unbounded source-audit runs were terminated (private scratch
only); neither is claimed as successful proof. The coherent-archive bounded live
suite completed: **935 assertions PASS**, including both real full-pipeline negative
runs, missing trusted-compiler hard failures, exact spec rollback, unchanged source
and shared baseline bytes, and retained failed-board artifacts. This is negative
rollback proof, NOT positive full-board acceptance. Positive apply remains with the
parent after its complete source audit is green.

Proof directory:
`/private/tmp/geometry-cli.aNcCw8/current-proof/geometry-contracts-fqGz5h`.
The executable was `contracts-current` in that same private family root. Offline
mode also passed all 182 assertions with `PATH=/nonexistent`. Independent carrier
measurement passed at 168x163 mm and retained both real advisory triggers.

**Geometry source/header/tests are frozen for parent integration.** No further
shared-source work or builds were performed; old private evidence is preserved.

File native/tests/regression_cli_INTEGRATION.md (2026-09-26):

# Native regression command handoff

The original regression family is integrated by the parent at `ae8a3978`.
This follow-up owns only `src/regression_cli.cpp`, its CLI contracts and this
handoff. The header and RC smoke are unchanged.
No CMake/main/project CLI changes, shared builds, commits, or full-board runs
were performed. Complete board-command acceptance remains pending the parent's
board audit being green; the process-double tests are not that acceptance.

## Parent integration

Add `src/regression_cli.cpp` to `schgen_core` (uses existing `json`, `process`
and public LibXml2 linkage). Include `schgen/regression_cli.hpp` in main, and
dispatch **before** `run_project_command`, which claims leading `--repo` and
`--project` options:

```cpp
if (const auto status = schgen::run_regression_command(argc, argv))
    return *status;
```

Advertise `check --tests-dir BUILD [--repo ROOT] [--project NAME_OR_PATH]
[-o DIRECTORY]`. `check --help` already has command-specific help without
opening catalogs, configuring/building anything, spawning children, or writing.

Add these targets/tests using the existing strict flags and core linkage:

```cmake
foreach(family regression_cli regression_rc_smoke)
    add_executable(schgen_${family}_contracts tests/${family}_contracts.cpp)
    target_link_libraries(schgen_${family}_contracts PRIVATE schgen_core)
    target_compile_options(schgen_${family}_contracts PRIVATE
        -Wall -Wextra -Wpedantic -Werror -ffp-contract=off)
endforeach()
add_test(NAME native_regression_cli_contracts
    COMMAND schgen_regression_cli_contracts "${CMAKE_COMMAND}" "${CMAKE_CTEST_COMMAND}")
set_tests_properties(native_regression_cli_contracts PROPERTIES TIMEOUT 120)
add_test(NAME native_regression_rc_smoke
    COMMAND schgen_regression_rc_smoke_contracts "${CMAKE_CURRENT_SOURCE_DIR}/..")
set_tests_properties(native_regression_rc_smoke PROPERTIES
    TIMEOUT 120 LABELS "live-kicad")
```

Do not conditionally omit the RC smoke when KiCad is absent. It is a required
live gate, not a success-by-skip fixture. It accepts `--kicad-cli PATH` after
ROOT if the parent needs to pin the CTest executable configuration.

The regression driver requires these named live/RC entries in the build's
inventory, all enabled and with built executables:

- `native_regression_rc_smoke`
- `native_selftest_full_contracts`
- `native_board_live_contracts`
- `native_board_pipeline_live_contracts`
- `native_render_models_live_contracts`
- `native_example_devkit_live_contracts`
- `native_single_sheet_live`

These are minimum coverage anchors, **not a filter**. Every other test in the
selected configured native build also runs. Adding new contracts needs no driver
change. Missing conditional selftest registration is an explicit preflight
failure, not an excuse to reduce the bar. Configure and build the entire native
suite before invoking `check`; this command never builds it itself.

## Command behavior and evidence

```text
schgen check --tests-dir /absolute/native-build --repo /absolute/repo \
  --project devkit_mini --output /private/tmp/regression-results --timeout 3600
```

The driver creates a unique `regression-XXXXXX` directory under the requested
output parent, or under system temporary storage by default. It never deletes
that evidence or overwrites an older run. Native board output is directed into
its `board/`; native selftest receives `--keep` and writes `selftest.txt` there.
Child commands are the resolved actual `argv[0]`, not a guessed `native/bin`
path. `--repo` becomes the child working directory; project strings remain
literal arguments. Board is not given `--no-render`, selected subsystem names,
or any audit/gate bypass. CTest uses its own configured KiCad paths; a supplied
`--kicad-cli` is forwarded to board and selftest only, as the help states.

Before board publication, CTest's real `--show-only=json-v1` inventory must be
nonempty, its cache must name exactly canonical `ROOT/native` or `ROOT/native/ci`
with `BUILD_TESTING` enabled and `SCHGEN_BUILD_PYTHON=OFF`, every
entry must have a built executable, and no entry may be disabled or directly
invoke a shell/Python interpreter. All configured tests run serially, with
`--stop-on-failure --output-on-failure --no-tests=error`, no regex/label filters,
and an explicit JUnit path. A zero CTest exit alone is insufficient: the JUnit
must contain every inventoried name exactly once, all actually run and passing,
with no skipped/disabled/errors/failures. Missing/malformed/DTD/incorrect result
documents fail. The command does not parse human `PASS` tokens as evidence.

### Direct and local wrapper build policy

Both entry points are supported; the wrapper is a **local-only** CTest workflow,
not authorization for repository CI automation. No configure/build is performed
by `check`, and no new dependency or shared integration change is needed here.
Both roots require the literal explicit cache value `SCHGEN_BUILD_PYTHON=OFF`:
missing, empty, `ON`, `TRUE`, `1`, and alternative false spellings such as `FALSE`
or `0` reject. Duplicate cache keys reject instead of silently choosing a value.
Canonical source/repository/build aliases work. Other repositories, sibling or
nested source roots (including `native/ci/smoke`) are not accepted.

Wrapper builds require these six additional minimum inventory anchors:

- `native_ci_cache`
- `native_ci_environment`
- `native_ci_cli`
- `native_ci_smoke_contracts`
- `native_ci_bootstrap_rejections`
- `native_ci_smoke_reject_arguments`

All ordinary live/RC anchors remain mandatory. Every wrapper and engine test
runs, including extras beyond the anchors; nothing is filtered. Point
`--tests-dir` at the wrapper's **top-level build directory**, not its `engine/`
subdirectory, which lacks the top-level cache and wrapper checks.

Stage order remains board, selftest, then full CTest. Wrapper fixture setup
checks run during that final CTest stage, before dependent engine tests, **not**
before the standalone board/selftest commands. Their failures and skips cannot
produce a successful regression result. The cache policy checks build settings;
it is not a claim to intercept arbitrary child behavior or inspect every linked
library for Python symbols.

Stage order is board, selftest, then all CTest contracts (including RC smoke).
Child nonzero exits stop immediately and propagate. Signals return `128+signal`,
timeouts return 124, launch errors return 126/127, invalid inputs/evidence return
2. The per-stage wall-clock timeout is positive integer seconds 1..86400,
default 3600; inventory is capped at 30 seconds. CTest receives the same default
per-test timeout and also has the independent whole-process bound. Process
groups are killed and reaped on timeout. `--config` is forwarded to both CTest
inventory and execution. There is no production runner-injection API.

Each stage retains exact binary stdout/stderr files (including partial output
on timeout), length-prefixed argv, and exit/timeout/signal status. Console output
is replayed while running; the raw files are authoritative and untruncated.
`result.txt` is created only after all child stages and JUnit verification pass.
CTest's own build-directory logs and the unique run's `ctest-results.xml` remain.

## Independent contracts and isolated proof

Strict flags: C++17, `-Wall -Wextra -Wpedantic -Werror -ffp-contract=off`.
ASan/UBSan also use `-fsanitize=address,undefined -fno-omit-frame-pointer`.
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

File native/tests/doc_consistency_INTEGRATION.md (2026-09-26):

# Native authored-document consistency: stable handoff

New files only: `include/schgen/doc_consistency.hpp`, `src/doc_consistency.cpp`,
`tests/doc_consistency_contracts.cpp`, and
`tests/data/doc_consistency/python_reference.json`. No existing firmware, power,
sequence, model, CMake, CLI, registry, document, or shared binary was edited.

Production read-only path:

```cpp
const auto input = schgen::load_doc_consistency_input(paths);
const auto result = schgen::check_doc_consistency(input);
// result.ok(), issues with original test-family names, observed rails/sheets.
```
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

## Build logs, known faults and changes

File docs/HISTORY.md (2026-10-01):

# carrier — project HISTORY (archived planning logs)

## 2026-10-01 — clean C++ migration acceptance

Completed isolated fresh Release compilation and sequential full-render board
acceptance at `29d43472`, without bypassing mandatory gates or blessing golden
drift. Compilation took 132.17 s (two workers, no compiler/object cache, existing
zlib-ng dependency). Carrier passed all mandatory gates in 326.69 s and devkit
in 275.11 s; source/ledger audits both pass with 155 registered transforms.
All 226 tests have successful final coverage as detailed below. No tracked
Python source remains. Required hardware formats and historical reference data
are retained. See the new migration-acceptance benchmark receipt; the older
failed-build receipt is preserved without relabeling its results.

Against the requested Python revision `0e9bbc913bab77f9cd228940db2a332d25d6bfa1`,
carrier wall time decreases 56.87%; devkit increases 255.95%. These are complete
revision workloads, not isolated language speedups: the Python devkit fails its
design gates and native runs stronger mandatory source audits. Native auditing
alone takes 218.84/206.34 s. No claim is made that the queue change reduced
whole-board wall time. Both boards retain advisory return-path, golden-render
drift and contract-coverage findings, plus 499/413 unrouted connections. They
are not fabrication-ready. Generated evidence is preserved in the managed
`migration-acceptance` worktree; private raw logs are not published.

## 2026-10-01 — complete rendered baseline comparison

Integrated the remaining Plain18/Grid6 precision boundaries (autonomous, per
full-autonomy directive). Combined source proof closes all original 14/34/16
reported sites, checks 155 registrations and rejects all 33 missing-registration
mutations. Independent board output remains byte-identical to its immutable
3,450,788-byte reference. The private combined batch passed 28 contracts; parent
all-target compilation also passed. An older projection test now initializes the
new line index while retaining explicit frozen-visitor compatibility. Two exact
partitioner identities were updated for their new accounting parameter, without
changing authoring roles or weakening closure checks. Compose ledger measurement
can now expose invocation-owned counts for its three final-model measurement
calls, including initial/rebuilt driver measurements; this is not an assertion
that those counts include candidate planning or the entire CLI.

Parent full validation ran all 226 CTests, including ten live-KiCad tests:
222 passed, four failed (1019.07 seconds, two workers). The failures were traced
to three older accounting harnesses and a hardcoded scaffold build-cache path.
Corrections preserve complete map/output comparisons: assert two ledger calls
then one per-net call; replay the actual final escape stage; apply only the
independently proven two-entry correction to complete legalization plan/aggregate
fixture views; pass the owning build cache explicitly. All four corrected tests
then passed in 49.76 seconds with no production-engine changes between runs.
Thus all 226 tests have successful final coverage, not one claimed 226/226 run.
Existing reference files remain unchanged. Three documented XML fixtures omitted
by the blanket ignore rule are now included unchanged; their README distinguishes
current packaging fingerprints from unavailable historical capture hashes.
Complete rendered board acceptance and new timings remain the next gate.

Integrated invocation-owned schematic and failed-model accounting (autonomous,
per full-autonomy directive). Schematic retries and shared geometry helpers now
record actual grid calls; independent traces and complete schematic bytes match
for all 49 sheets (3,442 sheet-placement entries, not the whole-board total).
Model failures retain executed prefixes through stage, floorplan and placement
ownership boundaries. Independent review found and corrected constructor-seed
loss and partial publication after merge overflow; unavailable receipts now
propagate explicitly instead of appearing complete. Parent failure, schematic
and board-pipeline contracts passed 3/3 in 58.17 seconds. No reference fixtures
were regenerated. Project-aware title blocks correct devkit branding while
preserving carrier output; the private title/render proof covers all 12 devkit
sheets and two carrier sheets. Broader combined acceptance remains pending.
Current build/import/scaffold documentation now uses implemented native commands;
historical examples are distinguished from current instructions.

Optimized cold source auditing (autonomous, per full-autonomy directive): a
bounded dynamic queue replaces fixed worker batches, and each source file's
newline offsets are indexed once. All manifest entries are still scanned;
census publication and error selection retain manifest order, with workers
joined before return. There is no cache, skipped validation or changed detector.
An immutable copy of the prior auditor provides independent exact serial and
parallel comparisons, including malformed input, timeouts, source mutations,
line boundaries and a scheduling regression that rejects the old batch barrier.
The integrated queue proof passed (13.96 seconds), followed by the existing
parallel/auditor contracts (2/2, 29.13 seconds). Full-board speedup is not yet
measured; these tests do not establish whole-board migration acceptance.

After the pinned benchmark, corrected two accounting defects (autonomous,
per full-autonomy directive): `ledger_initial` now records its two actual
via-cost scalar executions, and packing executes the registered tolerance
function rather than counting an event while passing a copied literal.
Independent function-entry instrumentation verifies both, including counter
overflow and retained prefixes. Five integrated accounting/floorplan/packing/
geometry/output tests passed in 78.71 seconds. Historical fixture files are
unchanged; full-output comparisons adjust only the independently verified
two-entry receipt correction and reject missing/typo entries. This is not
closure of the remaining source-policy findings or full-board acceptance.
The same bounded receipt correction was then applied to the older placement,
stage, precision-accounting, connector and floorplan comparison harnesses;
all five passed (95.21 seconds), with every historical data file preserved.

Integrated Search9 (autonomous, per full-autonomy directive): nine genuine
scalar boundaries close the fourteen fallback-via/seat-band source findings,
with checked narrowing, allocation products, inclusive endpoints and recursion
depth. Invocation receipts include rejected trials and recursive work. The
private exact-base integration passed 25 tests, including source mutations,
UBSan and frozen compatibility. Parent full two-board output/negative contracts
passed in 18.91 seconds with the separate two-entry ledger correction retained.
The three newly imported independent fixture hashes match their original proof
artifacts; no existing fixture was changed. Registry cardinality is now 131.
Fifty other reported sites remain assigned to the next two integration batches;
this is not a claim of combined whole-board acceptance.

Measured pinned C++ `1ad3a40a85e98d481e22f00bdeacac86582c4356` against the
owner's sole Python baseline `0e9bbc913bab77f9cd228940db2a332d25d6bfa1`,
in isolated source checkouts (autonomous, per full-autonomy directive).
All four commands ran sequentially with full renders and mandatory checks;
agent builds/tests were paused. C++ carrier/devkit took 323.79/273.73 seconds;
Python carrier/devkit took 757.53/77.29 seconds. Changes are -57.26%/+254.16%,
respectively. Fresh Release CLI compilation was 115.80 seconds separately,
with two jobs and an existing zlib-ng dependency, not included per board.

These are revision/workload comparisons, not same-input language speedups.
Python carrier passed; Python devkit retained its test-point/design failures.
Both C++ commands completed their renders but failed quantize_census/ledger:
the same 64 unregistered sites, with 122 registered transforms. Their source
audits took 215.354667/217.499183 seconds. No checks were bypassed or goldens
blessed. All 65 expected PNGs per implementation were freshly regenerated;
49 native schematic pages were visually inspected at whole-page scale.
Native DRC reported zero non-unrouted errors, but 499/413 unrouted connections
remain; this is not fabrication-ready PCB approval. Devkit title-block
branding was flagged for correction, not silently accepted.

Full provenance, raw-log hashes, paths and limitations are recorded in
`native/benchmarks/2026-10-01-full-render.json`. Later migration fixes are not
represented by this pinned benchmark.

## 2026-09-27 — rendered verification and truthful DRC process diagnostics

Applied improvements (autonomous, per full-autonomy directive): the 39 output,
pack and geometry scalar counter keys now reuse immutable strings inside the
counted branch. Private warmed-call measurement fell from 37,000 allocations
to zero while exact results and observed receipts matched; this is not a board
wall-time speedup claim. Integrated CLI/target builds and nine runtime/source
contracts passed (122.18 seconds).

Schematic generation now wraps long worksheet titles without altering circuit
intent and separates wrapped capacitor buses from preceding ground artwork.
Original historical fixtures remain unchanged; three named corrected states
are checked in full against independent rigid-row/contact invariants and
mutation rejection. Eleven integrated schematic tests passed (8.80 seconds),
including actual title rendering. Fresh shared-executable carrier builds for
bringup_en_modules, fmc and mechanical passed connectivity, netlist, ERC and
visual gates; their PNGs were inspected. Private nine-sheet proof is additional
coverage, not whole-board acceptance. No golden-render baselines were blessed.

Output/packing/geometry integration (autonomous, per full-autonomy directive):
39 additional exact scalar boundaries and invocation-owned receipts advance
the registry from 83 to 122. Emission, publication, ratsnest, packing and geometry
consumers preserve independently captured output/board fixtures and old counts;
new actual-entry observers verify the additional work, including failure prefixes.
No broad source exemption or unknown-counter filtering is introduced. Four new
reference files are copied verbatim from independently captured pre-change runs.

Review also corrected valid fractional integer endpoints in SVG narrowing and
prevented an import failure from being retried and masking its original error.
The full integrated build exposed four old test calls missing the explicit
geometry accounting sink; those now pass a local sink without changing assertions.
The rebuilt combined implementation passed all 25 selected runtime, source-audit,
registry, pipeline and numeric checks (412.44 seconds, serial). An earlier
108-operation integration separately passed 18 runtime checks (226.78 seconds).
These are bounded integration proofs, not a claim that every remaining live
board audit finding or reported visual/manufacturing defect is closed.

Exact numeric kernel correction (autonomous, per full-autonomy directive):
binary64 significands are decoded exactly rather than recovered with floating
rounding/conversion, and the tiny-input norm uses a restoring integer square
root. This removes internal audit findings through exact arithmetic, not new
registry exemptions. Decimal ties-to-even, supported digit range/cap, errors,
signed zero, nonfinite behavior and existing corrected norm values are retained.
Private proof passed 4.5 million rounding parity cases, 250,000 norm parity
cases, independent MPFR oracles and sanitizers. The integrated CLI build plus
numeric, occupancy-precision, placement-search and full placement contracts all
pass (four tests, 53.18 seconds). Whole-board/source-manifest acceptance remains
pending; the earlier rendered images are still explicitly from 372f9563.

Autonomous, per full-autonomy directive: rendered both boards from 372f9563
without overwriting tracked generated artifacts. Carrier took 321.72 seconds
and devkit 273.85 seconds, with rendering enabled; these are not comparable to
the earlier no-render timing rows. Both full runs failed source accounting and
ledger acceptance, plus a sandbox-only KiCad DRC crash. All 49 sheets passed
automated netlist/ERC/visual checks and all sixteen 3D views were produced.
Manual image inspection nevertheless found title-block overflow and a visual
supply-bus/ground-symbol contact; these remain open, not blessed golden changes.

The same independent KiCad checks outside the sandbox returned zero
non-unrouted errors for both boards, but carrier has 197 warnings and 499
unrouted connections; devkit has 59 warnings and 413 unrouted connections.
These are layout starting points, not fabrication-ready routed boards.

DRC report loading now checks the child exit status before opening its output,
preserving crash status/stdout/stderr instead of hiding them behind a missing
report error. Pipeline and standalone CLI use the same loader. Regression
contracts cover failed children, absent/malformed reports, successful reads and
stale reports after failure. Native build and DRC contracts pass; both actual
generated boards were checked through the rebuilt CLI outside the sandbox.
No DRC severity, acceptance predicate, or source-audit requirement was weakened.

## 2026-09-26 — tracked Python retirement (acceptance in progress)

Placement and allocation batch (autonomous, per full-autonomy directive):
nineteen placement scalar boundaries now have explicit invocation-owned
accounting and exact registry entries (64 -> 83). Original geometry, legacy
counts and output fixtures are retained; rejected eviction and duplicate shape
work is independently counted. Scalar keys reuse immutable strings rather than
allocating a temporary string on every recorded call. The full shared build,
fourteen placement/compatibility contracts and two real-source audit contracts
pass on the integrated snapshot. This is not whole-board acceptance.

Occupancy now reuses one empty failed-bucket vector's capacity per search,
without retaining coordinates/results or changing traversal, sorting or checks.
Private allocation instrumentation measured carrier calls to allocation falling
from 32,422,620 to 8,295,528 (74.41% fewer); four variant outputs and ordered
traversal remain identical. Current integrated occupancy and full placement
contracts also pass. This allocation result is not a measured runtime speedup.

Owner baseline correction: the sole performance comparison baseline is now
`0e9bbc913bab77f9cd228940db2a332d25d6bfa1`. Previous `4bd47c33` measurements
are historical observations only, not the requested comparison. The exact
baseline is run unchanged in a separate managed worktree, without later native
extensions or copied design inputs. See native/benchmarks/BASELINE.md.

Combined integration (autonomous, per full-autonomy directive): seven legalizer and seventeen PCB
stage scalar boundaries now retain their actual invocation accounting, including
rejected trials, with immutable prior geometry/output evidence. Eleven supplied
buried-constant findings are addressed by nine real policy owners and removal
of two unused aggregate defaults; existing physical values are retained. The
source registry contains 64 exact scalar declarations. Numerical corrections
remove undefined outline narrowing and fix subnormal norm double-rounding and
finite-overflow facing angles. The integrated numeric tests, sanitizers and
MPFR oracle pass; the first combined production build and seven focused
math/policy tests passed. The final combined build and eleven serial contracts
now pass, including full authoring closure/census, C++ auditor, board policy,
independently observed legalizer/stage/occupancy counters, pipeline timing and
Python-free tree. Wider placement/floorplan/producer/migration/numeric checks
also passed. An initial census correctly rejected a concurrent source edit;
two compiler subprocesses timed out under concurrent load. All three checks
passed on the final frozen source with serial execution and unchanged limits.
Whole-board acceptance remains outstanding.
No whole-migration acceptance or runtime speedup is inferred from those checks.

Frontier accounting optimization (autonomous): bind the actual map node lazily
within one place_near invocation, retaining one real scalar function and exact
overflow/error/counter semantics. This removes repeated map lookups from the
carrier's 142,413,444 frontier operations without changing candidate traversal.
Four private placement variants retain byte-exact output and prior accounting;
the integrated occupancy contracts pass. Seven legalizer and seventeen stage
counter keys use immutable strings; stage vectors reserve known capacities.
No isolated speedup is claimed for these changes yet.

Timing reliability (autonomous): exclusive nested scopes now separate actual
source/authoring audits from generation and mixed validation stages. Timers
cannot be copied/moved; early closure or destruction of a parent safely unlinks
it without interrupting its child or resuming a dead scope. Fake-clock contracts
cover nesting, repeated closure, exceptions, disabled timing and early parent
destruction; the standalone suite passes ASan/UBSan. Full process time remains
distinct from the reported pipeline scope, which excludes final summary writes.

Allocation reduction (autonomous, per full-autonomy directive): retain three
immutable occupancy counter key strings instead of allocating them per call;
counts remain invocation-owned with unchanged overflow behavior. The AST parser
stores the first eight decoded duplicate-check keys inline and spills wider
objects without dropping checks or fields. Private exact four-board output and
counter comparisons and complete real-AST projection/census comparisons pass.
Private profiling removed 142,503,424 carrier allocations and 56.52% of parser
allocations; wall observations were shared-machine, not isolated speed claims.
The integrated full build and five focused CTests passed (33.42 s), covering
placement, occupancy accounting, parser validation, census and parallel audits.
The devkit Python baseline completed at 20.78 s (PASS, 12 sheets), versus the
earlier C++ 395.91 s source-audit-failing baseline. Both-board comparisons now
have measured Python observations, not approximate README estimates. The C++
baseline predates current optimization work; no end-to-end speed-up is claimed.

Bounded audit parallelism (autonomous): the source audit now defaults to two
independent translation-unit workers, with an explicit supported range of one
to four. It validates the manifest first, preserves manifest ordering and all
duplicate census tuples, and propagates compiler/parser/timeout failures without
returning a partial census. Futures are joined before captured inputs expire.
The full 57-file ordered census matched the frozen pre-change serial scanner
byte-for-byte. Observed wall time was 417.81 s serial versus 330.50 s parallel;
other agent work was active, so this is not an isolated performance benchmark.
Four integrated audit/policy tests passed (37.70 s), including macro ordering,
partial final batches, error precedence and worker timeout. No detector, source
scope, policy cover, required gate or cache validity rule was relaxed.

Occupancy precision accounting (autonomous): six actual scalar operations now
own component/reach precision, frontier/shape ranking and bucket/axis narrowing.
Invocation-owned counters flow explicitly through copies, rejected searches,
refinement and every floorplan packing trial; geometry stores no accounting
sink. The registry now has 40 operations, and the reviewed source manifest adds
the real implementation file. Invalid cell conversion precedes single-rectangle
mutation; inclusive bucket loops use wide counters to avoid INT_MAX overflow.
Ten focused CTests passed (383.79 s), including independent function-entry counts
on carrier, devkit, single-side and fixed-outline paths, immutable prior output
and counter fixtures, source audits, replay and ownership checks. Historical
fixture files were not regenerated. This is not whole-board gate closure: the
remaining source-policy findings and full native acceptance are still pending.
Clang's test-only post-inlining instrumentation reduced the same independent
occupancy proof from 284.41 s to 23.96 s; all assertions passed again. External
operation calls remain in separate translation units. This measures test
instrumentation overhead, not a production board-generation speed-up.

Silk spatial-index correction (autonomous): reject nonfinite/nonpositive cell
sizes and unordered/nonfinite/out-of-range boxes before insertion. Check the
floating-to-integer cell conversion, use wide inclusive loop counters at
INT_MAX, and remove the unused member default (the explicit constructor always
owns the supplied cell size). The original implementation fails the new NaN
constructor regression. Private strict and ASan/UBSan/float-cast-overflow runs
pass the new boundary tests and all 181 unchanged silk-oracle fields. Sanitizer
coverage here is the changed pack translation unit plus test, not every core
archive object. Fresh devkit timing observations, including the still-failing
mandatory source audits, are recorded in `native/benchmarks/2026-09-26-cutover.json`.
Integrated verification: all five focused CTests passed (29.15 s): pack silk,
live board, PCB placement, placement gates and PCB emission. The matched carrier
run also passed its sheet, electrical and geometry gates; quantization/ledger
audits still failed. This fix is not full migration acceptance.

Native acceptance update: all 184 existing CTests passed after Python retirement
(587.00 s), including live KiCad, source closure and complete source census.
The added Python-free-tree CTest passed separately and its hidden-source
negative fixture failed as intended. Public package gate/result defaults now
select native assets, with explicit legacy-only fixture dispatch and new
empty/missing/default-mode regressions. Six actual floorplan rounding operations
now carry invocation-owned accounting; independent function-entry observation
verifies new counts while preserving all 83 policy rows, complete plan/ledger
bytes and prior counters. Seven affected integration tests passed. This does
not waive the still-open complete board source-policy audit.

Autonomous, per full-autonomy directive: removed all 393 inventoried tracked
Python files after validating each original SHA-256 and accepting the remaining
native SI-unit, downstream-I2C, repeated-build/thermal and committed-render
regression replacements. Removed Python requirements, pytest/lint configuration
and pre-commit Python hooks. Hardware assets and independent fixtures remain.
Deleted tracked content is recoverable from Git. The complete native suite is
being rerun against the retired tree; this is not full-board acceptance or a
claim of complete migration. The unused ignored virtual environment, compiled
Python extension and two sync-copy tests were moved recoverably outside the
repository to `/private/tmp/zynq-retired-python.iyilwa`; the subsequent tree scan
found no `.py` files (including ignored/hidden files, excluding Git internals).
Fixed pipeline exception classification: a child gate verdict is not proof
that its parent stage completed. Both ordinary and live pipeline tests pass.
Follow-up cleanup deleted generated Python bytecode directories, pytest/Ruff
caches, the unused Python-enabled Make/CMake build metadata and nanobind archive.
These ignored caches are not recoverable from Git; they contained no source
of truth. Active `native/build/fast`, compiler cache and native dependencies
were retained. A C++ working-tree test now rejects reintroduced Python source,
bytecode and retired dependency configuration, including hidden/ignored paths.
The root README now documents native commands rather than retired Python entry
points; historical independent parity fixtures remain as regression evidence.

This is the **archive** of the hand-written planning / decision / run logs that
drove the carrier rebuild. The content below is preserved verbatim under dated
section headers; it is no longer the living source of truth, but it is the
durable record of *why* the design is the way it is.

For the **current** state, read instead:

- [`carrier/README.md`](README.md) — the carrier's architecture, the
  subsystem/adapter pattern, the dossier index, the build/gate process.
- [root `README.md`](../README.md) — the three layers + how to generate.
- [`schgen/DESIGN.md`](../schgen/DESIGN.md) — the engine architecture contract.
- [`carrier/subsystems/README.md`](subsystems/README.md) — authoring an adapter.
- [`subsystems/README.md`](../subsystems/README.md) — the reusable library index.
- [`WORKING_GUIDELINES.txt`](../WORKING_GUIDELINES.txt) — the living
  human-readable rules/process contract (kept in place, not archived).

The still-true distillation of the locked design decisions and process
discipline has been folded into the READMEs above; everything below is the
full original log for audit.

---

# 2026-09-26 — Native CLI cutover and strict local regression

Implementation decisions (autonomous, per full-autonomy directive):

- Expose existing composition, drawing and escape constants through their
  actual shared C++ storage and additive ledger provenance, preserving literal
  values and output. Correct the compiler auditor's numeric JSON character-zero
  handling; nonzero and immutable character policies remain audited.
- Retire the unused Python extension source, 27 binding headers and two
  binding-only compile probes after native replacement contracts. Remove the
  CMake Python/nanobind discovery/download path; the old option now rejects ON
  explicitly. Preserve Git history and independent reference fixtures.
- Retire the obsolete staged Python-source audit parser and its build/test
  helper only after reference inspection, retaining a recoverable external
  backup of all five files. Preserve native integer/fallback/ledger-state code
  and immutable fixtures. Move the uncompiled, ignored old `circuit 2.cpp`
  sync copy outside the source tree with its SHA-256 verified; do not hide it
  from the compiler census through an exemption.
- Retire the five tracked Python experiment scripts only after native contracts
  and actual CLI checks. W12 probes use fresh native authoring and real KiCad
  extraction in private scratch; native dump publication reproduces all 49
  carrier/devkit circuit files without content changes. The local sync duplicate
  was byte-identical and backed up outside the repository before removal.
- Native `check` runs complete board generation, mutation/determinism selftest,
  and every configured CTest. Require nonempty enabled/built inventories and
  matching JUnit results, rejecting skips and fabricated PASS text. Retain logs
  and propagate failures/timeouts. Independent driver tests are not substitutes
  for final full-board acceptance.
- Add native authored-document validation with independent mutation fixtures,
  and a real KiCad RC smoke test that distinguishes open/short faults from an
  ERC-only undriven fault. Keep the source-audit and Python-removal goal open
  until the clean native path passes all required checks.
- Keep all checks local under the standing no-hosted-CI directive. Discard an
  uncommitted agent-proposed manual GitHub workflow; retain only the local
  native build/preflight wrapper. No hosted workflow was installed or run.
- The owner's current instructions supersede the old Python-only design-source
  convention and three-agent ceiling: tooling and tests migrate to C++, required
  hardware formats remain, and at most five agents work concurrently. Verified
  commits stay on the existing `perf-native` branch; no history rewrite.

---

# 2026-09-18 — Native schematic stages and devkit electrical corrections

Implementation decisions (autonomous, per full-autonomy directive):

- Migrate complete symbol-loading, routing, schematic-emission and visual-gate
  stages into the independently buildable C++ core, retaining only temporary
  interpreter transport for the not-yet-migrated board orchestration. Frozen
  data fixtures, mutation tests and real KiCad extraction remain the proof;
  replacing a Python reference with an alias to C++ is not a parity test.
- Preserve symbol-library snapshots through copy/deepcopy, including independent
  mutable adapter metadata. File changes must not silently alter an existing
  library. Preserve expression grouping where floating-point rounding affects
  pin positions and generated bytes.
- Add the devkit's absent STM32 I2C2 pull-ups to always-on +3V3_SC on debug_boot
  (two 4.7k 0603 C23162 parts, 1.5 mA budget). Add nine physical probe pads on
  debug_boot, power_mon and power; retain existing waivers unchanged. SDIO probe
  ports retain the SoM's 1.8 V domain. Verify I2C rise time during hardware bring-up.
- Probe-only ports require hierarchical labels: a locally correct sheet is not
  proof of a connected board. Add an actual two-sheet KiCad regression. Probe
  pads are observers, not regulator stages. Connector-sheet auxiliaries belong
  in the normal PCB packing path, while DF40 geometry remains fixed; placement
  exceptions must unwind the build ledger.
- Move complete netlist verification into C++, sharing the hardened KiCad
  process/XML boundary with SoM extraction. Preserve frozen reference reports
  first, then independently correct the legacy missing-part exemption: a part
  with any declared netted pin cannot be excused merely because another pin is
  NC. A regression reproduced the false PASS before the correction; NC-only
  components remain exempt. Index NC/netted references once instead of scanning
  every NC declaration for every part.
- Move the five design-rule checks, probe coverage and report formatting into
  C++, including standalone `design-rules` and `testpoints` commands. Index
  connectivity and resolve each unique symbol once per immutable snapshot.
  Retain finding/waiver order and byte-identical reports; use real pull-up/probe
  removal mutations to prove failures remain failures. Propagate cancellation,
  allocation and system failures instead of treating them as unresolved symbols.
  The transitional report command now writes to the selected project, not always
  to carrier. Both full board builds pass with unchanged generated artifacts.

The complete devkit build now passes all 12 sheets and board-level checks.
The complete carrier build passes all 37 sheets with the native schematic
stages; its electrical/PCB outputs are unchanged. Full C++ placement, board
orchestration and the remaining tooling/tests are still migration work, not done.

---

# 2026-06-10 .. 2026-06-13 — carrier/PLAN.md (the locked decision record)

# Carrier + toolchain plan (locked with user 2026-06-10)

## Decisions (user)
- **No CI.** Every local `schgen build` enforces ALL gates (non-zero exit on any failure).
- **Parts library**: top-level `parts/`, STRICT one folder per part — passives included
  (`parts/R_0603_10k/`, `parts/C_0603_100n_25V/`), named by MANUFACTURER PART NUMBER.
  Each folder is self-contained: `part.py` (pins, LCSC, MPN, datasheet URL, electrical
  rules), symbol, footprint, 3D model. Adding a part = adding a folder. `shared/` is
  DELETED (vague); the SoM project's lib-tables point at libs AGGREGATED from `parts/`.
- **Assets always GENERATED, no manual overrides**: `schgen part add <LCSC-id>` fetches
  EasyEDA/LCSC data and generates the folder. Footprint + 3D are converted faithfully
  (must match the physical JLC part); the SYMBOL is generated by OUR layout rules
  (on-grid pins, functional grouping) from the pin data — clean renders stay possible
  without hand-curation.
- **Bring-up architecture (replaces generic 'features')**: the board must be testable in
  stages using switches only — (1) enable power supplies rail-by-rail (DIP switches on
  regulator ENs + per-rail power-good LEDs), (2) enable user LEDs, (3) every module
  individually power-gated (load switch per module + enable switch + status LED).
  User LEDs + buttons included. RTC/QWIIC/CAN: not now.

## Phases
- **P0 (in flight)**: wave 1 subsystems → harvest, eyeball, commit, push.
- **P1**: `parts/` restructure + migration script; kill `shared/`; schgen loads symbols
  from `parts/**`; aggregated KiCad libs generated for the SoM project.
- **P2**: LCSC pipeline — `schgen part add C#####` (folder generation), `schgen preflight`
  (live stock / Basic-vs-Extended / cost rollup; fails on ghosts).
- **Wave 2** (on parts/ layout): lvds_lcd, mipi_camera, pmod, jtag_swd, boot_switches,
  user_io (LEDs+buttons), **bringup** (rail-EN DIP switches, per-module load switches
  TPS22918/SY6280-class, PG LEDs) — module rails become gated nets (+3V3_HDMI, …).
- **Wave 3**: FMC; J1/J2/J3 sheets GENERATED from carrier/som_interface.json.
- **P3**: linker + typed ports (`diff_pair`, `i2c`, `sd_bus(level=…)`) — board-level
  netlist gate, undefined-port/name-drift/level-mismatch errors, KiCad layout-constraints
  export (impedance/pair/length-match), block diagram generated from the port graph.
- **P4**: rule engine as 4th gate (cap derating vs rail, pull-up windows, regulator
  feedback math, per-rail current budgets — rules live in each part's `part.py`).
- **P5**: SPICE spot-checks (dividers, ramps) from the same netlist.

## Standing rules
Netlist-first; gates immutable; wire-heavy datasheet style; everything programmatically
generated (no hand-assembled implementations, no hand-copied pinouts); commit AND push
after every verified step.

## Decisions round 2 (user, 2026-06-10)
- **Power input**: USB-C PD ONLY, 20V/3A (60W) via FUSB302. No barrel jack.
- **Carrier rails**: +5V (buck from VIN), +3V3 (buck from +5V), +1V8 (for SD/peripherals).
  FMC VADJ = FIXED 2.5V from a local LDO inside the FMC subsystem (not a global rail).
- **Bring-up**: DIP switches + STM32 override (switch OR/AND GPIO into every regulator
  EN and module load-switch EN); per-rail PG LEDs.
- **HDMI**: BOTH TX and RX on rev A. **LCD**: generic 40-pin TTL RGB888 FFC (0.5mm) +
  touch I2C + on-carrier backlight boost. **Camera**: RPi 15-pin FFC, 2-lane MIPI CSI-2.
- **microSD**: VERIFIED 2026-06-10 against the SoM netlist: SDIO_CLK/CMD/D0..D3 run
  J1 -> Zynq U2 directly (no SoM-side translator), and the SoM README declares these
  pins 1.8V. Standard SD cards initialize at 3.3V (1.8V only after the UHS-I switch),
  so a 1.8V-only slot cannot enumerate cards. DECISION (flag resolved): the carrier
  microSD subsystem MUST include an SDIO level translator (TXS02612-class): 1.8V on
  the SoM side, 3.3V card side, powered from +3V3/+1V8.
- **Form factor**: free, connector-driven (~120x100 class expected; user owns outline).
- **Stackup**: JLCPCB 4-layer JLC04161H-7628 — constraints export uses its impedance
  geometry tables (90R USB, 100R TMDS/LVDS/MIPI diff).
- **Assembly**: prefer JLC Basic; Extended where design quality demands; preflight
  reports Extended-reel count + total cost.
- **Debug**: Zynq JTAG on Xilinx 2x7 2mm (14-pin) header; STM32 SWD on ARM 10-pin
  1.27mm. Both probe-standard.

## ARCHITECTURE CORRECTION (user-caught, 2026-06-11) — NO MANUAL PLACEMENT
VIOLATION FOUND: per-subsystem `placer()` hooks with literal coordinates (power.py 37
geometry calls, hdmi_tx.py 33, ethernet.py 18). This is manual placement and is BANNED.
THE RULE: a subsystem .py contains the NETLIST (+ optional DECLARATIVE hints, e.g.
"net X is a trunk bus" — never coordinates, never wire plans, never text positions).
ALL geometry comes from schgen/place.py deriving patterns from circuit TOPOLOGY:
- trunk-bus/ladder (N same-structure taps onto one net — Bob-Smith, rail buses)
- regulator stage (IN caps + IC + L + FB divider + OUT caps, from part roles)
- dual-IC passthrough (protection/level-shift IC between port group and connector)
- connector fan (ports from pin table — som sheets' generator folds INTO the engine)
- existing: decoupling rows, pull-up ranks, port fans, dividers
ENFORCEMENT (after migration): the build FAILS if a subsystem module defines `placer`
or touches geometry APIs — purity is a gate, not a convention.
MIGRATION: engine v2 in schgen/place.py; ALL subsystem placer()s deleted; som_conn_gen
geometry folded into the engine; every sheet re-verified (all gates + render eyeball).
STATUS (2026-06-11): DONE. Engine v2 templates: signal-flow chain (multi-IC channel
runs — hdmi_tx, hdmi_rx), trunk-bus/ladder detection (ethernet Bob-Smith, hdmi_rx
cable-5V trunk), regulator stage rows (power), connector fan (som_j1/j2/j3, folded
from som_conn_gen), divider stacks (m1_rc), plus the shared fan/attachment/cluster/
flag machinery. Subsystems import schgen.model ONLY; `c.hint(net, style)` is the sole
declarative extra. The PURITY GATE in `schgen build` AST-scans the subsystem source
BEFORE executing it and fails on `placer` (def/assign/runtime) or any geometry import.
All 10 sheets (m1_rc usb_pd uart_bridge ethernet power hdmi_tx hdmi_rx som_j1 som_j2
som_j3) all-gates PASS; `schgen link` BOARD GATE PASS; hdmi_rx builds for the first
time — from nothing but its netlist.

## Decisions round 3 (user, 2026-06-11) — UX, layout, robustness
- **Authoring v2 (user-friendly subsystems)**: library-first `use_part("FUSB302BMPX",
  ref="U1")` pulling lib_id/footprint/LCSC/pins from parts/ (inline metadata illegal for
  generated parts); pin-by-NAME `U1.SDA` validated against the part's pin table (numbers
  ok for bare-number connector pins); missing passive folder = build error printing the
  exact `schgen part add C...` fix; GENERATED net-contract module carrier/nets.py (from
  som_interface.json + gated rails) so cross-sheet port names are Python attrs, not strings.
- **Repo cleanup**: DELETE tools/ and scripts/ (git history keeps them); docs/ keeps the
  hand block diagram + the auto-generated block_diagram.svg, stale old-generator renders
  deleted; shared/ DIES: SoM 3D/footprints -> som/lib/ (lib-tables updated), generator-owned
  symbols -> schgen/lib/; m1_rc.py moves out of carrier/subsystems into schgen tests.
- **Outputs COMMITTED**: carrier/sheets/*.kicad_sch + carrier/renders/*.png tracked in git
  (deterministic regen; renders reviewable on GitHub); out/ scratch stays ignored.
- **READMEs**: compact root + per-dir (carrier/, schgen/, parts/); quickstart = 2 lines.
- **`schgen board`**: ONE command = every sheet gated + link + openable carrier.kicad_pro
  hierarchy + constraints + diagram + preflight + JLC BOM.
- **Golden render snapshots**: perceptual hash per sheet committed; drift warns,
  `--bless` accepts intentional changes.
- **Rule engine pulled FORWARD (P4 now)**: rules live in each parts/<MPN>/<MPN>.py;
  retrofit existing sheets; remaining subsystems authored under it.
- **Declined**: parts.lock snapshot (preflight on demand only).

## Documentation spec (user, 2026-06-11) — three-level READMEs
1. **parts/README.md** — compact framework: how to add a component from LCSC
   (find C-number → `schgen part add C…` → what gets generated → verify → commit).
2. **carrier/subsystems/README.md** — the equivalent for subsystems: how to compose
   a subsystem FROM parts (use_part + named pins + ports/nets contract + hints),
   build it, read the gates, review the render. Written by the authoring-v2 agent
   AGAINST the new API (not the current one).
3. **Root README.md** — high level only: what the repo is, the three layers
   (parts → subsystems → board), and how to generate the schematics/projects
   (`schgen build <name>`, `schgen board`). Compact; defers detail to the layer READMEs.

## Output taxonomy (user, 2026-06-11) — carrier/out/ DIES, mirror som/
```
carrier/
  Zynq_Carrier.kicad_pro   # generated KiCad project — double-click to open (like som/Zynq_SoM.kicad_pro)
  Zynq_Carrier.kicad_sch   # generated root sheet
  schematic/               # generated sub-sheets (*.kicad_sch), committed
  renders/                 # flat <name>.png per sheet, committed (GitHub-reviewable)
  reports/                 # ERC / link / gate verdicts, committed (proof travels with design)
  manufacturing/           # bom_jlc.csv, layout_constraints.*, preflight report
  subsystems/              # authored netlists (*.py) — the only hand-written layer
  som_interface.json, nets.py (generated contract), PLAN.md, README.md
```
No scratch dir; everything regenerated in place, deterministic. The authoring-v2/refactor
agent implements this (CLI output paths + .gitignore + README references).

## GAP REGISTRY (audit 2026-06-11 — decided but not yet owned)
1. **pd_input sheet MISSING**: the USB-C PD *receptacle* itself (VBUS -> +VIN path,
   CC1/CC2 wiring to the FUSB302 sheet's STM32_USB_CC1/2 ports, shield). usb_pd has
   only the FUSB302. Without it the board has no power inlet. Owner: next free agent.
2. **Passive part folders (round-1 decision)**: passives still inline c.part(...,
   LCSC=...) — round 1 says EVERY part incl. passives gets a folder. Authoring v2's
   missing-passive error implies the folders; VERIFY at M3 harvest that R/C/L folders
   actually exist and subsystems reference them, else it silently stays inline.
3. **Rule engine P4**: in M3 scope via round 3, but VERIFY at harvest it landed
   (rules in parts/<MPN>/<MPN>.py + retrofit) — not silently dropped.
4. **SC firmware contract**: BOOTSEL decode + BMODE drive + PA13/14 reserved (debug
   dossier "firmware contract") — needs a tracked note in som/ before rev-A bring-up.

## Decisions round 4 (user, 2026-06-11) — SYSTEM GENERATOR: ALL APPROVED
The netlist becomes the single source of truth for the whole SYSTEM, not just the sheets.
All emitted by `schgen board`; none add authoring burden.
- **Generated .xdc**: Vivado constraints for every carrier net through J2/J3 -> Zynq ball
  (LOC from som_interface.json, IOSTANDARD from the VCCO rail map, diff-pair constraints
  from typed ports). The PL design starts with zero pin-mapping work and CANNOT drift.
- **Generated SC-firmware header**: C header for the SoM STM32 system controller —
  pin/function map, BOOTSEL decode table, rail-sequencing order, I2C address map
  (FUSB302 + power monitor + IO expander). debug_boot dossier's "firmware contract"
  becomes code, not prose.
- **Generated bring-up manual**: ordered rail-by-rail checklist from the power tree +
  bringup netlists (close DIP n -> expect rail V at TP x, current limit, PG LED state).
  Testing doc that cannot drift from the board.
- **Power-tree budget gate**: subsystems declare draw; build proves regulator headroom
  through the gate tree; emits numbered power-tree diagram.
- **Test-point coverage rule**: every rail + key bus owns a TP or the build FAILS.
- **SPICE spot-checks pulled forward (P5 -> now)**: ngspice on auto-extracted dividers/
  RC/FB loops (incl. BOOT0 1k5/100R divider) with pass thresholds, gated.
- **`schgen selftest`**: gate mutation testing — injected pin-swaps/dropped wires/net
  aliases MUST be caught by the gates (the no-CI answer to "who watches the watchmen")
  + build-twice byte-compare determinism check.
- **README gallery**: auto-generated render thumbnails + inline block diagram; the repo
  demos itself on GitHub.
SEQUENCE: after M3 harvest + camera/FMC/pd_input sheets; selftest + .xdc first (trust +
immediate user value), then power-tree/TP/SPICE gates, then SC header + bring-up manual
+ gallery.

## Flags from subsystems-research harvest (2026-06-11)
- **DECISION NEEDED — bank 13 oversubscribed**: lcd(34 IO) + pmod(16) + user_io(8) = 58
  signals > 43 available bank-13 IOs. Agent proposal: move LCD to J3 bank 34 (untouched).
- **Camera requires +VCCO_35 = 2.5V** (XAPP894 D-PHY on HR bank) — new rail-map entry +
  LP-RX pin reservation; carrier dossier carrier/research/camera_csi.md has the lane map.
- **POWER_LIBS generalization (engine)**: fixed rail->symbol name map must accept arbitrary
  rails (+VIN_SYS, +5V_REG, gated rails). BLOCKS: power.py shunt rail split (held out of
  harvest to keep power green — power_mon cannot LINK until the split lands).
- **Stock risks for preflight**: DS1024-2x6R2 (45 units!), INA3221 C181255 (2.4k),
  RPi FFC SFW15R-1STE1LF picked over -2STE1LF (111, ghost-risk). Re-verify at BOM time.
- **RESOLVED (user, 2026-06-11): LCD -> J3 bank 34** (+VCCO_34 = 3.3V rail-map entry);
  pmod + user_io + LCD touch I2C keep bank 13. lcd.py expect targets updated.

## Flags from board-completion harvest (2026-06-11 evening)
- **RESOLVED (2026-06-11): fmc all-gates GREEN** — engine extended generically for
  160-pin connector scale (aux body-head budget + new-column overflow, EN-strap onto
  the stage in-rail, GROUND comb trunk outside connector fans = the som x_g idiom,
  rails placed after labels on connector-scale sides, pull/hang rank rows, attach-band
  probes covering passive texts). Board: 23 sheets, BOARD GATE PASS; render eyeballed
  (A3); goldens blessed. Inspected drift: power_mon shunt rank one row (A3->A4),
  bringup_rails/bringup_en_modules spacing — all clean.
- **DECISION at power-tree gate: VBUS pre-contract capacitance** — board total ~30uF
  nominal (pd_input 10u + power.py 2x10u unswitched) vs ~10uF PD sink guidance:
  inrush limiter OR trim buck input bulk.
- **Rail map for wave-3 J-sheet regen**: +VCCO_35 = +2V5_VADJ (SHARED camera/FMC 2.5V);
  FMC budgets into power-tree gate: VADJ 0.4A (TLV75725 DBV thermal), 3P3V 1A.
- **part_gen gap**: cannot traverse EasyEDA multi-unit 'subparts' symbols (ASP-134603-01
  generated via verbatim flatten + --from-json; regen online for 3D once fixed).
- **Procurement**: ASP-134603-01 stock 282/Extended/$17.75 — order early; TLV75725PDRVR
  alternate is ghost-risk (16 units). 31 BOM lines still missing LCSC ids.

## Flags from mechanical-debt harvest (2026-06-12)
- **RESOLVED (2026-06-11): use_part lib-override landed** — `use_part(mpn,
  lib_id=..., footprint=...)` keeps the deliberate drawing while sourcing
  MPN/LCSC/datasheet from parts/ (hidden MPN+Datasheet fields in the emitted
  file; pin-by-NAME disabled under override — numeric pins validated against
  the actual symbol). All 8 migrated (power TPS54302 x2/AP2112K/AO3400A;
  hdmi_tx TPD12S016+HDMI-019S; hdmi_rx HDMI_A_RX+M24C02; usb_pd FUSB302);
  renders byte-identical, goldens untouched, graph identity proven.
- **RESOLVED (2026-06-12, round-5 decision): ethernet Bob-Smith 1n caps** — all 5
  (4 ladder + the C5 chassis barrier) now 1nF/2kV X7R 1206, live-verified C9196
  (FH 1206B102K202NT, JLC Basic, stock 1.37M); alternates in ethernet.py docstring.
- **PROCUREMENT CRITICAL**: HX5008NLT C962544 stock=10 (clone C47575004 @419 noted in
  ethernet.py); DS1024-2x6R2 @45; TPD6E001RSER @216; ASP-134603-01 @282. 43 Extended
  reels, $43.30/board @qty1 (preflight_report.txt in manufacturing/).

## Decisions round 5 (user, 2026-06-12) — power-tree findings resolved
- **+5V_HDMI_TX / +5V_LCD**: ADD two SY6280 gate cells to bringup (fed from +5V,
  per-module switchable like everything else; EN cells + DIP/override + status LEDs
  per the existing pattern; power tree updated).
- **Carrier-vs-SoM rails**: ISOLATE — carrier bucks win; SoM's exported +3V3/+1V8 on
  J1 become explicit no-connects (or TP-only) on the carrier side; nets stay distinct.
- **VBUS pre-contract**: eFuse soft-start (TPS25940-class, 24V, live-verified LCSC)
  between PD receptacle and bulk on +VIN — controlled dV/dt + inlet OVP/OCP.
- **Ethernet Bob-Smith**: 1000pF 2kV 1206/1808 (live-verified) replaces 0603/50V x4.

## P0 + wave-3 decisions (AUTONOMOUS, per full-autonomy directive, 2026-06-12)
- **P0 — SoM VIN OVERVOLTAGE (netlist-proven, wave3_function_map.md)**: the SoM is a
  4.2-5V-input module (TPS7A20/MPM3834/MPM3822/TPSM82864 all 6V-class; SoM sheet says
  "4.2-5V") but the carrier nets J1.1-14 to the 20V PD rail +VIN. FIRST PD CONTRACT
  DESTROYS THE SoM. DECISION: always-on +5V_SOM buck (TPS54302, third instance) from
  +VIN -> J1 VIN pins; always-on because PD negotiation is circular (the SoM SC hosts
  nothing pre-PD here — FUSB302 is carrier-side on +3V3_SC — but the SoM must boot
  with the 5V default-USB contract too). Power tree re-rooted accordingly.
- Wave-3 binding plan ADOPTED as specified in carrier/research/wave3_function_map.md:
  GPIO1/2/3 rail-EN vetoes; GPIO4 = SC_INT_N wire-OR (TCA9535 INT# + FUSB302 INT, usb_pd
  R1 dropped); STM32_I2C2 bit-banged on DAC1/DAC2 J1.49/55 (hardware I2C proven
  impossible); USBOTG_FLT_N -> TCA9535 P12 with pull-up re-railed +3V3_SC (abs-max fix);
  PMON_ALERT_N -> P11; SD_CARD_DETECT -> bank-13 EMIO; VCCO 13/33/34=+3V3, 35=+2V5_VADJ
  (FMC mezzanine share 0.40->0.35A); EN_HDMI_TX drives both HDMI switches (no free DIP);
  PUDC_34 strap added carrier-side; powertree +3V3_SC source model corrected to TPS7A20
  300mA (gate must re-verify the always-on budget).
- **RECONCILIATION with the round-5 5V-gate landing (2026-06-12)**: the adoption above
  was written concurrently with the round-5 bringup commits and two of its assumptions
  are now stale against the committed netlists: (a) TCA9535 P12/P13 are TAKEN by
  BU_OVR_HDMI_TX_5V / BU_OVR_LCD_5V (bringup_rails round-5 extension; P11 stays
  reserved for PMON_ALERT_N) — USBOTG_FLT_N must land on the next free port (P14;
  P14..P17 currently 100k-to-GND spares). (b) "EN_HDMI_TX drives both HDMI switches
  (no free DIP)" is superseded: SW6 (DSHP04, round-5 extension DIP) provides a
  dedicated HDMI_TX_5V position, so +5V_HDMI_TX has its OWN EN_HDMI_TX_5V cell.
  The generated firmware header / BRINGUP.md are netlist-derived — the wave-3
  binding agent must read the current port map from those, not from this prose.

## Electrical-review findings (deep audit, 2026-06-12, autonomous triage)
- **PWR-1 [CRITICAL] — power.py +5V_SOM (U4) EN over-stress**: R12/R13=22k/10k from
  +VIN puts 6.25V on the TPS54302 EN at the 20V PD contract (rec-max 5.5V, abs-max 7V);
  the "internal EN clamp" the P0 work assumed does NOT exist (live TI SLVSDG6C: EN abs
  7V, I_hys 1.55uA). FIX (autonomous): EN zener clamp (5.1V) + bypass cap, divider kept
  for reliable turn-on at the 5V default contract; remove the false docstring claim. A
  plain re-ratio cannot satisfy both turn-on-at-5V and <=5.5V-at-21V, so the clamp is
  required. Verify EN voltage in the SPICE gate. -> dedicated fix agent NOW (power.py
  free; no function-map collision).
- **PD-1 [low] — pd_input eFuse OVP window tight** (trip min 21.9V vs 21.0V legal max
  contract): widen R4 ~5.36k -> ~23.4V typ, stay below SMBJ22A VBR-min 24.4V. Bundle
  with PWR-1 (pd_input free).
- RESOLVED (2026-06-13, post function-map harvest — round 6 electrical-audit fixes):
  - **SD-1 [med] — RESOLVED**: microsd TPD6E001 U2.VCC was floating (worst-case clamp);
    now biased to the card rail +3V3_SD + local 100n (C14663). U2.NC is the only NC.
  - **HDMIRX-1 [med] — RESOLVED as documented DNP**: RX TMDS had no ESD. Researched +
    LIVE-verified a real in-spec part (TI TPD4E02B04DQAR, LCSC C106794, 39,617 stock,
    0.2 pF/line << 0.5 pF budget, 8 kV). A POPULATED 2x 4-ch shunt array cannot be
    auto-placed on this dense sheet under the immutable zero-crossing visual gate (the
    TMDS sink is off-sheet, so the placer's shunt-cell idiom is not triggered and an
    in-line array crosses other lanes). Per the finding's explicit fallback, carried as
    a DOCUMENTED DNP STUFFING OPTION (camera FFC ESD precedent) with the verified part id
    + layout note in the hdmi_rx docstring — NOT a ghost.
  - **HDMIRX-2 [low] — RESOLVED**: EDID WC# was hard-grounded (write-enabled); now a 10k
    write-protect strap pulls WC# HIGH to +3V3_HDMI_RX on the labeled jumper net
    HDMI_RX_EDID_WP (default write-protected; jumper to GND to program). E0/E1/E2 kept.
  - **LCD-1 [low] — RESOLVED**: SY7201 boost out cap C2 1u -> 2.2u/50V X7R, LIVE-verified
    CC0805KKX7R9BB225 (LCSC C125847, 72,946 stock); footprint corrected to 0805.

---

# 2026-06-13/14 — carrier/OVERNIGHT_PLAN.md (the autonomous overnight run tracker)

# OVERNIGHT IMPLEMENTATION PLAN — 2026-06-13/14

Durable execution record for the autonomous overnight run. The user approved
the **entire** investigation backlog (8-thread investigation, ~50 proposals)
via 12 decision questions, then went to bed with: *"work aggressively through
the night."* This file is the source of truth across context compactions —
update the checkboxes as units land.

## STATUS @ overnight (newest commits on master, fast-forwarded)

LANDED ON MASTER (each: full regression — board PASS 26 sheets + selftest
44/44 + m1 + determinism — before commit):
- PERF-2 parallel kicad-cli (172s→142s) · PERF-1 PinRef→Net index
- DEF-1 3D-model-offset bug (4 parts) · DEF-2 thermal-pad paste relief (5) ·
  DEF-3 default footprints + BOM footprint gate · DEF-4 link clobber guard ·
  DEF-6 HDMI-RX TMDS termination (new hdmi_rx_term sheet)
- BLOCK DIAGRAM full rewrite (the acute item) — layered DAG, clusters, legend,
  landscape; the unreadable strip is gone
- DOWNSTREAM: 4 new generators (Vivado TCL, PS device-tree, manifest.json,
  TEST_PLAN.md) + CLI subcommands
- DEVEX: pytest unit-test layer (147 cases) · DEBT-3 constant rename

ALSO LANDED: verification gates — design-rule completeness + per-device
thermal Tj (both hooked into `schgen board`, waivable, with CLI).

⚠ REVIEW ITEMS FOR YOU (surfaced by the new gates / deferred work):
1. THERMAL — the 3 TPS54302 bucks (U1/U2/U4, SOT-23-6 no exposed pad) are
   thermally layout-critical: Tj over the guard under the conservative model;
   waived + documented in carrier/research/thermal_bucks.md. Confirm RθJA by
   thermal sim / bench at bring-up, or move U1 (the hottest, 20 V→5 V @ 2.8 A)
   to an exposed-pad buck. This is a genuine margin call worth your eyes.
2. DEF-5 power_mon shunt split still deferred (telemetry reads across an open
   until the firmware shunt-walk + power-sheet decongest land).
3. RTC backup cell — DECIDED (your call): RECHARGEABLE ML1220 (Mn-Li). BT1 is
   now an ML1220 (charges to ~3.1 V from 3.3 V); firmware ENABLES the RV-3028
   trickle charger (TCE + ~3k series) for a maintenance-free RTC. Holder
   unchanged (KH-CR1220-2 fits 12.5 mm). Do NOT fit a primary CR1220 or a LIR
   Li-ion (4.2 V target > 3.3 V). Firmware contract + ASSEMBLY_NOTES updated.
4. Coin-cell silk polarity (audit-2). KH-CR1220-2 marks polarity on Cmts.User,
   not F.SilkS — add a silk `+` by pad 1 at layout (noted in ASSEMBLY_NOTES).
5. LCD-FFC ESD (audit-4). The 40-pin LCD FFC is user-touchable; lcd_backlight.md
   section 7 DEFERS ESD as "optional later hardening" — a documented choice, not
   a bug. If you want it consistent with the protect-every-connector philosophy,
   add a low-cap ESD array on the touch-I2C pair (CTP_SDA/SCL) at least; left to
   you (the LCD sheet is dense, so weigh the layout cost). NOT auto-applied.
6. FMC ESD (audit-4). An auditor flagged no ESD on the FMC LVDS lines — but FMC
   is a board-to-board MEZZANINE (not a cabled/user connector) and ESD arrays
   add capacitance that degrades LVDS SI, so omitting them is STANDARD FMC
   practice. Treated as a design choice (no change); flagged only for awareness.

DEFERRED / BIG-ROCKS still to do: DEF-5 power_mon shunt split (needs firmware
shunt-walk + power-sheet decongest), DS-1 BOM+CPL, bus notation, place.py
split, per-part rule engine, board HW (EEPROM/RTC/QWIIC/supervisor — all C1
gated), sourcing (HX5008 2nd-src/ALT_LCSC), GENPOLISH (title block/net-class
cues/sizing), remaining DFM docs, mutation classes + cc-gate.

## MANDATE (12 answers, 2026-06-13)

1. **Block diagram** → FULL professional rewrite (BD-1..8 + GAL-1).
2. **Tier-0 defects** → FIX ALL, including the 2 netlist/topology promotions
   (power_mon shunt split + HDMI-RX TMDS termination).
3. **Board HW** → ALL FOUR: board-ID EEPROM, RTC, QWIIC, supervisor+watchdog.
4. **Domains** → ALL FOUR: verification gates, generator+visual polish,
   developer experience, downstream/FPGA outputs.
5. **Big rocks** → ALL FOUR: bus notation (BUS-1), per-part rule engine,
   independent short/open CC proof gate, place.py split (ARCH-1).
6. **Commit policy** → commit+push every verified unit to
   `holistic-placement-rebuild`; fast-forward merge to `master` per completed
   track.
7. **Verify bar** → FULL regression before EVERY commit (board regen +
   selftest 44/44 + m1_rc + render eyeball + goldens).
8. **Strategy** → DEPTH-FIRST per track (finish+polish a track before next).
9. **Downstream artifacts** → ALL: BOM+CPL, Vivado TCL, PS device-tree,
   manifest.json.
10. **DFM/test docs** → ALL: TEST_PLAN.md, fiducials/tooling/ASSEMBLY_NOTES,
    chassis-GND star-bond, rev-A ICT plan.
11. **Sourcing** → ALL: HX5008 2nd-source, ALT_LCSC+stock-floor gate,
    lifecycle/EOL snapshot, inline-parts→folders + symbol fixes + part_gen
    regression tier.
12. **When done** → KEEP GOING: Tier-3 polish, then re-investigate, then keep
    implementing. Don't stop until the user is back.

## STANDING CONSTRAINTS (must hold for every relevant unit)

- **C1 — manual power enable on ALL new HW.** Every new hardware block
  (EEPROM, RTC, QWIIC, supervisor) sits behind a manual/DIP power enable using
  the existing gated-module idiom (SY6280 / module-gate), exactly like the
  current gated rails. No always-on additions without a gate.
- **C2 — watchdog must NOT reset during power-up.** The supervisor/watchdog is
  armed only AFTER rails are stable; its RESET must never fire during the
  bring-up ramp. Gate it + sequence its arm so a cold boot is never reset by
  it.
- **C3 — Zynq SoM chip may change later** (availability). Do NOT build
  chip-swap machinery now (carrier must be fully defined first), but avoid
  hard-coupling to XC7Z020 in ways that are painful to undo. Keep the device
  id sourced live from the SoM project (already the case in xdc.py), don't
  scatter the literal.
- **C0 — the LAWS still rule.** LAW 0 electrical integrity (prove the netlist,
  no shorts/opens), LAW 1 visual correctness (zero overlap/crossing), LAW 4
  never soften a gate. New geometry (bus notation) merges electrically only via
  alias labels proven by the kicad-cli netlist gate.

## EXECUTION DISCIPLINE

- Single writer to the working tree (me). Parallel agents/workflows only for
  DISJOINT add-only work (new subsystems, new generator modules, new gates,
  new parts/ folders, docs) in isolated worktrees, harvested sequentially.
  NEVER blind `git diff | apply`; NEVER `find -print0 | grep -z | xargs` on
  macOS.
- Full regression before every commit. Commit+push per unit. Merge to master
  per completed track (fast-forward).
- Depth-first: finish a track to 100% (incl. render eyeball for visual work)
  before starting the next.

## BUILD-SPEED NOTE (why PERF goes first)

Baseline: `selftest` ~68s, `board` ~172s (mostly serial kicad-cli + an
hdmi_rx escape-router quadratic). With full-regression-every-commit across
dozens of units, this dominates the night. **PERF-2 (parallelize kicad-cli) +
PERF-1 (memoize the hdmi_rx hotspot) are done FIRST** so every later
regression is fast (target board <60s). Both behavior-preserving — verified by
byte-identical goldens + the determinism check.

---

## TRACKS (priority order; depth-first)

### TRACK 0 — SETUP
- [x] Baseline selftest PASS 44/44 + determinism
- [x] Baseline board build green + timing (~172s) ; plan + memory ; commit plan (94a2c4e)

### TRACK PERF — build speed (do first)  [DONE]
- [x] PERF-2 parallelize per-sheet kicad-cli (ThreadPool, names-order verdicts) — 172s→142s (e7eebbf)
- [x] PERF-1 PinRef→Net index in _Engine (kills net_of quadratic; modest wall-time, kept) (8ea4542)

### TRACK DEFECTS — Tier-0 (fix all)
- [x] DEF-1 3D model offset unit bug — implausible offset reset to 0 + regen 4 parts (d576e26)
- [x] DEF-2 thermal/EP-pad windowed paste relief ~60% (5 footprints) (2399432)
- [ ] DEF-3 forbid footprint-less BOM parts (gate) + backfill (model/__main__)
- [x] DEF-4 `schgen link` clobber guard — partial link -> tempdir (186d87b) [== DX-2 P3]
- [~] DEF-5 DEFERRED to a big-rock effort. The 12-rename shunt split is
      electrically correct (net membership verified) but breaks two consumers:
      (1) the power-sheet ROUTER fails — the 4 new *_REG/+VIN_SYS rail symbols
      over-densify the most complex sheet (54 parts/29 nets), router exhausts 8
      expansions on an EN_5V_SOM vs GND contention (NOT a fit/size issue, so
      SIZE-1/A2 won't help); (2) firmware.py power-tree walk gets stuck — it
      chains regs directly and does not traverse the INA3221 series shunts.
      UNBLOCK PLAN: (a) firmware.py walk must hop through RS1-RS4 shunts;
      (b) decongest power.py by splitting the +5V_SOM/U4 always-on buck into
      its own sheet (power_som.py) — frees ~12 parts AND removes the contention
      region; (c) then land the 12 renames + power_mon waiver text. Reverted to
      green (186d87b).
- [x] DEF-6 HDMI-RX TMDS sink termination — NEW sheet hdmi_rx_term.py: 8×49.9R
      (C114625) from HDMI_RX_*_P/N to AVCC=+3V3. LINK PASS (3-way TMDS merge
      with hdmi_rx + som_j2), powertree +64mA OK, render clean. The 100n/1u
      AVCC bypass is a documented LAYOUT NOTE (not netlisted): the placer
      cannot anchor a rail-to-rail cap with no host part on an IC-less sheet
      ("no topology pattern matched"). >>> PLACER FINDING (-> GENPOLISH/ARCH):
      the placer has no pattern for standalone rail-decoupling caps (cap whose
      both pins are power rails, no IC). A small robustness fix (place such
      caps on the rail trunk / next to the rail power-symbol) would let DEF-6
      carry its bypass caps AND helps any future rail-bypass-only content.

### TRACK BLOCKDIAG — full rewrite (acute)  [DONE — worktree agent, 8 iters]
- [x] BD-1..8 + GAL-1 ALL landed in one diagram.py rewrite: layered L→R DAG with
      barycentre crossing reduction, peer-edge aggregation (per-pair count +
      dominant-kind), tall central SoM spine with distinct per-edge anchors,
      orthogonal gutter routing with unique per-edge lanes, ptype.kind colour +
      legend, fixed label grammar ('N nets · group'), subsystem clusters,
      landscape 2348×716 canvas (was 860×2580 strip), README embeds capped at
      width=900. Render rasterised + eyeballed — clean, readable, professional;
      the acute "unreadable" complaint is resolved.

### TRACK VERIFY — gates + automated testing  [VER-1/2 done, worktree agents]
- [x] VER-1 design-rule completeness gate (verify/design_rules.py): decoupling
      per IC supply pin / i2c pull-up / reset-RC / floating-strap, pin function
      inferred by NAME, model-only, waivable + board hook + `schgen design-rules`
      CLI. Findings on the current board: 0 missing decap, 2 hdmi_tx DDC pulls
      (waived: TPD12S016-integrated), 2 GPIO/internal-pull resets (waived).
- [x] VER-2 per-device thermal Tj gate (schgen/thermal.py): Tj=Ta+Pd*RthJA per
      device + waivable + board hook + `schgen thermal` CLI. >>> SURFACED A REAL
      ITEM: the 3 TPS54302 bucks (U1/U2/U4, SOT-23-6 no-EP) exceed the Tj guard
      under the conservative bare-package model — WAIVED as layout-critical +
      REVIEW-FLAGGED in carrier/research/thermal_bucks.md (confirm RthJA by
      thermal sim/bench at bring-up, else switch U1 to an exposed-pad buck).
- [ ] VER-3 mutation classes for new + untested gates (selftest.py)
- [x] VER-4 independent connected-components short/open gate (verify/cc_gate.py)
      — a SECOND oracle disjoint from kicad-cli: net-blind union-find over the
      emitted geometry vs the declared nets. Board: 0 shorts/0 opens on all 26
      sheets AND agrees with kicad-cli PIN-FOR-PIN 26/26 (full equivalence-
      relation cross-check). Net-blindness + synthetic short/open proven by the
      builder. Hooked into board. >>> VERIFY TRACK COMPLETE.

### TRACK DEVEX — dev experience + automated testing
- [x] DX-1 pytest unit-test layer (schgen/tests/, 147 cases ~8s, worktree agent) — c92d7c4 [HIGH — user emphasis]
- [ ] DX-2 authoring UX: P1 clean CLI errors, P2 unassigned-by-name, P4 list/pins, P5 bulk-NC, P6 footprint-validate, P7 build-time link check, P8 scaffolder+DESIGN.md path, P10 unify loaders
- [ ] DX-3 DEBT-1 PlacedDesign.from_placement factory + DEBT-3 rename _DRIVER_ETYPES
- [ ] DX-4 [BIG] place.py split into template modules behind registry (AFTER DX-1)

### TRACK GENPOLISH — visual fidelity
- [x] GP-1 TITLE-1 populated title block (emit.py) — title=circuit title, company
      "Zynq SoM Carrier", generated-by comment, NO date (determinism); all 26
      sheets, render-verified (A4 + A3), goldens re-blessed
- [ ] GP-2 CUE-1 net-class stroke cues
- [ ] GP-3 SIZE-1 A2/A1 sheet-size ladder
- [ ] GP-4 LABEL-1 directional label shapes
- [ ] GP-5 IDIOM-1 broaden templates / relax regulator shared_ok
- [ ] GP-6 [BIG] BUS-1+BUS-2 bus notation (RGB888/FMC/SDIO) — alias-merge, LAW 0
- [ ] GP-7 MULTIUNIT-1 multi-unit symbols

### TRACK DOWNSTREAM  [3/4 + TEST_PLAN done via parallel worktree workflow]
- [ ] DS-1 assembly-ready BOM enrich (MPN/datasheet/Basic-Ext) + JLC CPL cpl_jlc.csv  <-- still TODO
- [x] DS-2 Vivado create_project.tcl (schgen/vivado.py; device live-extracted via extract_zynq) + CLI + board hook
- [x] DS-3 Zynq PS device-tree fragment (schgen/devicetree.py -> carrier/firmware/carrier_pl.dtsi) + CLI + hook
- [x] DS-4 manifest.json integration spine (schgen/manifest.py; 24 rails/i2c/gpio + 43 artifact sha256) + CLI + hook
- [x] DOC-1 TEST_PLAN.md (schgen/testplan.py; spice limits + TP pads + DIP stages) + CLI + hook  [also a DFMDOCS item]
      All 4 built by a worktree-isolated parallel workflow, content harvested,
      hooked into cmd_board + registered as `schgen vivado|devicetree|manifest|
      testplan` CLI subcommands. board PASS, deterministic, selftest 44/44.

### TRACK SOURCING
- [x] SRC-1 HX5008 second-source committed (ethernet T1 ALT_LCSC=C47575004)
- [x] SRC-2 ALT_LCSC + stock-floor in preflight (assess_stock pure fn +
      STOCK_FLOOR + --min-stock + alternate fallback) + pytest test_preflight.
      NOTE: the live JLC-query fallback path needs network to fully exercise;
      the pure stock-verdict logic is unit-tested offline (incl the HX5008
      stock-10 landmine -> LOW warning).
- [ ] SRC-3 lifecycle/EOL + stock/price snapshot capture (part_gen)
- [ ] SRC-4 inline 5 schgen: parts → parts/ folders + symbol-name preservation (P5) + part_gen regression tier (P6)

### TRACK BOARDHW — new hardware (C1 gated; C2 watchdog post-stable) >>> DONE
All four blocks landed on TWO new sheets — board_aux (the gate + PCA9306 I2C
isolator) and board_services (the peripherals) — split so neither defeats the
placer's rail-stub router. board PASS @ 28 sheets, all gates green, preflight
PASS (+$4.56/board), determinism PASS.
- [x] HW-1 board-ID EEPROM 24AA025E48 (SOT-23-6, C129895) — EUI-48 MAC for the
      RJ45/LAN8720, strapped **0x51** (A0=1; 0x50 is the FMC EEPROM). On the
      gated +3V3_AUX rail behind the PCA9306 isolator.
- [x] HW-2 RTC RV-3028-C7 (C3019759) — integrated DTCXO (no crystal), CR1220
      coin cell (KH-CR1220-2) auto-switchover, **0x52**, gated rail.
- [x] HW-3 QWIIC / STEMMA-QT (ZX-SH1.0-4PWT, C7430446) on the isolated AUX I2C
      + gated 3V3 — external modules never touch the always-on management bus.
- [x] HW-4 supervisor + watchdog TPS3823-33 (C7719). **C1**: on default-OFF
      +3V3_AUX (DSHP04 SW1). **C2** (no power-up reset) THREE ways: rail OFF at
      power-up (unpowered), WDI-float-disables-watchdog until firmware drives
      WATCHDOG_KICK, and RESET# is a firmware-mediated PL event (J3.31), never a
      hard POR. **C3**: watchdog signals ride PL bank-35 (IO_L16_N/P_35), xdc-
      sourced — no Zynq hard-coupling.
- [x] HW-* 6 parts/ folders (part add) + downstream regen (xdc picks up the 2
      watchdog PL pins, firmware/nets/manifest/BOM all updated).
- LAW 0: PCA9306 EN tied to +3V3_AUX auto-isolates the gated peripherals from
      the always-on STM32_I2C2 bus (no back-powering through ESD diodes).
  REVIEW NOTE (low): QWIIC J10 pad-1 location must be verified against the
  footprint silk before fab (power/I2C order); flagged in the sheet docstring.

### TRACK RULE-ENGINE — [BIG] large capability
- [ ] RE-1 part_gen captures RATINGS (V/I/P/tol/dielectric/temp)
- [ ] RE-2 per-part RULES (derate / pullup_window / fb math)
- [ ] RE-3 `schgen rulecheck` gate (net voltage from power tree × rules) + board hook
- [ ] RE-4 seed MLCC derating ≥50% + pull-up window + buck FB; + mutants

### TRACK DFMDOCS
- [x] DOC-1 TEST_PLAN.md (done in DOWNSTREAM via schgen/testplan.py)
- [x] DOC-2 fiducials + tooling + carrier/manufacturing/ASSEMBLY_NOTES.md
      (static requirements doc; a floorplan-driven coord generator is a noted
      follow-on)
- [x] DOC-3 chassis-GND star-bond explicit requirement (in ASSEMBLY_NOTES.md:
      single-point GND<->CHASSIS_GND stitch at the RJ45/HDMI shield entry)
- [ ] DOC-4 rev-A ICT / flying-probe plan (TEST_PLAN.md covers most of this)

### TRACK TIER3 — polish then re-investigate (keep going)
- [ ] symbol quality P5 deepening, datasheet bundle PARTS.md, PCB stub, boot/heartbeat LEDs, FILL-1, FP-1/2, RND-1, GAL-2, REUSE-1
- [ ] fresh investigation round → next wave → keep implementing

---

## PROGRESS LOG (newest first)
- 2026-06-14: AUDIT-3 (engine / gate-soundness / generators / determinism — the
  surfaces audits 1-2 did not touch). 19 confirmed of 26; re-verified each.
  The headline "CRITICAL determinism bug" (unsorted set iteration) was proven a
  FALSE ALARM by a definitive test: two full builds with PYTHONHASHSEED 0 vs
  12345 -> byte-identical. Still hardened the latent fragility: route.py emits
  junctions + splits legs in sorted order (canonical; renders unchanged, 14
  .kicad_sch reordered) AND a NEW cross-seed determinism gate in the selftest
  builds each sheet in two subprocesses with different hash seeds — this
  PERMANENTLY guards ALL the determinism findings (emit/place/manifest unsorted
  iterations) at once. Downstream completeness: the board-HW I2C devices
  (0x51/0x52) now appear in testplan (Stage 6 + the isolator ACK-proof) and
  manifest (bus AUX_I2C), single-sourced from firmware._id_eeprom_addr.
  Commits 2151a9c (determinism), 6057e3c (testplan), 3fc5973 (manifest).
  DOCUMENTED-SKIP (re-verified as non-issues / caught elsewhere): visual_gate
  junction-degree validation — the proposed fix is naive (would false-flag
  valid junctions at pins; degree needs wire+pin geometry the visual gate
  lacks), and missing/spurious junctions are already caught electrically by the
  CC + netlist gates; design_rules STRAP-on-undriven-rail — caught by ERC +
  powertree; manifest missing-subsystem guard — firmware already fails loudly
  on a missing ID-EEPROM. Several "confirmed" findings were over-confirmations
  whose fixes would not have improved correctness (see memory note).

- 2026-06-14: RE-INVESTIGATION (mandate "polish then re-investigate"). Ran a
  7-dimension / 14-agent adversarial audit of the 28-sheet board + the new
  board-HW. Every finding independently re-verified before action. 2 confident
  "HIGH" FALSE POSITIVES rejected with proof (their fixes would have introduced
  bugs: a DSHP04 mis-wire that never enables the rail; a non-existent PCA9306 EN
  float). 3 REAL findings fixed: (a) QWIIC ESD — moved to its own sheet
  board_qwiic + USBLC6 array (29 sheets); (b) firmware I2C-map completeness —
  board_aux/services added to SOURCES, ID-EEPROM 0x51 strap-DERIVED so a
  mis-strap trips the collision check, +RTC 0x52 +FMC 0x50 (117 #defines);
  (c) docstring clarity. board PASS @29, determinism PASS, pytest 168->170.
  Commits 72b87ce (audit fixes), ed92cb5 (board-HW invariant tests).
- 2026-06-14: BOARDHW done — all 4 blocks (EEPROM/RTC/QWIIC/watchdog) on the
  gated +3V3_AUX across board_aux/board_services, C1/C2/C3 honoured. cfabd8a.
- 2026-06-14: VERIFY done — independent CC short/open gate (2nd oracle). d846368.
- 2026-06-13: investigation complete (8 threads); 12 decisions captured; baseline green; plan written. Starting TRACK PERF.

---

# 2026-06-14 — MORNING_REPORT.md (overnight run summary)

# Overnight run — morning report (2026-06-14)

Autonomous overnight session summary. Detailed tracker:
[carrier/OVERNIGHT_PLAN.md](carrier/OVERNIGHT_PLAN.md) (now archived above).
**Everything below was on `master`** (fast-forwarded, ~33 commits), each gated
by a full regression — board PASS **29 sheets** + selftest **53/53** + m1 +
byte-determinism (now also cross-PYTHONHASHSEED) + pytest **181** — before it
landed. Working tree clean.

## Continuation tracks (after the first draft)

1. **VERIFY — independent CC short/open gate.** A 2nd oracle, disjoint from
   kicad-cli (net-blind union-find over the emitted geometry); agrees pin-for-
   pin on all sheets. The board is now electrically proven by two code paths.
2. **Board HW — ALL FOUR blocks** (see the dedicated section below).
3. **Four adversarial re-investigation audits** (19 dimensions, ~77 agents) —
   electrical defects ×2, engine/gate-soundness + determinism, and a
   completeness critic (what's *missing*). The last found two real
   dossier-mandated **bulk caps** absent on gated rails (+3V3_HDMI_TX,
   +3V3_LCD) — now added; LCD-FFC + FMC ESD were re-verified as a documented
   deferral / a board-to-board-mezzanine design choice and left as review items.
   Every finding independently re-verified — several confident "HIGH/CRITICAL"
   findings were FALSE POSITIVES whose fixes would have *introduced* bugs, and
   are documented-rejected (a DSHP04 mis-wire that never enables the rail; a
   non-existent PCA9306 EN float; an ~11 µA EN back-feed; an over-stated USBLC6
   "ineffective" claim; a "CRITICAL determinism bug" disproved by a definitive
   cross-PYTHONHASHSEED build test). REAL fixes landed:
   - **firmware I2C-map completeness** — ID-EEPROM (strap-derived so a mis-strap
     trips the collision check) / RTC / FMC, now also in the **testplan** (Stage
     6 + an isolator ACK-proof) and **manifest** (bus AUX_I2C), single-sourced.
   - a **VCCO bank-rail drift gate** (xdc IOSTANDARD map vs som_conn_gen — a C3
     safety net) and a **cross-PYTHONHASHSEED determinism gate** in the selftest
     (plus canonical sorted junction emission) — the determinism invariant is
     now bulletproof and permanently gated.
   - QWIIC ESD on its own sheet, clamp referenced to always-on +3V3; the RTC
     primary-cell/trickle-charger safeguard elevated into the firmware contract;
     DFM/assembly notes; a derived bring-up "Stage 6 — board services".
   ~40 new pytest cases lock it all. The board-HW now appears in EVERY
   downstream artifact (firmware / manual / testplan / manifest / xdc).

## What landed (by track)

| Track | What |
|---|---|
| **Block diagram (your #1)** | Full rewrite — the unreadable 860×2580 strip → a clean **layered landscape system map**: subsystem clusters, a tall central SoM spine, a legend, per-edge type-colouring + counts. |
| **Tier-0 defects** | **DEF-1** 3D-model-offset bug (4 parts a metre off); **DEF-2** thermal-pad **paste relief** (5 parts); **DEF-3** default footprints + a **BOM footprint gate**; **DEF-4** `schgen link` clobber guard; **DEF-6** **HDMI-RX TMDS termination** (new sheet). |
| **Downstream** | 4 new generators + CLI: **Vivado `create_project.tcl`**, **PS device-tree** `carrier_pl.dtsi`, **`manifest.json`** spine, **`TEST_PLAN.md`**. |
| **Verification** | **pytest** unit layer (154 cases, ~8 s) · **design-rule completeness** gate · **per-device thermal Tj** gate · **+9 mutation classes** proving the model-only gates bite (44→53). |
| **Generator polish** | **Title block** populated on every sheet (was blank). |
| **Sourcing** | `ALT_LCSC` second sources + a **procurement stock-floor** in preflight (the HX5008 stock-10 landmine now WARNs); unit-tested. |
| **Build/engine/DFM** | `schgen board` parallelised (172→142 s); `_DRIVER_ETYPES` footgun renamed; `ASSEMBLY_NOTES.md` (fiducials/tooling/chassis-GND star/silkscreen). |

## ⚠ Review items — your eyes wanted

1. **TPS54302 buck thermals (real, surfaced by the new thermal gate).** U1/U2/U4
   (SOT-23-6, no exposed pad) exceed the Tj guard under the conservative
   bare-package model. Waived as layout-critical + documented in
   [carrier/research/thermal_bucks.md](research/thermal_bucks.md):
   confirm RθJA by thermal sim / bench at bring-up, or move U1 (hottest, 20 V→5 V
   @ 2.8 A) to an exposed-pad buck. A genuine margin call.
2. **DEF-5 power_mon shunt split — deferred.** Per-rail telemetry reads across an
   open until two coupled changes land (firmware power-tree walk must traverse
   the INA3221 shunts; the power sheet must be decongested, cleanest by splitting
   the +5V_SOM/U4 buck to its own sheet). A 3-part big-rock, not a quick fix.

## Board HW — ALL FOUR landed (was deferred; now done)

Two new sheets, **board_aux** (gate + PCA9306 I2C isolator) and **board_services**
(EEPROM + RTC + watchdog + QWIIC), split so neither defeats the placer. board
PASS @ **28 sheets**, every gate green, determinism + preflight PASS (+$4.56/bd).

- **ID-EEPROM** 24AA025E48 — factory **EUI-48 MAC** for the RJ45 (0x51).
- **RTC** RV-3028-C7 — integrated DTCXO (no crystal) + CR1220 backup (0x52).
- **Watchdog** TPS3823-33 + **QWIIC** expansion.
- **C1**: all on the default-OFF, DIP-gated +3V3_AUX (SY6280). **C2**: watchdog
  unpowered at power-up + WDI-float-disable + RESET# as a firmware-mediated PL
  event — *three* guards, never a hard POR. **C3**: watchdog rides PL bank-35,
  xdc-sourced. **LAW 0**: PCA9306 isolates the gated bus from always-on I2C.
- ⚠ low review: verify QWIIC J10 pad-1 vs silk before fab (noted in docstring).

- Device id stays **live-sourced** from the SoM project (C3).

## Deferred (big-rocks / risk — better with your review, not done overnight)

Bus notation, per-part rule engine, `place.py` split, BOM+CPL (DS-1), part
lifecycle/EOL snapshot, inline-parts→folders. All tracked with rationale in the
plan above.

## How to verify

```
python3 -m schgen board          # all sheets, every gate PASS
python3 -m schgen selftest       # mutants killed + byte-determinism
python3 -m pytest schgen/tests/  # unit cases
python3 -m schgen thermal        # the Tj gate (the buck review item)
python3 -m schgen design-rules   # the completeness gate
```
</content>
</invoke>

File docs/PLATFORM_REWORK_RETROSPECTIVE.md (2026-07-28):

# Platform Rework — Overnight Retrospective (2026-07-28, branch `platform-rework`)

The mandate: *"work through the night until you have reached the final product we have
discussed... Once you think you are complete, remember everything I asked, deeply
analyse the progress, then decide the next steps."* This document is both.

## 1. What was asked (all of it)

1. **Optimize schgen so future board variants let AI tools really perform** — engine
   as mechanism, board as data; no backwards compatibility owed.
2. **Fable 5 solo** — every investigation and edit on this thread, no subagents.
3. **Principle 0** — the rendered image is the only proven ground truth. Any faster
   feedback loop must be validated against the visual loop before it is trusted.
4. **Two products**: schematics a senior engineer would sign (user: current ones are
   **golden references** — preserve, never "improve") and an **electronically logical
   PCB layout** like an advanced human engineer would produce.
5. **Routing struck** from scope; PCB *layout* absolutely in scope.
6. **Overnight**: single branch, no master merge until approval, no questions.

## 2. What landed (receipts)

### P1 — engine/project separation
- `carrier/project.json` + `schgen/core/project.py`: wired sheets, pilot sheets,
  module offset, module face anchors, reg-band prefixes are project **data**.
- **U1e/f**: `--project` CLI (env pre-parse before engine imports), `PROJECT_ROOT`
  indirection across 29 modules, loud failure on a missing spec.
- Byte-identity through the generalized machinery: `2f13efe8` exact.

### P2 — fast feedback under Principle 0
- `schgen board --no-render` fast gate loop (~4 min vs ~12).
- Defect corpus: 13 hermetic tests, 1.1 s — each defect class proven to fire its gate.
- 1 s/sheet solver harness used before every full build (caveat below).

### P3 — constraint-first placement (the campaign's core)
- **23/23 subsystem contracts placer-enforced** (was 4 wired / 18 inert / 1 violated).
- Final board: **EXIT 0 — DRC 0, placement contract 117 structures/0 violations,
  fan-out 110 subjects/0 starved, silk 0/0, LAW-5 ratsnest PASS (17688/18815 airwire
  budget), LAW-6 mech/model/spacing PASS, return-stitch PASS, deterministic
  (md5 `2f13efe8` twice)**, renders visually inspected (top: subsystem clusters +
  edge-flush connectors; bottom: passive banks under the SoM keepout only).
- Board size: 188×165 → **215×168 mm** (+16.4 % area). That is the measured price of
  *enforcing* 117 authored SI/PI structures + fan-out floors + seam reservations —
  every growth increment traceable to a specific enforcement round in the tracker.

Six engine defects were mechanized during convergence — each diagnosed by
instrumenting the emitted board, none by softening a gate (LAW 4):
1. Conn roots must be **built at their final LAW-6 rotation** or solved adjacency
   shatters when placement rotates them (camera: 3.7 mm vs an 8 mm min_from).
2. Solver `rot_out` must **exclude mating connectors** — placement *adds* zone rot to
   `conn_rot` (180+180→0: 8 connectors mouth-inward). Two emitter sites.
3. **Seat-line replication**: the edge-seat overwrites the connector's perpendicular
   coordinate (pads at `EDGE_PAD_CLEAR`). The zone boundary must sit exactly there;
   the mouth overhangs off-zone as it overhangs off-board (a DS1024's 9 mm mouth
   inside the extents put ESD members 13.5 mm from the pads — 11 violations, one
   mechanism).
4. **Compose clamp**: conn-less clusters must stay inboard of the aligned pad line
   (an LDO cluster normalized to 0 rode the seat shift 1 mm off Edge.Cuts).
5. **Fan-out reach formula**: `max(0, margin−GRID)` under-reserves whenever
   margin < GRID — adjacent blocks overlapped 0.18 mm. Straight `need+GRID−margin`.
6. **Symmetric apron**: a multi-pin member near a non-exempt 2-pin crowder must
   carry its own fan-out need (shunt-anchored INA3221 at 0.637 vs 1.0).

Plus: stage-path **generic-proximity solve** with **bound-priority displacement**
(restore-on-fail eviction), and a 0.02 mm silk guard band (float-tangency class).

One authoring correction: power_som EN clamp re-judged 3.0→6.0 mm (judgment tier)
after the displacement mechanic *proved* single-slot musical chairs — no legal
assignment exists at 3.0 against the datasheet-faithful core banks. Documented in
the contract with the measurement.

### U4a — machine-readable verdicts
`carrier/reports/board_verdicts.json` written on every build (all gates, structured).

### S-track — schematics
**Zero changes.** The golden references are untouched, as ordered.

## 3. Principle-0 compliance statement

Every convergence decision was made against the emitted board (positions parsed from
the `.kicad_pcb`, gate kernels re-run, renders eyeballed at the end). The fast
harness was used only to pre-screen; wherever harness and board disagreed the board
won and the discrepancy was root-caused (see caveat) rather than trusted.

## 4. What did NOT land (honest ledger)

- **U1g devkit_mini proof** — the zero-engine-edit second board. Path machinery is
  ready (see census below); what remains is *authoring*: `som_interface.json` subset,
  per-project subsystem binds, floorplan seeds, contracts. That is a design campaign,
  not a refactor, and doing it half-baked at 03:00 would violate Principle 0.
- **Harness conn_rot parity** — the 1 s/sheet synthetic model does not apply
  connector rotation, so edge sheets can false-fail there (camera/lcd showed pf=1
  while the board gate showed 0). Known, bounded, board always wins.
- **~30 residual literal sites** — `repo / "carrier"` in standalone dev-CLI blocks,
  argparse string defaults, firmware/vivado output paths. None are in the `board`
  build path; all should still be swept for U1g.
- **U2b** synthetic flow/facing harness — partially superseded by the defect corpus;
  not built.

## 5. Decided next steps (in order)

1. **U1g — devkit_mini**: author `devkit_mini/project.json` + `som_interface.json`
   subset (power, uart_bridge, usb_jtag, board_aux), bind modules reusing the
   portable `subsystems/` packages, floorplan seeds; build with
   `--project devkit_mini`; acceptance = all gates green with **zero engine edits**.
2. **Harness parity**: apply `connector_edge_rotation` in the synthetic model so the
   1 s loop stops false-failing edge sheets.
3. **Residual path sweep**: the ~30 literal sites above, then delete the census note.
4. **Contract authoring wave 2**: the remaining judgment-tier bounds re-examined the
   power_som way — displacement-proof before re-judging, measurement in the basis.
5. **Master merge** — only on explicit user approval (mandate honored: `platform-rework`
   is pushed, master untouched).

## 6. What the night proved about AI-driven layout

- **Constraint-first placement works end-to-end**: authored, datasheet-cited
  structures → solver → gate, with the gate kernel and the solver sharing frames,
  kernels and populations. Every one of the 6 defects above was a *parity* failure
  between those layers — the discipline "replicate the gate exactly or don't
  pre-empt it" is the platform's core invariant.
- **"Impossible" is almost always a defect**: 22 of 23 contracts that looked
  unplaceable were authoring/resolution/seed/frame bugs. The one true infeasibility
  (EN at 3.0) was *proven* infeasible by mechanism (displacement search), then
  re-judged with the proof attached — the correct division between LAW 4 (never
  soften to pass) and honest re-authoring.
- **The board is the only truth**: three separate times the synthetic model lied
  (frame conventions, missing conn_rot, missing seat). The platform's speed comes
  from fast loops; its correctness only ever came from the emitted artifact.

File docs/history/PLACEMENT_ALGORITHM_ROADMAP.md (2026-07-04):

# Placement Algorithm — First-Principles Roadmap

> Produced 2026-07-04 by a 9-agent first-principles analysis (understand → design panel →
> synthesis) working through the ACTUAL implementation in `schgen/generate/pcb/placement.py`,
> `schgen/generate/floorplan.py`, `schgen/generate/pcb/escape.py`, and `schgen/verify/*.py`.
> Companion to `AI_LAYOUT_ROUTING_CONCEPT.md`. Analysis only — this doc changes no code; it
> defines the true objective, the target architecture, and an ordered, individually-shippable
> migration path. Step 1 (fixed-board fan-out spread) is the work currently in flight.

This is an analysis-and-synthesis task. The four designs and understanding passes are already complete — my job is to synthesize the decisive roadmap document. This is my final deliverable (returned verbatim to the calling script), so I'll produce the clean markdown directly. No code modification needed; the code has already been thoroughly traced and cited across the UNDERSTAND/DESIGN passes.

# First-Principles Placement Roadmap — Zynq-SoM Carrier

*Lead layout architect synthesis. Analysis only — no code modified. All line citations verified against the traced implementation in `schgen/generate/floorplan.py`, `schgen/generate/pcb/placement.py`, `schgen/generate/pcb/escape.py`, and `schgen/verify/*.py`.*

---

## 0. The problem in one sentence

The current placer **minimizes board area subject to a slack block-centre-airwire ceiling** (`floorplan.py:1446-1449`), then repairs everything the real objectives care about — fan-out room, congestion, SI/return-path, thermal — with post-hoc patches (BREATHE `placement.py:1254`, L4-pull `:1069`) and hand-calibrated fudge factors (`PROXY_TO_REAL`, `L4_PULL_CREDIT`, `SAFETY`). The gates encode the true cost; placement optimizes a two-term shadow of it and passes the rest by luck. This document defines the true cost, the target architecture, and a shippable migration path.

---

## 1. The ideal cost function

### 1.1 Why area-min was the wrong primary objective

Area-min is actively **adversarial** to the user's stated goals:

- **It fights fan-out headroom.** The search keeps the *smallest* board clearing the airwire budget (`cand < best` on an area tuple, `floorplan.py:1449`). The user wants breathing room; the objective wants the opposite. Fan-out is then bolted on as ratcheted debt — `PLACE_CLEAR=0.5 mm` sits *below* most `fanout_gate` tiers (0.2/0.5/1.0/1.5/2.0), so the board packs below-need by construction and BREATHE claws it back afterward.
- **It produces the "54% empty yet cramped" pathology.** Area-min shrinks the box while greedy anchor-hug (`place_near` first-fit `:1078`, `_anchor` powered centroid `:1713`, `SOM_W=7.0`) collapses all mass to the SoM centroid — dense core, bare periphery, and the empty area is *trapped* between rigid min-area zones that individually cannot expand.
- **It couples sizing to the escape and breaks it.** `plan.som_x = (BOARD_W − som.w)/2` is recomputed for every candidate (`:1436, :1517`); the escape (`build_escape_copper`, `escape.py:462`) runs *last* on those poses and hard-`raise EscapeError`s (`escape.py:451`) when a resize moves the DF40 field off a via seat.
- **It is pathologically expensive.** O(area) lattice × 16 relaxation passes × (80-step aspect grow + 41×41 fine window) = ~thousands of full packs, on a *jagged* feasibility landscape (`:1496`).

Board area is an **output** of a good placement, not its objective. You shrink by tightening a legalizer, not by searching sizes.

### 1.2 The objective, as a priority-ordered weighted sum

Minimize over positions **and sides**, on a **fixed board**, subject to hard constraints:

```
J(pos, side) =  w_wl  · Σ_e W_e · detour_len(e)              # (A) SI-weighted wirelength-to-SoM
              + w_esc · escape_infeasibility(DF40, obstacles) # (B) return-path / T2 seat existence
              + w_fan · Σ_ic max(0, need_ic − clear_ic)²       # (C) fan-out room, by construction
              + w_cong· Σ_cells max(0, demand − supply)²       # (D) congestion / routability
              + w_flow· (flow_hops + facing + FAR penalties)   # (E) power-chain flow & facing
              + w_therm· Σ_hot-pairs 1/dist                    # (F) thermal spread (3× LM61460)
```

**Priority ordering (which weight dominates), derived from the laws:**

| Rank | Term | Why it ranks here | Gate that measures it |
|---|---|---|---|
| **HARD** | No-overlap, on-board, SoM keepout, edge-seat | LAW-0/1/5/6 — never trade away | `placement_mech`, `ratsnest_gate` (a)(b) |
| **1 — (B)** | Return-path / escape feasibility | LAW-0 electrical integrity; a broken T2 seat is board-dead | `return_stitch_gate`, `escape_lane_gate` |
| **2 — (A)** | SI-weighted detour wirelength | LAW-5 real objective; DDR/diff/high-speed nets first | `ratsnest_gate` cross-airwire `:173` |
| **3 — (C)** | Fan-out room | User's stated end-goal; today it's debt | `fanout_gate` tiers `:77` |
| **4 — (D)** | Congestion spread | Fixes the 54%-empty-cramped symptom | (currently none — new) |
| **5 — (E)** | Flow / facing / FAR | Power-chain quality | `placement_flow_gate` |
| **6 — (F)** | Thermal spread | Softest; part-selection carries most of it | `thermal.py` |

**Net weight `W_e`** comes from the netclass the code already knows — heavy for DDR / differential / GENUINE DF40 escape pairs (the `si_triage` at `escape.py:469`), demoted for bulk GND/rails (already down-weighted by fan-out at `floorplan.py:1256`). This makes SI a *first-class objective term*, not a post-hoc gate — the single biggest correctness win beyond area.

**`detour_len`** is wirelength with a SoM-keepout detour penalty (the flow gate already bolts a `+SoM-diagonal` term on, `placement_flow_gate.py:98`) — because every net routes *around* the central mezzanine, so Euclidean HPWL understates real length.

---

## 2. Target architecture

**Chosen hybrid: analytical global placement (DESIGN-1) as the engine, escape-as-constraint (DESIGN-3) folded into it, min-displacement legalization (DESIGN-1/4) as the closer, and low-temperature SA (DESIGN-2) as an optional discrete-refinement polish.** Rationale: this board is a **star topology into one fixed hub** — the textbook case where a quadratic solve is near-optimal and near-free, while SA alone would be slower to converge and min-cut partitioning is redundant against the given schematic clustering.

### 2.1 The pipeline that replaces `zone-shelf-pack + place_near + area-min-search`

**Stage 0 — Freeze the invariant core (board-size-independent).**
DF40 poses, SoM keepout (`placement.py:1008`), escape region (`escape.py:1035`), corner mounting holes. Anchor the SoM origin to a **fixed datum**, not `(BOARD_W − som.w)/2`. This alone decouples T2 from sizing — `escape._content_key` (`escape.py:1106`) stays stable across the whole solve.

**Stage 1 — Edge/side assignment.** Connectors → edges by LAW-6 mechanics (keep `_pack_edges` seating). Subsystems → quadrant + side by an affinity pass around the SoM (subsumes `_dominant_j` `:595` and `_classify_side` `:277`). Discrete, cheap.

**Stage 2 — Analytical global placement.** One weighted-Laplacian quadratic solve: `min ½ pᵀLp` with DF40 J-strips (`plan.som.js`, `floorplan.py:1573`) and edge connectors as **fixed boundary rows**, SoM as an obstacle penalty, spring weights = `W_e` (SI class) and the existing `som_pull` (`:1261`). Solved by conjugate gradient — ~150 lines, no external deps, sub-millisecond for ~30 nodes. This is exactly `_cross_proxy`'s star (`:1556`) **minimized instead of measured**. A **density/spreading term** (ePlace-style, or cheap bin-overflow quadratic) pushes overlapping mass into the empty periphery — the direct cure for 54%-empty-yet-cramped.

**Stage 3 — SA refinement (optional).** Anneal the *discrete* choices a QP can't express — side-flips, connector orderings, 90° rotations — against the **full `J`**, seeded by Stage 2 so it converges fast and can't scatter. Deferred until Stage 2 + legalizer prove out.

**Stage 4 — Legalization (the closer).** Min-displacement Abacus/Tetris removes overlap with minimal movement, **preserving the global optimum**. Fan-out clearance becomes per-cell spacing (LAW-5/fan-out *satisfied*, not ratcheted); escape corridors are hard keepouts (LAW-0). **Board area = a byproduct of the tightest legal pack** — this deletes the entire area-min search (`:1428-1514`), `place_near` (`:1078`), the 16-pass relaxation (`:1815`), and the calibration fudges.

**Stage 5 — Escape stitch** on the still-frozen DF40 poses (`build_escape_copper`). Byte-identical to today because the poses never moved after Stage 0.

### 2.2 How the laws stay HARD constraints

- **LAW-0 (electrical integrity / return path):** escape feasibility is term (B) *and* a hard pre-check in acceptance; corridors are legalizer keepouts. The netlist graph is the QP input, never mutated.
- **LAW-1 (visual correctness):** the legalizer guarantees zero overlap exactly — stronger than the current soft packing.
- **LAW-5 (ratsnest grouping / no off-board / airwire budget):** cross-airwire is *minimized* (term A), not gated; a subsystem stays one movable node through global placement so contiguity survives; on-board is a hard clamp; the budget check remains as the acceptance oracle.
- **LAW-6 (mechanical / edge-seating):** edge connectors are fixed boundary conditions — springs pull their subsystem *toward* the edge naturally.
- **LAW-4 (never soften a validator):** the entire gate suite is retained unchanged as the acceptance oracle. Placement now *minimizes* the gate cost; the gates *verify* rather than *repair*.
- **Fixed-board-friendly:** board size is an input; the density term fills whatever board it is given. Optional outer binary-search re-solves the *fast* QP, never the O(area) pack.

---

## 3. Migration path

Ordered, each step individually shippable and gate-clean. Recommended sequence **1 → 2 → 3 → 4 → 5 → 6**, front-loading the in-flight fan-out spread and the cheapest robustness win.

### Step 1 — Fixed-board fan-out spread *(IN FLIGHT — do first)*
- **Touchpoints:** stop the area *search*; take the current smallest-feasible board as fixed. Turn BREATHE (`placement.py:1254`) from a local patch into the **primary spreading operator** — a density-gradient push into slack, bounded by zone keepouts + escape corridor. Widen the fan-out apron in `_shelf_pack` (`placement.py:90`) from `PLACE_CLEAR=0.5` to the *needed* `fanout_gate` tier.
- **Gain:** retires the flagship symptom (54% empty yet cramped) and the fan-out ratchet debt — slack becomes reachable.
- **Effort:** S (~3–4 days). **Risk:** LOW (post-pass, no engine change). **Validated by:** `fanout_gate`, `ratsnest_gate`.
- **Builds toward:** prototypes the *density term* that becomes Stage-2 spreading.

### Step 2 — Escape-aware sizing / freeze the core
- **Touchpoints:** Stage 0. Anchor SoM/DF40 to a fixed datum instead of `(BOARD_W − som.w)/2` (`floorplan.py:1436, 1517`). Emit the escape corridor (`escape.py:1035`) as a placement keepout the existing packer respects. Add a fast `_seat_band` feasibility pre-check (`escape.py:448`, no copper emitted) into acceptance *before* the airwire test (`floorplan.py:1446`).
- **Gain:** kills the resize-breaks-T2 fragility — the user's fixed-board end-goal becomes robust.
- **Effort:** S (~2–3 days). **Risk:** LOW, high value. **Validated by:** `return_stitch_gate`, `escape_lane_gate`.
- **Builds toward:** the frozen core every later stage assumes.

### Step 3 — Global relaxation solver (QP miniature)
- **Touchpoints:** replace the 16-pass sequential first-fit relaxation (`floorplan.py:1815`) with **one CG quadratic solve** on interior block centroids — Laplacian from the existing `affinity`/`som_pull`/`som_j_of_net` (`:1250-1266`), J-strips as fixed anchors — then feed into the *existing* `place_near`/legalize. Fold `W_e` SI weights in here.
- **Gain:** lower real airwire; escapes order-dependence and the non-monotonic-valley fragility forcing the 41×41 fine scan; first time SI is *optimized*.
- **Effort:** M (~1 week). **Risk:** MEDIUM (new solver, caged in `_attempt_pack`; determinism via fixed iterations + sorted assembly). **Validated by:** `ratsnest_gate` cross-airwire.
- **Builds toward:** Stage 2, proven on ~30 centroids before scaling.

### Step 4 — Global placer + min-displacement legalizer *(the structural win)*
- **Touchpoints:** retire `place_near` (`:1078`) **and** the aspect-grow/fine-window search (`:1428-1514`). Global step = Step-3 solver over *all* blocks (overlaps allowed) → Abacus/Tetris legalizer into rows, fan-out clearance as per-cell spacing, escape corridors as hard keepouts. Delete `PROXY_TO_REAL`/`L4_PULL_CREDIT`/`SAFETY`.
- **Gain:** optimizes wirelength directly; near-constant runtime w.r.t. board size; board area becomes a byproduct. Largest net *simplification* of the codebase.
- **Effort:** L (~1–2 weeks). **Risk:** MEDIUM-HIGH (correctness lives in the legalizer). **Validated by:** full suite (`placement_mech`, `ratsnest_gate`, `fanout_gate`).

### Step 5 — Congestion + thermal terms
- **Touchpoints:** add a coarse RUDY demand grid (or reuse the `_channels` exclusive-pair map, `placement.py:1321`) as term (D); add the LM61460 inverse-distance term (F). Retire BREATHE and L4-pull — spreading is now first-class in the objective.
- **Gain:** deliberate use of the empty 54%; thermal spread the placer was blind to.
- **Effort:** M (~3–4 days once Step 4 lands). **Risk:** MEDIUM (λ tuning). **Validated by:** `thermal.py`, `fanout_gate`.

### Step 6 — SA discrete-refinement layer *(only if needed)*
- **Touchpoints:** anneal side-flips / connector orderings / rotations against full `J`, seeded by Stage 2.
- **Gain:** residual flow/facing/FAR improvements a QP can't express.
- **Effort:** M (~1 week). **Risk:** LOW (optional, seeded). **Validated by:** `placement_flow_gate`.

### ⟵ Point of diminishing returns: after Step 4 (optionally Step 5)

**Steps 1–4 capture the structural wins**: the flagship symptom is gone (1, then 5), T2 is robust (2), SI is optimized and airwire minimized (3), and the O(area)×thousands search plus all fudge factors are deleted (4). **Step 5** is cheap and worth it once 4 lands. **Step 6 (SA)** is the clearest diminishing return — it is the slowest runtime component, the most tuning-heavy, and only earns its keep if measurable flow/facing failures survive Steps 1–5. Do not build it speculatively.

---

## 4. Honest tradeoffs

### 4.1 The current heuristic works
It **passes every gate on the real board today.** The case for the rewrite is *not* "it's broken" — it is: it optimizes a two-term shadow of the true cost, repairs the rest by luck, runs at O(area)×~thousands cost, and carries a fragile size↔escape coupling. That is a *quality-and-robustness* argument, not a *correctness-is-failing* one. Sequence accordingly: cheapest, highest-value steps first, and stop when the marginal gate-score gain flattens.

### 4.2 Where the ambitious rewrite is NOT worth it
- **Full nonlinear ePlace / RePlAce with FFT electrostatics** — overkill for ~30 nodes; a coarse quadratic + simple spreading captures nearly all of it.
- **hMETIS / min-cut partitioning** — the subsystems are *already* clustered by schematic sheet; the partition is given. Only worth it if you go to *part-level* placement (Step 5+ of DESIGN-4), which is not currently needed.
- **RL macro placement** — no.
- **The SA layer (Step 6)** — genuinely optional; defer indefinitely unless flow gates fail.

### 4.3 The smallest change that captures ~80% of the benefit

**Ship Step 1 + Step 2 only** (both size S, both LOW risk, ~1 week combined, no engine change):

1. **Fix the board and make BREATHE the primary spreader with correct-tier fan-out aprons** — retires the 54%-empty-yet-cramped symptom and the fan-out ratchet debt (the two most-visible complaints).
2. **Freeze the SoM/DF40 datum and add the escape seat pre-check to acceptance** — makes T2 robust on the fixed board (the user's stated end-goal).

Together these fix the **three headline symptoms** (empty-yet-cramped, fan-out debt, T2 fragility) *without* touching `place_near`, the relaxation, or the search structure, and ship entirely behind the existing gate suite (LAW-4-clean). Everything past Step 2 is real engineering (M/L, medium+ risk) buying *objective quality and runtime*, not fixing a broken board — so it should be justified by measured gate-score headroom, not built on principle.

---

*Total to full target (Steps 1–5): ~4–6 weeks, medium aggregate risk, best sequenced so the two size-S steps land first and de-risk the rest. Minimum-viable (Steps 1–2): ~1 week, low risk, captures the 80%.*
---

## MEASURED RESULTS (2026-07-04) — the empirical verdict

Four independent experiments (3 workflows + a hands-on airwire decomposition), all on the FIXED 178×163 board, all gate-verified, master-safe:

**1. Airwire decomposition (hands-on).** The 15,186 mm cross-airwire = **58% HUB** (part↔SoM DF40; packing-bound, near-irreducible) + **42% PEER** (subsystem↔subsystem, 6,462 mm — the only improvable part). Peer airwire concentrates in a few mis-placed coupled pairs: `hdmi_rx↔hdmi_rx_term` 68 mm apart (also an **SI defect** — TMDS stub), `usb_jtag↔connector` 110 mm, the bringup cluster — while `ethernet↔rj45` is 16 mm.

**2. Global QP relaxation (Step 3) — NEGATIVE.** CG solve on block centroids: **15,705 mm, +3.4% WORSE**. Minimizes squared (not linear) wirelength + hands off to the same `place_near` legalizer → net loss. Needs Step-4 (min-displacement legalizer) to pay off. Banked `wip/global-qp`.

**3. `AFF_POW` sweep — greedy is a genuine concave optimum.** 1.0 (undistorted) = **+2.4% worse**; 2.0 = +2.4% worse AND breaks fan-out; 1.6 (current) is the minimum. The objective "distortion" is load-bearing, not obsolete.

**4. Surgical clustering fix — diagnosis CONFIRMED, blocked on the fixed board.** Root cause: `ethernet`/`usb_pd` carry exclusive weight-60 connector pulls in `floorplan.json`; `usb_jtag`/`hdmi_rx_term` **lack them** (a data gap, not a bug). Adding them proves the 42% peer is improvable: best **−4.1% (→14,558 mm)**, and `hdmi_rx↔term` **68→8 mm (SI defect fixed)**. BUT every co-location either **grows the board** (usb_jtag's n=19 zone needs ≥180 mm width) or **trips the J2 stitch-via gate** (a B.Cu passive shifts into the stitch corridor — the baseline is on a knife-edge). Banked `wip/clustering-fix` (report-only; source left at baseline).

### Conclusion
**Fixed-board cross-airwire is near-saturated by the greedy Lloyd** — proven three ways. The 42% peer *is* improvable (~4% + a real SI fix), but only by unblocking one of two structural gates:
- **A — bottom-channel-keepout unit**: make the J2 stitch-via corridor a HARD placement keepout so passives never intrude → removes the knife-edge fragility AND unlocks the `hdmi_rx_term` co-location (SI fix + airwire). Fixed board, no growth. *(LAW-0-adjacent: return-path corridor.)*
- **B — board growth** (escape-safe via the Step-2 datum-freeze): the unbounded path to real fan-out + the `usb_jtag` co-location.

### Landed
`place_near` expanding-ring speedup (I2) — byte-identical, faster engine (`75fa591`).

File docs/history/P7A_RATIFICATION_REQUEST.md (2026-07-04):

# P7a ETHERNET WAVE — Ring-0 RATIFICATION REQUEST

**Thread:** P7a ethernet (Opus, Ring-2), worktree `.claude/worktrees/p7-ethernet`, base `35cc213`.
**Status:** items 2–4 (template + wiring + red→green) delivered & verified; this request covers the two INTENT EDITS that require Ring-0 ratification before they land in `carrier/floorplan.json`.

There are **TWO** intent edits below. Edit **B (ethernet exclusive pull)** is *spec-pre-sanctioned* by the T1 D-1 ledger rule and is REQUIRED for the ethernet wave to go green without a seat-consistency advisory flag — I have included it in the delivered ethernet wave (it is a `pull` on ethernet's existing `near`, no edge-list change, exactly the usb_pd precedent). Edit **A (corridor clear)** is a NEW edge/anchor move and is delivered as a *proposal only* — I did NOT apply it; the ethernet wave is complete and green WITHOUT it.

---

## RE-VERIFICATION FINDING (LAW: re-verify audit findings) — the F7 squatter is `power_mon`, not `motor_pwm`

The task brief (item 1) names the corridor squatter as *"motor_pwm's ICs (U21001/U21002-class, sheet 21)"*. I re-measured the **live** board (`carrier/Zynq_Carrier.kicad_pcb` @ base `35cc213`, board hash `cbdb25a7…`) before acting. The finding as stated does not hold on the current board; the corrected finding is:

| Claim in brief | Live-board truth (re-verified) |
|---|---|
| motor_pwm ICs squat in the ethernet corridor | **motor_pwm is already on the W edge** (bbox `27.3,119.2 → 47.4,137.7`; its ICs U36001/U36003 at x≈30–36, hard against its own W-edge PWM header). It is NOT in the corridor. |
| The squatters are U21001/U21002, sheet 21 | U21001/U21002 exist and DO squat the corridor — but they are **`power_mon`** (the 2×INA3221 rail-telemetry sheet, `interior.side=E`), **not motor_pwm**. sheet-21 refdes now map to power_mon. |

**Corridor measured (live):**
- `ethernet` zone bbox `137.8,59.0 → 151.3,78.5` (E interior, `near: rj45_connector`).
- `rj45_connector` bbox `142.0,52.6 → 194.6,73.5` (E edge, mating face off-board +X).
- **`power_mon` bbox `137.7,64.1 → 158.0,86.1`** — overlaps the ethernet zone in X, and its ICs **U21001 @ (153.5,65.6)** and **U21002 @ (153.5,71.1)** sit in the ethernet↔rj45 line-side corridor (x∈[151.3, 194] between ethernet's media edge and the jack), exactly the F1/F7 defect, just on the correct sheet.
- Other corridor-region parts (motor_sense D37001/U37002; usb_uart/usb_jtag passives) are edge/adjacent-zone spill, low-severity, NOT the primary squatter.

So the corridor-clear intent is about **relocating `power_mon`**, whose electrical home is beside its flow-downstream `power_som` / the SoM power (it monitors +VIN/+5V/+3V3/+1V8 rails), NOT in the ethernet analog line side. This *strengthens* the original intent: moving power_mon toward power_som both clears the ethernet moat AND shortens the `power_mon→power_som` flow (47.19mm today).

---

## INTENT EDIT A — corridor clear (power_mon) — **PROPOSED, NOT APPLIED, awaiting ratification**

**What:** re-anchor `power_mon` off the raw E side and toward its downstream `power_som` (board interior / SE-center), so its INA3221 pair vacates the ethernet↔rj45 corridor.

**Exact JSON diff** (`carrier/floorplan.json`, `interior.power_mon`):

```json
// BEFORE
"power_mon": { "side": "E" },
// AFTER (option A1 — near its flow-downstream; connectors unchanged, no edge-list move)
"power_mon": { "near": "power_som" },
```

Rationale for `near: power_som` over a raw side flip:
- power_mon's only external flow term is `flow: [power_mon, power_som]`; `near` seats it at power_som's x/y (the first-fit-nearest-anchor lever, `floorplan.py:807`), which is SE-center — clear of the NE ethernet corridor.
- It is an anchor change only (no edge-list edit → no connector re-seat, unlike D9), so blast radius is bounded to power_mon's own zone + second-order L4 re-slides.
- It shortens `power_mon→power_som` flow (a free composition win) instead of degrading it.

**Why this needs ratification (not auto-applied):** it is a NEW floorplan intent (changes where a shipped subsystem seats), i.e. the `--allow-intent` class per T1 §5 law 4 / P8 precedent — never a tuning edit. It also touches the E-band packing (fmc/power/bringup neighbours), so it must go through the banded-monotone acceptance + full `schgen board` + render verdict on the rebuilt board. I have NOT run that accept loop (the edit is un-applied); Ring-0 should either ratify (then I apply + gate + render + report deltas) or supply the preferred target.

**Acceptance I will run once ratified:** all gates green on the rebuilt board; `A' ≤ 25,670`; power_mon→power_som flow no-worse; ethernet corridor visibly clear in the t1↔rj45 crop; near_max/far ethernet terms stay green; build-twice byte-identical; ledger entry.

**Blocked-work note:** per the task, items 2–4 do NOT depend on Edit A and are delivered complete + green. If Ring-0 declines/defers Edit A, the ethernet wave still stands: the corridor squatter is a *composition* concern (power_mon's pose), not an ethernet-zone or wiring defect, and the ethernet near_max/far terms are green regardless of where power_mon sits (they measure ethernet↔rj45 and ethernet↔power, not ethernet↔power_mon).

---

## INTENT EDIT B — ethernet exclusive pull (D-1 ledger rule) — **APPLIED in the delivered wave** (ratify to keep)

**What:** add an exclusive `pull` to ethernet's existing `{"near":"rj45_connector"}`, mirroring the usb_pd P3 precedent, so the D-1 seat-consistency advisory stays green when ethernet is wired.

**Exact JSON diff** (`carrier/floorplan.json`, `interior.ethernet`):

```json
// BEFORE
"ethernet": { "near": "rj45_connector" },
// AFTER
"ethernet": {
  "near": "rj45_connector",
  "pull": {
    "to": "rj45_connector",
    "weight": 60.0,
    "face": "inboard",
    "exclusive": true,
    "basis": "D11 near_max edge-gap <=20mm proxy for Pulse v7 p.1 <=25mm part-to-part (T1 P7a, ethernet wave): magnetics seat at the RJ45 jack. Migrated per D-1 seat-consistency rule when ethernet joins _WIRED_SHEETS — same mechanism as usb_pd's pd_input pull."
  }
}
```

**Why this is spec-pre-sanctioned (D-1):** T1 §0 decision D-1 states verbatim *"Ethernet's seat at its wave is therefore a reviewed one-line spec diff, not silent behavior."* The D-1 seat-consistency advisory (`compose_repair._seat_consistency`) flags *any WIRED near_max term whose subject is an interior block anchored `{"near":<edge block>}` without an exclusive pull*. Once ethernet is in `_WIRED_SHEETS`, its near_max→rj45 term meets that precondition exactly (ethernet is interior, rj45_connector is an E-edge block), so the advisory WOULD flag ethernet without this pull. The pull is the sanctioned migration of the seat from packing-luck to the validated knob.

**weight=60.0, face=inboard, exclusive=true** match the usb_pd exemplar (`interior.usb_pd.pull`) 1:1; the loader invariants (`_validate_pull`) pass (near==pull.to==rj45_connector, rj45_connector on an edge list, basis non-empty).

**Verified effect (delivered board):** ethernet near_max→rj45 stays `0.00mm gap / <=20mm` GREEN; seat-consistency advisory clean; board byte-identical to the no-pull ethernet wave (the pull reproduces the seat the `near` already produced — ethernet's zone already abuts rj45 at 0.00mm; the pull makes that seat *authored* rather than incidental).

---

## INTENT EDIT C — area escalation: +0.66% board growth (datasheet-forced) — **needs Ring-0 area judgment**

**What:** wiring ethernet grows the board **170×151 = 25,670mm² → 170×152 = 25,840mm² (+170mm², +0.66%)**, exceeding the P0 ledger area cap (`cumulative_area_cap_mm2 = 25,670`).

**Why it is forced (not a search artifact — proven):** I pinned the outline to a fixed `170×151` and rebuilt; the packer FAILS with *"the REAL 2-sided packed blocks do not fit the fixed outline 170x151"*. The datasheet-faithful ethernet zone is intrinsically larger than the size-sorted legacy shelf-pack it replaces:
- legacy (size-sorted) ethernet zone: **14.3 × 20.66 ≈ 295mm²**
- template (datasheet Bob-Smith at MCT pins + C5 barrier + media-facing turn): **25.51 × 21.75 ≈ 555mm²**

The +260mm² zone is real copper the datasheet layout requires (each channel's 75R‖1n at its own centre tap, all on the media side facing the jack). Per the "never redraw/bend a part to fit the tool" law I did NOT compress it. I also verified the growth is **independent of Edit A** (moving power_mon to `near:power_som` still yields 170×152) — so it cannot be recovered by the corridor clear either.

**Escalation basis (spec §5 law 4 / A3):** *"a `--allow-intent` edit failing ONLY `A' ≤ A` is reported with measured growth and deferred to the orchestrator's ~+5% wave judgment — never silently vetoed."* +0.66% is far inside the spec's per-wave ~+5% allowance. The wave BUYS: ethernet contract violations **23 → 0** (Bob-Smith at MCT pins, media row faces the jack — the F1 fix), and the flow terms improve (power→power_som 63.12→39.16mm, usb_pd→power 110.37→112.42mm). Every hard gate is green at 170×152 (DRC 0, RATSNEST, PLACEMENT CONTRACT 32/0, PLACEMENT FLOW 3-contract, COMPOSITION hard-RED 0, RETURN STITCH 29/29, THERMAL 0-over-limit).

**Requested:** ratify the +0.66% as the ethernet wave's area cost (I will re-base the ledger `cumulative_area_cap_mm2` to 25,840 with this basis on your go), OR direct a recovery avenue (P10 `_rotate_zone_90` is the spec's designated area-recovery unit; it is out of this wave's scope).

---

## SUMMARY FOR RING-0

- **Ratify B** (already applied, spec-pre-sanctioned by D-1): keeps the delivered ethernet wave's seat authored + the ledger advisory green.
- **Ratify or redirect A** (proposed, un-applied): the corridor squatter is `power_mon`, not motor_pwm; move it toward power_som. I will run the full accept loop + render verdict on your go.
- **Ratify or redirect C** (delivered board is at +0.66%): datasheet-forced board growth to 170×152; a `--allow-intent`-class area judgment, not a defect. All gates green; growth proven un-recoverable within this wave.

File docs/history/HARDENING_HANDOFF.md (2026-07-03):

# HARDENING WAVE HANDOFF — bottom-mirror convention unification

**Worktree:** `.claude/worktrees/hardening` @ base `9f77031` (branch state: 11 modified
files + 2 new, ALL uncommitted — do NOT stash, fleet protocol). Written for a successor
agent with NO access to the prior context. The defect is registered in
`AI_LAYOUT_ROUTING_CONCEPT.md` ("T2 COMPLETE + two engine discoveries", the D13
sections, and the new "BOTTOM-MIRROR CONVENTION UNIFIED" section appended at the end —
read those first).

## 0. The defect and the decree

The in-process pad-geometry model **X-mirrored bottom-side footprints**; EMISSION
(`embed._flip_to_bottom`) keeps local coordinates unchanged and swaps only layer
tokens, and KiCad loads a B.Cu footprint applying **only the placement rotation** —
the stored local frame IS the final front-view frame. Direction ordered: **unify every
in-process consumer to the EMISSION truth (unmirrored)**, prove red-on-before, guard
with tests, report every scalar shift loudly (LAW 4: a gate flipping red under
corrected geometry is a REAL hidden violation — never soften).

## 1. Ground truth (re-proven this wave, not assumed)

- **pcbnew 10.0.2** (KiCad.app's own Python:
  `/Applications/KiCad/KiCad.app/Contents/Frameworks/Python.framework/Versions/Current/bin/python3`,
  `import pcbnew`) loaded the emitted board: **every pad of all 564 footprints
  (2387 pads, both sides) sits at `fp_at + R_cw(rot)·(px,py)`** — worst residual
  0.7 µm (rounding). R_cw on the +y-down page: `gx = x + px·cos + py·sin,
  gy = y − px·sin + py·cos`. NO side-dependent mirror anywhere.
- Pad angle in the emitted file = fp_rot + pad_rot (embed `_rotate_pad`); pad local
  x/y are stored UNROTATED. Position math must ignore the stored pad angle.
- Two pcbnew quirks discovered (benign, documented in the parity test):
  - **F.Paste-only pads** (paste apertures of multi-piece pads: BT3001, L20001/2,
    L22003, U16001/17001/21001/2, U27001, U37002, D37001, J15001) get their number
    AND net **blanked by pcbnew on load** (copper-less pads can't carry nets). In the
    FILE they are numbered+netted. Not a defect.
  - **U17001's 4 blank EP thermal-via pads**: model `pad_nets` says `""`, emitted file
    says `GND` — `embed._thermal_via_nets` assigns the EP net at EMBED time,
    downstream of the model. Pre-existing, conservative, documented.

## 2. Red-on-before (MEASURED, pre-fix)

Method: `build_model()` in-process → `_inst_pad_geom` dump vs pcbnew dump of the
byte-identical emitted board (scripts survive at
`/private/tmp/claude-501/-Users-nicholasantoniades-Documents-GitHub-Zynq-SoM-som/7d661532-7b13-4bb9-8af6-1ea94d8323a5/scratchpad/dump_model.py`
and `dump_pcbnew.py`; artifacts `board_before.kicad_pcb`, `pcbnew_pads.json`,
`reports_before/`).

- Board population: 564 footprints — 245 top, **319 bottom** (140 C, 172 R, 5 RS
  RLM12 2-pad shunts, 2 RN 4D03WGJ0330T5E 8-pad arrays). Rotations: 314×0°, 5×90°
  (C11001–05, fmc).
- **Pad POSITION multisets agreed** (every bottom footprint bbox/pad-set is exactly
  X-symmetric — measured asymmetry 0.000000 on all 8 distinct bottom footprints), so
  packing/courtyard consumers had NO live geometric error.
- **NET-at-position was wrong on 319/319 bottom parts — all 650 bottom pads.**
  Per-pad displacement histogram (mm→pads): 0.79×8, 1.55×208, 1.65×344, 1.9×58,
  2.4×8, 2.95/2.96×24. Examples: C16003 (microsd 0805) `+3V3_SD` modeled at its GND
  pad's true spot (ΔX +1.90); RN36001 `ESC_SIG0` 2.40 mm off; worst RS37001 2.958 mm.
- TOP side: zero geometry deltas, zero net-at-position errors (the 11 apparent ones
  were the pcbnew paste-aperture quirk above).
- Entry-guard premise CONFIRMED: zero polarized/active/chiral bottom parts today.
  The 4D03 array is mirror-safe (elements 1-8/2-7/3-6/4-5 straight across, all 33Ω).
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

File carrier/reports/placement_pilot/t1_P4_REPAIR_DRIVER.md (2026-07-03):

# T1 P4 — repair driver (`schgen compose`) — evidence

Delivered (uncommitted, for Ring-0 review):

- `schgen/generate/compose_repair.py` driver half:
  - `SpecEdit` catalog: `AddPull` (ladder 2/5/10/20/40/60 — judgment:
    doubling ladder bounded by the D11-proven 60.0 seat weight; refuses a
    second pull per block), `SetPullWeight` (ladder above current),
    `MoveEdgeBlock` (INTENT — reachable only via `--allow-intent
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

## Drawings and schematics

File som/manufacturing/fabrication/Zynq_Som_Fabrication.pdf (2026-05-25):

## Layer Stack Legend

# Layer 0.0764 mm

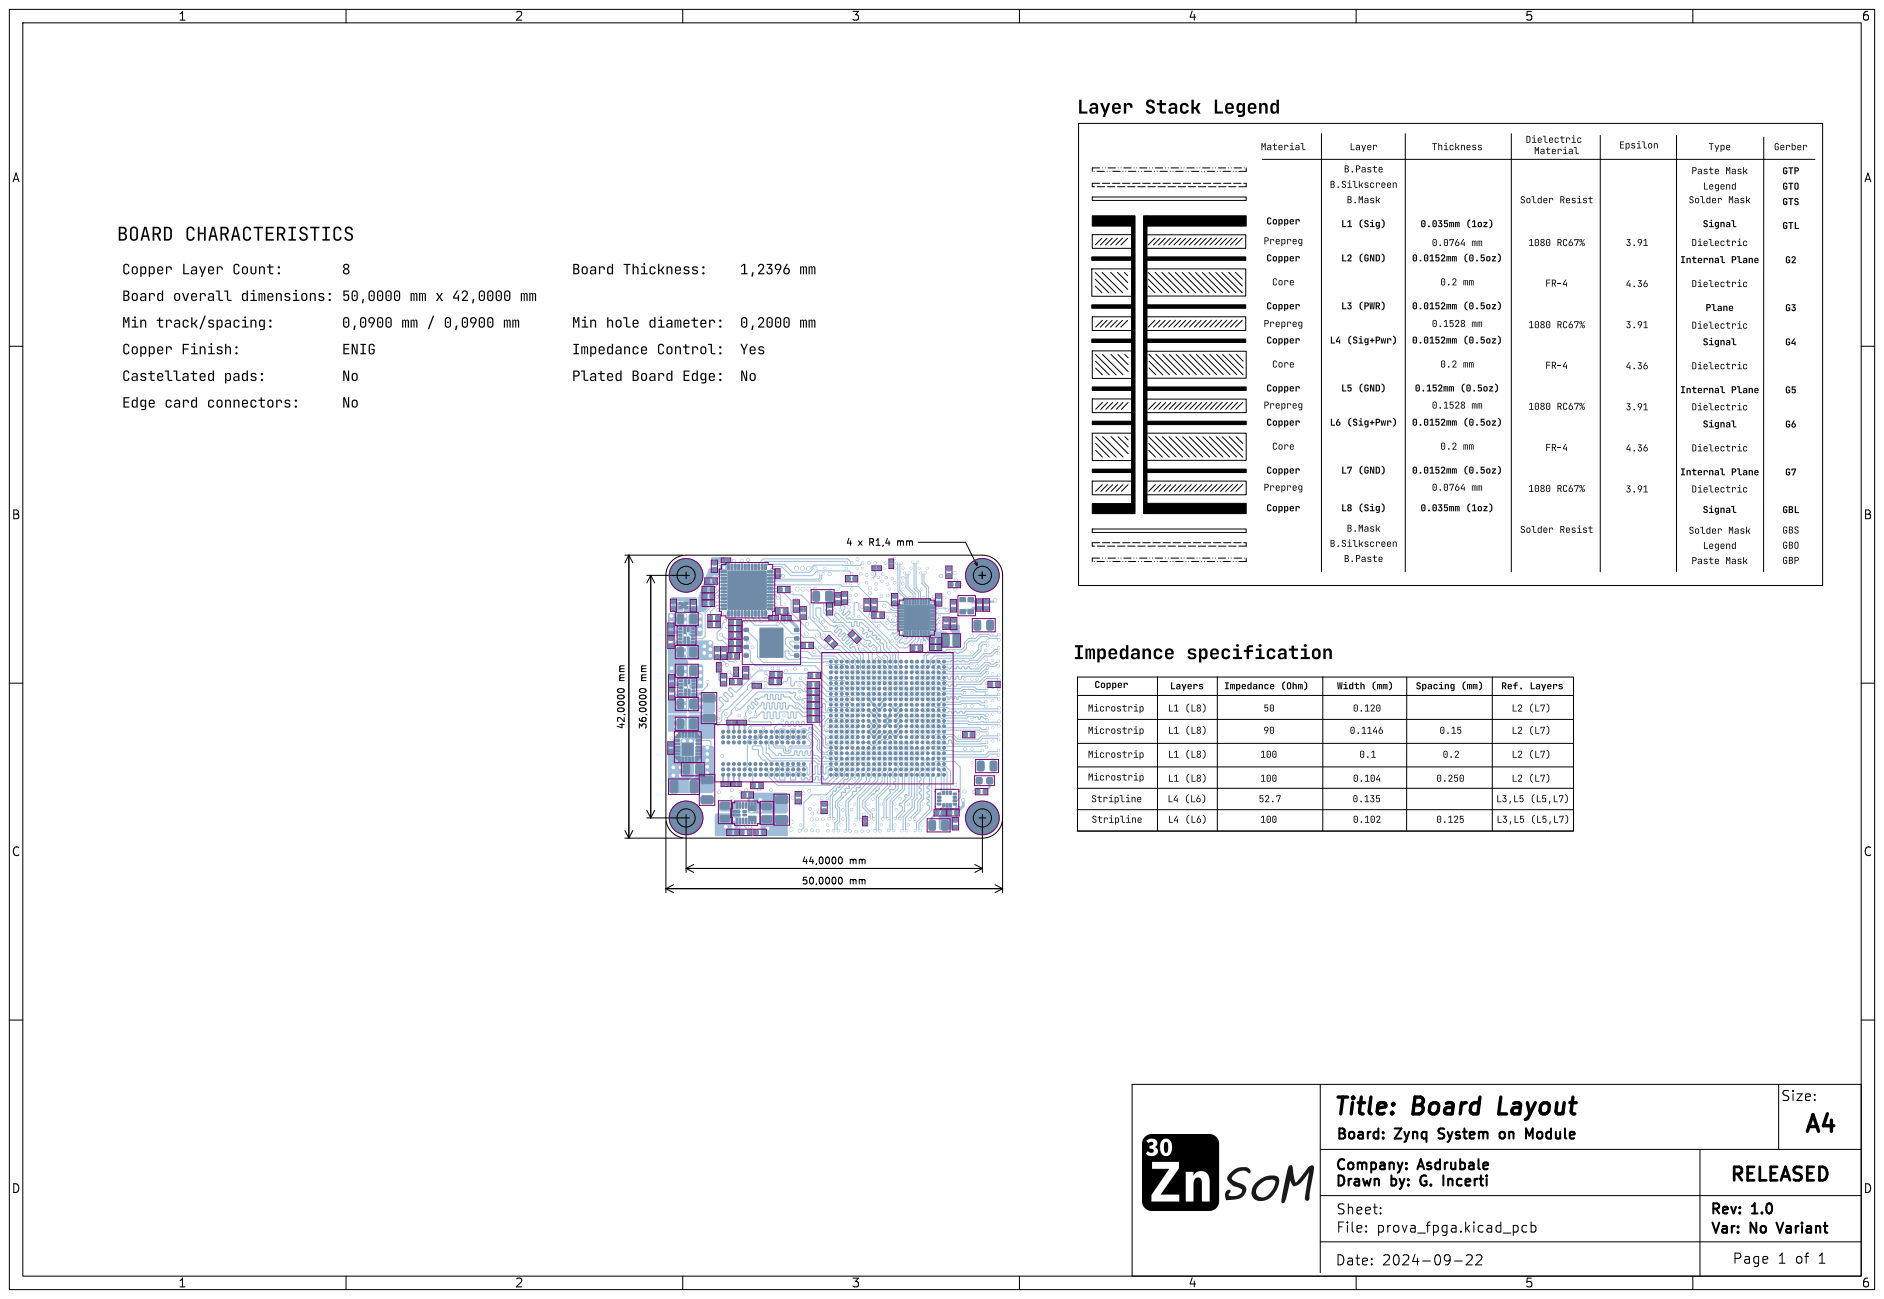
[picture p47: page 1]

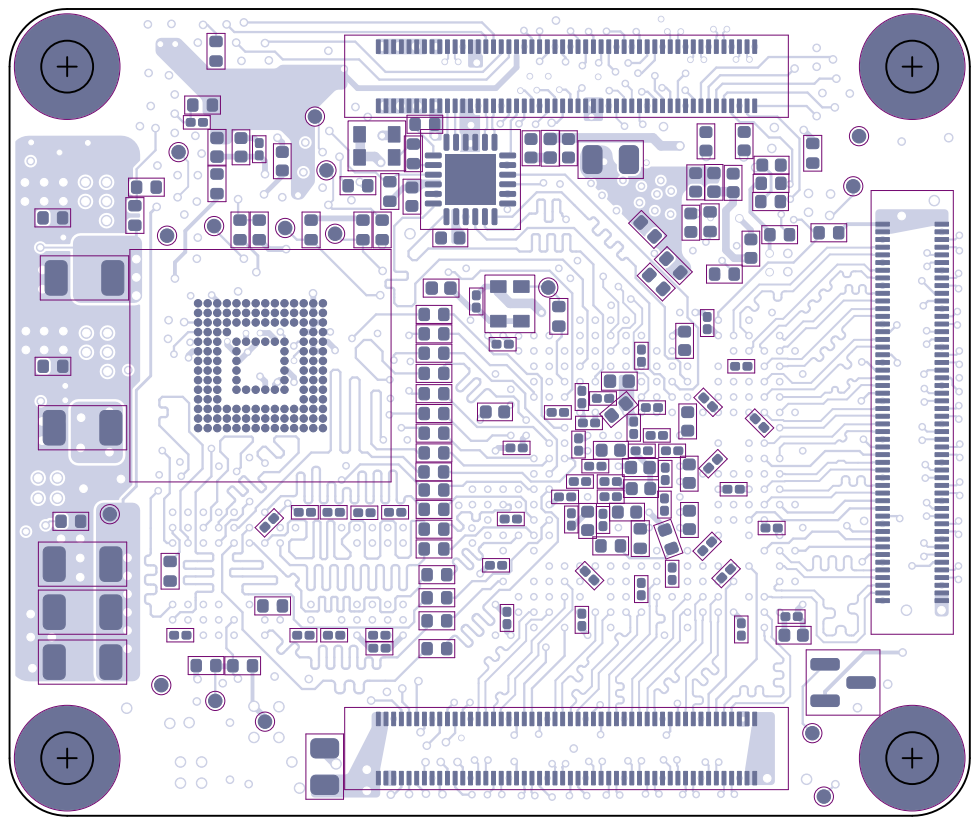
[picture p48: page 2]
D Date: 2024-09-22; Rev: 1.0 Size: Page 1 of 1 Title: Board Layout File: prova_fpga.kicad_pcb Sheet: Company: Asdrubale; Drawn; by: G. Incerti; Var: No Variant Board: Zynq System on Module; RELEASED

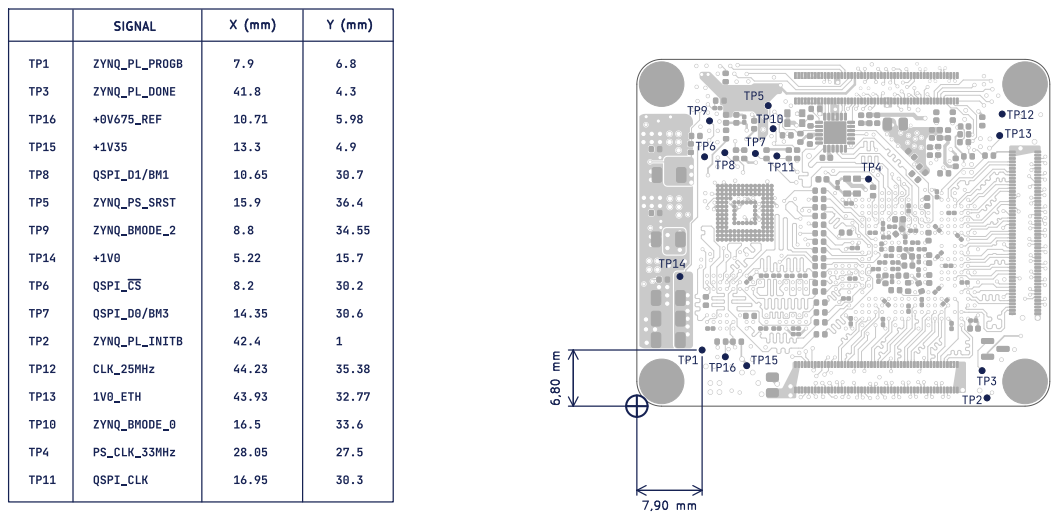
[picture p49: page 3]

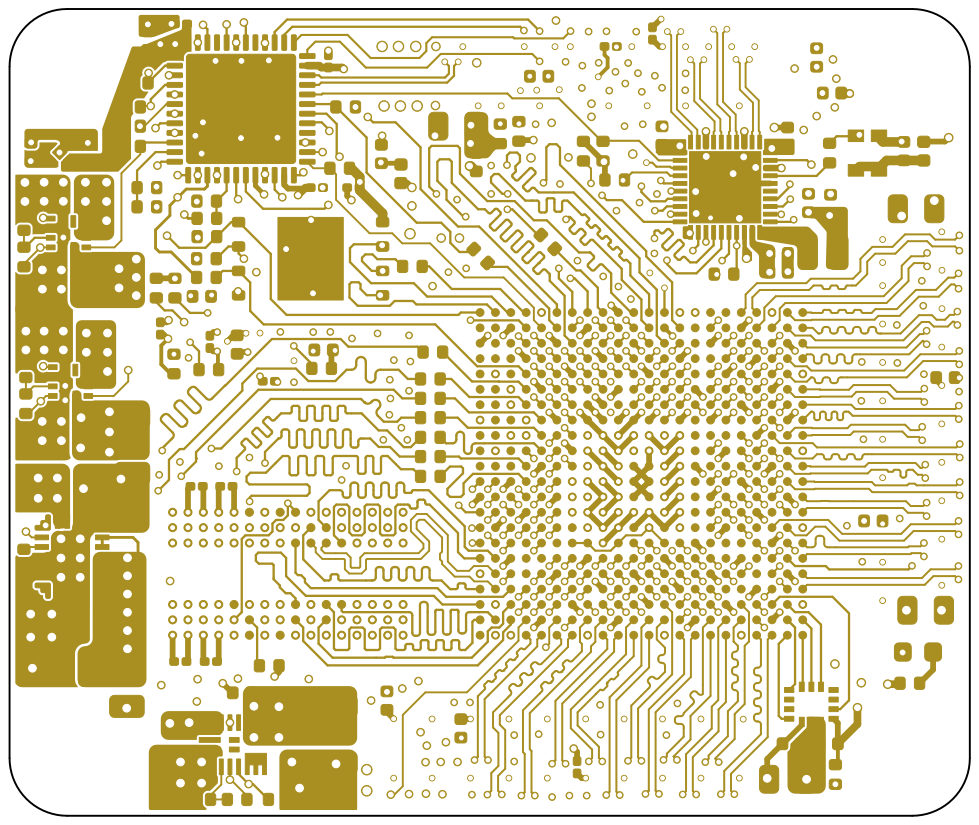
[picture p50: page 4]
D Date: 2024-09-22; Rev:; Size: Page 1 of; 1 Title: Board Layout File: prova_fpga.kicad_pcb Sheet: Company: Asdrubale; Drawn; by: G. Incerti; Var:; No Variant Board:; Zynq System on; Module; RELEASED

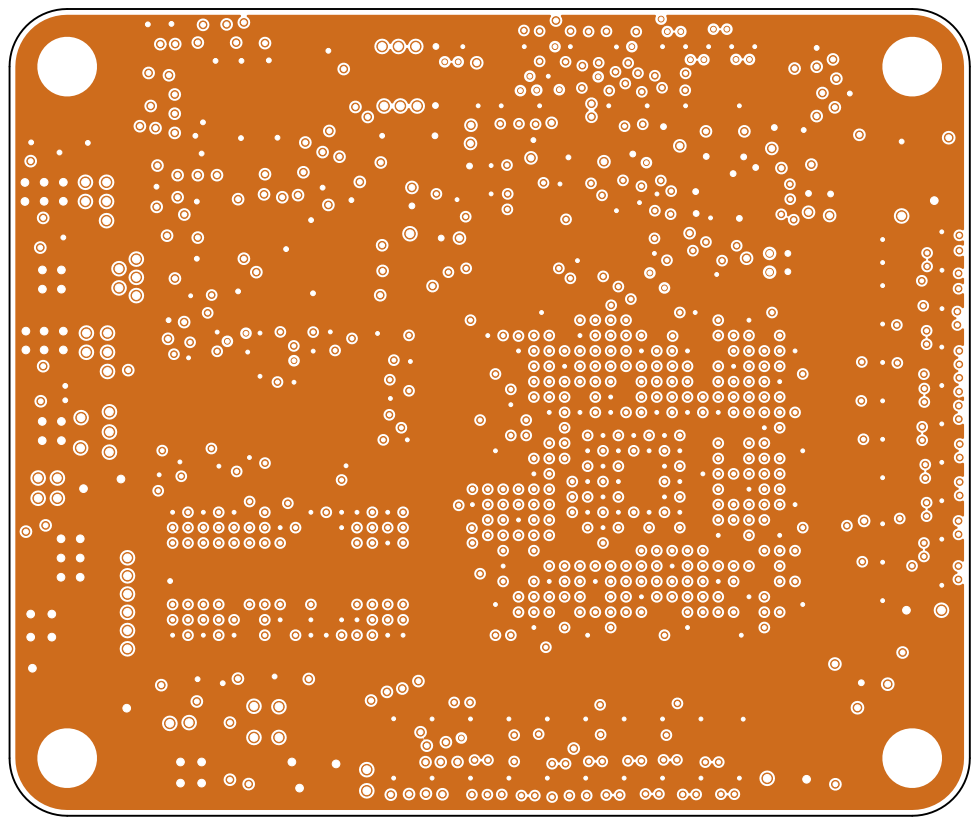
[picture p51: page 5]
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

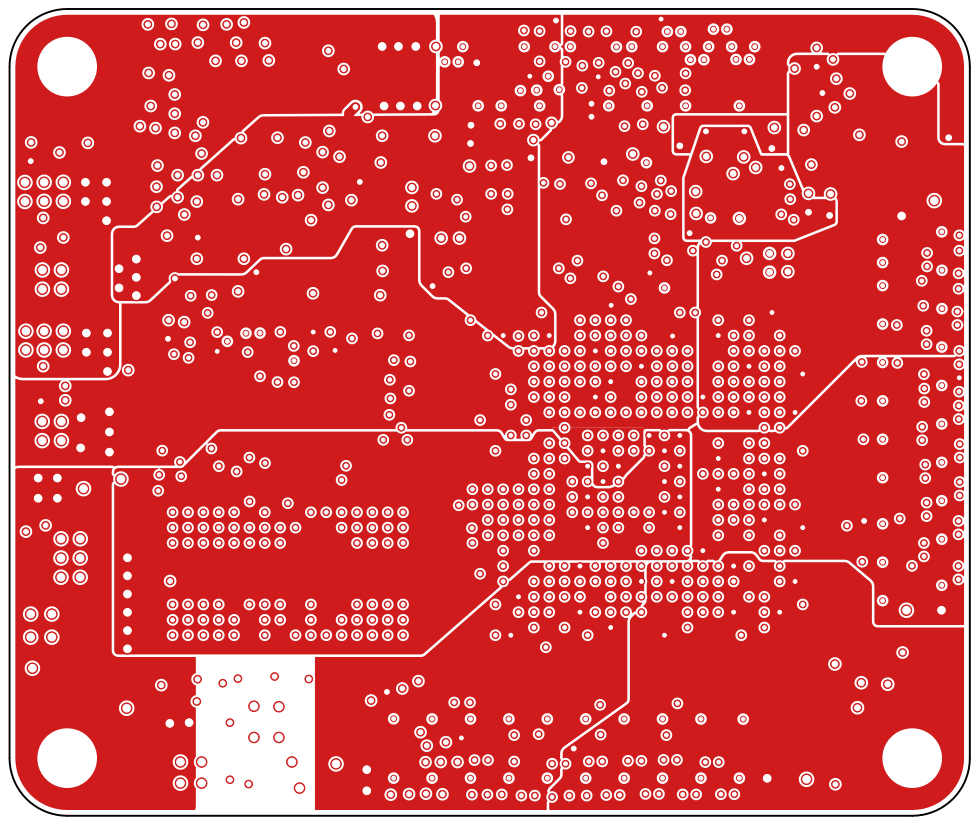
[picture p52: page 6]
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

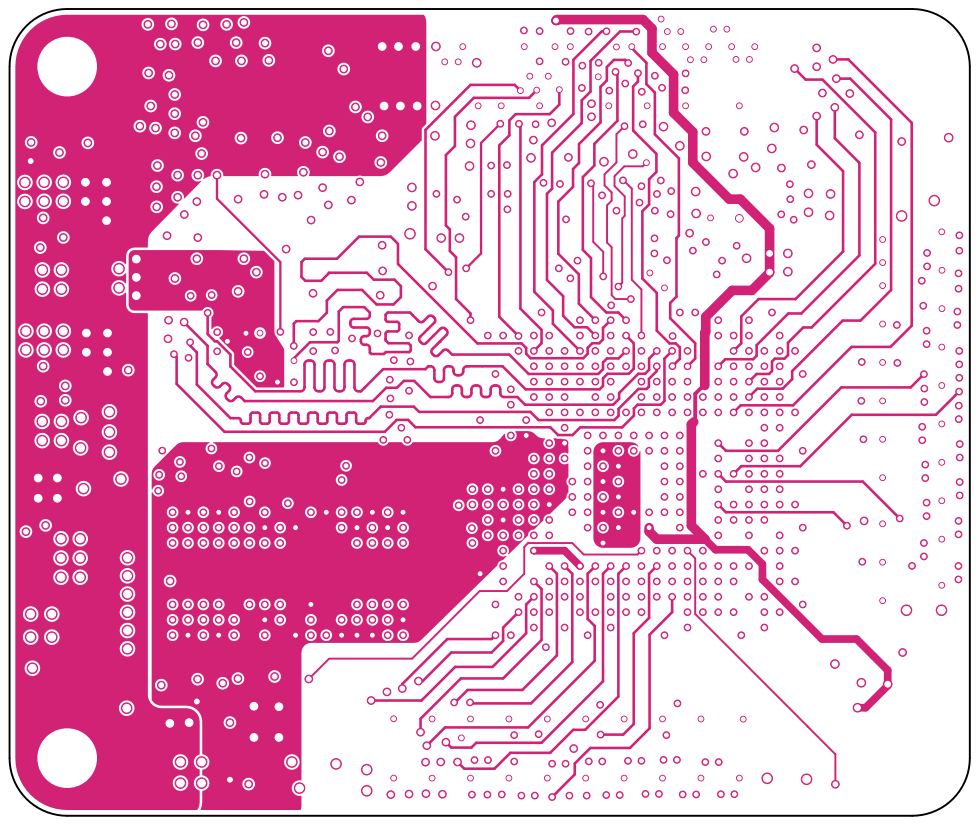
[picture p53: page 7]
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

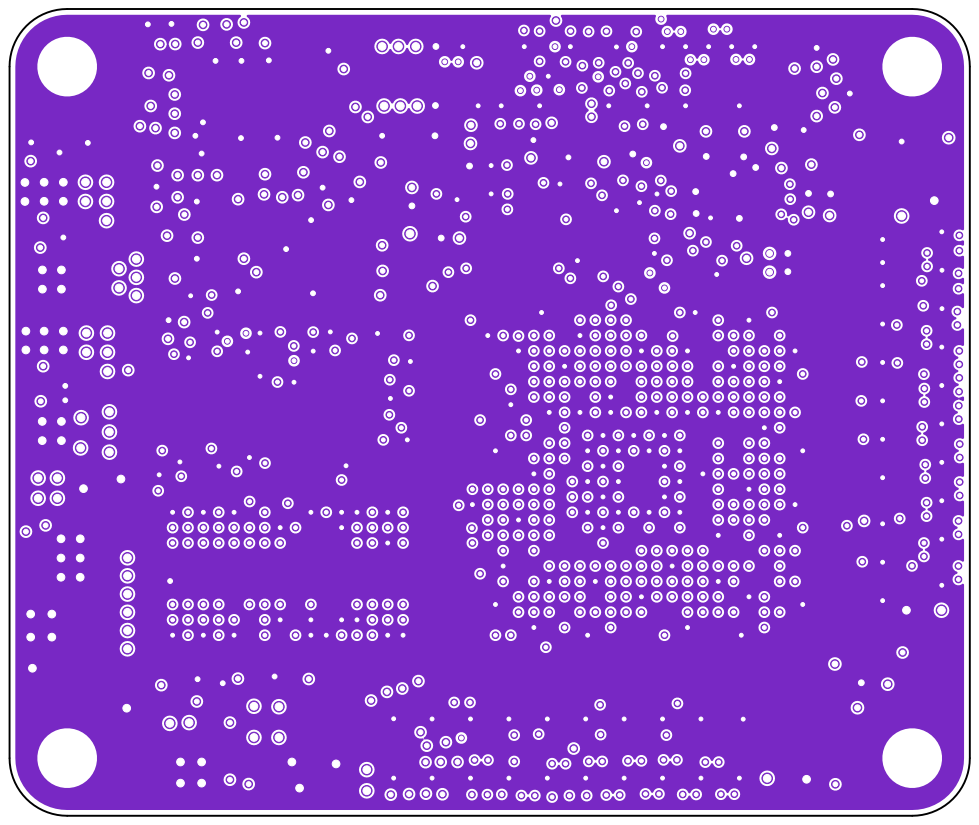
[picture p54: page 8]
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

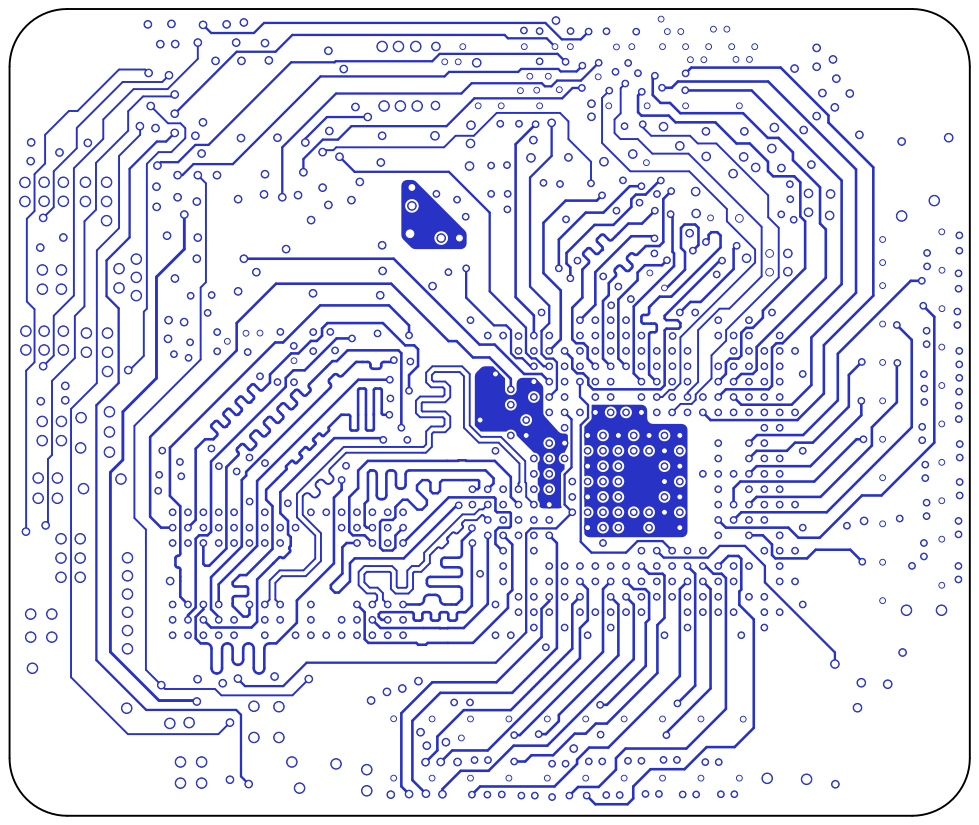
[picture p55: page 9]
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

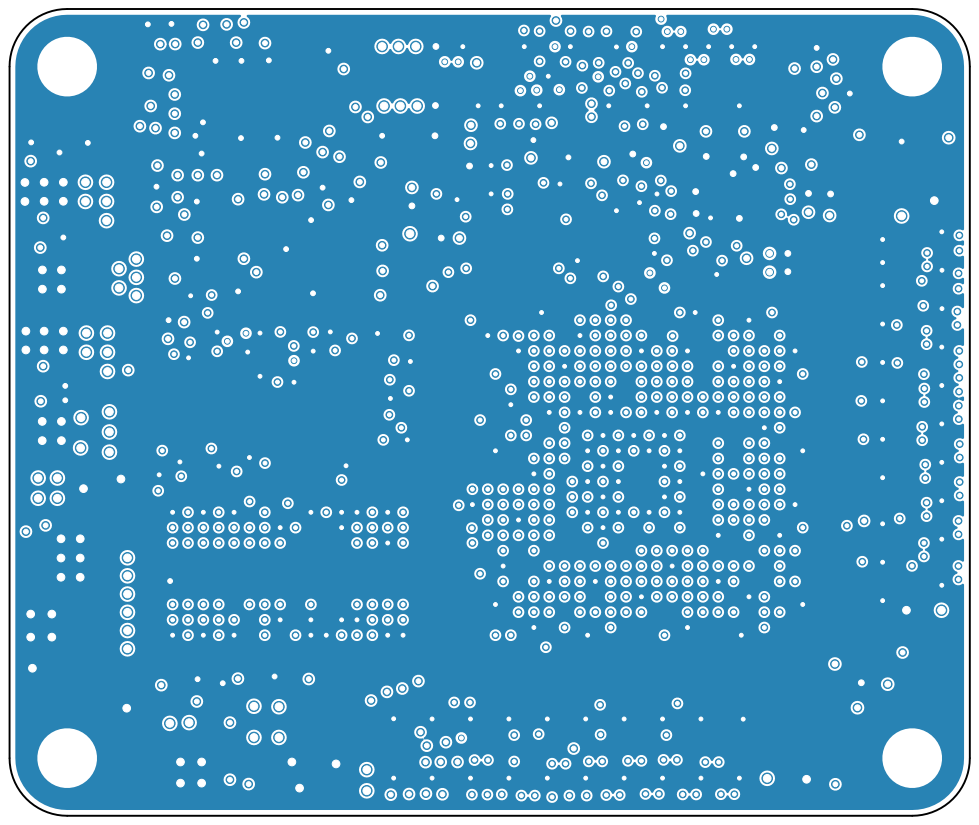
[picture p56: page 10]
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

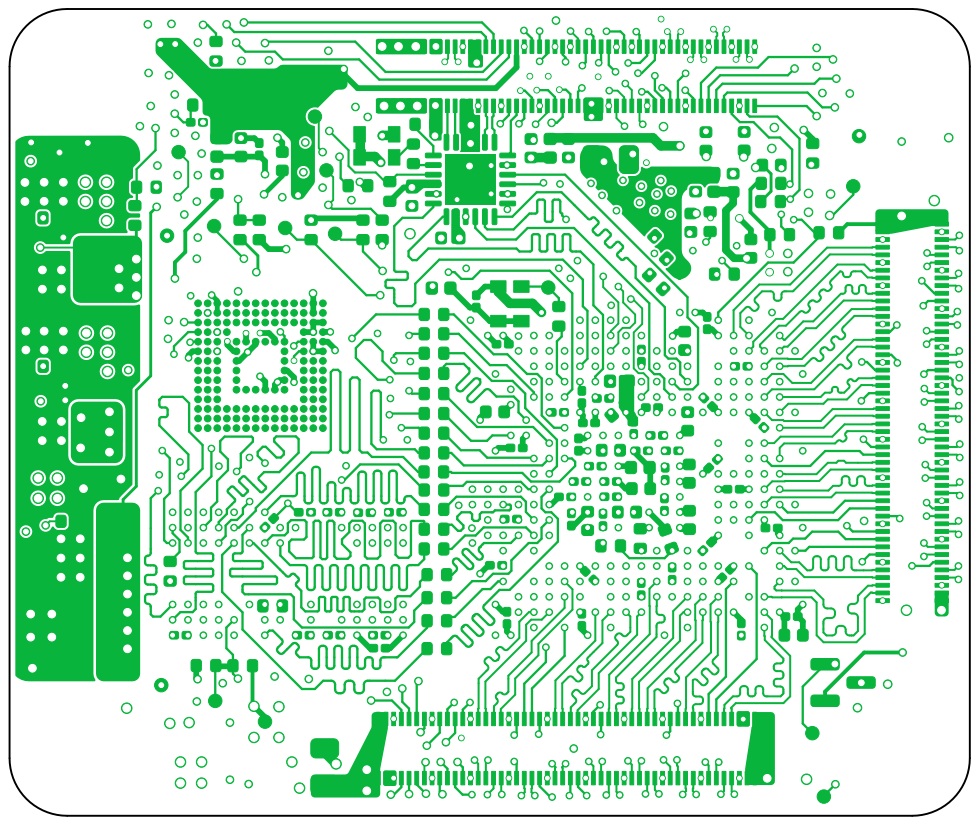
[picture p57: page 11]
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

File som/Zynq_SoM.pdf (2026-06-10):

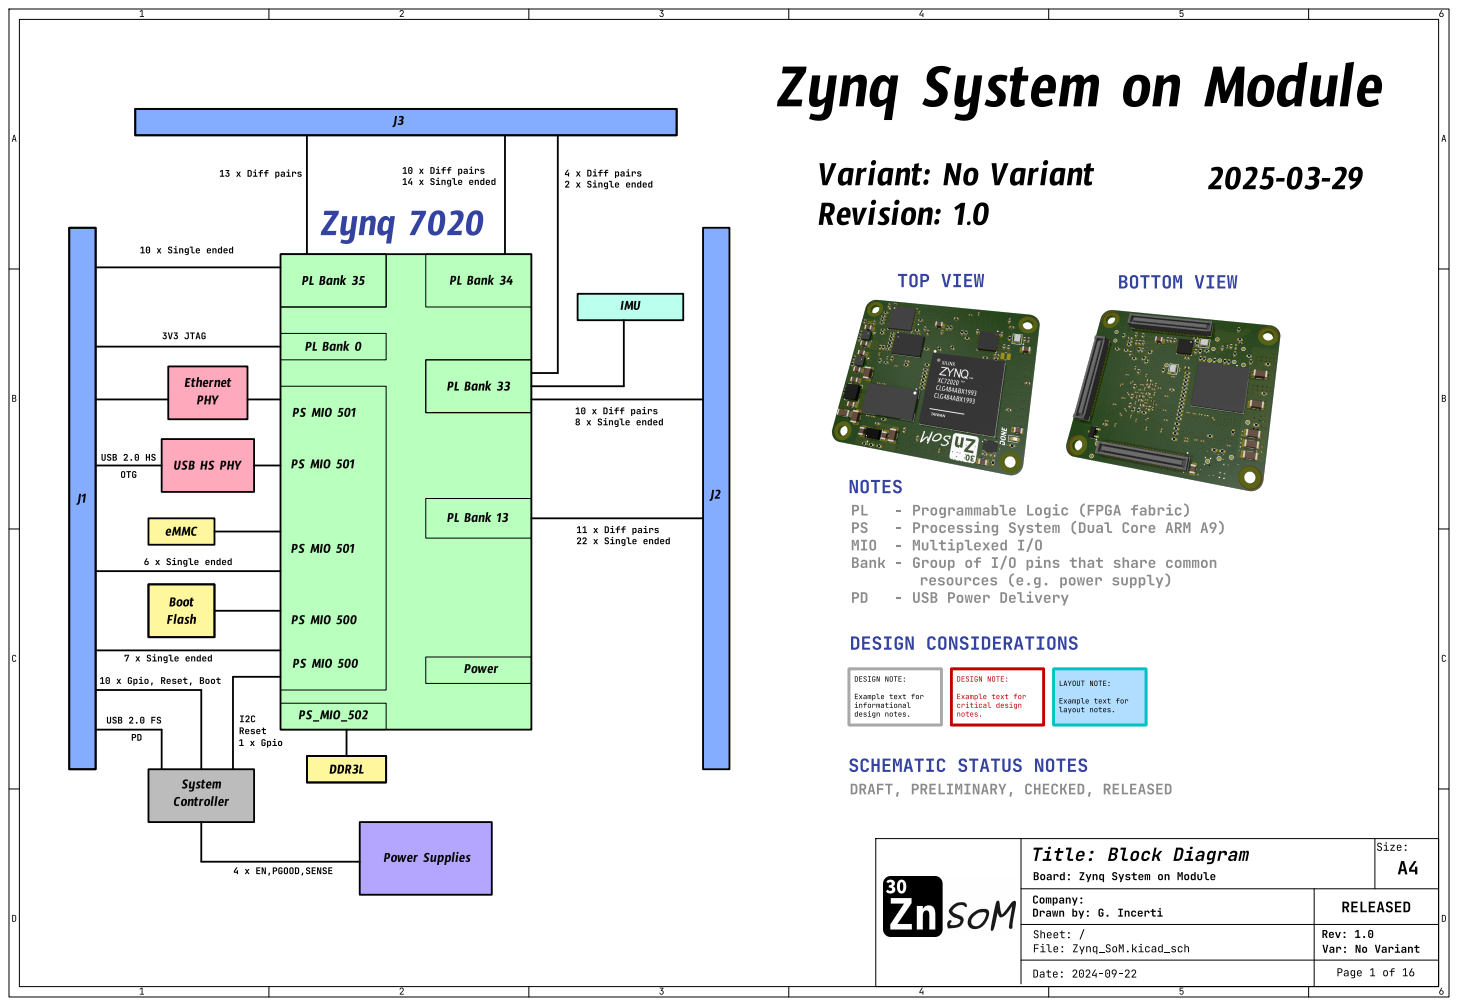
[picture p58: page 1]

10 x Diff pairs 14 x Single ended | 2 x Single ended Zynq7020

PLBank35 | PLBank34

NOTES
Bank - Group of I/O pins that share common

7 x Single ended USB 2.0 FS

10 x Gpio, Reset, Boot PD

notes. DESIGN NOTE: Example text for

SCHEMATICSTATUS NOTES
DRAFT, PRELIMINARY, CHECKED, RELEASED


SCL TO ETH PHY

TO J1 TO USB PHY
TO PSupply


I N | | 4.2-5V | I_{MAX} 1.2-3.3V 3.7A

V_{IN} DDR3L V_{CCO_DDR_502} 3V3 EN 1V8 EN 1V0 EN 1V35 EN

Mandatory used for ETH_PHY_INT VIN

ZYNQ PL B35 ZYNQ PL B33 3V3 (300mA)

V_{CCIO13} | | 1.2A

V_{CCIO33} | 1.2-3.3V | 1.2A

ETH PHY, USB PHY, eMMC
V_{CCPAUX}, V_{CCAUX}, V_{VCCPLL}
V_{CCADC}, V_{CCBATT}, V_{CCO_MIO1_501}

used for PUDC

ETH PHY, USB PHY, QSPI FLASH

3V3_LDO | | 100mA

DESIGN NOTE: Power ON Sequence: 1. 1V0 Supply 2. 1V8 Supply 3. 1V35 Supply 4. 3V3 Supply Timings are not specified





Bank 501 Zynq PS Banks

enable JTAG, SD or QSPI boot modes Strapping Pins


for BGA fanout Flash Memories

DESIGN NOTE: Pullups DAT min-> 10k, max-> 50k CMDmin-> 4k7, max-> 50k
1% 0402 GND

LAYOUT NOTE: NC pins used




DESIGN NOTE: User for calibration DDR Memory

ended and 80 Ohms differential

impedance for best performance. Routing with





1V8 PWRIN MIO 500 PWROUT PWRIN


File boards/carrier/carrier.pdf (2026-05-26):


power File: sheets/power.kicad_sch

ethernet File: sheets/ethernet.kicad_sch

Sheet: /
File: carrier.kicad_sch
Title: Zynq SoM Carrier

Size: A3 | Rev:
KiCad E.D.A. 10.0.2 | Id: 1/28


Sheet: /power/
File: power.kicad_sch
Title: Power Architecture (USB-C +5V → +3V3 / +2V5 / +1V8)


Sheet: /uart_bridge/
File: uart_bridge.kicad_sch
Title: USB-UART Bridge (CP2102N → Zynq PS UART0)

Sheet: /microsd/
File: microsd.kicad_sch
Title: microSD Card Socket (DM3AT-SF-PEJM5 on Zynq PS SD1)


Sheet: /fmc_lpc_la_low/
File: fmc_lpc_la_low.kicad_sch
Title: FMC LPC bank A (LA00..LA15 differential pairs)


File: jtag_swd.kicad_sch
Title: Debug Headers (Zynq PS JTAG 2x7 + STM32 SWD 2x5)


Sheet: /som_j1_pl_power_gnd/
File: som_j1_pl_power_gnd.kicad_sch
Title: SoM Mate J1 bank C (PL power + GND + config)


Sheet: /som_j3_diff_pairs/
File: som_j3_diff_pairs.kicad_sch
Title: SoM Mate J3 bank A (PL bank 35 differential pairs)


Sheet: /power_mon/
File: power_mon.kicad_sch
Title: Power Monitoring (INA226 on +VIN)


Sheet: /hdmi_tx/
File: hdmi_tx.kicad_sch
Title: HDMI Transmitter (Zynq → TPD12S016 → HDMI-A)

File: lvds_lcd_signals.kicad_sch
Title: LVDS LCD bank A (data + clock + backlight ctrl)


Sheet: /fmc_lpc_la_high/
File: fmc_lpc_la_high.kicad_sch
Title: FMC LPC bank B (LA16..LA33 differential pairs)


Sheet: /boot_switches/
File: boot_switches.kicad_sch
Title: Boot Mode Straps + PS Reset (DIP-4 + Tactile)


Sheet: /som_j2_diff_pairs/
File: som_j2_diff_pairs.kicad_sch
Title: SoM Mate J2 bank A (PL bank 13 differential pairs)


Sheet: /som_j3_se/
File: som_j3_se.kicad_sch
Title: SoM Mate J3 bank B (PL bank 35 single-ended GPIO)


File: usb_pd.kicad_sch
Title: USB-C Power Delivery (FUSB302 + USBLC6 + USB-C)


Sheet: /hdmi_rx/
File: hdmi_rx.kicad_sch
Title: HDMI Receiver (HDMI-A → TPD12S016 → Zynq)

Sheet: /lvds_lcd_power/
File: lvds_lcd_power.kicad_sch
Title: LVDS LCD bank B (panel + backlight power)


ZYNQ_FMC_TRST_N +VADJ +3V3 +VADJ +VADJ +VADJ +3V3 +3V3 GND +VADJ +12V +12V +VADJ

Sheet: /fmc_lpc_power_clk_jtag/
File: fmc_lpc_power_clk_jtag.kicad_sch
Title: FMC LPC bank C (power + clock + JTAG + mgmt)


Sheet: /som_j1_mio/
File: som_j1_mio.kicad_sch
Title: SoM Mate J1 bank A (PS MIO + system rails)


Sheet: /som_j2_se/
File: som_j2_se.kicad_sch
Title: SoM Mate J2 bank B (PL bank 13 single-ended)


Sheet: /som_j3_power/
File: som_j3_power.kicad_sch
Title: SoM Mate J3 bank C (PL bank 35 power + camera ctrl)


File: usbc_otg.kicad_sch
Title: USB-C OTG Port (TPS2051C VBUS switch + USB-C)


Sheet: /ethernet/
File: ethernet.kicad_sch
Title: Ethernet (PHY MDI → HX5008 magnetics → RJ45)

Sheet: /mipi_camera/
File: mipi_camera.kicad_sch
Title: MIPI Camera (15-pin 1 mm FFC, Pi-camera pinout)


Sheet: /pmod/
File: pmod.kicad_sch
Title: PMOD Headers (2× Digilent 12-pin Type 1A)


Sheet: /som_j1_ps_aux/
File: som_j1_ps_aux.kicad_sch
Title: SoM Mate J1 bank B (PS auxiliary: clk, JTAG, DDR straps)


Sheet: /som_j2_power/
File: som_j2_power.kicad_sch
Title: SoM Mate J2 bank C (PL bank 13 power + GND + LVDS)

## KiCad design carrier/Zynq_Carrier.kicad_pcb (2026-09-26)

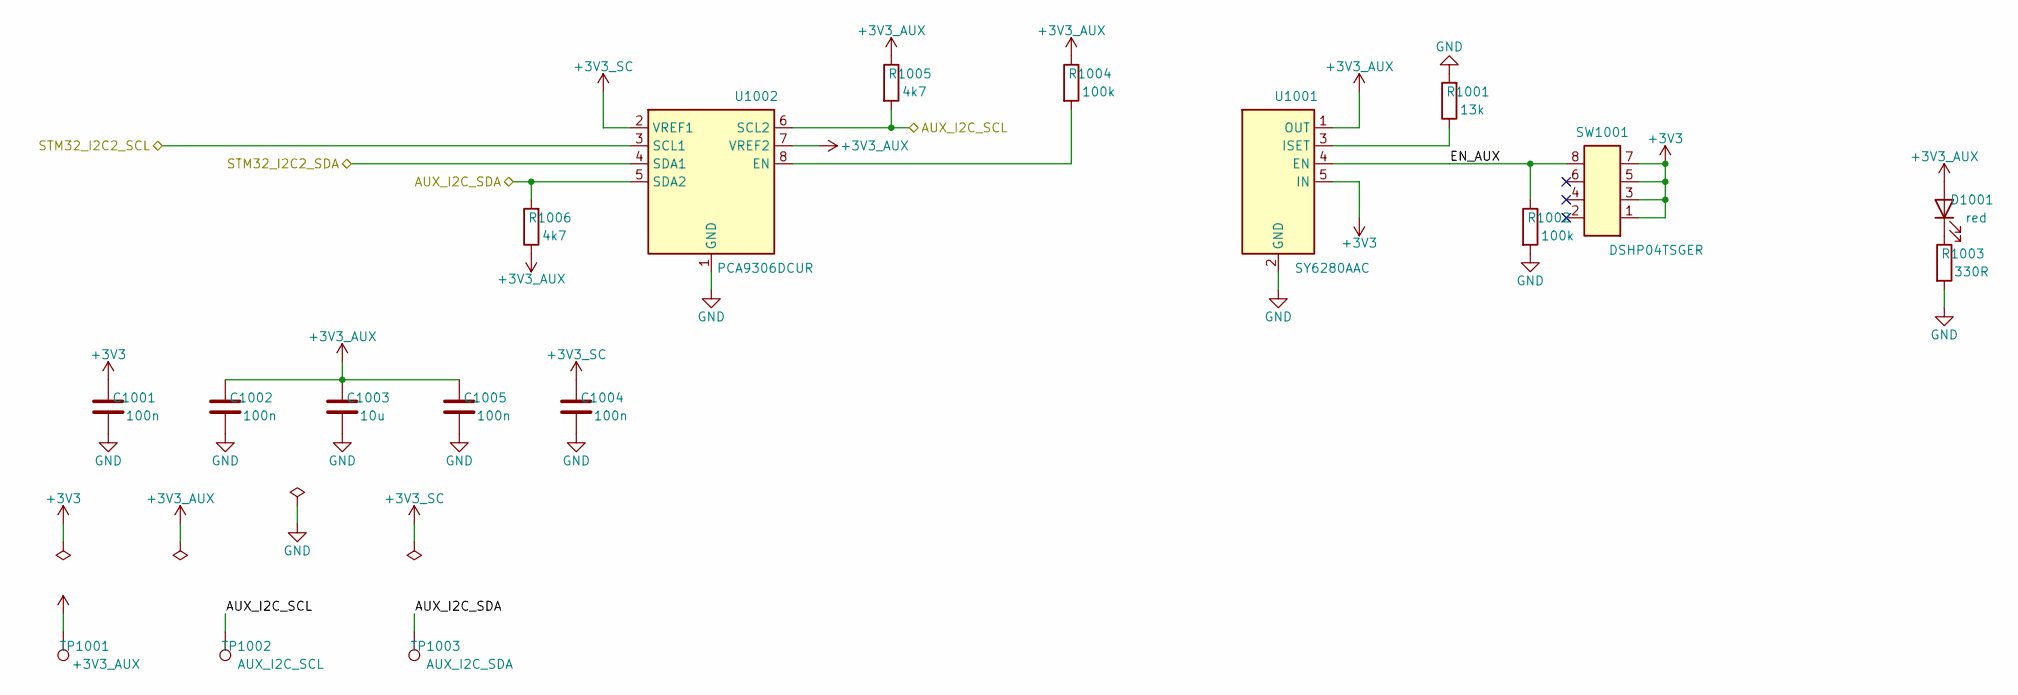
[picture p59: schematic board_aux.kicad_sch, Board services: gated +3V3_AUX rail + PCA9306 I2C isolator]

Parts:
C1001, C1002, C1004, C1005: 100n; C_0603_1608Metric; LCSC C14663
C1003: 10u; C_0805_2012Metric; LCSC C15850
D1001: red; LED_0603_1608Metric; LCSC C2286
R1001: 13k; R_0603_1608Metric; LCSC C22797
R1002, R1004: 100k; R_0603_1608Metric; LCSC C25803
R1003: 330R; R_0603_1608Metric; LCSC C23138
R1005, R1006: 4k7; R_0603_1608Metric; LCSC C23162
SW1001: DSHP04TSGER; LCSC C3293144
TP1001: +3V3_AUX; TestPoint_Pad_D1.5mm
TP1002: AUX_I2C_SCL; TestPoint_Pad_D1.5mm
TP1003: AUX_I2C_SDA; TestPoint_Pad_D1.5mm
U1001: SY6280AAC; LCSC C55136
U1002: PCA9306DCUR; LCSC C33196

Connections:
+3V3: C1001.1, SW1001.1, SW1001.3, SW1001.5, SW1001.7, U1001.5 (IN); also elsewhere on the board
+3V3_AUX: C1002.1, C1003.1, C1005.1, D1001.2 (A), R1004.1, R1005.1, R1006.1, TP1001.1, U1001.1 (OUT), U1002.7 (VREF2); also elsewhere on the board
+3V3_SC: C1004.1, U1002.2 (VREF1); also elsewhere on the board
/board_aux/EN_AUX: R1002.1, SW1001.8, U1001.4 (EN)
AUX_I2C_SCL: R1005.2, TP1002.1, U1002.6 (SCL2); also elsewhere on the board
AUX_I2C_SDA: R1006.2, TP1003.1, U1002.5 (SDA2); also elsewhere on the board
GND: C1001.2, C1002.2, C1003.2, C1004.2, C1005.2, R1001.2, R1002.2, R1003.2, U1001.2 (GND), U1002.1 (GND); also elsewhere on the board
unnamed: D1001.1 (K), R1003.1
unnamed: R1001.1, U1001.3 (ISET)
unnamed: R1004.2, U1002.8 (EN)
STM32_I2C2_SCL: U1002.3 (SCL1); also elsewhere on the board
STM32_I2C2_SDA: U1002.4 (SDA1); also elsewhere on the board

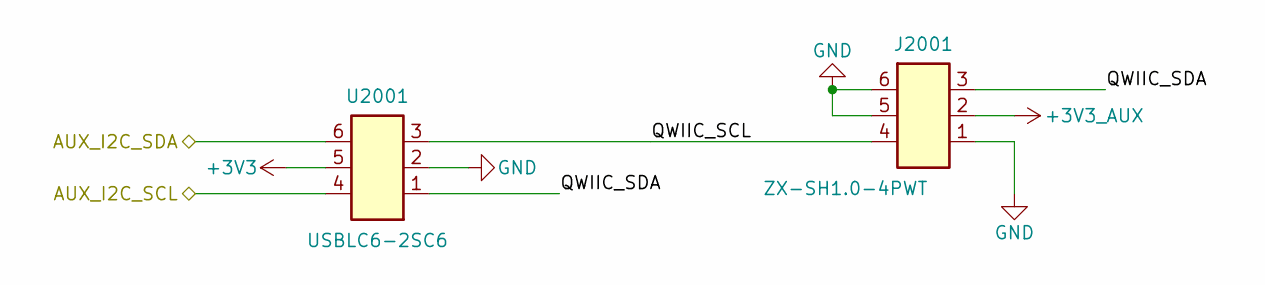
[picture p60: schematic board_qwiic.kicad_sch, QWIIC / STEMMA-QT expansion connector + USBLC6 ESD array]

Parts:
J2001: ZX-SH1.0-4PWT; LCSC C7430446
U2001: USBLC6-2SC6; LCSC C7519

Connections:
+3V3: U2001.5; also elsewhere on the board
+3V3_AUX: J2001.2; also elsewhere on the board
/board_qwiic/QWIIC_SCL: J2001.4, U2001.3
/board_qwiic/QWIIC_SDA: J2001.3, U2001.1
AUX_I2C_SCL: U2001.4; also elsewhere on the board
AUX_I2C_SDA: U2001.6; also elsewhere on the board
GND: J2001.1, J2001.5, J2001.6, U2001.2; also elsewhere on the board

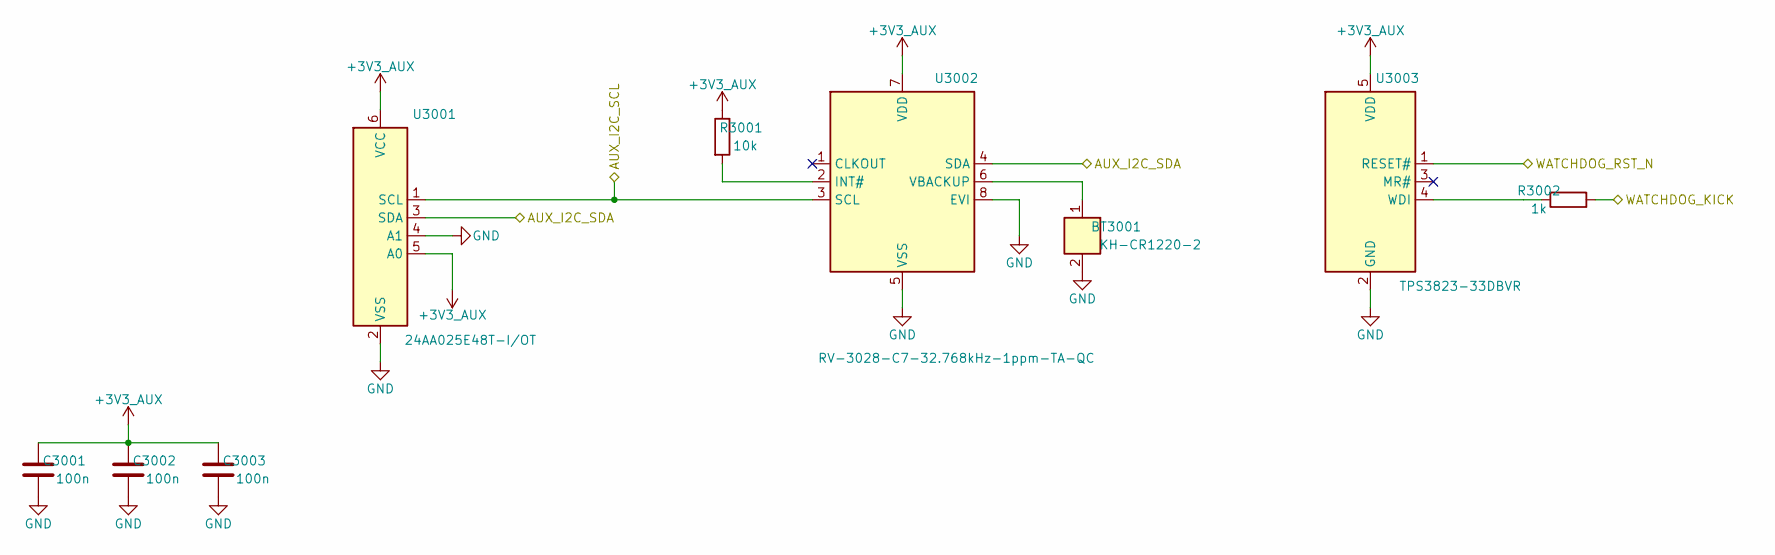
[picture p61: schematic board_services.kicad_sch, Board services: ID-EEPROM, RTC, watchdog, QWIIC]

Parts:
BT3001: KH-CR1220-2; LCSC C5365933
C3001, C3002, C3003: 100n; C_0603_1608Metric; LCSC C14663
R3001: 10k; R_0603_1608Metric; LCSC C25804
R3002: 1k; R_0603_1608Metric; LCSC C21190
U3001: 24AA025E48T-I/OT; 24AA025E48T-I_OT; LCSC C129895
U3002: RV-3028-C7-32.768kHz-1ppm-TA-QC; LCSC C3019759
U3003: TPS3823-33DBVR; LCSC C7719

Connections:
+3V3_AUX: C3001.1, C3002.1, C3003.1, R3001.1, U3001.5 (A0), U3001.6 (VCC), U3002.7 (VDD), U3003.5 (VDD); also elsewhere on the board
AUX_I2C_SCL: U3001.1 (SCL), U3002.3 (SCL); also elsewhere on the board
AUX_I2C_SDA: U3001.3 (SDA), U3002.4 (SDA); also elsewhere on the board
GND: BT3001.2, C3001.2, C3002.2, C3003.2, U3001.2 (VSS), U3001.4 (A1), U3002.5 (VSS), U3002.8 (EVI), U3003.2 (GND); also elsewhere on the board
unnamed: R3001.2, U3002.2 (INT#)
unnamed: BT3001.1, U3002.6 (VBACKUP)
unnamed: R3002.2, U3003.4 (WDI)
WATCHDOG_KICK: R3002.1; also elsewhere on the board
WATCHDOG_RST_N: U3003.1 (RESET#); also elsewhere on the board

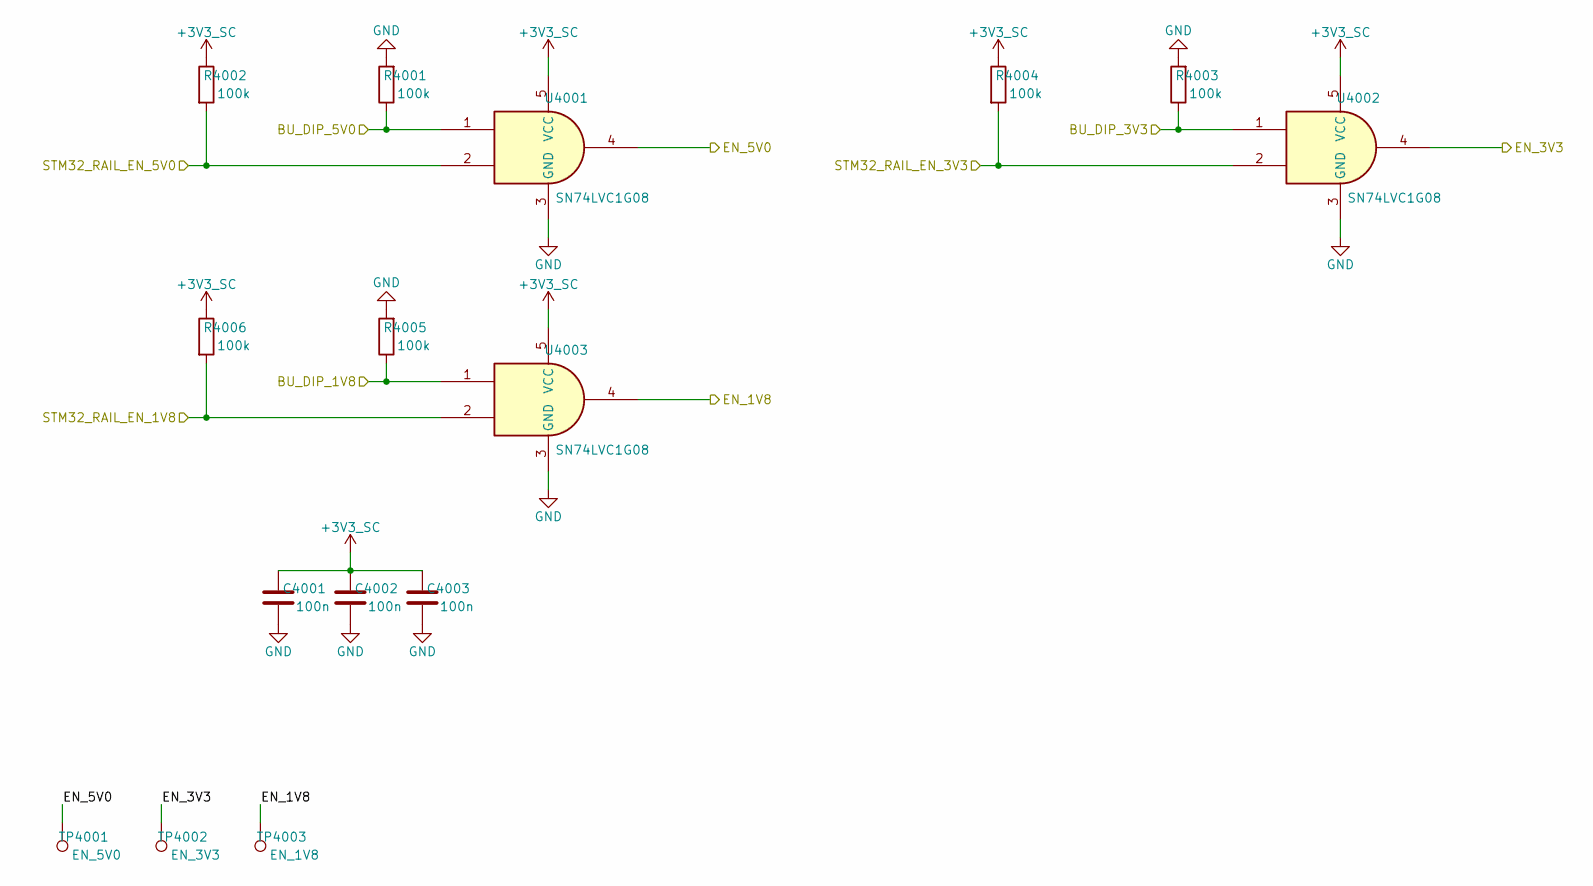
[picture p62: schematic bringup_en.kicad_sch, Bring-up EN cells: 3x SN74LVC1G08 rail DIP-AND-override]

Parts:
C4001, C4002, C4003: 100n; C_0603_1608Metric; LCSC C14663
R4001, R4002, R4003, R4004, R4005, R4006: 100k; R_0603_1608Metric; LCSC C25803
TP4001: EN_5V0; TestPoint_Pad_D1.5mm
TP4002: EN_3V3; TestPoint_Pad_D1.5mm
TP4003: EN_1V8; TestPoint_Pad_D1.5mm
U4001, U4002, U4003: SN74LVC1G08; SOT-23-5; LCSC C7666

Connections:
+3V3_SC: C4001.1, C4002.1, C4003.1, R4002.1, R4004.1, R4006.1, U4001.5 (VCC), U4002.5 (VCC), U4003.5 (VCC); also elsewhere on the board
BU_DIP_1V8: R4005.1, U4003.1; also elsewhere on the board
BU_DIP_3V3: R4003.1, U4002.1; also elsewhere on the board
BU_DIP_5V0: R4001.1, U4001.1; also elsewhere on the board
EN_1V8: TP4003.1, U4003.4; also elsewhere on the board
EN_3V3: TP4002.1, U4002.4; also elsewhere on the board
EN_5V0: TP4001.1, U4001.4; also elsewhere on the board
GND: C4001.2, C4002.2, C4003.2, R4001.2, R4003.2, R4005.2, U4001.3 (GND), U4002.3 (GND), U4003.3 (GND); also elsewhere on the board
STM32_RAIL_EN_1V8: R4006.2, U4003.2; also elsewhere on the board
STM32_RAIL_EN_3V3: R4004.2, U4002.2; also elsewhere on the board
STM32_RAIL_EN_5V0: R4002.2, U4001.2; also elsewhere on the board

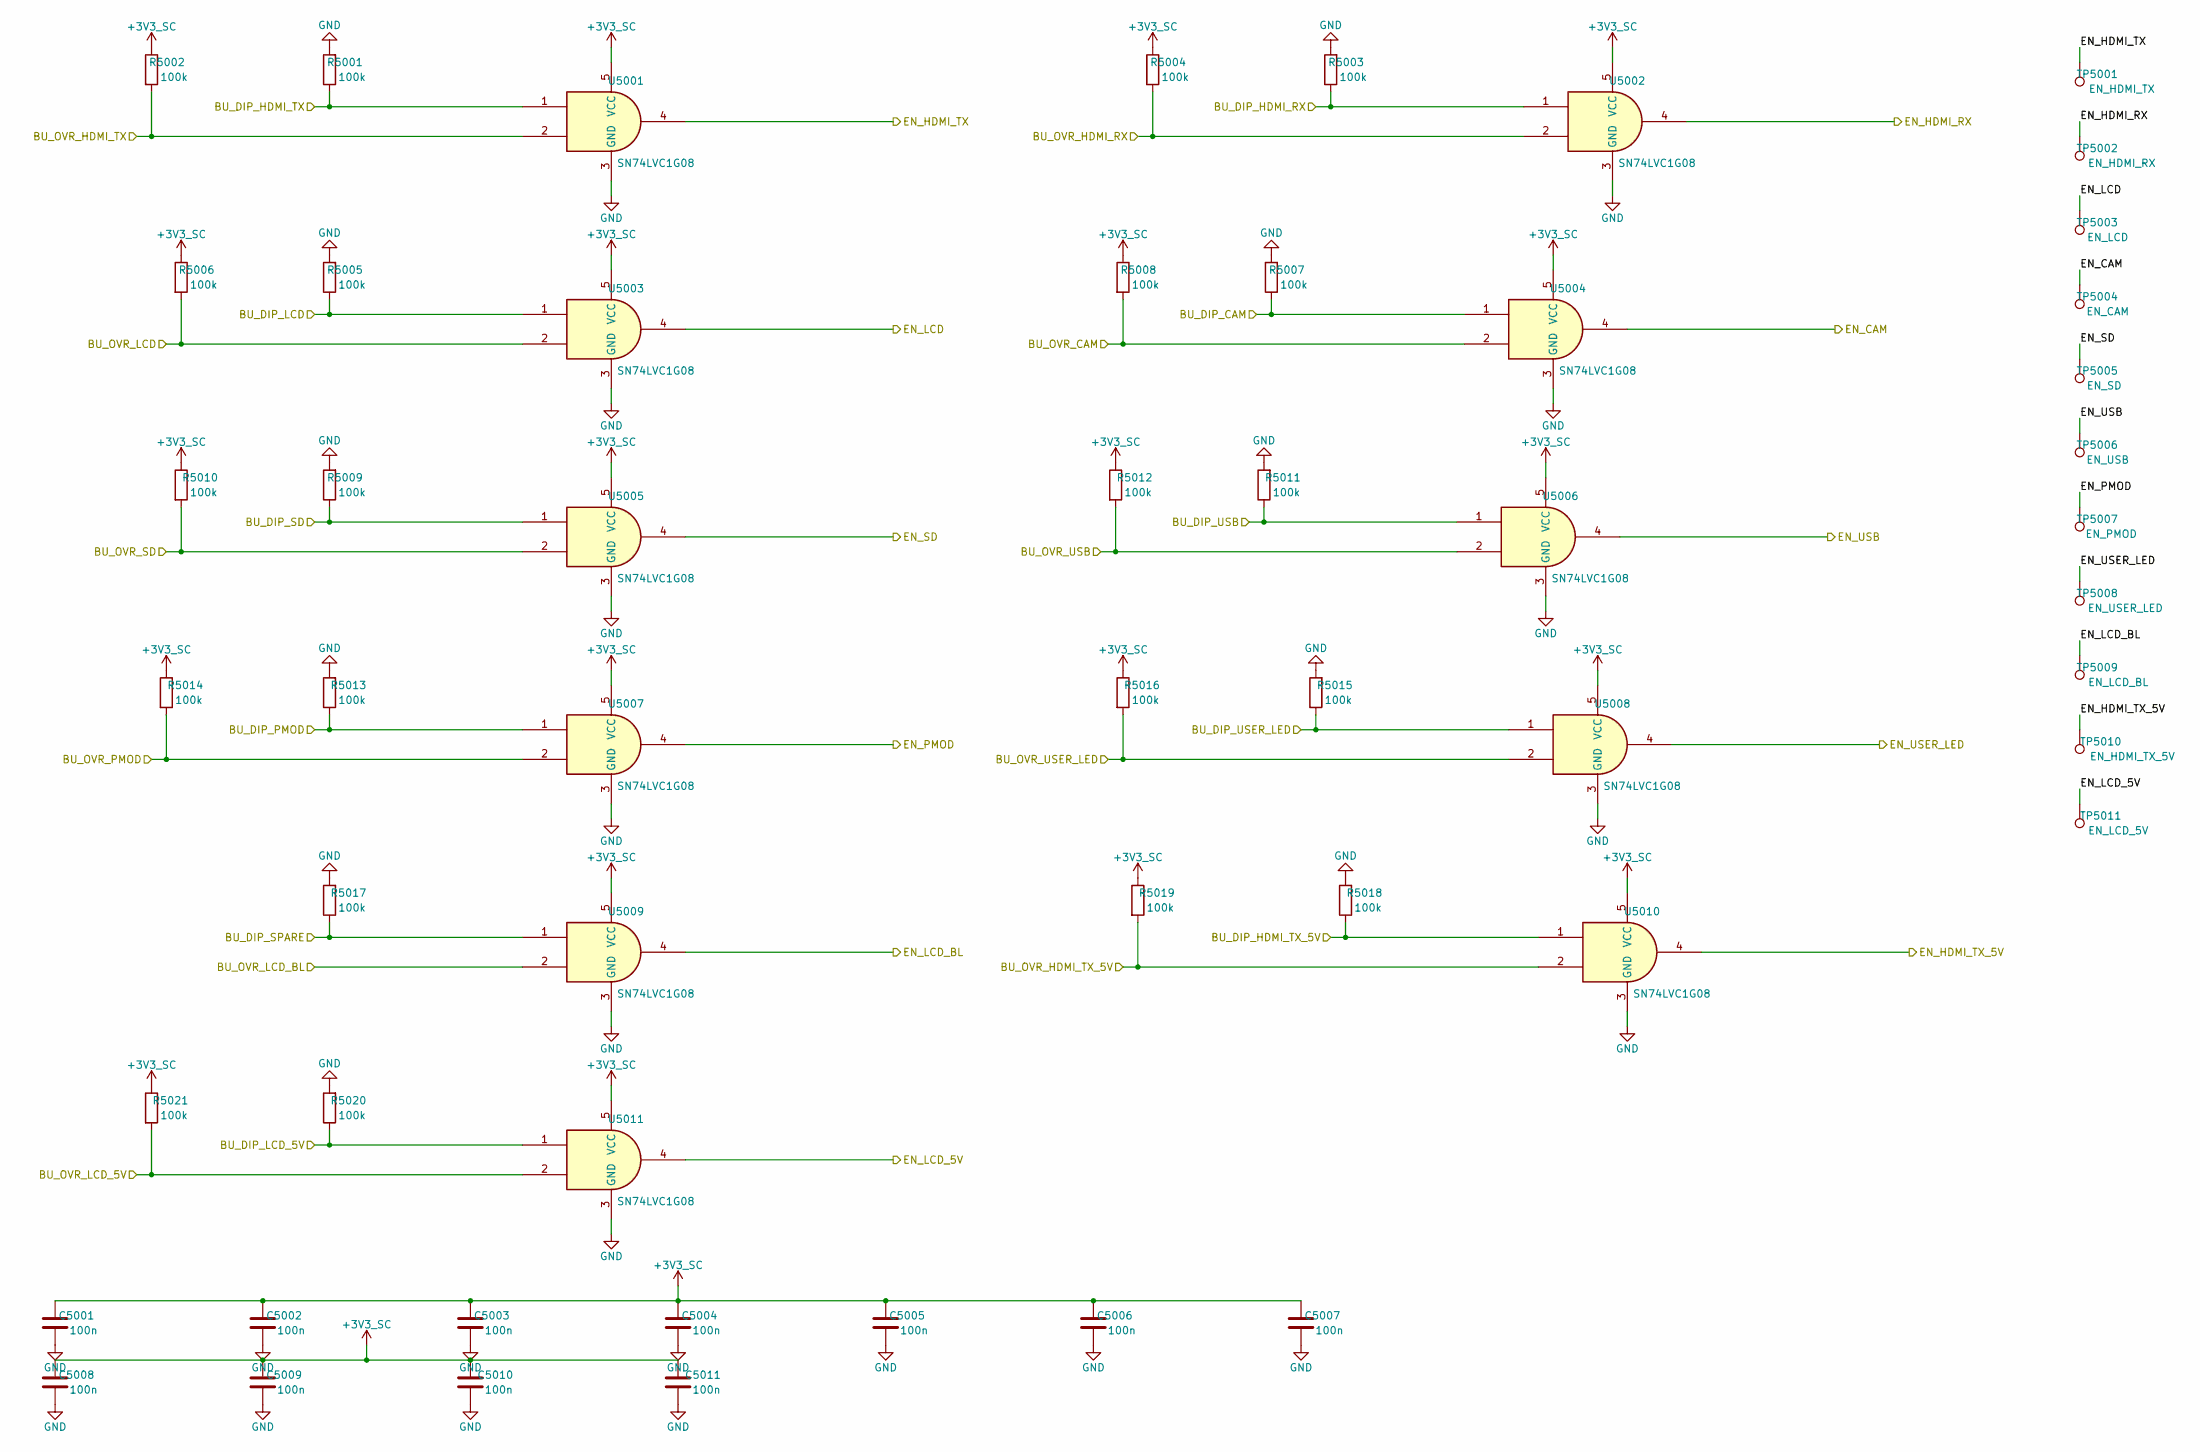
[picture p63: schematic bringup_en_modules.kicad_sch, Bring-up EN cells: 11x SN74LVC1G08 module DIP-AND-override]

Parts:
C5001, C5002, C5003, C5004, C5005, C5006, C5007, C5008, C5009, C5010, C5011: 100n; C_0603_1608Metric; LCSC C14663
R5001, R5002, R5003, R5004, R5005, R5006, R5007, R5008, R5009, R5010, R5011, R5012, R5013, R5014, R5015, R5016, R5017, R5018, R5019, R5020, R5021: 100k; R_0603_1608Metric; LCSC C25803
TP5001: EN_HDMI_TX; TestPoint_Pad_D1.5mm
TP5002: EN_HDMI_RX; TestPoint_Pad_D1.5mm
TP5003: EN_LCD; TestPoint_Pad_D1.5mm
TP5004: EN_CAM; TestPoint_Pad_D1.5mm
TP5005: EN_SD; TestPoint_Pad_D1.5mm
TP5006: EN_USB; TestPoint_Pad_D1.5mm
TP5007: EN_PMOD; TestPoint_Pad_D1.5mm
TP5008: EN_USER_LED; TestPoint_Pad_D1.5mm
TP5009: EN_LCD_BL; TestPoint_Pad_D1.5mm
TP5010: EN_HDMI_TX_5V; TestPoint_Pad_D1.5mm
TP5011: EN_LCD_5V; TestPoint_Pad_D1.5mm
U5001, U5002, U5003, U5004, U5005, U5006, U5007, U5008, U5009, U5010, U5011: SN74LVC1G08; SOT-23-5; LCSC C7666

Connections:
+3V3_SC: C5001.1, C5002.1, C5003.1, C5004.1, C5005.1, C5006.1, C5007.1, C5008.1, C5009.1, C5010.1, C5011.1, R5002.1, R5004.1, R5006.1, R5008.1, R5010.1, R5012.1, R5014.1, R5016.1, R5019.1, R5021.1, U5001.5 (VCC), U5002.5 (VCC), U5003.5 (VCC), U5004.5 (VCC), U5005.5 (VCC), U5006.5 (VCC), U5007.5 (VCC), U5008.5 (VCC), U5009.5 (VCC), U5010.5 (VCC), U5011.5 (VCC); also elsewhere on the board
BU_DIP_CAM: R5007.1, U5004.1; also elsewhere on the board
BU_DIP_HDMI_RX: R5003.1, U5002.1; also elsewhere on the board
BU_DIP_HDMI_TX: R5001.1, U5001.1; also elsewhere on the board
BU_DIP_HDMI_TX_5V: R5018.1, U5010.1; also elsewhere on the board
BU_DIP_LCD: R5005.1, U5003.1; also elsewhere on the board
BU_DIP_LCD_5V: R5020.1, U5011.1; also elsewhere on the board
BU_DIP_PMOD: R5013.1, U5007.1; also elsewhere on the board
BU_DIP_SD: R5009.1, U5005.1; also elsewhere on the board
BU_DIP_SPARE: R5017.1, U5009.1; also elsewhere on the board
BU_DIP_USB: R5011.1, U5006.1; also elsewhere on the board
BU_DIP_USER_LED: R5015.1, U5008.1; also elsewhere on the board
BU_OVR_CAM: R5008.2, U5004.2; also elsewhere on the board
BU_OVR_HDMI_RX: R5004.2, U5002.2; also elsewhere on the board
BU_OVR_HDMI_TX: R5002.2, U5001.2; also elsewhere on the board
BU_OVR_HDMI_TX_5V: R5019.2, U5010.2; also elsewhere on the board
BU_OVR_LCD: R5006.2, U5003.2; also elsewhere on the board
BU_OVR_LCD_5V: R5021.2, U5011.2; also elsewhere on the board
BU_OVR_LCD_BL: U5009.2; also elsewhere on the board
BU_OVR_PMOD: R5014.2, U5007.2; also elsewhere on the board
BU_OVR_SD: R5010.2, U5005.2; also elsewhere on the board
BU_OVR_USB: R5012.2, U5006.2; also elsewhere on the board
BU_OVR_USER_LED: R5016.2, U5008.2; also elsewhere on the board
EN_CAM: TP5004.1, U5004.4; also elsewhere on the board
EN_HDMI_RX: TP5002.1, U5002.4; also elsewhere on the board
EN_HDMI_TX: TP5001.1, U5001.4; also elsewhere on the board
EN_HDMI_TX_5V: TP5010.1, U5010.4; also elsewhere on the board
EN_LCD: TP5003.1, U5003.4; also elsewhere on the board
EN_LCD_5V: TP5011.1, U5011.4; also elsewhere on the board
EN_LCD_BL: TP5009.1, U5009.4
EN_PMOD: TP5007.1, U5007.4; also elsewhere on the board
EN_SD: TP5005.1, U5005.4; also elsewhere on the board
EN_USB: TP5006.1, U5006.4; also elsewhere on the board
EN_USER_LED: TP5008.1, U5008.4; also elsewhere on the board
GND: C5001.2, C5002.2, C5003.2, C5004.2, C5005.2, C5006.2, C5007.2, C5008.2, C5009.2, C5010.2, C5011.2, R5001.2, R5003.2, R5005.2, R5007.2, R5009.2, R5011.2, R5013.2, R5015.2, R5017.2, R5018.2, R5020.2, U5001.3 (GND), U5002.3 (GND), U5003.3 (GND), U5004.3 (GND), U5005.3 (GND), U5006.3 (GND), U5007.3 (GND), U5008.3 (GND), U5009.3 (GND), U5010.3 (GND), U5011.3 (GND); also elsewhere on the board

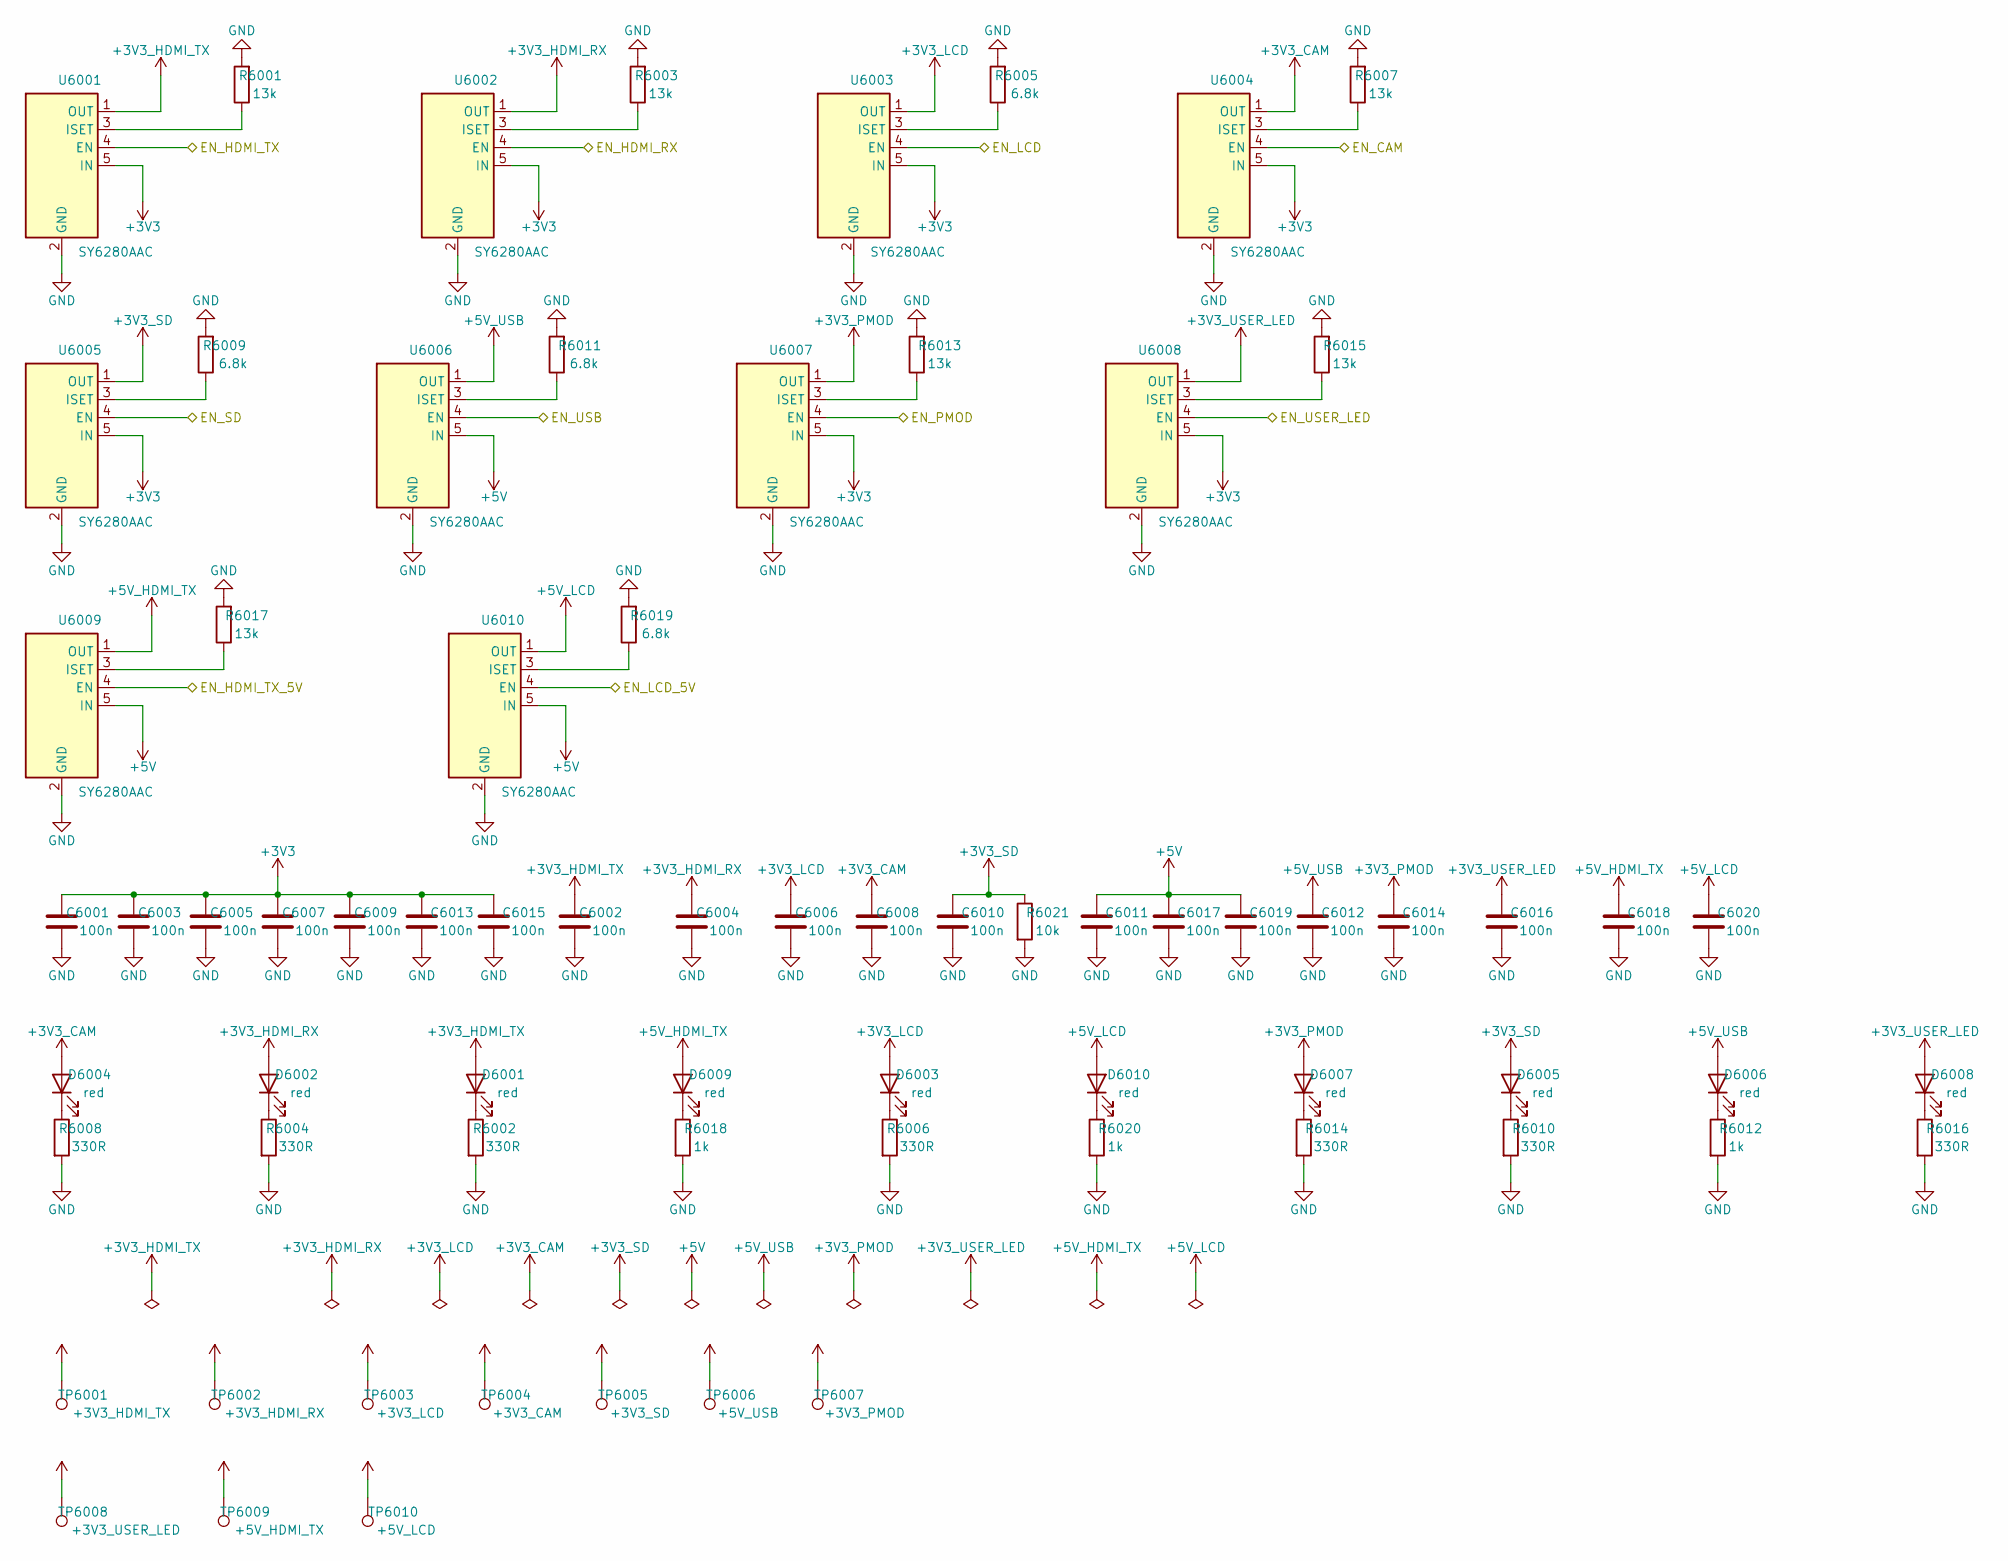
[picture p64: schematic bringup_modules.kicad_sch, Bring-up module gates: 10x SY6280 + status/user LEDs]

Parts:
C6001, C6002, C6003, C6004, C6005, C6006, C6007, C6008, C6009, C6010, C6011, C6012, C6013, C6014, C6015, C6016, C6017, C6018, C6019, C6020: 100n; C_0603_1608Metric; LCSC C14663
D6001, D6002, D6003, D6004, D6005, D6006, D6007, D6008, D6009, D6010: red; LED_0603_1608Metric; LCSC C2286
R6001, R6003, R6007, R6013, R6015, R6017: 13k; R_0603_1608Metric; LCSC C22797
R6002, R6004, R6006, R6008, R6010, R6014, R6016: 330R; R_0603_1608Metric; LCSC C23138
R6005, R6009, R6011, R6019: 6.8k; R_0603_1608Metric; LCSC C23212
R6012, R6018, R6020: 1k; R_0603_1608Metric; LCSC C21190
R6021: 10k; R_0603_1608Metric; LCSC C25804
TP6001: +3V3_HDMI_TX; TestPoint_Pad_D1.5mm
TP6002: +3V3_HDMI_RX; TestPoint_Pad_D1.5mm
TP6003: +3V3_LCD; TestPoint_Pad_D1.5mm
TP6004: +3V3_CAM; TestPoint_Pad_D1.5mm
TP6005: +3V3_SD; TestPoint_Pad_D1.5mm
TP6006: +5V_USB; TestPoint_Pad_D1.5mm
TP6007: +3V3_PMOD; TestPoint_Pad_D1.5mm
TP6008: +3V3_USER_LED; TestPoint_Pad_D1.5mm
TP6009: +5V_HDMI_TX; TestPoint_Pad_D1.5mm
TP6010: +5V_LCD; TestPoint_Pad_D1.5mm
U6001, U6002, U6003, U6004, U6005, U6006, U6007, U6008, U6009, U6010: SY6280AAC; LCSC C55136

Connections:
+3V3: C6001.1, C6003.1, C6005.1, C6007.1, C6009.1, C6013.1, C6015.1, U6001.5 (IN), U6002.5 (IN), U6003.5 (IN), U6004.5 (IN), U6005.5 (IN), U6007.5 (IN), U6008.5 (IN); also elsewhere on the board
+3V3_CAM: C6008.1, D6004.2 (A), TP6004.1, U6004.1 (OUT); also elsewhere on the board
+3V3_HDMI_RX: C6004.1, D6002.2 (A), TP6002.1, U6002.1 (OUT); also elsewhere on the board
+3V3_HDMI_TX: C6002.1, D6001.2 (A), TP6001.1, U6001.1 (OUT); also elsewhere on the board
+3V3_LCD: C6006.1, D6003.2 (A), TP6003.1, U6003.1 (OUT); also elsewhere on the board
+3V3_PMOD: C6014.1, D6007.2 (A), TP6007.1, U6007.1 (OUT); also elsewhere on the board
+3V3_SD: C6010.1, D6005.2 (A), R6021.1, TP6005.1, U6005.1 (OUT); also elsewhere on the board
+3V3_USER_LED: C6016.1, D6008.2 (A), TP6008.1, U6008.1 (OUT); also elsewhere on the board
+5V: C6011.1, C6017.1, C6019.1, U6006.5 (IN), U6009.5 (IN), U6010.5 (IN); also elsewhere on the board
+5V_HDMI_TX: C6018.1, D6009.2 (A), TP6009.1, U6009.1 (OUT); also elsewhere on the board
+5V_LCD: C6020.1, D6010.2 (A), TP6010.1, U6010.1 (OUT); also elsewhere on the board
+5V_USB: C6012.1, D6006.2 (A), TP6006.1, U6006.1 (OUT); also elsewhere on the board
EN_CAM: U6004.4 (EN); also elsewhere on the board
EN_HDMI_RX: U6002.4 (EN); also elsewhere on the board
EN_HDMI_TX: U6001.4 (EN); also elsewhere on the board
EN_HDMI_TX_5V: U6009.4 (EN); also elsewhere on the board
EN_LCD: U6003.4 (EN); also elsewhere on the board
EN_LCD_5V: U6010.4 (EN); also elsewhere on the board
EN_PMOD: U6007.4 (EN); also elsewhere on the board
EN_SD: U6005.4 (EN); also elsewhere on the board
EN_USB: U6006.4 (EN); also elsewhere on the board
EN_USER_LED: U6008.4 (EN); also elsewhere on the board
GND: C6001.2, C6002.2, C6003.2, C6004.2, C6005.2, C6006.2, C6007.2, C6008.2, C6009.2, C6010.2, C6011.2, C6012.2, C6013.2, C6014.2, C6015.2, C6016.2, C6017.2, C6018.2, C6019.2, C6020.2, R6001.2, R6002.2, R6003.2, R6004.2, R6005.2, R6006.2, R6007.2, R6008.2, R6009.2, R6010.2, R6011.2, R6012.2, R6013.2, R6014.2, R6015.2, R6016.2, R6017.2, R6018.2, R6019.2, R6020.2, R6021.2, U6001.2 (GND), U6002.2 (GND), U6003.2 (GND), U6004.2 (GND), U6005.2 (GND), U6006.2 (GND), U6007.2 (GND), U6008.2 (GND), U6009.2 (GND), U6010.2 (GND); also elsewhere on the board
unnamed: D6001.1 (K), R6002.1
unnamed: D6002.1 (K), R6004.1
unnamed: D6003.1 (K), R6006.1
unnamed: D6004.1 (K), R6008.1
unnamed: D6005.1 (K), R6010.1
unnamed: D6006.1 (K), R6012.1
unnamed: D6007.1 (K), R6014.1
unnamed: D6008.1 (K), R6016.1
unnamed: D6009.1 (K), R6018.1
unnamed: D6010.1 (K), R6020.1
unnamed: R6001.1, U6001.3 (ISET)
unnamed: R6003.1, U6002.3 (ISET)
unnamed: R6005.1, U6003.3 (ISET)
unnamed: R6007.1, U6004.3 (ISET)
unnamed: R6009.1, U6005.3 (ISET)
unnamed: R6011.1, U6006.3 (ISET)
unnamed: R6013.1, U6007.3 (ISET)
unnamed: R6015.1, U6008.3 (ISET)
unnamed: R6017.1, U6009.3 (ISET)
unnamed: R6019.1, U6010.3 (ISET)

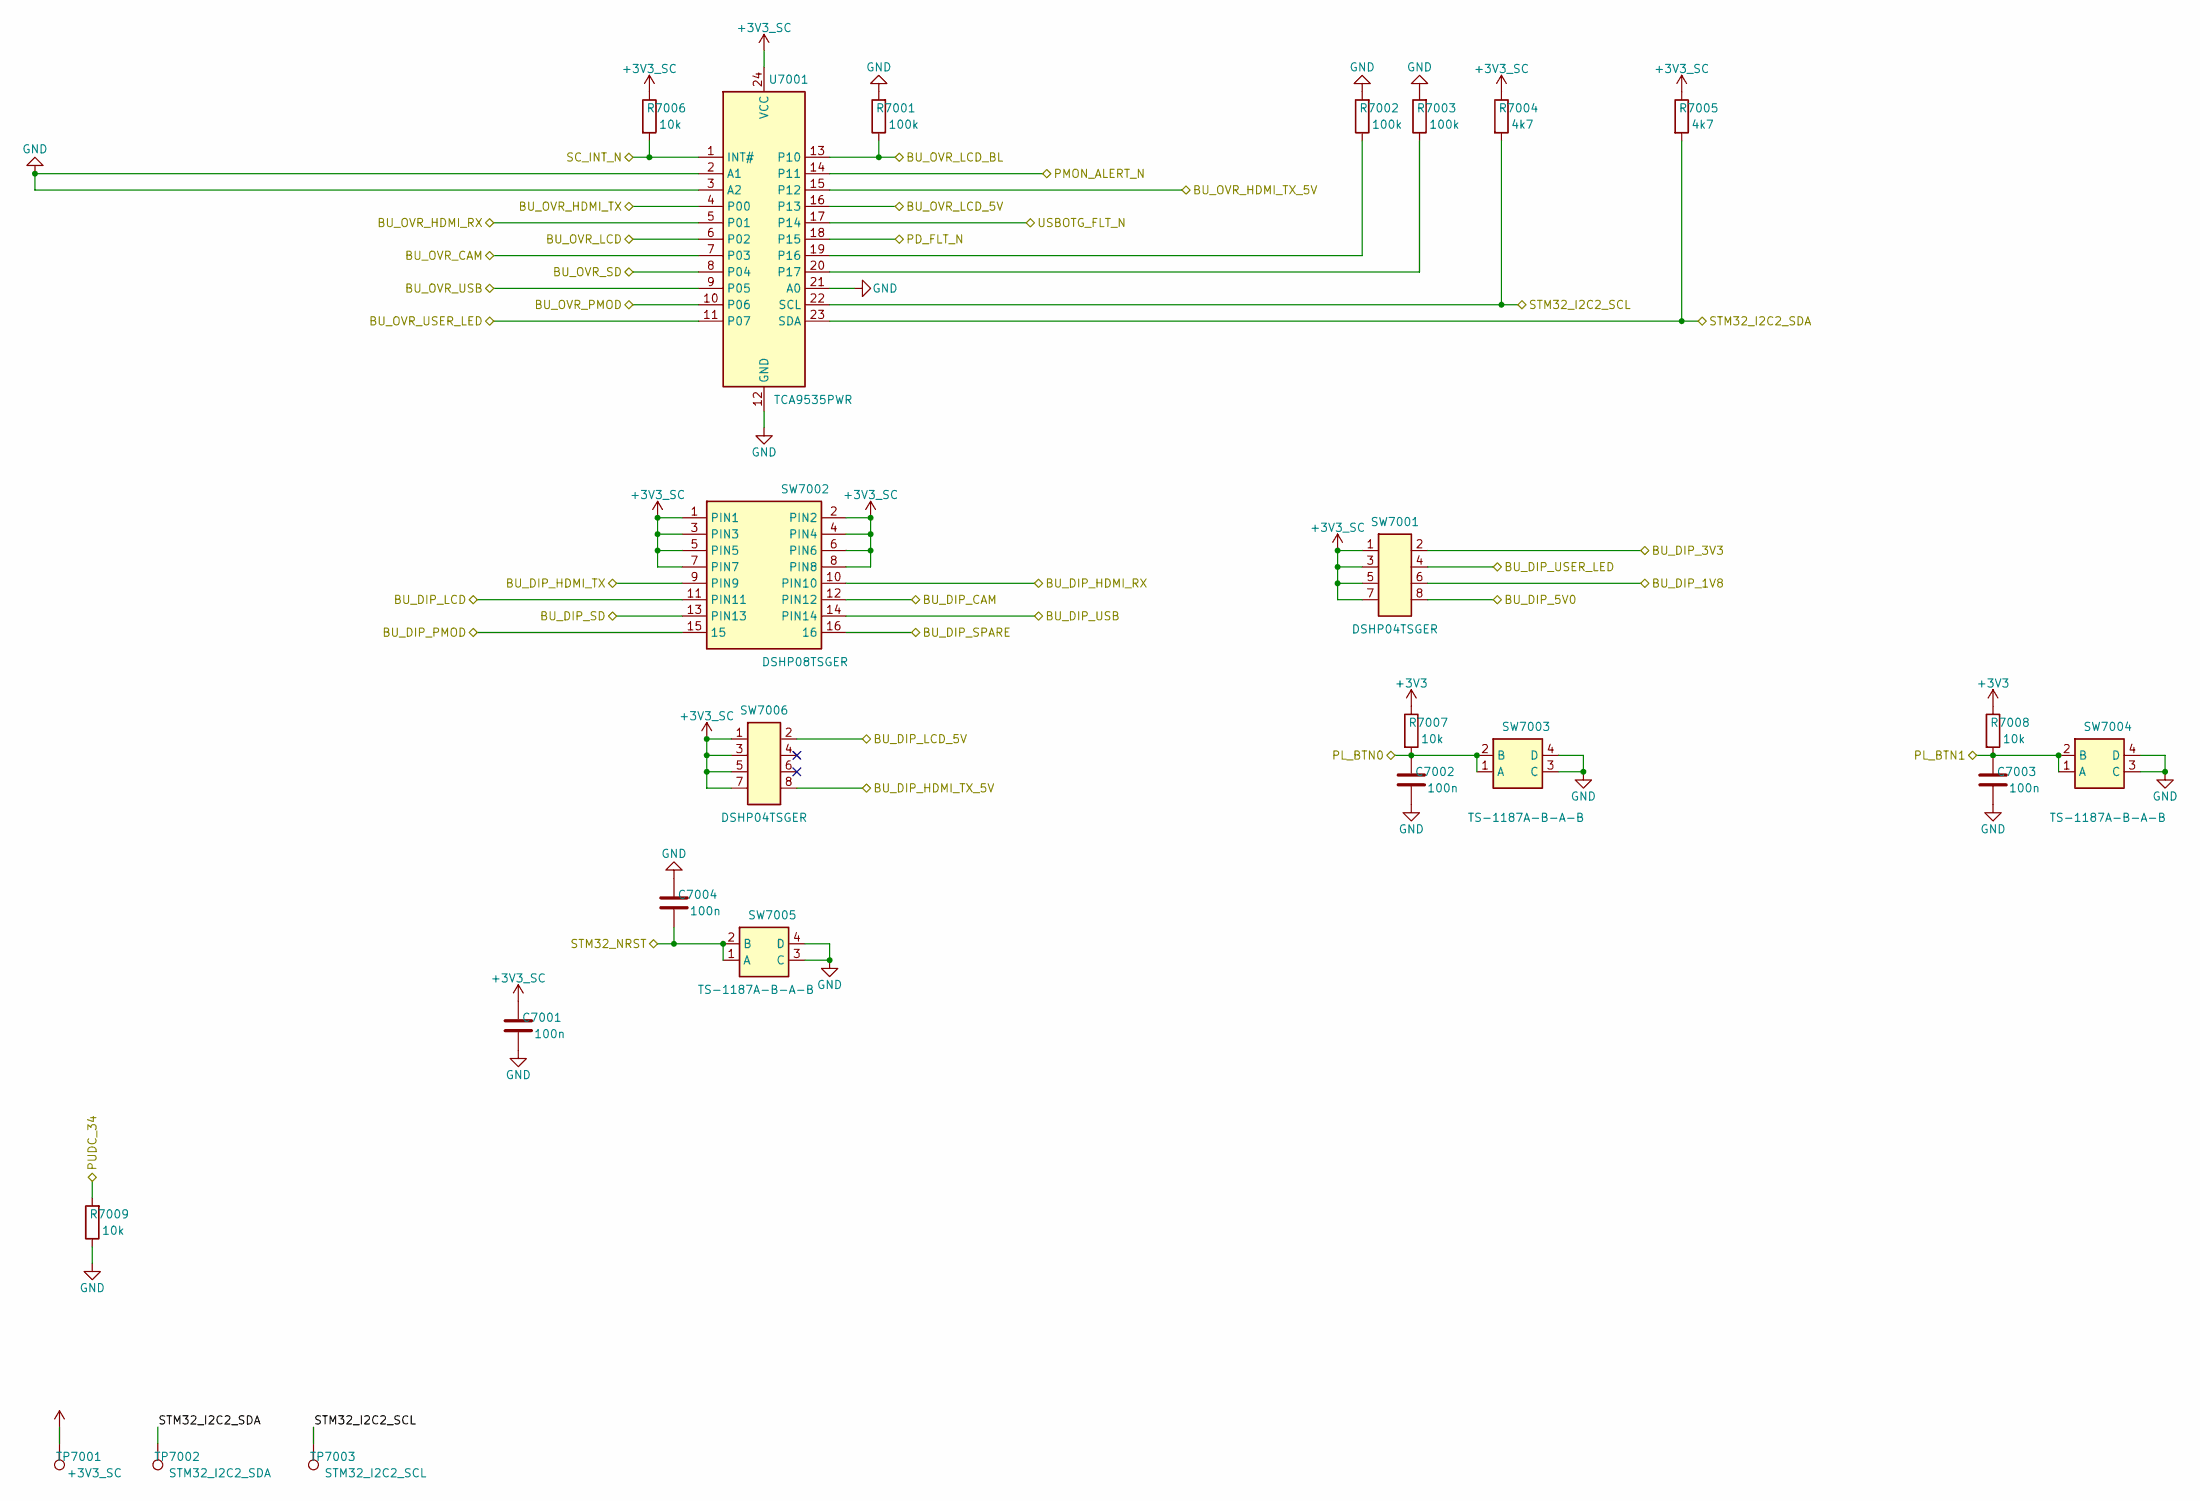
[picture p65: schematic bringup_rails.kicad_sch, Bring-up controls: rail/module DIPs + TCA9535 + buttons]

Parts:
C7001, C7002, C7003, C7004: 100n; C_0603_1608Metric; LCSC C14663
R7001, R7002, R7003: 100k; R_0603_1608Metric; LCSC C25803
R7004, R7005: 4k7; R_0603_1608Metric; LCSC C23162
R7006, R7007, R7008, R7009: 10k; R_0603_1608Metric; LCSC C25804
SW7001, SW7006: DSHP04TSGER; LCSC C3293144
SW7002: DSHP08TSGER; LCSC C3293147
SW7003, SW7004, SW7005: TS-1187A-B-A-B; LCSC C318884
TP7001: +3V3_SC; TestPoint_Pad_D1.5mm
TP7002: STM32_I2C2_SDA; TestPoint_Pad_D1.5mm
TP7003: STM32_I2C2_SCL; TestPoint_Pad_D1.5mm
U7001: TCA9535PWR; LCSC C130204

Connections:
+3V3: R7007.1, R7008.1; also elsewhere on the board
+3V3_SC: C7001.1, R7004.1, R7005.1, R7006.1, SW7001.1, SW7001.3, SW7001.5, SW7001.7, SW7002.1 (PIN1), SW7002.2 (PIN2), SW7002.3 (PIN3), SW7002.4 (PIN4), SW7002.5 (PIN5), SW7002.6 (PIN6), SW7002.7 (PIN7), SW7002.8 (PIN8), SW7006.1, SW7006.3, SW7006.5, SW7006.7, TP7001.1, U7001.24 (VCC); also elsewhere on the board
BU_DIP_1V8: SW7001.6; also elsewhere on the board
BU_DIP_3V3: SW7001.2; also elsewhere on the board
BU_DIP_5V0: SW7001.8; also elsewhere on the board
BU_DIP_CAM: SW7002.12 (PIN12); also elsewhere on the board
BU_DIP_HDMI_RX: SW7002.10 (PIN10); also elsewhere on the board
BU_DIP_HDMI_TX: SW7002.9 (PIN9); also elsewhere on the board
BU_DIP_HDMI_TX_5V: SW7006.8; also elsewhere on the board
BU_DIP_LCD: SW7002.11 (PIN11); also elsewhere on the board
BU_DIP_LCD_5V: SW7006.2; also elsewhere on the board
BU_DIP_PMOD: SW7002.15; also elsewhere on the board
BU_DIP_SD: SW7002.13 (PIN13); also elsewhere on the board
BU_DIP_SPARE: SW7002.16; also elsewhere on the board
BU_DIP_USB: SW7002.14 (PIN14); also elsewhere on the board
BU_DIP_USER_LED: SW7001.4; also elsewhere on the board
BU_OVR_CAM: U7001.7 (P03); also elsewhere on the board
BU_OVR_HDMI_RX: U7001.5 (P01); also elsewhere on the board
BU_OVR_HDMI_TX: U7001.4 (P00); also elsewhere on the board
BU_OVR_HDMI_TX_5V: U7001.15 (P12); also elsewhere on the board
BU_OVR_LCD: U7001.6 (P02); also elsewhere on the board
BU_OVR_LCD_5V: U7001.16 (P13); also elsewhere on the board
BU_OVR_LCD_BL: R7001.1, U7001.13 (P10); also elsewhere on the board
BU_OVR_PMOD: U7001.10 (P06); also elsewhere on the board
BU_OVR_SD: U7001.8 (P04); also elsewhere on the board
BU_OVR_USB: U7001.9 (P05); also elsewhere on the board
BU_OVR_USER_LED: U7001.11 (P07); also elsewhere on the board
GND: C7001.2, C7002.2, C7003.2, C7004.2, R7001.2, R7002.2, R7003.2, R7009.1, SW7003.3 (C), SW7003.4 (D), SW7004.3 (C), SW7004.4 (D), SW7005.3 (C), SW7005.4 (D), U7001.2 (A1), U7001.3 (A2), U7001.12 (GND), U7001.21 (A0); also elsewhere on the board
unnamed: R7002.1, U7001.19 (P16)
unnamed: R7003.1, U7001.20 (P17)
PD_FLT_N: U7001.18 (P15); also elsewhere on the board
PL_BTN0: C7002.1, R7007.2, SW7003.1 (A), SW7003.2 (B); also elsewhere on the board
PL_BTN1: C7003.1, R7008.2, SW7004.1 (A), SW7004.2 (B); also elsewhere on the board
PMON_ALERT_N: U7001.14 (P11); also elsewhere on the board
PUDC_34: R7009.2; also elsewhere on the board
SC_INT_N: R7006.2, U7001.1 (INT#); also elsewhere on the board
STM32_I2C2_SCL: R7004.2, TP7003.1, U7001.22 (SCL); also elsewhere on the board
STM32_I2C2_SDA: R7005.2, TP7002.1, U7001.23 (SDA); also elsewhere on the board
STM32_NRST: C7004.1, SW7005.1 (A), SW7005.2 (B); also elsewhere on the board
USBOTG_FLT_N: U7001.17 (P14); also elsewhere on the board

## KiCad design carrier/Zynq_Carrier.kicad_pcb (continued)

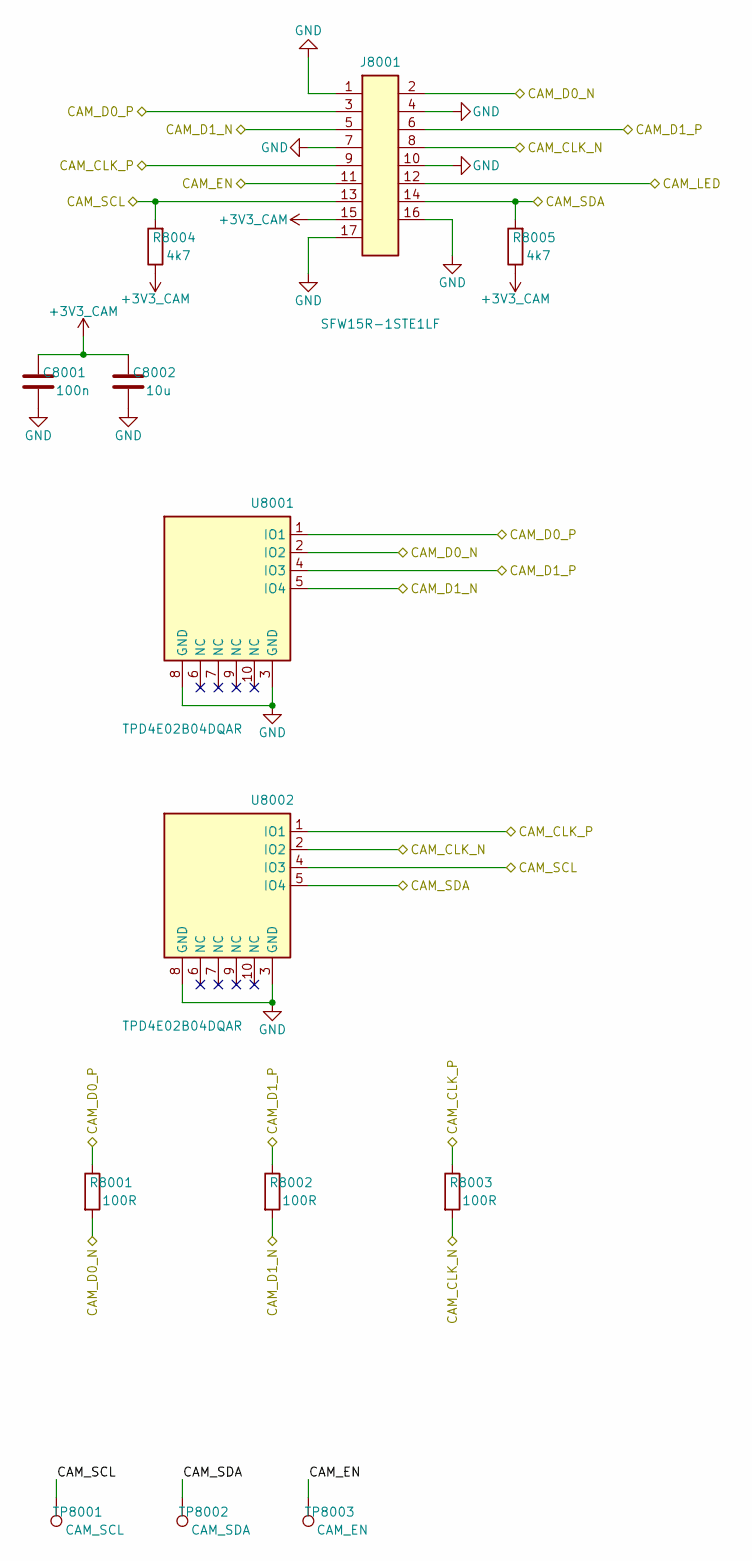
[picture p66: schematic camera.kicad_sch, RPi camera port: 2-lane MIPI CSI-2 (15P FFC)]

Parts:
C8001: 100n; C_0603_1608Metric; LCSC C14663
C8002: 10u; C_0805_2012Metric; LCSC C15850
J8001: SFW15R-1STE1LF; LCSC C3168538
R8001, R8002, R8003: 100R; R_0603_1608Metric; LCSC C22775
R8004, R8005: 4k7; R_0603_1608Metric; LCSC C23162
TP8001: CAM_SCL; TestPoint_Pad_D1.5mm
TP8002: CAM_SDA; TestPoint_Pad_D1.5mm
TP8003: CAM_EN; TestPoint_Pad_D1.5mm
U8001, U8002: TPD4E02B04DQAR; LCSC C106794

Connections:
+3V3_CAM: C8001.1, C8002.1, J8001.15, R8004.1, R8005.1; also elsewhere on the board
CAM_CLK_N: J8001.8, R8003.2, U8002.2 (IO2); also elsewhere on the board
CAM_CLK_P: J8001.9, R8003.1, U8002.1 (IO1); also elsewhere on the board
CAM_D0_N: J8001.2, R8001.2, U8001.2 (IO2); also elsewhere on the board
CAM_D0_P: J8001.3, R8001.1, U8001.1 (IO1); also elsewhere on the board
CAM_D1_N: J8001.5, R8002.2, U8001.5 (IO4); also elsewhere on the board
CAM_D1_P: J8001.6, R8002.1, U8001.4 (IO3); also elsewhere on the board
CAM_EN: J8001.11, TP8003.1; also elsewhere on the board
CAM_LED: J8001.12; also elsewhere on the board
CAM_SCL: J8001.13, R8004.2, TP8001.1, U8002.4 (IO3); also elsewhere on the board
CAM_SDA: J8001.14, R8005.2, TP8002.1, U8002.5 (IO4); also elsewhere on the board
GND: C8001.2, C8002.2, J8001.1, J8001.4, J8001.7, J8001.10, J8001.16, J8001.17, U8001.3 (GND), U8001.8 (GND), U8002.3 (GND), U8002.8 (GND); also elsewhere on the board

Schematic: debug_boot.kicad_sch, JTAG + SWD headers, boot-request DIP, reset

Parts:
J9001: 878311420; LCSC C240854
J9002: HX_JN1.27-2x5; HX_JN1.27-2x5_TP_H4.9; LCSC C42372555
R9001, R9002: 4k7; R_0603_1608Metric; LCSC C23162
R9003: 100R; R_0603_1608Metric; LCSC C22775
R9004, R9005, R9006: 10k; R_0603_1608Metric; LCSC C25804
SW9001: DIP-4; DSHP04TSGER; LCSC C3293144
SW9002: RESET; TS-1187A-B-A-B; LCSC C318884

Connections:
+3V3: J9001.2, R9001.1, R9002.1; also elsewhere on the board
+3V3_SC: J9002.1, R9003.1, R9004.1, R9005.1, R9006.1; also elsewhere on the board
GND: J9001.1, J9001.3, J9001.5, J9001.7, J9001.9, J9001.11, J9001.13, J9002.3, J9002.5, J9002.9, SW9001.5, SW9001.6, SW9001.7, SW9002.3 (C), SW9002.4 (D); also elsewhere on the board
unnamed: R9003.2, SW9001.8
unnamed: R9006.2, SW9001.4
STM32_BOOT0: SW9001.1; also elsewhere on the board
STM32_GPIO5: J9002.4; also elsewhere on the board
STM32_GPIO6: J9002.2; also elsewhere on the board
STM32_GPIO7: R9004.2, SW9001.2; also elsewhere on the board
STM32_GPIO8: R9005.2, SW9001.3; also elsewhere on the board
STM32_NRST: J9002.10, SW9002.1 (A), SW9002.2 (B); also elsewhere on the board
ZYNQ_TCK: J9001.6; also elsewhere on the board
ZYNQ_TDI: J9001.10, R9002.2; also elsewhere on the board
ZYNQ_TDO: J9001.8; also elsewhere on the board
ZYNQ_TMS: J9001.4, R9001.2; also elsewhere on the board

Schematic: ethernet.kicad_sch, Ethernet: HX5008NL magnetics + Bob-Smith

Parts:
C10001, C10002, C10003, C10004, C10005: 1n; C_1206_3225Metric; LCSC C9196
R10001, R10002, R10003, R10004: 75R; R_0603_1608Metric; LCSC C4275
T10001: HX5008NLT; LCSC C962544

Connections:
/ethernet/BS_COMMON: C10001.2, C10002.2, C10003.2, C10004.2, C10005.1, R10001.2, R10002.2, R10003.2, R10004.2
/ethernet/MCT1: C10001.1, R10001.1, T10001.24 (MCT1)
/ethernet/MCT2: C10002.1, R10002.1, T10001.21 (MCT2)
/ethernet/MCT3: C10003.1, R10003.1, T10001.18 (MCT3)
/ethernet/MCT4: C10004.1, R10004.1, T10001.15 (MCT4)
CHASSIS_GND: C10005.2; also elsewhere on the board
ETH_LINE_MDI_0_N: T10001.22 (MX1-); also elsewhere on the board
ETH_LINE_MDI_0_P: T10001.23 (MX1+); also elsewhere on the board
ETH_LINE_MDI_1_N: T10001.19 (MX2-); also elsewhere on the board
ETH_LINE_MDI_1_P: T10001.20 (MX2+); also elsewhere on the board
ETH_LINE_MDI_2_N: T10001.16 (MX3-); also elsewhere on the board
ETH_LINE_MDI_2_P: T10001.17 (MX3+); also elsewhere on the board
ETH_LINE_MDI_3_N: T10001.13 (MX4-); also elsewhere on the board
ETH_LINE_MDI_3_P: T10001.14 (MX4+); also elsewhere on the board
ETH_PHY_MDI0_N: T10001.3 (TD1-); also elsewhere on the board
ETH_PHY_MDI0_P: T10001.2 (TD1+); also elsewhere on the board
ETH_PHY_MDI1_N: T10001.6 (TD2-); also elsewhere on the board
ETH_PHY_MDI1_P: T10001.5 (TD2+); also elsewhere on the board
ETH_PHY_MDI2_N: T10001.9 (TD3-); also elsewhere on the board
ETH_PHY_MDI2_P: T10001.8 (TD3+); also elsewhere on the board
ETH_PHY_MDI3_N: T10001.12 (TD4-); also elsewhere on the board
ETH_PHY_MDI3_P: T10001.11 (TD4+); also elsewhere on the board

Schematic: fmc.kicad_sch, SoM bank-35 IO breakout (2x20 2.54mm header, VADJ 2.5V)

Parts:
C11001, C11004: 10u; C_0805_2012Metric; LCSC C15850
C11002, C11005: 100n; C_0603_1608Metric; LCSC C14663
C11003: 1u; C_0603_1608Metric; LCSC C15849
J11001: Header_2x20_2.54mm; PinHeader_2x20_P2.54mm_Vertical
TP11001: +2V5_VADJ; TestPoint_Pad_D1.5mm
U11001: TLV75725PDYDR; LCSC C35209004

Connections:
+2V5_VADJ: C11004.1, C11005.1, J11001.2, TP11001.1, U11001.5 (OUT); also elsewhere on the board
+3V3: C11001.1, C11002.1, C11003.1, J11001.1, U11001.1 (IN), U11001.3 (EN); also elsewhere on the board
FMC_CLK0_M2C_N: J11001.4; also elsewhere on the board
FMC_CLK0_M2C_P: J11001.3; also elsewhere on the board
FMC_CLK1_M2C_N: J11001.6; also elsewhere on the board
FMC_CLK1_M2C_P: J11001.5; also elsewhere on the board
FMC_LA00_CC_N: J11001.10; also elsewhere on the board
FMC_LA00_CC_P: J11001.9; also elsewhere on the board
FMC_LA01_CC_N: J11001.12; also elsewhere on the board
FMC_LA01_CC_P: J11001.11; also elsewhere on the board
FMC_LA02_N: J11001.14; also elsewhere on the board
FMC_LA02_P: J11001.13; also elsewhere on the board
FMC_LA03_N: J11001.18; also elsewhere on the board
FMC_LA03_P: J11001.17; also elsewhere on the board
FMC_LA04_N: J11001.20; also elsewhere on the board
FMC_LA04_P: J11001.19; also elsewhere on the board
FMC_LA05_N: J11001.22; also elsewhere on the board
FMC_LA05_P: J11001.21; also elsewhere on the board
FMC_LA06_N: J11001.26; also elsewhere on the board
FMC_LA06_P: J11001.25; also elsewhere on the board
FMC_LA07_N: J11001.28; also elsewhere on the board
FMC_LA07_P: J11001.27; also elsewhere on the board
FMC_LA08_N: J11001.30; also elsewhere on the board
FMC_LA08_P: J11001.29; also elsewhere on the board
FMC_LA09_N: J11001.34; also elsewhere on the board
FMC_LA09_P: J11001.33; also elsewhere on the board
FMC_LA10_N: J11001.36; also elsewhere on the board
FMC_LA10_P: J11001.35; also elsewhere on the board
FMC_LA11_N: J11001.38; also elsewhere on the board
FMC_LA11_P: J11001.37; also elsewhere on the board
GND: C11001.2, C11002.2, C11003.2, C11004.2, C11005.2, J11001.7, J11001.8, J11001.15, J11001.16, J11001.23, J11001.24, J11001.31, J11001.32, J11001.39, J11001.40, U11001.2 (GND), U11001.6 (EP); also elsewhere on the board

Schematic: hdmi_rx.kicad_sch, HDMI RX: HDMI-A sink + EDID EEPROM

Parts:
C12001: 100n; C_0603_1608Metric; LCSC C14663
J12001: HDMI-019S; LCSC C111617
R12001: 1k; R_0603_1608Metric; LCSC C21190
R12002: 27k; R_0603_1608Metric; LCSC C22967
R12003: 10k; R_0603_1608Metric; LCSC C25804
R12004: 15k; R_0603_1608Metric; LCSC C22809
U12001: M24C02-WMN6TP; MPN M24C02-WMN6TP; LCSC C7562
U12002, U12003: TPD4E02B04DQAR; LCSC C106794
U12004: TPD4E05U06DQAR; LCSC C138714

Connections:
+3V3_HDMI_RX: R12002.1; also elsewhere on the board
/hdmi_rx/HDMI_RX_5V: C12001.1, J12001.18 (+5V), R12001.1, R12003.1, U12001.7 (~WC), U12001.8 (VCC)
/hdmi_rx/HDMI_RX_HPD: J12001.19 (HOT_PLUG_DET), R12001.2, U12004.5 (D2-)
/hdmi_rx/HDMI_RX_SCL: J12001.15 (I2C-CLK), U12001.6 (SCL), U12004.1 (D1+)
/hdmi_rx/HDMI_RX_SDA: J12001.16 (I2C_DATA), U12001.5 (SDA), U12004.2 (D1-)
CHASSIS_GND: J12001.20 (SHD), J12001.21 (SHD), J12001.22 (SHD), J12001.23 (SHD); also elsewhere on the board
GND: C12001.2, J12001.2 (D2_SHIELD), J12001.5 (D1_SHIELD), J12001.8 (D0_SHIELD), J12001.11 (CK_SHIELD), J12001.17 (GND), R12004.2, U12001.1 (E0), U12001.2 (E1), U12001.3 (E2), U12001.4 (VSS), U12002.3 (GND), U12002.8 (GND), U12003.3 (GND), U12003.8 (GND), U12004.3 (GND), U12004.8 (GND); also elsewhere on the board
HDMI_RX_5V_DET: R12003.2, R12004.1; also elsewhere on the board
HDMI_RX_CEC: J12001.13 (CEC), R12002.2, U12004.4 (D2+); also elsewhere on the board
HDMI_RX_CLK_N: J12001.12 (CK-), U12003.5 (IO4); also elsewhere on the board
HDMI_RX_CLK_P: J12001.10 (CK+), U12003.4 (IO3); also elsewhere on the board
HDMI_RX_D0_N: J12001.9 (D0-), U12003.2 (IO2); also elsewhere on the board
HDMI_RX_D0_P: J12001.7 (D0+), U12003.1 (IO1); also elsewhere on the board
HDMI_RX_D1_N: J12001.6 (D1-), U12002.5 (IO4); also elsewhere on the board
HDMI_RX_D1_P: J12001.4 (D1+), U12002.4 (IO3); also elsewhere on the board
HDMI_RX_D2_N: J12001.3 (D2-), U12002.2 (IO2); also elsewhere on the board
HDMI_RX_D2_P: J12001.1 (D2+), U12002.1 (IO1); also elsewhere on the board

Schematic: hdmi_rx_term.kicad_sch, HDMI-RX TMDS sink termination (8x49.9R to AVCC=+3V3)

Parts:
C13001: 100n; C_0603_1608Metric; LCSC C14663
C13002: 1u; C_0603_1608Metric; LCSC C15849
R13001, R13002, R13003, R13004, R13005, R13006, R13007, R13008: 49.9R; R_0603_1608Metric; LCSC C114625

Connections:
+3V3: C13001.1, C13002.1, R13001.2, R13002.2, R13003.2, R13004.2, R13005.2, R13006.2, R13007.2, R13008.2; also elsewhere on the board
GND: C13001.2, C13002.2; also elsewhere on the board
HDMI_RX_CLK_N: R13008.1; also elsewhere on the board
HDMI_RX_CLK_P: R13007.1; also elsewhere on the board
HDMI_RX_D0_N: R13006.1; also elsewhere on the board
HDMI_RX_D0_P: R13005.1; also elsewhere on the board
HDMI_RX_D1_N: R13004.1; also elsewhere on the board
HDMI_RX_D1_P: R13003.1; also elsewhere on the board
HDMI_RX_D2_N: R13002.1; also elsewhere on the board
HDMI_RX_D2_P: R13001.1; also elsewhere on the board

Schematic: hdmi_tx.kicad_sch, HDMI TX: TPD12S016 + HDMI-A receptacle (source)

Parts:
C14001, C14002, C14003: 100n; C_0603_1608Metric; LCSC C14663
C14004: 1u; C_0603_1608Metric; LCSC C15849
C14005: 10u; C_0805_2012Metric; LCSC C15850
J14001: HDMI-019S; LCSC C111617
R14001, R14002: 10k; R_0603_1608Metric; LCSC C25804
TP14001: +5V_HDMI_TX; TestPoint_Pad_D1.5mm
TP14002: ZYNQ_HDMI_TX_SCL; TestPoint_Pad_D1.5mm
TP14003: ZYNQ_HDMI_TX_SDA; TestPoint_Pad_D1.5mm
U14001: TPD12S016PWR; LCSC C201665

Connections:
+3V3_HDMI_TX: C14001.1, C14005.1, R14001.1, R14002.1, U14001.24 (VCCA); also elsewhere on the board
+5V_HDMI_TX: C14002.1, TP14001.1, U14001.11 (VCC5V); also elsewhere on the board
/hdmi_tx/HDMI_TX_CON_5V0: C14003.1, C14004.1, J14001.18 (+5V), U14001.13 (5V_OUT)
/hdmi_tx/HDMI_TX_CON_CEC: J14001.13 (CEC), U14001.7 (CEC_B)
/hdmi_tx/HDMI_TX_CON_HPD: J14001.19 (HOT_PLUG_DET), U14001.10 (HPD_B-)
/hdmi_tx/HDMI_TX_CON_SCL: J14001.15 (I2C-CLK), U14001.8 (SCL_B)
/hdmi_tx/HDMI_TX_CON_SDA: J14001.16 (I2C_DATA), U14001.9 (SDA_B)
CHASSIS_GND: J14001.20 (SHD), J14001.21 (SHD), J14001.22 (SHD), J14001.23 (SHD); also elsewhere on the board
GND: C14001.2, C14002.2, C14003.2, C14004.2, C14005.2, J14001.2 (D2_SHIELD), J14001.5 (D1_SHIELD), J14001.8 (D0_SHIELD), J14001.11 (CK_SHIELD), J14001.17 (GND), U14001.6 (GND), U14001.14 (GND), U14001.19 (GND); also elsewhere on the board
unnamed: R14002.2, U14001.12 (CT_HPD)
unnamed: R14001.2, U14001.5 (LS_OE)
ZYNQ_HDMI_TX_CEC: U14001.1 (CEC_A); also elsewhere on the board
ZYNQ_HDMI_TX_HPD: U14001.4 (HPD_A-); also elsewhere on the board
ZYNQ_HDMI_TX_SCL: TP14002.1, U14001.2 (SCL_A); also elsewhere on the board
ZYNQ_HDMI_TX_SDA: TP14003.1, U14001.3 (SDA_A); also elsewhere on the board
ZYNQ_HDMI_TX_TMDS_0_N: J14001.9 (D0-), U14001.17 (D0-); also elsewhere on the board
ZYNQ_HDMI_TX_TMDS_0_P: J14001.7 (D0+), U14001.18 (D0+); also elsewhere on the board
ZYNQ_HDMI_TX_TMDS_1_N: J14001.6 (D1-), U14001.20 (D1-); also elsewhere on the board
ZYNQ_HDMI_TX_TMDS_1_P: J14001.4 (D1+), U14001.21 (D1+); also elsewhere on the board
ZYNQ_HDMI_TX_TMDS_2_N: J14001.3 (D2-), U14001.22 (D2-); also elsewhere on the board
ZYNQ_HDMI_TX_TMDS_2_P: J14001.1 (D2+), U14001.23 (D2+); also elsewhere on the board
ZYNQ_HDMI_TX_TMDS_CLK_N: J14001.12 (CK-), U14001.15 (CLK-); also elsewhere on the board
ZYNQ_HDMI_TX_TMDS_CLK_P: J14001.10 (CK+), U14001.16 (CLK+); also elsewhere on the board

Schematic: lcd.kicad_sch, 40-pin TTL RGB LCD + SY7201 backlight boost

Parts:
C15001, C15004: 10u; C_0805_2012Metric; LCSC C15850
C15002: 2.2u; C_0805_2012Metric; LCSC C125847
C15003: 100n; C_0603_1608Metric; LCSC C14663
C15005: 1u; C_0603_1608Metric; LCSC C15849
D15001: SS34; D_SMA; LCSC C8678
J15001: AFC07-S40FCA-00; LCSC C262572
L15001: 10uH; SWPA4030S100MT; LCSC C38117
R15001: 1.5R; R_0603_1608Metric; LCSC C22769
R15002, R15003: 4k7; R_0603_1608Metric; LCSC C23162
R15004, R15005: 100k; R_0603_1608Metric; LCSC C25803
R15006: 10k; R_0603_1608Metric; LCSC C25804
R15007: 22R; R_0603_1608Metric; LCSC C23345
TP15001: +5V_LCD; TestPoint_Pad_D1.5mm
TP15002: LCD_CTP_SDA; TestPoint_Pad_D1.5mm
TP15003: LCD_CTP_SCL; TestPoint_Pad_D1.5mm
U15001: SY7201ABC; LCSC C82173
U15002: USBLC6-2SC6; LCSC C7519

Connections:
+3V3: U15002.5; also elsewhere on the board
+3V3_LCD: C15003.1, C15004.1, J15001.4, R15002.2, R15003.2, R15006.2; also elsewhere on the board
+5V_LCD: C15001.1, C15005.1, L15001.1, TP15001.1, U15001.6 (IN); also elsewhere on the board
/lcd/CTP_SCL_FFC: J15001.38, U15002.3
/lcd/CTP_SDA_FFC: J15001.37, U15002.1
/lcd/LCD_VLED_N: J15001.1, R15001.1, U15001.3 (FB)
/lcd/LCD_VLED_P: C15002.1, D15001.1 (K), J15001.2, U15001.5 (OVP)
GND: C15001.2, C15002.2, C15003.2, C15004.2, C15005.2, J15001.3, J15001.29, J15001.36, R15001.2, R15004.2, R15005.2, U15001.2 (GND), U15002.2; also elsewhere on the board
LCD_B0: J15001.21; also elsewhere on the board
LCD_B1: J15001.22; also elsewhere on the board
LCD_B2: J15001.23; also elsewhere on the board
LCD_B3: J15001.24; also elsewhere on the board
LCD_B4: J15001.25; also elsewhere on the board
LCD_B5: J15001.26; also elsewhere on the board
LCD_B6: J15001.27; also elsewhere on the board
LCD_B7: J15001.28; also elsewhere on the board
LCD_BL_PWM: R15004.1, U15001.4 (EN/PWM); also elsewhere on the board
LCD_CTP_INT: J15001.40; also elsewhere on the board
LCD_CTP_RST: J15001.39, R15005.1; also elsewhere on the board
LCD_CTP_SCL: R15003.1, TP15003.1, U15002.4; also elsewhere on the board
LCD_CTP_SDA: R15002.1, TP15002.1, U15002.6; also elsewhere on the board
LCD_DE: J15001.34; also elsewhere on the board
LCD_DISP: J15001.31, R15006.1; also elsewhere on the board
LCD_G0: J15001.13; also elsewhere on the board
LCD_G1: J15001.14; also elsewhere on the board
LCD_G2: J15001.15; also elsewhere on the board
LCD_G3: J15001.16; also elsewhere on the board
LCD_G4: J15001.17; also elsewhere on the board
LCD_G5: J15001.18; also elsewhere on the board
LCD_G6: J15001.19; also elsewhere on the board
LCD_G7: J15001.20; also elsewhere on the board
LCD_HSYNC: J15001.32; also elsewhere on the board
LCD_PCLK: R15007.2; also elsewhere on the board
LCD_R0: J15001.5; also elsewhere on the board
LCD_R1: J15001.6; also elsewhere on the board
LCD_R2: J15001.7; also elsewhere on the board
LCD_R3: J15001.8; also elsewhere on the board
LCD_R4: J15001.9; also elsewhere on the board
LCD_R5: J15001.10; also elsewhere on the board
LCD_R6: J15001.11; also elsewhere on the board
LCD_R7: J15001.12; also elsewhere on the board
LCD_VSYNC: J15001.33; also elsewhere on the board
unnamed: D15001.2 (A), L15001.2, U15001.1 (LX)
unnamed: J15001.30, R15007.1

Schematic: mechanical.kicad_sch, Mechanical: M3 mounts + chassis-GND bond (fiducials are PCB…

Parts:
H34001, H34002, H34003, H34004: MountingHole_M3; MountingHole_3.2mm_M3_Pad

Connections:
CHASSIS_GND: H34001.1, H34002.1, H34003.1, H34004.1; also elsewhere on the board

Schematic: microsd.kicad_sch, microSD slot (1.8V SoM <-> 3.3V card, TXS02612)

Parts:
C16001, C16002, C16004: 100n; C_0603_1608Metric; LCSC C14663
C16003: 22u; C_0805_2012Metric; LCSC C45783
J16001: TF-01A; LCSC C91145
R16001, R16002, R16003, R16004, R16005: 100k; R_0603_1608Metric; LCSC C25803
R16006: 10k; R_0603_1608Metric; LCSC C25804
TP16001: SDIO_CMD; TestPoint_Pad_D1.5mm
TP16002: SDIO_CLK; TestPoint_Pad_D1.5mm
U16001: TXS02612RTWR; LCSC C140276
U16002: TPD6E001RSER; LCSC C1973318

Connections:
+1V8: C16001.1, U16001.5 (VCCA); also elsewhere on the board
+3V3_SD: C16002.1, C16003.1, C16004.1, J16001.4 (VDD), R16001.1, R16002.1, R16003.1, R16004.1, R16005.1, R16006.1, U16001.17 (VCCB1), U16001.21 (VCCB0), U16002.10 (VCC); also elsewhere on the board
/microsd/SD_CARD_CLK: J16001.5 (CLK(SCLK)), U16001.19 (CLKB0), U16002.1 (IO1)
/microsd/SD_CARD_CMD: J16001.3 (CMD(DI)), R16001.2, U16001.20 (CMDB0), U16002.2 (IO2)
/microsd/SD_CARD_D0: J16001.7 (DAT0(D0)), R16002.2, U16001.18 (DAT0B0), U16002.3 (IO3)
/microsd/SD_CARD_D1: J16001.8 (DAT1(RSV)), R16003.2, U16001.16 (DAT1B0), U16002.6 (IO4)
/microsd/SD_CARD_D2: J16001.1 (DAT2(RSV)), R16004.2, U16001.23 (DAT2B0), U16002.7 (IO5)
/microsd/SD_CARD_D3: J16001.2 (CDDAT3(CS)), R16005.2, U16001.22 (DAT3B0), U16002.8 (IO6)
GND: C16001.2, C16002.2, C16003.2, C16004.2, J16001.6 (VSS), J16001.10 (GND), J16001.11 (GND), J16001.12 (GND), J16001.13 (GND), U16001.2 (GND), U16001.11 (GND), U16001.24 (SEL), U16001.25 (EP), U16002.5 (GND); also elsewhere on the board
SDIO_CLK: TP16002.1, U16001.9 (CLKA); also elsewhere on the board
SDIO_CMD: TP16001.1, U16001.4 (CMDA); also elsewhere on the board
SDIO_D0: U16001.6 (DAT0A); also elsewhere on the board
SDIO_D1: U16001.7 (DAT1A); also elsewhere on the board
SDIO_D2: U16001.1 (DAT2A); also elsewhere on the board
SDIO_D3: U16001.3 (DAT3A); also elsewhere on the board
SD_CARD_DETECT: J16001.9 (CD), R16006.2; also elsewhere on the board

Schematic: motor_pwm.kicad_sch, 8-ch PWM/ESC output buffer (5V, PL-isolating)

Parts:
C36001, C36002: 100n; C_0603_1608Metric; LCSC C14663
C36003: 10u; C_0805_2012Metric; LCSC C15850
D36001, D36002: SRV05-4; SOT-23-6; LCSC C2836319
J36001: HX PZ2.54-3x8P ZZ; HX_PZ2.54-3x8P_ZZ; LCSC C32713295
R36001: 10k; R_0603_1608Metric; LCSC C25804
R36002: 13k; R_0603_1608Metric; LCSC C22797
RN36001, RN36002: 4D03WGJ0330T5E; LCSC C25508
TP36001: +5V_MOTOR_IO; TestPoint_Pad_D1.5mm
U36001: SN74HCT245PWR; LCSC C6779
U36003: SY6280AAC; LCSC C55136

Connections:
+5V: C36001.1, C36002.1, D36001.5 (VP), D36002.5 (VP), R36001.1, U36001.1 (DIR), U36001.20 (VCC), U36003.4 (EN), U36003.5 (IN); also elsewhere on the board
+5V_MOTOR_IO: C36003.1, J36001.9, J36001.10, J36001.11, J36001.12, J36001.13, J36001.14, J36001.15, J36001.16, TP36001.1, U36003.1 (OUT)
/motor_pwm/ESC_OUT0: D36001.1 (IO1), J36001.1, RN36001.8
/motor_pwm/ESC_OUT1: D36001.3 (IO2), J36001.2, RN36001.7
/motor_pwm/ESC_OUT2: D36001.4 (IO3), J36001.3, RN36001.6
/motor_pwm/ESC_OUT3: D36001.6 (IO4), J36001.4, RN36001.5
/motor_pwm/ESC_OUT4: D36002.1 (IO1), J36001.5, RN36002.8
/motor_pwm/ESC_OUT5: D36002.3 (IO2), J36001.6, RN36002.7
/motor_pwm/ESC_OUT6: D36002.4 (IO3), J36001.7, RN36002.6
/motor_pwm/ESC_OUT7: D36002.6 (IO4), J36001.8, RN36002.5
/motor_pwm/ESC_SIG0: RN36001.1, U36001.18 (B1)
/motor_pwm/ESC_SIG1: RN36001.2, U36001.17 (B2)
/motor_pwm/ESC_SIG2: RN36001.3, U36001.16 (B3)
/motor_pwm/ESC_SIG3: RN36001.4, U36001.15 (B4)
/motor_pwm/ESC_SIG4: RN36002.1, U36001.14 (B5)
/motor_pwm/ESC_SIG5: RN36002.2, U36001.13 (B6)
/motor_pwm/ESC_SIG6: RN36002.3, U36001.12 (B7)
/motor_pwm/ESC_SIG7: RN36002.4, U36001.11 (B8)
ESC_BUF_OE_N: R36001.2, U36001.19 (#OE); also elsewhere on the board
ESC_PWM_IN0: U36001.2 (A1); also elsewhere on the board
ESC_PWM_IN1: U36001.3 (A2); also elsewhere on the board
ESC_PWM_IN2: U36001.4 (A3); also elsewhere on the board
ESC_PWM_IN3: U36001.5 (A4); also elsewhere on the board
ESC_PWM_IN4: U36001.6 (A5); also elsewhere on the board
ESC_PWM_IN5: U36001.7 (A6); also elsewhere on the board
ESC_PWM_IN6: U36001.8 (A7); also elsewhere on the board
ESC_PWM_IN7: U36001.9 (A8); also elsewhere on the board
GND: C36001.2, C36002.2, C36003.2, D36001.2 (VN), D36002.2 (VN), J36001.17, J36001.18, J36001.19, J36001.20, J36001.21, J36001.22, J36001.23, J36001.24, R36002.2, U36001.10 (GND), U36003.2 (GND); also elsewhere on the board
unnamed: R36002.1, U36003.3 (ISET)

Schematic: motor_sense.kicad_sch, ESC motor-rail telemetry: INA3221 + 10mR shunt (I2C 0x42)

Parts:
C37001, C37002: 100n; C_0603_1608Metric; LCSC C14663
C37003: 10u; C_0805_2012Metric; LCSC C15850
C37004: 470uF/35V; CP_Elec_10x10.5; LCSC C976030
D37001: SMBJ28A; LCSC C42440491
J37002, J37003: XT60PW-M; LCSC C98732
R37001: 10k; R_0603_1608Metric; LCSC C25804
RS37001: 10mR; RLM12FTCMR010; LCSC C188070
U37002: INA3221AIRGVR; LCSC C181255

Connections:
+3V3_SC: C37002.1, C37003.1, R37001.1, U37002.4 (VS), U37002.16 (VPU); also elsewhere on the board
/motor_sense/ESC_VRAIL: C37004.1, J37003.2 (+), RS37001.2, U37002.11 (IN-1)
/motor_sense/ESC_VRAIL_IN: C37001.1, D37001.1 (K), J37002.2 (+), RS37001.1, U37002.12 (IN+1)
ESC_FAULT_N: R37001.2, U37002.9 (CRITICAL); also elsewhere on the board
GND: C37001.2, C37002.2, C37003.2, C37004.2, D37001.2 (A), J37002.1 (-), J37002.3, J37002.4, J37003.1 (-), J37003.3, J37003.4, U37002.1 (IN-3), U37002.2 (IN+3), U37002.3 (GND), U37002.14 (IN-2), U37002.15 (IN+2), U37002.17 (PAD); also elsewhere on the board
STM32_I2C2_SCL: U37002.6 (SCL); also elsewhere on the board
STM32_I2C2_SDA: U37002.5 (A0), U37002.7 (SDA); also elsewhere on the board

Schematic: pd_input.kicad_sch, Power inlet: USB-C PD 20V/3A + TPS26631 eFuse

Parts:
C17001: 100n; C_0603_1608Metric; LCSC C14663
C17002: 10u; C_1210_3225Metric; LCSC C596319
C17003: 47n; C_0603_1608Metric; LCSC C1622
D17001: SMBJ22A; D_SMB; LCSC C10214
J17001: TYPE-C-31-M-12; LCSC C165948
R17003, R17006: 100k; R_0603_1608Metric; LCSC C25803
R17004: 5.49k; R_0603_1608Metric; LCSC C188263
R17005: 5.1k; R_0603_1608Metric; LCSC C23186
TP17001: +VBUS_IN; TestPoint_Pad_D1.5mm
TP17002: +VIN; TestPoint_Pad_D1.5mm
U17001: TPS26631PWPR; LCSC C2866319
U17002: USBLC6-2SC6; LCSC C7519

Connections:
+3V3_SC: R17006.1, U17002.5; also elsewhere on the board
+VBUS_IN: C17001.1, D17001.1 (K), J17001.A4B9 (VBUS), J17001.B4A9 (VBUS), R17003.1, TP17001.1, U17001.1 (IN), U17001.2 (IN), U17001.3 (IN), U17001.6 (IN_SYS), U17001.7 (UVLO); also elsewhere on the board
+VIN: C17002.1, TP17002.1, U17001.18 (OUT), U17001.19 (OUT), U17001.20 (OUT); also elsewhere on the board
/pd_input/PD_USB_DN_CONN: J17001.A7 (DN1), J17001.B7 (DN2), U17002.3
/pd_input/PD_USB_DP_CONN: J17001.A6 (DP1), J17001.B6 (DP2), U17002.1
CHASSIS_GND: J17001.1 (EH), J17001.2 (EH), J17001.3 (EH), J17001.4 (EH); also elsewhere on the board
GND: C17001.2, C17002.2, C17003.2, D17001.2 (A), J17001.A1B12 (GND), J17001.B1A12 (GND), R17004.2, R17005.2, U17001.9 (GND), U17001.12 (MODE), U17001.16 (PGTH), U17001.21 (EP), U17002.2; also elsewhere on the board
unnamed: R17005.1, U17001.11 (ILIM)
unnamed: R17003.2, R17004.1, U17001.8 (OVP)
unnamed: C17003.1, U17001.10 (dVdT)
PD_FLT_N: R17006.2, U17001.15 (FLT#); also elsewhere on the board
STM32_USB_CC1: J17001.A5 (CC1); also elsewhere on the board
STM32_USB_CC2: J17001.B5 (CC2); also elsewhere on the board
STM32_USB_D_N: U17002.4; also elsewhere on the board
STM32_USB_D_P: U17002.6; also elsewhere on the board

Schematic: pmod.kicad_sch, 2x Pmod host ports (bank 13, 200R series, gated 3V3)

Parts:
C18001, C18003: 100n; C_0603_1608Metric; LCSC C14663
C18002, C18004: 10u; C_0805_2012Metric; LCSC C15850
J18001, J18002: DS1024-2x6R2; LCSC C49284652
R18001, R18002, R18003, R18004, R18005, R18006, R18007, R18008, R18009, R18010, R18011, R18012, R18013, R18014, R18015, R18016: 200R; R_0603_1608Metric; LCSC C8218
U18001, U18002, U18003, U18004: TPD4E1U06; TPD4E1U06DBVR; LCSC C124691

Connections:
+3V3_PMOD: C18001.1, C18002.1, C18003.1, C18004.1, J18001.11, J18001.12, J18002.11, J18002.12; also elsewhere on the board
GND: C18001.2, C18002.2, C18003.2, C18004.2, J18001.9, J18001.10, J18002.9, J18002.10, U18001.2 (GND), U18002.2 (GND), U18003.2 (GND), U18004.2 (GND); also elsewhere on the board
IO_L2_N_13: R18002.1, U18001.3 (D2+); also elsewhere on the board
IO_L2_P_13: R18001.1, U18001.1 (D1+); also elsewhere on the board
IO_L3_N_13: R18004.1, U18001.4 (D2-); also elsewhere on the board
IO_L3_P_13: R18003.1, U18001.6 (D1-); also elsewhere on the board
IO_L4_N_13: R18006.1, U18002.3 (D2+); also elsewhere on the board
IO_L4_P_13: R18005.1, U18002.1 (D1+); also elsewhere on the board
IO_L5P_13: R18007.1, U18002.6 (D1-); also elsewhere on the board
IO_L5_N_13: R18008.1, U18002.4 (D2-); also elsewhere on the board
IO_L7_N_13: R18010.1, U18003.3 (D2+); also elsewhere on the board
IO_L7_P_13: R18009.1, U18003.1 (D1+); also elsewhere on the board
IO_L8_N_13: R18012.1, U18003.4 (D2-); also elsewhere on the board
IO_L8_P_13: R18011.1, U18003.6 (D1-); also elsewhere on the board
IO_L9_DQS_N_13: R18014.1, U18004.3 (D2+); also elsewhere on the board
IO_L9_DQS_P_13: R18013.1, U18004.1 (D1+); also elsewhere on the board
IO_L10_N_13: R18016.1, U18004.4 (D2-); also elsewhere on the board
IO_L10_P_13: R18015.1, U18004.6 (D1-); also elsewhere on the board
unnamed: J18001.1, R18001.2
unnamed: J18001.2, R18005.2
unnamed: J18001.3, R18002.2
unnamed: J18001.4, R18006.2
unnamed: J18001.5, R18003.2
unnamed: J18001.6, R18007.2
unnamed: J18001.7, R18004.2
unnamed: J18001.8, R18008.2
unnamed: J18002.1, R18009.2
unnamed: J18002.2, R18013.2
unnamed: J18002.3, R18010.2
unnamed: J18002.4, R18014.2
unnamed: J18002.5, R18011.2
unnamed: J18002.6, R18015.2
unnamed: J18002.7, R18012.2
unnamed: J18002.8, R18016.2

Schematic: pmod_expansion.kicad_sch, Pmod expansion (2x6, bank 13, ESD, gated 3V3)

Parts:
C19001, C19003, C19004: 100n; C_0603_1608Metric; LCSC C14663
C19002, C19005: 10u; C_0805_2012Metric; LCSC C15850
D19001: red; LED_0603_1608Metric; LCSC C2286
J19001: DS1024-2x6R2; LCSC C49284652
R19001: 13k; R_0603_1608Metric; LCSC C22797
R19002: 100k; R_0603_1608Metric; LCSC C25803
R19003: 330R; R_0603_1608Metric; LCSC C23138
SW19001: DSHP04TSGER; LCSC C3293144
TP19001: +3V3_PMODX; TestPoint_Pad_D1.5mm
U19001: SY6280AAC; LCSC C55136
U19002, U19003: TPD4E1U06; TPD4E1U06DBVR; LCSC C124691

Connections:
+3V3: C19001.1, C19002.1, SW19001.1, SW19001.3, SW19001.5, SW19001.7, U19001.5 (IN); also elsewhere on the board
+3V3_PMODX: C19003.1, C19004.1, C19005.1, D19001.2 (A), J19001.11, J19001.12, TP19001.1, U19001.1 (OUT)
/pmod_expansion/EN_PMODX: R19002.1, SW19001.8, U19001.4 (EN)
GND: C19001.2, C19002.2, C19003.2, C19004.2, C19005.2, J19001.9, J19001.10, R19001.2, R19002.2, R19003.2, U19001.2 (GND), U19002.2 (GND), U19003.2 (GND); also elsewhere on the board
unnamed: D19001.1 (K), R19003.1
unnamed: R19001.1, U19001.3 (ISET)
PMODX_IO1: J19001.1, U19002.1 (D1+); also elsewhere on the board
PMODX_IO2: J19001.3, U19002.3 (D2+); also elsewhere on the board
PMODX_IO3: J19001.5, U19002.6 (D1-); also elsewhere on the board
PMODX_IO4: J19001.7, U19002.4 (D2-); also elsewhere on the board
PMODX_IO5: J19001.2, U19003.1 (D1+); also elsewhere on the board
PMODX_IO6: J19001.4, U19003.3 (D2+); also elsewhere on the board
PMODX_IO7: J19001.6, U19003.6 (D1-); also elsewhere on the board
PMODX_IO8: J19001.8, U19003.4 (D2-); also elsewhere on the board

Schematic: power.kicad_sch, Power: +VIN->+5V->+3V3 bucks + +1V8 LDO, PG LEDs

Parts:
C20001, C20004, C20007, C20009, C20025, C20029: 100n; C_0603_1608Metric; LCSC C14663
C20002, C20003: 10u; C_1206_3216Metric; LCSC C13585
C20005, C20006, C20008, C20010, C20011, C20026, C20030: 22u; C_0805_2012Metric; LCSC C45783
C20012, C20013, C20024, C20028, C20031, C20032: 1u; C_0603_1608Metric; LCSC C15849
C20023, C20027: 22p; C_0603_1608Metric; LCSC C1653
D20001, D20002, D20003: red; LED_0603_1608Metric; LCSC C2286
L20001, L20002: 10uH; SWPA8040S100MT; LCSC C37429
Q20001: AO3400A; SOT-23; MPN AO3400A; LCSC C20917
R20001: 40.2k; R_0603_1608Metric; LCSC C12447
R20002, R20005: 10k; R_0603_1608Metric; LCSC C25804
R20003, R20007, R20012, R20015: 1k; R_0603_1608Metric; LCSC C21190
R20004: 23.2k; R_0603_1608Metric; LCSC C23346
R20006, R20009: 330R; R_0603_1608Metric; LCSC C23138
R20008: 100k; R_0603_1608Metric; LCSC C25803
R20010, R20014: 22k; R_0603_1608Metric; LCSC C31850
R20011, R20013: 10R; R_0603_1608Metric; LCSC C22859
TP20001: +5V; TestPoint_Pad_D1.5mm
TP20002: +3V3; TestPoint_Pad_D1.5mm
TP20003: +1V8; TestPoint_Pad_D1.5mm
TP20004: GND; TestPoint_Pad_D1.5mm
U20001, U20002: LM61460AANRJRR; LCSC C2864505
U20003: AP2112K-1.8; SOT-23-5; MPN AP2112K-1.8TRG1; LCSC C176944

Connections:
+1V8: R20007.1, TP20003.1; also elsewhere on the board
+1V8_REG: C20013.1, U20003.5 (VOUT); also elsewhere on the board
+3V3: C20012.1, D20003.2 (A), TP20002.1, U20003.1 (VIN); also elsewhere on the board
+3V3_REG: C20010.1, C20011.1, C20023.1, D20002.2 (A), L20002.2, R20004.1, R20013.1; also elsewhere on the board
+5V: C20007.1, C20008.1, C20029.1, C20030.1, TP20001.1, U20002.8 (VIN1), U20002.12 (VIN2); also elsewhere on the board
+5V_REG: C20005.1, C20006.1, C20026.1, C20027.1, D20001.2 (A), L20001.2, R20001.1, R20011.1; also elsewhere on the board
+VIN_SYS: C20001.1, C20002.1, C20003.1, C20025.1, U20001.8 (VIN1), U20001.12 (VIN2); also elsewhere on the board
/power/BIAS_3V3: C20032.1, R20013.2, U20002.1 (BIAS)
/power/BIAS_5V0: C20028.1, R20011.2, U20001.1 (BIAS)
/power/RT_3V3: R20014.1, U20002.6 (RT)
/power/RT_5V0: R20010.1, U20001.6 (RT)
EN_1V8: U20003.3 (EN); also elsewhere on the board
EN_3V3: U20002.7 (EN/SYNC); also elsewhere on the board
EN_5V0: U20001.7 (EN/SYNC); also elsewhere on the board
GND: C20001.2, C20002.2, C20003.2, C20005.2, C20006.2, C20007.2, C20008.2, C20010.2, C20011.2, C20012.2, C20013.2, C20024.2, C20025.2, C20026.2, C20028.2, C20029.2, C20030.2, C20031.2, C20032.2, Q20001.2 (S), R20002.2, R20003.2, R20005.2, R20006.2, R20008.2, R20010.2, R20014.2, TP20004.1, U20001.3 (AGND), U20001.9 (PGND1), U20001.11 (PGND2), U20002.3 (AGND), U20002.9 (PGND1), U20002.11 (PGND2), U20003.2 (GND); also elsewhere on the board
unnamed: C20023.2, R20015.1
unnamed: C20027.2, R20012.1
unnamed: D20001.1 (K), R20003.1
unnamed: D20002.1 (K), R20006.1
unnamed: D20003.1 (K), R20009.1
unnamed: Q20001.3 (D), R20009.2
unnamed: Q20001.1 (G), R20007.2, R20008.1
unnamed: C20004.1, U20001.13 (RBOOT), U20001.14 (CBOOT)
unnamed: R20001.2, R20002.1, R20012.2, U20001.4 (FB)
unnamed: C20004.2, L20001.1, U20001.10 (SW)
unnamed: C20024.1, U20001.2 (VCC)
unnamed: C20009.1, U20002.13 (RBOOT), U20002.14 (CBOOT)
unnamed: R20004.2, R20005.1, R20015.2, U20002.4 (FB)
unnamed: C20009.2, L20002.1, U20002.10 (SW)
unnamed: C20031.1, U20002.2 (VCC)

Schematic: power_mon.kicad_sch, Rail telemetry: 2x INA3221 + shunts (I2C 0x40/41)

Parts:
C21001, C21002: 100n; C_0603_1608Metric; LCSC C14663
C21003: 10u; C_0805_2012Metric; LCSC C15850
R21001: 10k; R_0603_1608Metric; LCSC C25804
RS21001, RS21002, RS21003: 10mR; RLM12FTCMR010; LCSC C188070
RS21004: 20mR; RLM12FTCMR020; LCSC C393094
U21001, U21002: INA3221AIRGVR; LCSC C181255

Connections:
+1V8: RS21004.2, U21002.11 (IN-1); also elsewhere on the board
+1V8_REG: RS21004.1, U21002.12 (IN+1); also elsewhere on the board
+3V3: RS21003.2, U21001.1 (IN-3); also elsewhere on the board
+3V3_REG: RS21003.1, U21001.2 (IN+3); also elsewhere on the board
+3V3_SC: C21001.1, C21002.1, C21003.1, R21001.1, U21001.4 (VS), U21001.16 (VPU), U21002.4 (VS), U21002.5 (A0), U21002.16 (VPU); also elsewhere on the board
+5V: RS21002.2, U21001.14 (IN-2); also elsewhere on the board
+5V_REG: RS21002.1, U21001.15 (IN+2); also elsewhere on the board
+VIN: RS21001.1, U21001.12 (IN+1); also elsewhere on the board
+VIN_SYS: RS21001.2, U21001.11 (IN-1); also elsewhere on the board
GND: C21001.2, C21002.2, C21003.2, U21001.3 (GND), U21001.5 (A0), U21001.17 (PAD), U21002.1 (IN-3), U21002.2 (IN+3), U21002.3 (GND), U21002.14 (IN-2), U21002.15 (IN+2), U21002.17 (PAD); also elsewhere on the board
PMON_ALERT_N: R21001.2, U21001.9 (CRITICAL), U21002.9 (CRITICAL); also elsewhere on the board
STM32_I2C2_SCL: U21001.6 (SCL), U21002.6 (SCL); also elsewhere on the board
STM32_I2C2_SDA: U21001.7 (SDA), U21002.7 (SDA); also elsewhere on the board

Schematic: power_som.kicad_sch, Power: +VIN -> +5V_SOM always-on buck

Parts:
C22014, C22017, C22020, C22025: 100n; C_0603_1608Metric; LCSC C14663
C22015, C22016: 10u; C_1206_3216Metric; LCSC C13585
C22018, C22019: 22u; C_0805_2012Metric; LCSC C45783
C22021: 22p; C_0603_1608Metric; LCSC C1653
C22022, C22023: 1u; C_0603_1608Metric; LCSC C15849
D22004: red; LED_0603_1608Metric; LCSC C2286
D22005: MMSZ5231B; D_SOD-123; LCSC C85181
L22003: 10uH; SWPA8040S100MT; LCSC C37429
R22012: 10k; R_0603_1608Metric; LCSC C25804
R22014: 47.5k; R_0603_1608Metric; LCSC C23061
R22015: 13k; R_0603_1608Metric; LCSC C22797
R22016, R22019: 1k; R_0603_1608Metric; LCSC C21190
R22017: 10R; R_0603_1608Metric; LCSC C22859
R22018: 22k; R_0603_1608Metric; LCSC C31850
TP22001: +5V_SOM; TestPoint_Pad_D1.5mm
U22004: LM61460AANRJRR; LCSC C2864505

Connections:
+5V_SOM: C22018.1, C22019.1, C22021.1, D22004.2 (A), L22003.2, R22014.1, R22017.1, TP22001.1; also elsewhere on the board
+VIN_SYS: C22014.1, C22015.1, C22016.1, C22025.1, R22012.1, U22004.8 (VIN1), U22004.12 (VIN2); also elsewhere on the board
/power_som/BIAS_5V_SOM: C22023.1, R22017.2, U22004.1 (BIAS)
/power_som/EN_5V_SOM: C22020.1, D22005.1 (K), R22012.2, U22004.7 (EN/SYNC)
/power_som/RT_5V_SOM: R22018.1, U22004.6 (RT)
GND: C22014.2, C22015.2, C22016.2, C22018.2, C22019.2, C22020.2, C22022.2, C22023.2, C22025.2, D22005.2 (A), R22015.2, R22016.2, R22018.2, U22004.3 (AGND), U22004.9 (PGND1), U22004.11 (PGND2); also elsewhere on the board
unnamed: C22021.2, R22019.1
unnamed: D22004.1 (K), R22016.1
unnamed: C22017.1, U22004.13 (RBOOT), U22004.14 (CBOOT)
unnamed: R22014.2, R22015.1, R22019.2, U22004.4 (FB)
unnamed: C22017.2, L22003.1, U22004.10 (SW)
unnamed: C22022.1, U22004.2 (VCC)

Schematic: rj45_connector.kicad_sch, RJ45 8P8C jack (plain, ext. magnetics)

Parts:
J23001: KH-5224-8P8C-D; LCSC C2828085
R23001, R23002: 330R; R_0603_1608Metric; LCSC C23138

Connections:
+3V3: R23001.1, R23002.1; also elsewhere on the board
CHASSIS_GND: J23001.13 (SHELL); also elsewhere on the board
ETH_LINE_MDI_0_N: J23001.2; also elsewhere on the board
ETH_LINE_MDI_0_P: J23001.1; also elsewhere on the board
ETH_LINE_MDI_1_N: J23001.6; also elsewhere on the board
ETH_LINE_MDI_1_P: J23001.3; also elsewhere on the board
ETH_LINE_MDI_2_N: J23001.5; also elsewhere on the board
ETH_LINE_MDI_2_P: J23001.4; also elsewhere on the board
ETH_LINE_MDI_3_N: J23001.8; also elsewhere on the board
ETH_LINE_MDI_3_P: J23001.7; also elsewhere on the board
GND: J23001.10 (LED-L-), J23001.12 (LED-R-); also elsewhere on the board
unnamed: J23001.9 (LED-L+), R23001.2
unnamed: J23001.11 (LED-R+), R23002.2

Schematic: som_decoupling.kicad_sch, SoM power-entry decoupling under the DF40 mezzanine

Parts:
C35001, C35002, C35007, C35008, C35013, C35014: 22u; C_0805_2012Metric; LCSC C45783
C35003, C35004, C35005, C35006, C35009, C35010, C35011, C35012, C35015, C35016, C35017, C35018: 100n; C_0603_1608Metric; LCSC C14663

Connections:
+3V3: C35007.1, C35008.1, C35009.1, C35010.1, C35011.1, C35012.1; also elsewhere on the board
+3V3_SC: C35013.1, C35014.1, C35015.1, C35016.1, C35017.1, C35018.1; also elsewhere on the board
+5V_SOM: C35001.1, C35002.1, C35003.1, C35004.1, C35005.1, C35006.1; also elsewhere on the board
GND: C35001.2, C35002.2, C35003.2, C35004.2, C35005.2, C35006.2, C35007.2, C35008.2, C35009.2, C35010.2, C35011.2, C35012.2, C35013.2, C35014.2, C35015.2, C35016.2, C35017.2, C35018.2; also elsewhere on the board

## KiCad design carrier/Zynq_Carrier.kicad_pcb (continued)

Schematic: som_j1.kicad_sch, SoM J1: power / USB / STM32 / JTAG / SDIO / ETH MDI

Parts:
J24001: DF40C-100DP-0.4V(51); DF40C-100DP-0.4V_51; LCSC C531031

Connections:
+3V3_SC: J24001.37; also elsewhere on the board
+5V_SOM: J24001.1, J24001.2, J24001.3, J24001.4, J24001.5, J24001.6, J24001.7, J24001.8, J24001.9, J24001.10, J24001.11, J24001.12, J24001.13, J24001.14; also elsewhere on the board
ETH_LED1: J24001.98
ETH_LED2: J24001.94
ETH_PHY_MDI0_N: J24001.95; also elsewhere on the board
ETH_PHY_MDI0_P: J24001.97; also elsewhere on the board
ETH_PHY_MDI1_N: J24001.89; also elsewhere on the board
ETH_PHY_MDI1_P: J24001.91; also elsewhere on the board
ETH_PHY_MDI2_N: J24001.83; also elsewhere on the board
ETH_PHY_MDI2_P: J24001.85; also elsewhere on the board
ETH_PHY_MDI3_N: J24001.77; also elsewhere on the board
ETH_PHY_MDI3_P: J24001.79; also elsewhere on the board
FMC_LA08_N: J24001.92; also elsewhere on the board
FMC_LA08_P: J24001.74; also elsewhere on the board
FMC_LA09_N: J24001.84; also elsewhere on the board
FMC_LA09_P: J24001.80; also elsewhere on the board
FMC_LA10_N: J24001.88; also elsewhere on the board
FMC_LA10_P: J24001.90; also elsewhere on the board
FMC_LA11_N: J24001.76; also elsewhere on the board
FMC_LA11_P: J24001.78; also elsewhere on the board
GND: J24001.15, J24001.16, J24001.17, J24001.18, J24001.23, J24001.28, J24001.34, J24001.39, J24001.44, J24001.51, J24001.62, J24001.63, J24001.72, J24001.75, J24001.81, J24001.82, J24001.87, J24001.93, J24001.96, J24001.99; also elsewhere on the board
IO_0_35: J24001.86
IO_L2_N_35: J24001.100
SC_INT_N: J24001.41; also elsewhere on the board
SDIO_CLK: J24001.67; also elsewhere on the board
SDIO_CMD: J24001.69; also elsewhere on the board
SDIO_D0: J24001.65; also elsewhere on the board
SDIO_D1: J24001.61; also elsewhere on the board
SDIO_D2: J24001.73; also elsewhere on the board
SDIO_D3: J24001.71; also elsewhere on the board
STM32_BOOT0: J24001.57; also elsewhere on the board
STM32_GPIO5: J24001.53; also elsewhere on the board
STM32_GPIO6: J24001.45; also elsewhere on the board
STM32_GPIO7: J24001.59; also elsewhere on the board
STM32_GPIO8: J24001.54; also elsewhere on the board
STM32_I2C2_SCL: J24001.55; also elsewhere on the board
STM32_I2C2_SDA: J24001.49; also elsewhere on the board
STM32_NRST: J24001.47; also elsewhere on the board
STM32_RAIL_EN_1V8: J24001.43; also elsewhere on the board
STM32_RAIL_EN_3V3: J24001.35; also elsewhere on the board
STM32_RAIL_EN_5V0: J24001.33; also elsewhere on the board
STM32_USB_CC1: J24001.29; also elsewhere on the board
STM32_USB_CC2: J24001.31; also elsewhere on the board
STM32_USB_D_N: J24001.21; also elsewhere on the board
STM32_USB_D_P: J24001.19; also elsewhere on the board
USB_D+: J24001.32; also elsewhere on the board
USB_D-: J24001.30; also elsewhere on the board
USB_ID: J24001.20; also elsewhere on the board
USB_VBUS: J24001.22; also elsewhere on the board
VBUS_OUT_EN: J24001.38; also elsewhere on the board
ZYNQ_PS_MIO0: J24001.50
ZYNQ_PS_MIO7/VM0: J24001.40
ZYNQ_PS_MIO8\VM1: J24001.36
ZYNQ_PS_MIO9: J24001.52
ZYNQ_PS_MIO12: J24001.46
ZYNQ_PS_UART0_RXD: J24001.42; also elsewhere on the board
ZYNQ_PS_UART0_TXD: J24001.48; also elsewhere on the board
ZYNQ_TCK: J24001.64; also elsewhere on the board
ZYNQ_TDI: J24001.70; also elsewhere on the board
ZYNQ_TDO: J24001.68; also elsewhere on the board
ZYNQ_TMS: J24001.66; also elsewhere on the board

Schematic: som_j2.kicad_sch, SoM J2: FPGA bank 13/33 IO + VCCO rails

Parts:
J25002: DF40C-100DP-0.4V(51); DF40C-100DP-0.4V_51; LCSC C531031

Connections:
+3V3: J25002.1, J25002.2, J25002.3, J25002.98, J25002.99, J25002.100; also elsewhere on the board
DBG_UART_RXD: J25002.42; also elsewhere on the board
DBG_UART_TXD: J25002.40; also elsewhere on the board
ESC_BUF_OE_N: J25002.57; also elsewhere on the board
ESC_FAULT_N: J25002.37; also elsewhere on the board
ESC_PWM_IN0: J25002.81; also elsewhere on the board
ESC_PWM_IN1: J25002.83; also elsewhere on the board
ESC_PWM_IN2: J25002.93; also elsewhere on the board
ESC_PWM_IN3: J25002.91; also elsewhere on the board
GND: J25002.4, J25002.5, J25002.6, J25002.15, J25002.16, J25002.25, J25002.26, J25002.35, J25002.36, J25002.45, J25002.46, J25002.55, J25002.56, J25002.65, J25002.66, J25002.75, J25002.76, J25002.85, J25002.86, J25002.95, J25002.96, J25002.97; also elsewhere on the board
HDMI_RX_5V_DET: J25002.44; also elsewhere on the board
HDMI_RX_CEC: J25002.59; also elsewhere on the board
HDMI_RX_CLK_N: J25002.88; also elsewhere on the board
HDMI_RX_CLK_P: J25002.90; also elsewhere on the board
HDMI_RX_D0_N: J25002.94; also elsewhere on the board
HDMI_RX_D0_P: J25002.92; also elsewhere on the board
HDMI_RX_D1_N: J25002.84; also elsewhere on the board
HDMI_RX_D1_P: J25002.82; also elsewhere on the board
HDMI_RX_D2_N: J25002.80; also elsewhere on the board
HDMI_RX_D2_P: J25002.78; also elsewhere on the board
IO_25_13: J25002.23; also elsewhere on the board
IO_L2_N_13: J25002.14; also elsewhere on the board
IO_L2_P_13: J25002.20; also elsewhere on the board
IO_L3_N_13: J25002.43; also elsewhere on the board
IO_L3_P_13: J25002.18; also elsewhere on the board
IO_L4_N_13: J25002.63; also elsewhere on the board
IO_L4_P_13: J25002.61; also elsewhere on the board
IO_L5P_13: J25002.38; also elsewhere on the board
IO_L5_N_13: J25002.24; also elsewhere on the board
IO_L6_P_13: J25002.21; also elsewhere on the board
IO_L6_P_33: J25002.89
IO_L7_N_13: J25002.64; also elsewhere on the board
IO_L7_P_13: J25002.62; also elsewhere on the board
IO_L8_N_13: J25002.60; also elsewhere on the board
IO_L8_P_13: J25002.58; also elsewhere on the board
IO_L9_DQS_N_13: J25002.48; also elsewhere on the board
IO_L9_DQS_P_13: J25002.50; also elsewhere on the board
IO_L10_N_13: J25002.51; also elsewhere on the board
IO_L10_P_13: J25002.53; also elsewhere on the board
IO_L15_P_13: J25002.9; also elsewhere on the board
IO_L19_P_13: J25002.12; also elsewhere on the board
IO_L21_P_13: J25002.13; also elsewhere on the board
IO_L22_P_13: J25002.19; also elsewhere on the board
IO_L24_N_13: J25002.7; also elsewhere on the board
IO_L24_P_13: J25002.10; also elsewhere on the board
LCD_CTP_INT: J25002.32; also elsewhere on the board
LCD_CTP_RST: J25002.34; also elsewhere on the board
LCD_CTP_SCL: J25002.28; also elsewhere on the board
LCD_CTP_SDA: J25002.30; also elsewhere on the board
PL_BTN0: J25002.79; also elsewhere on the board
PL_BTN1: J25002.87; also elsewhere on the board
PMODX_IO1: J25002.29; also elsewhere on the board
PMODX_IO2: J25002.27; also elsewhere on the board
PMODX_IO3: J25002.33; also elsewhere on the board
PMODX_IO4: J25002.31; also elsewhere on the board
PMODX_IO5: J25002.41; also elsewhere on the board
PMODX_IO6: J25002.39; also elsewhere on the board
PMODX_IO7: J25002.49; also elsewhere on the board
PMODX_IO8: J25002.47; also elsewhere on the board
SD_CARD_DETECT: J25002.17; also elsewhere on the board
ZYNQ_HDMI_TX_CEC: J25002.77; also elsewhere on the board
ZYNQ_HDMI_TX_HPD: J25002.54; also elsewhere on the board
ZYNQ_HDMI_TX_SCL: J25002.22; also elsewhere on the board
ZYNQ_HDMI_TX_SDA: J25002.52; also elsewhere on the board
ZYNQ_HDMI_TX_TMDS_0_N: J25002.69; also elsewhere on the board
ZYNQ_HDMI_TX_TMDS_0_P: J25002.67; also elsewhere on the board
ZYNQ_HDMI_TX_TMDS_1_N: J25002.68; also elsewhere on the board
ZYNQ_HDMI_TX_TMDS_1_P: J25002.70; also elsewhere on the board
ZYNQ_HDMI_TX_TMDS_2_N: J25002.74; also elsewhere on the board
ZYNQ_HDMI_TX_TMDS_2_P: J25002.72; also elsewhere on the board
ZYNQ_HDMI_TX_TMDS_CLK_N: J25002.73; also elsewhere on the board
ZYNQ_HDMI_TX_TMDS_CLK_P: J25002.71; also elsewhere on the board
ZYNQ_PS_UART0_CTS_N: J25002.11; also elsewhere on the board
ZYNQ_PS_UART0_RTS_N: J25002.8; also elsewhere on the board

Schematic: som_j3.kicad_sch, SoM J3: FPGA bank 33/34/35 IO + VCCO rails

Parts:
J26003: DF40C-100DP-0.4V(51); DF40C-100DP-0.4V_51; LCSC C531031

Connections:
+2V5_VADJ: J26003.1, J26003.2, J26003.4; also elsewhere on the board
+3V3: J26003.97, J26003.99; also elsewhere on the board
CAM_CLK_N: J26003.11; also elsewhere on the board
CAM_CLK_P: J26003.9; also elsewhere on the board
CAM_D0_N: J26003.7; also elsewhere on the board
CAM_D0_P: J26003.5; also elsewhere on the board
CAM_D1_N: J26003.15; also elsewhere on the board
CAM_D1_P: J26003.17; also elsewhere on the board
CAM_EN: J26003.85; also elsewhere on the board
CAM_LED: J26003.87; also elsewhere on the board
CAM_SCL: J26003.86; also elsewhere on the board
CAM_SDA: J26003.89; also elsewhere on the board
ESC_PWM_IN4: J26003.91; also elsewhere on the board
ESC_PWM_IN5: J26003.93; also elsewhere on the board
ESC_PWM_IN6: J26003.92; also elsewhere on the board
ESC_PWM_IN7: J26003.94; also elsewhere on the board
FMC_CLK0_M2C_N: J26003.16; also elsewhere on the board
FMC_CLK0_M2C_P: J26003.14; also elsewhere on the board
FMC_CLK1_M2C_N: J26003.10; also elsewhere on the board
FMC_CLK1_M2C_P: J26003.8; also elsewhere on the board
FMC_LA00_CC_N: J26003.20; also elsewhere on the board
FMC_LA00_CC_P: J26003.22; also elsewhere on the board
FMC_LA01_CC_N: J26003.26; also elsewhere on the board
FMC_LA01_CC_P: J26003.24; also elsewhere on the board
FMC_LA02_N: J26003.35; also elsewhere on the board
FMC_LA02_P: J26003.37; also elsewhere on the board
FMC_LA03_N: J26003.32; also elsewhere on the board
FMC_LA03_P: J26003.34; also elsewhere on the board
FMC_LA04_N: J26003.44; also elsewhere on the board
FMC_LA04_P: J26003.42; also elsewhere on the board
FMC_LA05_N: J26003.45; also elsewhere on the board
FMC_LA05_P: J26003.47; also elsewhere on the board
FMC_LA06_N: J26003.49; also elsewhere on the board
FMC_LA06_P: J26003.51; also elsewhere on the board
FMC_LA07_N: J26003.52; also elsewhere on the board
FMC_LA07_P: J26003.50; also elsewhere on the board
GND: J26003.3, J26003.6, J26003.12, J26003.13, J26003.18, J26003.23, J26003.28, J26003.33, J26003.38, J26003.43, J26003.48, J26003.53, J26003.58, J26003.63, J26003.68, J26003.73, J26003.80, J26003.83, J26003.90, J26003.95, J26003.100; also elsewhere on the board
IO_L16_N_35: J26003.29
IO_L16_P_35: J26003.31
IO_L18_N_35: J26003.25
IO_L18_P_35: J26003.27
IO_L22_N_34: J26003.84
IO_L23_P_34: J26003.88
IO_L24_P_34: J26003.82
LCD_B0: J26003.65; also elsewhere on the board
LCD_B1: J26003.66; also elsewhere on the board
LCD_B2: J26003.67; also elsewhere on the board
LCD_B3: J26003.69; also elsewhere on the board
LCD_B4: J26003.70; also elsewhere on the board
LCD_B5: J26003.71; also elsewhere on the board
LCD_B6: J26003.72; also elsewhere on the board
LCD_B7: J26003.74; also elsewhere on the board
LCD_BL_PWM: J26003.81; also elsewhere on the board
LCD_DE: J26003.78; also elsewhere on the board
LCD_DISP: J26003.79; also elsewhere on the board
LCD_G0: J26003.55; also elsewhere on the board
LCD_G1: J26003.56; also elsewhere on the board
LCD_G2: J26003.57; also elsewhere on the board
LCD_G3: J26003.59; also elsewhere on the board
LCD_G4: J26003.60; also elsewhere on the board
LCD_G5: J26003.61; also elsewhere on the board
LCD_G6: J26003.62; also elsewhere on the board
LCD_G7: J26003.64; also elsewhere on the board
LCD_HSYNC: J26003.76; also elsewhere on the board
LCD_PCLK: J26003.75; also elsewhere on the board
LCD_R0: J26003.19; also elsewhere on the board
LCD_R1: J26003.21; also elsewhere on the board
LCD_R2: J26003.30; also elsewhere on the board
LCD_R3: J26003.36; also elsewhere on the board
LCD_R4: J26003.40; also elsewhere on the board
LCD_R5: J26003.41; also elsewhere on the board
LCD_R6: J26003.46; also elsewhere on the board
LCD_R7: J26003.54; also elsewhere on the board
LCD_VSYNC: J26003.77; also elsewhere on the board
PUDC_34: J26003.39; also elsewhere on the board
WATCHDOG_KICK: J26003.96; also elsewhere on the board
WATCHDOG_RST_N: J26003.98; also elsewhere on the board

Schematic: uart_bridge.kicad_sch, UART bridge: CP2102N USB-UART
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

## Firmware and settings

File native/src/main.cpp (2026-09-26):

#include "schgen/catalog.hpp"
#include "schgen/circuit.hpp"
#include "schgen/legalize.hpp"
#include "schgen/occupancy.hpp"
#include "schgen/quantize.hpp"
#include "schgen/seat.hpp"
#include "schgen/sexpr.hpp"
#include "schgen/turn.hpp"
#include "schgen/project_cli.hpp"
#include "schgen/regression_cli.hpp"
#include "schgen/geometry_cli.hpp"
#include "schgen/part_import.hpp"
#include "schgen/selftest_full.hpp"

#include <iostream>
#include <stdexcept>
#include <string>

int main(int argc, char** argv) {
    try {
        if (argc == 1 || (argc == 2 && std::string(argv[1]) == "--help")) {
            std::cout << "usage: schgen <command>\n"
                         "  self-check\n"
                         "  check --tests-dir BUILD [--repo ROOT] [--project NAME_OR_PATH] [-o DIRECTORY]\n"
                         "  floorplan [--project NAME] [--export] [-o DIRECTORY]\n"
                         "  compose [--project NAME] [--measure | --repair [--dry-run]] [--allow-intent NAME:FROM->TO]\n"
                         "  selftest [--project NAME] [SUBSYSTEM ...] [--kicad-cli PATH] [-o REPORT]\n"
                         "  catalog-compile <parts_dir> <catalog.bin>\n"
                         "  circuit-compile <circuits_dir> <circuits.bin>\n"
                         "  project-check [--repo ROOT] [--project NAME] [SUBSYSTEM ...]\n"
                         "  circuit-check [--repo ROOT] [--project NAME] [SUBSYSTEM ...]\n"
                         "  board-schematic [--project NAME] [SUBSYSTEM ...] -o DIRECTORY\n"
                         "  build NAME [--project NAME] [-o DIRECTORY] [--no-render]\n"
                         "  devkit --output DIRECTORY [--repo ROOT] [--no-render] (four-sheet example)\n"
                         "  dump-circuits [--project NAME] (publish live native-authored IR)\n"
                         "  nets [--project NAME] --output HEADER (C++ net-name contract)\n"
                         "  subsystem-check | carrier-check [--project NAME] (strict native package gates)\n"
                         "  chir-rung TAG | w11-sweep MM [SHEET ...] [--project NAME] (writes board; restores inputs)\n"
                         "  w12-bound TAG | w12-stageprobe TAG [SHEET ...] [--project NAME] [--cons-only] (private probes)\n"
                         "  pcb-stage [--project NAME] [--kicad-cli PATH] -o DIRECTORY (construction only)\n"
                         "  pcb-drc [--project NAME] [--pcb FILE] [-o REPORT]\n"
                         "  subsystem-new NAME [--repo DIRECTORY] (new C++ package; never overwrites)\n"
                         "  part-import --parts-root DIRECTORY (--from-json FILE | --lcsc ID) [--name NAME] [--overwrite] [--catalog FILE]\n"
                         "  render3d | model3d-check [--project NAME] [-o DIRECTORY]\n"
                         "  board-step [--project NAME] [--pcb FILE] --output FILE\n"
                         "  assembly | ratsnest | si-constraints [--project NAME] [-o DIRECTORY]\n"
                         "  fab-profile [--project NAME] [-o REPORT_DIRECTORY]\n"
                         "  manifest [--project NAME] [SUBSYSTEM ...] [-o FILE]\n"
                         "  gallery [--project NAME]\n"
                         "  diagram [--project NAME] [SUBSYSTEM ...] [-o FILE]\n"
                         "  preflight [--project NAME] [SUBSYSTEM ...] [--qty N] [--min-stock N] [--allow-missing]\n"
                         "  constraints [--project NAME] [SUBSYSTEM ...] [-o DIRECTORY]\n"
                         "  bom-values | footprint-pads | pin-completeness | symbol-law [--project NAME] [-o FILE]\n"
                         "  spice [--project NAME] [SUBSYSTEM ...] [--no-ngspice] [-o FILE]\n"
                         "  firmware | manual | testplan | power-sequence [--project NAME] [-o FILE]\n"
                         "  scfw [--project NAME] [-o DIRECTORY]\n"
                         "  powertree|part-rules [--project NAME] [SUBSYSTEM ...] [-o REPORT]\n"
                         "  thermal [--project NAME] [SUBSYSTEM ...] [--pcb FILE] [-o REPORT]\n"
                         "  design-rules|testpoints [--project NAME] [SUBSYSTEM ...] [-o REPORT]\n"
                         "  som-interface [--project NAME] [--som FILE] [--refs J1,J2,J3] [-o FILE]\n"
                         "  xdc|vivado [--project NAME] [--som FILE] [--contract FILE] [-o FILE]\n"
                         "  fpga [--project NAME] [-o DIRECTORY]  (XDC + Vivado, one live extraction)\n"
                         "  bom [--project NAME] [SUBSYSTEM ...] [-o FILE] [--allow-missing] [--qualified-refs]\n"
                         "  link [--project NAME] [SUBSYSTEM ...] [--contract FILE] [-o REPORT]\n"
                         "  devicetree [--project NAME] [--som FILE] [--contract FILE] [-o FILE]\n"
                         "  board [--project NAME] [-o DIRECTORY] [--no-render] [--timing] (native; incomplete audit integration fails explicitly)\n";
            return 0;
        }
        if (argc >= 2 && std::string(argv[1]) == "selftest-worker") {
            if (argc != 4) throw std::runtime_error("selftest-worker requires request and output paths");
            std::cout << schgen::selftest_worker_emit(schgen::parse_json_file(argv[2]), argv[3]);
            return 0;
        }
        if (const auto status = schgen::run_part_import_command(argc, argv)) return *status;
        if (const auto status = schgen::run_regression_command(argc, argv)) return *status;
        if (const auto status = schgen::run_geometry_command(argc, argv)) return *status;
        if (const auto status = schgen::run_project_command(argc, argv)) return *status;
        if (argc >= 2 && std::string(argv[1]) == "catalog-compile") {
            if (argc != 4) {
                throw std::runtime_error(
                    "usage: schgen catalog-compile <parts_dir> <catalog.bin>");
            }
            if (!schgen::compile_part_catalog(argv[2], argv[3])) {
                throw std::runtime_error("catalog-compile returned false");
            }
            std::cout << "catalog compiled " << argv[3] << "\n";
            return 0;
        }
        if (argc >= 2 && std::string(argv[1]) == "circuit-compile") {
            if (argc != 4) {
                throw std::runtime_error(
                    "usage: schgen circuit-compile <circuits_dir> <circuits.bin>");
            }
            if (!schgen::compile_circuit_catalog(argv[2], argv[3])) {
                throw std::runtime_error("circuit-compile returned false");
            }
            std::cout << "circuits compiled " << argv[3] << "\n";
            return 0;
        }
        if (argc != 2 || std::string(argv[1]) != "self-check") {
            throw std::runtime_error("unsupported command or arguments; use --help");
        }
        const schgen::Box4 a{0.0, 0.0, 10.0, 8.0};
        const schgen::Box4 b{12.0, 0.0, 16.0, 8.0};
        if (schgen::boxes_overlap(a, b, 0.3)) {
            throw std::runtime_error("schgen: separated boxes reported overlap");
        }
        if (!schgen::spot_free(a, 0.25, {b}, {}, {})) {
            throw std::runtime_error("schgen: spot_free rejected a free site");
        }
        schgen::Occupancy occ(160.0, 140.0, 0.3, 20.0, 3.32, 1.0, 0.05);
        occ.add(55.0, 45.0, 50.0, 50.0, {}, {}, 3, {});
        if (!occ.fits_hashed(10.0, 10.0, 16.0, 10.0, {}, {}, 3, {})) {
            throw std::runtime_error("schgen: occupancy rejected a free pose");
        }
        const auto turned = schgen::turn_box({1.0, -2.0, 9.0, 2.0}, 90.0);
        if (turned.x0 != -2.0 || turned.y0 != -9.0 || turned.x1 != 2.0
            || turned.y1 != -1.0) {
            throw std::runtime_error("schgen: turn_box missed a quarter turn");
        }
        if (schgen::outline_snap_up(161.0001) != 165.0) {
            throw std::runtime_error("schgen: outline_snap_up missed the 5 mm grid");
        }
        const auto axis = schgen::pair_axis(a, b);
        if (!axis.axis_x || !axis.a_first) {
            throw std::runtime_error("schgen: pair_axis flipped a separated pair");
        }
        const auto bf = schgen::bellman_ford(2, {0}, {1}, {1.0});
        if (!bf.feasible || bf.dist.size() != 2) {
            throw std::runtime_error("schgen: bellman_ford rejected a free edge");
        }
        const auto dfs = schgen::seat_dfs({{a}, {b}}, {}, 0.3, 1000);
        if (!dfs.solved || dfs.pick.size() != 2) {
            throw std::runtime_error("schgen: seat_dfs failed a free pair");
        }
        const std::string dumped = schgen::sexpr_dumps(
            schgen::sexpr_loads("(kicad_pcb (version 20241229))"));
        if (dumped.find("kicad_pcb") == std::string::npos) {
            throw std::runtime_error("schgen: sexpr roundtrip dropped the tag");
        }
        if (!schgen::cross_edge_fanout_hold(
                {{0.0, 10.0, 20.0, 8.0, {}, {}, 'N'},
                 {40.0, 10.0, 20.0, 8.0, {}, {}, 'S'}},
                0.3)) {
            throw std::runtime_error("schgen: cross_edge_fanout_hold rejected a free pair");
        }
        if (schgen::rects_overlap_any({{0.0, 0.0, 10.0, 8.0}},
                                      {{12.0, 0.0, 16.0, 8.0}}, 1e-6)) {
            throw std::runtime_error("schgen: rects_overlap_any flagged a gap");
        }
        std::cout << "schgen native occupancy+seat+route+sexpr+emit"
                  << " — kernel self-check ok\n";
        return 0;
    } catch (const std::exception& exc) {
        std::cerr << "schgen: " << exc.what() << "\n";
        return 1;
    }
}

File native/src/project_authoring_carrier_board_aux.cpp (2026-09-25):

#include "schgen/subsystem_authoring.hpp"

namespace schgen::project_builders {
// Migrated construction operations from carrier/subsystems/board_aux/board_aux.py.
CircuitSheetIr carrier_board_aux(const SubsystemMeta& meta, const AuthoringContext& context) {
    CircuitAuthor c("board_aux", "Board services: gated +3V3_AUX rail + PCA9306 I2C isolator", context);
    {
        AuthoringPartSelection p;
        p.ref = "U1";
        c.use_part("SY6280AAC", p);
    }
    c.net("+3V3", {"U1.IN"}, std::nullopt);
    c.net("+3V3_AUX", {"U1.OUT"}, std::nullopt);
    c.net("GND", {"U1.GND"}, std::nullopt);
    c.net("EN_AUX", {"U1.EN"}, std::nullopt);
    c.auto_ref("R");
    c.part("R1", "Device:R", "13k", "Resistor_SMD:R_0603_1608Metric", {{"LCSC", "C22797"}});
    c.net("BS_ISET_AUX", {"U1.ISET", "R1.1"}, std::nullopt);
    c.net("GND", {"R1.2"}, std::nullopt);
    c.decouple("U1.IN", {"100n"}, std::nullopt, "GND", "Device:C", "Capacitor_SMD:C_0603_1608Metric");
    c.decouple("U1.OUT", {"100n"}, std::nullopt, "GND", "Device:C", "Capacitor_SMD:C_0603_1608Metric");
    c.auto_ref("C");
    c.part("C3", "Device:C", "10u", "Capacitor_SMD:C_0805_2012Metric", {{"LCSC", "C15850"}});
    c.net("+3V3_AUX", {"C3.1"}, std::nullopt);
    c.net("GND", {"C3.2"}, std::nullopt);
    {
        AuthoringPartSelection p;
        p.ref = "SW1";
        c.use_part("DSHP04TSGER", p);
    }
    c.net("+3V3", {"SW1.1", "SW1.3", "SW1.5", "SW1.7"}, std::nullopt);
    c.net("EN_AUX", {"SW1.8"}, std::nullopt);
    c.auto_ref("R");
    c.part("R2", "Device:R", "100k", "Resistor_SMD:R_0603_1608Metric", {{"LCSC", "C25803"}});
    c.net("EN_AUX", {"R2.1"}, std::nullopt);
    c.net("GND", {"R2.2"}, std::nullopt);
    c.nc({"SW1.2", "SW1.4", "SW1.6"});
    c.auto_ref("D");
    c.part("D1", "Device:LED", "red", "LED_SMD:LED_0603_1608Metric", {{"LCSC", "C2286"}});
    c.auto_ref("R");
    c.part("R3", "Device:R", "330R", "Resistor_SMD:R_0603_1608Metric", {{"LCSC", "C23138"}});
    c.net("+3V3_AUX", {"D1.2"}, std::nullopt);
    c.net("BS_PG_AUX", {"D1.1", "R3.1"}, std::nullopt);
    c.net("GND", {"R3.2"}, std::nullopt);
    {
        AuthoringPartSelection p;
        p.ref = "U2";
        c.use_part("PCA9306DCUR", p);
    }
    c.net("GND", {"U2.GND"}, std::nullopt);
    c.net("+3V3_SC", {"U2.VREF1"}, std::nullopt);
    c.decouple("U2.VREF1", {"100n"}, std::nullopt, "GND", "Device:C", "Capacitor_SMD:C_0603_1608Metric");
    {
        AuthoringPort t;
        t.kind = "i2c";
        t.role = "scl";
        t.bus = "STM32_I2C2";
        t.speed_hz = 400000;
        t.expect = "STM32_I2C2 management bus (bringup_rails / usb_pd / power_mon)";
        c.port("STM32_I2C2_SCL", {"U2.SCL1"}, t, true);
    }
    {
        AuthoringPort t;
        t.kind = "i2c";
        t.role = "sda";
        t.bus = "STM32_I2C2";
        t.speed_hz = 400000;
        t.expect = "STM32_I2C2 management bus (bringup_rails / usb_pd / power_mon)";
        c.port("STM32_I2C2_SDA", {"U2.SDA1"}, t, true);
    }
    c.net("+3V3_AUX", {"U2.VREF2"}, std::nullopt);
    {
        AuthoringPort t;
        t.kind = "i2c";
        t.role = "scl";
        t.bus = "AUX_I2C";
        t.speed_hz = 400000;
        t.expect = "board_services (the gated peripherals on the isolated AUX bus)";
        c.port("AUX_I2C_SCL", {"U2.SCL2"}, t, true);
    }
    {
        AuthoringPort t;
        t.kind = "i2c";
        t.role = "sda";
        t.bus = "AUX_I2C";
        t.speed_hz = 400000;
        t.expect = "board_services (the gated peripherals on the isolated AUX bus)";
        c.port("AUX_I2C_SDA", {"U2.SDA2"}, t, true);
    }
    c.net("AUX_ISO_EN", {"U2.EN"}, std::nullopt);
    c.pullup("U2.EN", "100k", "+3V3_AUX", "Device:R", "Resistor_SMD:R_0603_1608Metric");
    c.pullup("U2.SCL2", "4k7", "+3V3_AUX", "Device:R", "Resistor_SMD:R_0603_1608Metric");
    c.pullup("U2.SDA2", "4k7", "+3V3_AUX", "Device:R", "Resistor_SMD:R_0603_1608Metric");
    c.decouple("U2.VREF2", {"100n"}, std::nullopt, "GND", "Device:C", "Capacitor_SMD:C_0603_1608Metric");
    c.draws("+3V3_AUX", 0.006, "status LED 3.9mA + 2x4k7 AUX-bus pull-ups");
    c.testpoint("+3V3_AUX", std::nullopt);
    c.testpoint("AUX_I2C_SCL", std::nullopt);
    c.testpoint("AUX_I2C_SDA", std::nullopt);
    c.field("C1", "LCSC", "C14663");
    c.field("C2", "LCSC", "C14663");
    c.field("C4", "LCSC", "C14663");
    c.field("R4", "LCSC", "C25803");
    c.field("R5", "LCSC", "C23162");
    c.field("R6", "LCSC", "C23162");
    c.field("C5", "LCSC", "C14663");
    return meta.finish(c);
}
} // namespace schgen::project_builders

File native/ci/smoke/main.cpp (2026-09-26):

// Bootstrap/CLI smoke checks are native executables, not Python/shell programs.
#include "schgen/process.hpp"
#include <array>
#include <fstream>
#include <iostream>
#include <map>
#include <sstream>
#include <unistd.h>

namespace fs=std::filesystem;
namespace {
void require(bool condition,const std::string& message) {
    if (!condition) throw std::runtime_error(message);
}
std::string read(const fs::path& path) {
    std::ifstream stream(path,std::ios::binary);
    require(bool(stream),"cannot read "+path.string());
    const std::string bytes{std::istreambuf_iterator<char>(stream),{}};
    require(!stream.bad(),"failed reading "+path.string()); return bytes;
}
bool native_magic(const std::string& bytes) {
    if (bytes.size()<4) return false;
    const std::array<unsigned char,4> magic{
        static_cast<unsigned char>(bytes[0]),static_cast<unsigned char>(bytes[1]),
        static_cast<unsigned char>(bytes[2]),static_cast<unsigned char>(bytes[3])};
    // ELF and both byte orders of 32/64-bit Mach-O/universal Mach-O.
    for (const auto& allowed:std::array<std::array<unsigned char,4>,7>{{
        {{0x7f,'E','L','F'}},{{0xfe,0xed,0xfa,0xce}},{{0xce,0xfa,0xed,0xfe}},
        {{0xfe,0xed,0xfa,0xcf}},{{0xcf,0xfa,0xed,0xfe}},
        {{0xca,0xfe,0xba,0xbe}},{{0xca,0xfe,0xba,0xbf}}}})
        if (magic==allowed) return true;
    return false;
}
void check_cache(const std::string& bytes) {
    std::map<std::string,std::string> values; std::istringstream lines(bytes);
    std::string line;
    while (std::getline(lines,line)) {
        if (!line.empty()&&line.back()=='\r') line.pop_back();
        if (line.empty()||line.front()=='#'||line.rfind("//",0)==0) continue;
        const auto colon=line.find(':'),equal=line.find('=');
        if (colon==line.npos||equal==line.npos||colon>equal) continue;
        const auto key=line.substr(0,colon),value=line.substr(equal+1);
        require(values.emplace(key,value).second,"duplicate CMake cache entry: "+key);
        for (const std::string prefix:{"Python_","Python3_","PYTHON_","_Python","nanobind","NANOBIND"})
            require(key.rfind(prefix,0)!=0,"Python/nanobind discovery present in native CI cache: "+key);
    }
    require(values.count("SCHGEN_BUILD_PYTHON")&&values.at("SCHGEN_BUILD_PYTHON")=="OFF",
            "native CI requires explicit SCHGEN_BUILD_PYTHON=OFF");
    require(values.count("BUILD_TESTING")&&values.at("BUILD_TESTING")=="ON",
            "native CI requires BUILD_TESTING=ON");
}
struct Scratch {
    fs::path path;
    Scratch() {
        auto pattern=(fs::temp_directory_path()/"schgen-ci-smoke-XXXXXX").string();
        require(::mkdtemp(pattern.data())!=nullptr,"cannot create private CI smoke directory"); path=pattern;
    }
    ~Scratch() { std::error_code error; fs::remove_all(path,error); }
};
std::string success(const std::vector<std::string>& args) {
    const auto result=schgen::run_process(args,std::chrono::minutes(2));
    require(result.exit_code==0,"native smoke command failed: "+args.front()+"\n"+result.stdout_text+result.stderr_text);
    return result.stdout_text;
}
void check_cli(const fs::path& executable,const fs::path& repo) {
    require(native_magic(read(executable)),"schgen must be a native Mach-O/ELF executable, not a script");
    require(success({executable.string(),"self-check"}).find("self-check ok")!=std::string::npos,
            "CLI self-check did not report actual kernel checks");
    require(success({executable.string(),"--help"}).find("catalog-compile")!=std::string::npos,
            "CLI command surface missing catalog compiler");
    const auto missing=schgen::run_process({executable.string(),"catalog-compile"});
    require(missing.exit_code!=0&&missing.stderr_text.find("usage:")!=std::string::npos,
            "invalid catalog invocation must fail with its diagnostic");
    Scratch scratch;
    for (const auto& kind:{std::string("catalog"),std::string("circuit")}) {
        const auto source=kind=="catalog"?repo/"parts":repo/"carrier/subsystems";
        const auto a=scratch.path/(kind+"-a.bin"),b=scratch.path/(kind+"-b.bin");
        success({executable.string(),kind+"-compile",source.string(),a.string()});
        success({executable.string(),kind+"-compile",source.string(),b.string()});
        require(!read(a).empty()&&read(a)==read(b),kind+" compilation is empty or nondeterministic");
    }
}
void check_environment(const fs::path& cli,const std::string& version,
                       const fs::path& footprints,const fs::path& symbols,const fs::path& models) {
    auto actual=success({cli.string(),"version"});
    while (!actual.empty()&&(actual.back()=='\n'||actual.back()=='\r')) actual.pop_back();
    require(actual==version,"KiCad version mismatch: expected "+version+", observed "+actual);
    for (const auto& path:{footprints/"Resistor_SMD.pretty/R_0603_1608Metric.kicad_mod",
                          symbols/"Device.kicad_sym",
                          models/"Resistor_SMD.3dshapes/R_0603_1608Metric.step"})
        require(fs::is_regular_file(path)&&fs::file_size(path)>0,"required installed KiCad library asset missing: "+path.string());
    std::cout<<"KiCad "<<actual<<" and native library prerequisites present\n";
}
void contracts(const fs::path& self) {
    const std::string good="// native-only\nSCHGEN_BUILD_PYTHON:BOOL=OFF\nBUILD_TESTING:BOOL=ON\n";
    check_cache(good);
    std::size_t rejected=0;
    for (const auto& bad:{std::string{},std::string("SCHGEN_BUILD_PYTHON:BOOL=ON\nBUILD_TESTING:BOOL=ON\n"),
        std::string("SCHGEN_BUILD_PYTHON:BOOL=OFF\nBUILD_TESTING:BOOL=OFF\n"),
        good+"Python_EXECUTABLE:FILEPATH=/python\n",good+"nanobind_DIR:PATH=/nanobind\n",
        good+"SCHGEN_BUILD_PYTHON:BOOL=OFF\n"}) {
        try { check_cache(bad); } catch (const std::runtime_error&) { ++rejected; }
    }
    require(rejected==6,"cache mutation checks failed to reject a poisoned configuration");
    require(!native_magic("#!/usr/bin/python3\n")&&!native_magic(""),"script/truncated executable accepted");
    require(native_magic(read(self)),"current smoke executable is not native");
    std::cout<<"10 native bootstrap contracts passed\n";
}
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

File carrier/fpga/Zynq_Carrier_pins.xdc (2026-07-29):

##############################################################################
# Zynq_Carrier_pins.xdc — GENERATED by `schgen xdc`. DO NOT EDIT.
# Device: XC7Z020-CLG484 (U2 on the SoM)
# Sources (all programmatic, zero hand-typed pins):
#   ball map : som/Zynq_SoM.kicad_sch netlist (kicad-cli, at generation time)
#   contract : carrier/som_interface.json (cross-checked pin-for-pin, stale = build FAIL)
#   types    : carrier subsystems' typed-port registry
# VCCO rail map (project fpga.bank_rails): bank 13 = +3V3, bank 33 = +3V3, bank 34 = +3V3, bank 35 = +2V5_VADJ
# 156 pins, banks 13/33/34/35, 30 clock-capable (MRCC/SRCC)
# Ports named IO_* are the bound SoM contract nets not yet claimed
# by a function sheet; the wave-3 function map renames them here
# automatically on the next `schgen board`.
##############################################################################

# ---- bank 13 — VCCO = +3V3 (43 pins) --------------------
set_property -dict {PACKAGE_PIN AA9  IOSTANDARD LVCMOS33} [get_ports {DBG_UART_RXD}]  ;# J2.42 IO_L11P_T1_SRCC_13 <- usb_jtag
#   ^ SRCC-capable: # create_clock -name DBG_UART_RXD -period <ns> [get_ports {DBG_UART_RXD}]
set_property -dict {PACKAGE_PIN AA8  IOSTANDARD LVCMOS33} [get_ports {DBG_UART_TXD}]  ;# J2.40 IO_L11N_T1_SRCC_13 <- usb_jtag
set_property -dict {PACKAGE_PIN V10  IOSTANDARD LVCMOS33} [get_ports {ESC_BUF_OE_N}]  ;# J2.57 IO_L1P_T0_13 <- motor_pwm
set_property -dict {PACKAGE_PIN V9   IOSTANDARD LVCMOS33} [get_ports {ESC_FAULT_N}]  ;# J2.37 IO_L1N_T0_13 <- motor_sense
set_property -dict {PACKAGE_PIN U7   IOSTANDARD LVCMOS33} [get_ports {IO_25_13}]  ;# J2.23 IO_25_13 <- user_io
set_property -dict {PACKAGE_PIN Y10  IOSTANDARD LVCMOS33} [get_ports {IO_L10_N_13}]  ;# J2.51 IO_L10N_T1_13 <- pmod
set_property -dict {PACKAGE_PIN Y11  IOSTANDARD LVCMOS33} [get_ports {IO_L10_P_13}]  ;# J2.53 IO_L10P_T1_13 <- pmod
set_property -dict {PACKAGE_PIN AB2  IOSTANDARD LVCMOS33} [get_ports {IO_L15_P_13}]  ;# J2.9 IO_L15P_T2_DQS_13 <- user_io
set_property -dict {PACKAGE_PIN R6   IOSTANDARD LVCMOS33} [get_ports {IO_L19_P_13}]  ;# J2.12 IO_L19P_T3_13 <- user_io
set_property -dict {PACKAGE_PIN V5   IOSTANDARD LVCMOS33} [get_ports {IO_L21_P_13}]  ;# J2.13 IO_L21P_T3_DQS_13 <- user_io
set_property -dict {PACKAGE_PIN U6   IOSTANDARD LVCMOS33} [get_ports {IO_L22_P_13}]  ;# J2.19 IO_L22P_T3_13 <- user_io
set_property -dict {PACKAGE_PIN W5   IOSTANDARD LVCMOS33} [get_ports {IO_L24_N_13}]  ;# J2.7 IO_L24N_T3_13 <- user_io
set_property -dict {PACKAGE_PIN W6   IOSTANDARD LVCMOS33} [get_ports {IO_L24_P_13}]  ;# J2.10 IO_L24P_T3_13 <- user_io
set_property -dict {PACKAGE_PIN W8   IOSTANDARD LVCMOS33} [get_ports {IO_L2_N_13}]  ;# J2.14 IO_L2N_T0_13 <- pmod
set_property -dict {PACKAGE_PIN V8   IOSTANDARD LVCMOS33} [get_ports {IO_L2_P_13}]  ;# J2.20 IO_L2P_T0_13 <- pmod
set_property -dict {PACKAGE_PIN W10  IOSTANDARD LVCMOS33} [get_ports {IO_L3_N_13}]  ;# J2.43 IO_L3N_T0_DQS_13 <- pmod
set_property -dict {PACKAGE_PIN W11  IOSTANDARD LVCMOS33} [get_ports {IO_L3_P_13}]  ;# J2.18 IO_L3P_T0_DQS_13 <- pmod
set_property -dict {PACKAGE_PIN W12  IOSTANDARD LVCMOS33} [get_ports {IO_L4_N_13}]  ;# J2.63 IO_L4N_T0_13 <- pmod
set_property -dict {PACKAGE_PIN V12  IOSTANDARD LVCMOS33} [get_ports {IO_L4_P_13}]  ;# J2.61 IO_L4P_T0_13 <- pmod
set_property -dict {PACKAGE_PIN U12  IOSTANDARD LVCMOS33} [get_ports {IO_L5P_13}]  ;# J2.38 IO_L5P_T0_13 <- pmod
set_property -dict {PACKAGE_PIN U11  IOSTANDARD LVCMOS33} [get_ports {IO_L5_N_13}]  ;# J2.24 IO_L5N_T0_13 <- pmod
set_property -dict {PACKAGE_PIN U10  IOSTANDARD LVCMOS33} [get_ports {IO_L6_P_13}]  ;# J2.21 IO_L6P_T0_13 <- user_io
set_property -dict {PACKAGE_PIN AB12 IOSTANDARD LVCMOS33} [get_ports {IO_L7_N_13}]  ;# J2.64 IO_L7N_T1_13 <- pmod
set_property -dict {PACKAGE_PIN AA12 IOSTANDARD LVCMOS33} [get_ports {IO_L7_P_13}]  ;# J2.62 IO_L7P_T1_13 <- pmod
set_property -dict {PACKAGE_PIN AB11 IOSTANDARD LVCMOS33} [get_ports {IO_L8_N_13}]  ;# J2.60 IO_L8N_T1_13 <- pmod
set_property -dict {PACKAGE_PIN AA11 IOSTANDARD LVCMOS33} [get_ports {IO_L8_P_13}]  ;# J2.58 IO_L8P_T1_13 <- pmod
set_property -dict {PACKAGE_PIN AB9  IOSTANDARD LVCMOS33} [get_ports {IO_L9_DQS_N_13}]  ;# J2.48 IO_L9N_T1_DQS_13 <- pmod
set_property -dict {PACKAGE_PIN AB10 IOSTANDARD LVCMOS33} [get_ports {IO_L9_DQS_P_13}]  ;# J2.50 IO_L9P_T1_DQS_13 <- pmod
set_property -dict {PACKAGE_PIN AB6  IOSTANDARD LVCMOS33} [get_ports {LCD_CTP_INT}]  ;# J2.32 IO_L17N_T2_13 <- lcd
set_property -dict {PACKAGE_PIN AB7  IOSTANDARD LVCMOS33} [get_ports {LCD_CTP_RST}]  ;# J2.34 IO_L17P_T2_13 <- lcd
set_property -dict {PACKAGE_PIN AB4  IOSTANDARD LVCMOS33} [get_ports {LCD_CTP_SCL}]  ;# J2.28 IO_L16N_T2_13 <- lcd
set_property -dict {PACKAGE_PIN AB5  IOSTANDARD LVCMOS33} [get_ports {LCD_CTP_SDA}]  ;# J2.30 IO_L16P_T2_13 <- lcd
set_property -dict {PACKAGE_PIN Y6   IOSTANDARD LVCMOS33} [get_ports {PMODX_IO1}]  ;# J2.29 IO_L13P_T2_MRCC_13 <- pmod_expansion
#   ^ MRCC-capable: # create_clock -name PMODX_IO1 -period <ns> [get_ports {PMODX_IO1}]
set_property -dict {PACKAGE_PIN Y5   IOSTANDARD LVCMOS33} [get_ports {PMODX_IO2}]  ;# J2.27 IO_L13N_T2_MRCC_13 <- pmod_expansion
set_property -dict {PACKAGE_PIN V7   IOSTANDARD LVCMOS33} [get_ports {PMODX_IO3}]  ;# J2.33 IO_L23P_T3_13 <- pmod_expansion
set_property -dict {PACKAGE_PIN W7   IOSTANDARD LVCMOS33} [get_ports {PMODX_IO4}]  ;# J2.31 IO_L23N_T3_13 <- pmod_expansion
set_property -dict {PACKAGE_PIN AA7  IOSTANDARD LVCMOS33} [get_ports {PMODX_IO5}]  ;# J2.41 IO_L14P_T2_SRCC_13 <- pmod_expansion
#   ^ SRCC-capable: # create_clock -name PMODX_IO5 -period <ns> [get_ports {PMODX_IO5}]
set_property -dict {PACKAGE_PIN AA6  IOSTANDARD LVCMOS33} [get_ports {PMODX_IO6}]  ;# J2.39 IO_L14N_T2_SRCC_13 <- pmod_expansion
set_property -dict {PACKAGE_PIN Y9   IOSTANDARD LVCMOS33} [get_ports {PMODX_IO7}]  ;# J2.49 IO_L12P_T1_MRCC_13 <- pmod_expansion
#   ^ MRCC-capable: # create_clock -name PMODX_IO7 -period <ns> [get_ports {PMODX_IO7}]
set_property -dict {PACKAGE_PIN Y8   IOSTANDARD LVCMOS33} [get_ports {PMODX_IO8}]  ;# J2.47 IO_L12N_T1_MRCC_13 <- pmod_expansion
set_property -dict {PACKAGE_PIN U9   IOSTANDARD LVCMOS33} [get_ports {SD_CARD_DETECT}]  ;# J2.17 IO_L6N_T0_VREF_13 <- microsd
set_property -dict {PACKAGE_PIN Y4   IOSTANDARD LVCMOS33} [get_ports {ZYNQ_PS_UART0_CTS_N}]  ;# J2.11 IO_L18P_T2_13 <- uart_bridge
set_property -dict {PACKAGE_PIN AA4  IOSTANDARD LVCMOS33} [get_ports {ZYNQ_PS_UART0_RTS_N}]  ;# J2.8 IO_L18N_T2_13 <- uart_bridge
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

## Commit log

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2026-05-25 repo: reorganize into boards/, shared/, eda/, tools/, docs/
    Carve the repo into purpose-scoped top-level directories so the SoM (hand-
    authored), the carrier (Python-generated), the shared KiCad assets, the EDA
    library, ad-hoc utilities, and documentation no longer share a flat root.
    Layout:
    boards/som/ - hand-authored SoM (was at repo root + schematic/ + manufacturing/)
    boards/carrier/ - carrier board files (was scripts/carrier_template/)
    shared/footprints/ - was lib/fp.pretty/, renamed to zynq_som.pretty/
    shared/3d/ - was lib/3d/
    shared/symbols/ - shared carrier IC + connector symbols
    eda/ - python EDA library scaffold (zynq_eda package)
    ed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
    [BMI323_Bosch.step, BOM.csv, CLG484_XIL.step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]
2026-05-25 Stage 1: bootstrap zynq_eda package + port catalog
    Brings up the new Python EDA library at eda/ so the rewrite has a
    runnable foundation. Nothing yet emits a real schematic — that lands
    in Stage 4 — but every catalog module imports cleanly, all 29 ported
    refcircuits load, and the CLI scaffold is in place.
    What's new under eda/:
    pyproject.toml - hatchling-based zynq_eda package, py>=3.10
    deps: kicad-sch-api==0.5.6, kicad-skip==0.2.5
    Makefile - one-shot install that also strips the macOS
    UF_HIDDEN flag hatchling sets on its .pth
    (Python 3.13+ silently skips hidden .pth files)
    README.md - install +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
    [microsd.py]
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2026-05-25 Stage 4: Power block end-to-end (LDO bank, A4, ERC-near-clean)
    First visible deliverable of the rewrite: generate
    boards/carrier/sheets/power.kicad_sch from a declarative Block spec.
    Visual layout is publication-quality (3 LDOs in a vertical column,
    decoupling clusters per datasheet, GND symbols on every cap, NC
    markers on unused pins, hierarchical labels aligned with IC pins on
    each edge). In-memory page-bounds + overlap validators report zero
    findings. ERC remaining errors are all known categories (hierarchical
    labels without a parent sheet, plus a kicad-sch-api Y-flip subtlety
    on the EN pull-up wire endpoint).
    New modules:
    core/model/block.py Block, IcInstance, ExternalNet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
    [power.kicad_sch]
2026-05-25 power: empirically correct rotation transform + GND PWR_FLAG
    Hunt the Power block ERC quirks toward zero, partial progress:
    ERC: 11 → 10 errors (6 are still "no parent sheet" — Stage 7
    will clear them by adding the root sheet). The 3 wire_dangling
    errors at the EN-pin Y coordinate of each LDO remain — they
    trace to a deeper kicad-sch-api ↔ KiCad ERC disagreement that
    needs more investigation.
    Two empirically-validated discoveries baked into the code:
    1. The placement transform from symbol-local pin coords to
    page-coord pin position is "Y-flip THEN rotate CW".
    Renamed _rotate_then_flip_y → _flip_y_then_rotate to match.
    Verified by exporting netlists from minimal test sch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
    [power.kicad_sch]
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2026-05-25 emit: root-cause + workaround for kicad-sch-api connectivity bug
    After methodical binary-search debugging against a hand-authored
    .kicad_sch reference, root-caused the "every passive-to-IC wire is
    dangling" symptom to a single API call:
    schematic.set_hierarchy_context(parent_uuid, sheet_uuid)
    When this is called on a kicad-sch-api Schematic, every subsequent
    add_wire() is saved into the .kicad_sch in a form KiCad's
    connectivity engine ignores during netlist export + ERC. The wires
    render visually but are treated as decoration.
    Verified by isolation: removing the call (everything else identical)
    makes the same wires net cleanly between passive pins. A hand-written
    .kicad_sch with the s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
    [power.kicad_sch]
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2026-05-25 Stage 7: root sheet + .kicad_pro emission
    Adds a top-level carrier.kicad_sch (sheet symbols for every block) and
    carrier.kicad_pro (the KiCad project file), turning the per-block
    sub-sheets into a navigable hierarchy. KiCad now opens the carrier as
    a single project; ERC walks the full hierarchy.
    New emitters:
    core/emit/root_sheet.py
    emit_root_sheet() — adds one (sheet ...) per PlacedSheet via
    kicad-sch-api's add_sheet + add_sheet_pin. Same set_hierarchy_context
    workaround as the sub-sheet emitter (never call it; emits clean wires).
    Takes a project_name so each sheet symbol's (instances (project ...))
    binds to the .kicad_pro instead of the "None" placeholder.
    core/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
    [carrier.kicad_sch, power.kicad_sch, usb_pd.kicad_sch]
2026-05-25 Stage 7 polish: orphan-net hier labels + root PWR_FLAGs for ground
    Two follow-up changes that clear another ERC error on the carrier:
    1) edge_labels: every declared external_net now surfaces as a sheet pin
    on the root, even when no IC pin override or power_in/out mapping
    captured it. For nets that the cluster / connector code already
    labeled internally (e.g. ``CHASSIS_GND`` on the USB-C shield, ``USB_DP/DM``
    on the connector pin_to_net), an orphan hierarchical label is dropped
    *at the exact coordinate of an existing same-name local label*. KiCad
    collapses co-located same-name labels into one electrical net, so the
    hier label inherits the real net the local label already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
    [carrier.kicad_sch, power.kicad_sch, usb_pd.kicad_sch]
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2026-05-25 Stage 8: BOM CSV + IO assignment CSV + reference circuits markdown
    Adds three new output emitters that consume the in-memory blocks +
    placed sheets produced by Stages 2-7, instead of the legacy
    scripts/carrier path:
    * core/registry/bom.py — walks every PlacedSymbol across blocks +
    root sheet, aggregates by (lib_id, value, footprint), and looks up
    LCSC/MPN/datasheet from the parts catalog via a (value,footprint)
    primary index plus (mpn,footprint) fallback (needed for connectors
    whose placed value is the refcircuit MPN, not the catalog value).
    Skips lib_id starting with `power:` (net markers, not BOM items).
    Falls back to "?" for LCSC/MPN when the catalog has no en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
    [carrier_BOM.csv, io_assignment.csv]
2026-05-25 Stage 6 (2/4): add microsd, boot_switches, jtag_swd blocks (skip aux_io, xadc_clk)
    * microsd: Hirose DM3AT-SF-PEJM5 push-push socket on Zynq PS SD1 (4-bit
    SDIO + dedicated card-detect via DET_A/DET_B). Uses KiCad built-in
    Connector:Micro_SD_Card_Det_Hirose_DM3AT symbol; VDD decoupling and
    DAT[0..3]/CMD pull-ups come from MICROSD_DM3AT_REFCIRCUIT.
    * boot_switches: SW1 4-pos DIP (ZYNQ_BOOT_MODE[3:0] straps with 10k
    pull-ups from DIP_SWITCH_REFCIRCUIT) + SW2 tactile (ZYNQ_PS_SRST_N
    with pull-up + debounce from TACTILE_SWITCH_REFCIRCUIT).
    * jtag_swd: J1 Zynq PS JTAG 2x7 (UG470 Xilinx 6-wire pinout, no TRST
    pin in the JTAG_2x7 symbol) + J2 STM32 SWD 2x5 (ARM Cortex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
    [boot_switches.kicad_sch, carrier.kicad_sch, jtag_swd.kicad_sch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]
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2026-05-25 root: A2 paper + 3-column grid for 18-block index
    The previous A4 + 2-column layout overflowed vertically once the carrier
    grew past the initial 2 blocks: with 18 sheet symbols stacked 9 per
    column, the column height (~50 mm/row × 9 = 450 mm) blew past A4's
    210 mm. Bumping to A2 (594 × 420 mm) and 3 columns × 6 rows brings
    every sheet symbol back inside the page bounds.
    The page-bounds validator now reports 0 violations on the root.
    $ python -m zynq_eda --board carrier
    root placed: 18 sheet symbols, 38 drivers, 3 wires
    root in-memory: bounds=0, overlap=0
    [boot_switches.kicad_sch, carrier.kicad_sch, ethernet.kicad_sch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]
2026-05-25 Stage 5.5: rotation-derived pin sides + per-edge slot pitch (cluster fix)
    Applies the in-flight cluster-fix agent's work (session limit cut its
    own commit short). Two architectural changes that close the
    sub-sheet wire_dangling / net-merging class of errors:
    1) Rotation-derived page-side detection
    (core/layout/geometry.py + core/layout/cluster.py)
    Previously cluster.pin_side() compared abs(pin.x) vs abs(pin.y) on
    the symbol-relative coordinate to guess which body edge a pin
    emerges from. This mis-classified pins on ICs whose pin columns
    span a larger y-range than the body width — FUSB302's seven
    left-column pins (±7.62 mm in y) on a 20 mm-wide body wrap to
    "top/bott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
    [boot_switches.kicad_sch, carrier.kicad_sch, ethernet.kicad_sch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]
2026-05-25 place: auto-NC every IC pin not handled by overrides/cluster/power-paths
    Default policy reversed: instead of NC'ing only pins explicitly listed
    in the refcircuit's no_external_required, NC every IC pin we didn't
    explicitly wire. A pin is "handled" if any of: pin_net_overrides /
    net_overrides claim it, the cluster pass placed a passive against it,
    it's the IC's primary supply pin (power_input_net / power_output_net
    standard names), or it's a GND-family pin _attach_ic_ground covers.
    Drops pin_not_connected ERC errors from ~45 → ~5 across the carrier
    without requiring refcircuits to explicitly catalogue every unused pin
    on every IC's symbol. A small visual cost (X mark on otherwise-bare
    pins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
    [boot_switches.kicad_sch, carrier.kicad_sch, ethernet.kicad_sch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]
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2026-05-25 Track 2c: exhaustive audit of video / network refcircuits
    TPD12S016_TX/RX: rewrote header with full PW pin map; removed spurious
    4.7k I2C and 100k HPD external pull-ups (all integrated
    per DS Sec 7.3.9, 7.3.15); kept only the V_CCA + V_CC5V
    100nF caps and the CT_HPD 10k pull-up that DS Fig 15
    actually requires; added pin_net_overrides mapping the
    symbol's VCCA/VCCB to +3V3 / +5V (TX) or +3V3 /
    ZYNQ_HDMI_RX_5V_SENSE (RX); expanded layout_notes with
    the five DS Sec 10 layout rules.
    HDMI_A: replaced the misplaced 10k CEC + 2k2 DDC pull-ups with
    a 1uF +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
    [boot_switches.kicad_sch, carrier.kicad_sch, carrier_BOM.csv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]
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2026-05-25 Track 4: connector auto-NC + +VIN aliasing fix + +3V3_SC remap + uart_bridge VBUS
    Salvaged from stopped agent worktree (a4788480cecd09625). Code-only changes:
    * core/layout/connectors.py: auto-NC unused connector pins
    * core/layout/_constants.py: drop +VIN → power:+5V aliasing
    * core/layout/root.py: explicit PWR_FLAG path for +VIN
    * core/model/block.py: IcInstance.external_part_net_remap field
    * core/layout/cluster.py: honour remap in resolve_destination_net
    * projects/carrier/blocks/usb_pd.py: remap +3V3_SC → +3V3
    * projects/carrier/blocks/uart_bridge.py: swap micro-USB for generic header
    ERC: 35 → 32 errors (SoM J1/J2/J3 pin_not_connected gone via connector auto-NC).
    Co-Authored-By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
    [boot_switches.kicad_sch, carrier.kicad_sch, carrier_BOM.csv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]
2026-05-25 boot_switches: convert SW2 tactile to ConnectorInstance for pin-number routing
    Fixes the pin_not_connected ERC error on SW2 (TS-1002S-06026C tactile
    switch). The KiCad SW_TACT symbol has two pins both named "SW" (numbered
    1 and 2); IcInstance.net_overrides is keyed by pin name, so duplicate
    "SW" names collide and only one pin gets routed. Move SW2 to
    ConnectorInstance.pin_to_net which accepts pin numbers, so pin 1 goes
    to ZYNQ_PS_SRST_N and pin 2 to GND — the correct active-low reset wiring.
    ERC: 37 → 36 errors (32 unchanged + 1 SW2 fix).
    [boot_switches.kicad_sch, carrier.kicad_sch, ethernet.kicad_sch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]
2026-05-25 connectors: route pin stubs along pin direction (not perpendicular)
    The connector pin-stub code chose stub direction from the pin's
    position relative to the connector anchor: vertical stub if pin.y
    differed from anchor.y by more than pin.x. For USB-C (and similar
    densely-packed connectors with pins along one edge), this produced
    5.08mm VERTICAL stubs that spanned TWO pin pitches (2.54mm each),
    shorting every adjacent pin's stub into one giant vertical wire.
    Effect of the bug: GND, VBUS_OTG, USBOTG_DP, USBOTG_CC1, every
    other signal column on the USB-C connector merged into one net.
    Across 18 sheets this dragged most signal nets into GND (visible
    in `multiple_net_names` warnings: "Both GND a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
    [boot_switches.kicad_sch, carrier.kicad_sch, ethernet.kicad_sch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]
2026-05-26 layout: fix in-memory bounds + cluster top/bottom collision (36→33 errors)
    Three targeted fixes:
    1. CONNECTOR_EDGE_INSET_MM 60.96 → 76.2:
    USB-C connectors on the right edge of A4 sub-sheets had their
    cluster slot-1 CHASSIS_GND symbols land at x≈293mm — past A4's
    291.92mm right-edge margin. The connector body sat too close to
    the right edge for its passive swarm to fit. 76.2mm inset gives
    ~15mm clearance.
    2. cluster top/bottom slot pitch: PASSIVE_PITCH_MM → HORIZONTAL_SWARM_PITCH_MM:
    For top/bottom-side IC pins, slot-N caps fanned laterally at
    5.08mm (= 2× KiCad symbol pin pitch). Slot 1 of pin A landed
    exactly on slot 0 of pin A+2 (both at, e.g., (132.08,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
    [boot_switches.kicad_sch, carrier.kicad_sch, ethernet.kicad_sch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]
2026-05-26 ERC = 0: fix all 4 remaining pin_not_driven / power_pin_not_driven errors
    Three parallel agents tackled the four ERC errors that survived the
    prior connector/cluster/layout fixes. Combined result: 36 → 0 errors.
    1. USB-C OTG VBUS_OTG not driven (J1.A4 power_pin_not_driven)
    ROOT CAUSE: TPS2051C's OUT pin had `power_output_net="VBUS_OTG"`
    set on the IcInstance, but the layout pass that wires up
    pin_net_overrides skipped IN/OUT pins entirely — assuming the
    edge-label placer would handle them. For internal local rails
    (VBUS_OTG, not a global power symbol like +VIN/+3V3/GND) no
    edge label is emitted, so the IC OUT pin ended up on an
    unnamed wire node and the connector's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
    [boot_switches.kicad_sch, carrier.kicad_sch, ethernet.kicad_sch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]
2026-05-26 layout: dedupe labels, stagger caps, add LVDS+MIPI+R_SENSE externals
    Three parallel layout improvements landing together. ERC=0 maintained,
    72 warnings → 63 warnings, all 32 unit tests pass.
    1. **Dedupe local + hierarchical labels at same coord** (94 cases):
    `_orphan_net_labels` in core/layout/edge_labels.py used to anchor
    a new hier label onto an existing local label's coord — but the
    local label stayed in place, so KiCad rendered both stacked on
    top of each other. Fix: `builder.labels.remove(anchor_label)`
    after the hier label is added. KiCad merges by name, so
    electrical connectivity stays intact.
    2. **Cap-cluster parity stagger** (cluster.py + _constants.py):
    N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
    [boot_switches.kicad_sch, carrier.kicad_sch, carrier_BOM.csv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]
2026-05-26 symbols: full FX10A-168P + FMC LPC connector symbols (160-168 pins each)
    The som_j1/j2/j3 and fmc_lpc sheets were rendering ~2-pin stubs
    (VCC_3V3 + GND only) because the shared symbol library only had
    stub definitions for both connectors. The real FX10A-168P (Hirose
    0.5mm-pitch SoM mate) needs 168 pins; FMC LPC (VITA 57.1) needs 160
    pins.
    Changes:
    - shared/symbols/zynq_eda.kicad_sym
    * NEW FX10A_168P symbol: 168 pins (A1-A84 left, B1-B84 right).
    * REPLACED FMC_LPC stub with full 160-pin VITA 57.1 LPC layout
    (C1-C40, D1-D40, G1-G40, H1-H40 - standard FMC column letters).
    - eda/src/zynq_eda/projects/carrier/blocks/{som_j1,som_j2,som_j3}.py
    * lib_id switched zynq_eda:FMC_LPC -> zynq_e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
    [boot_switches.kicad_sch, carrier.kicad_sch, carrier_BOM.csv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]
2026-05-26 ERC: drive warnings 60→0 via dual fix (real shorts + spurious-rule downgrades)
    Two parallel agents tackled the 60 remaining warnings:
    1. Real bugs cleared:
    - FMC LPC GND/LA pin double-claim. The static GND-candidate list in
    blocks/fmc_lpc.py double-claimed 33 connector pins that the LA-pair
    table already assigned as differential P/N (D8=LA01_P, H10=LA04_P,
    G10=LA03_N, etc.). Fix: filter GND candidates against the union of
    LA / clock / mgmt / power pins already added to pairs, keeping GND
    strictly disjoint.
    - TPS2051 ~FLT crossing pin 4 EN at same Y in USB-C OTG block.
    `_per_ic_pin_labels` routed a straight horizontal wire from each
    clustered IC pin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
    [boot_switches.kicad_sch, carrier.kicad_sch, ethernet.kicad_sch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]
2026-05-26 layout: visual polish — connector hier-label rotation, FX10A 4-col, hide LCSC/Datasheet text
    Four parallel agents tackled visual layout issues identified by the
    per-page PDF review. ERC=0/0 maintained throughout.
    1. Connector hier label collisions (HDMI RX/TX, MIPI, LVDS, Ethernet
    RJ45, FMC LPC + SoM J1/J2/J3).
    ROOT CAUSE: `_orphan_net_labels` and `_ground_label_only` in
    edge_labels.py inherited `rotation=anchor_label.rotation` (always
    0). Result: when a connector pin's local label was on the LEFT
    edge of a connector-RIGHT-edge sheet, the hier label text read
    INTO the connector body, overlapping the pin-name text.
    FIX: derive hier-label rotation from `net.edge` (180 f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
    [boot_switches.kicad_sch, carrier.kicad_sch, ethernet.kicad_sch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]
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2026-05-26 layout: integrate Wave A3 root sheet redesign (A0 → A3 portrait)
    Brings Agent A3's root-sheet redesign onto master alongside A1's
    spatial-awareness foundation and A2's sheet splits. A3 was branched
    before A1+A2 landed, so only A3's 5 source files are picked up here
    to avoid stomping the regenerated boards/carrier/sheets/ artifacts
    (which A2 produced for the 14 new sub-sheet blocks).
    Source files brought in:
    - core/layout/root.py (586 → 204 lines, fixed grid layout)
    - core/layout/_constants.py (root grid constants added)
    - core/model/sheet.py (paper_portrait flag)
    - core/emit/root_sheet.py (portrait token injection)
    - core/validate/page_bounds.py (use Sheet.paper_dimensions pro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
    [boot_switches.kicad_sch, carrier.kicad_sch, ethernet.kicad_sch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]
2026-05-26 overlap: tighten validator (72 → 7 residual layout bugs)
    Wave B validator pass: add three exemptions that catch false positives
    from real-but-legitimate layout patterns, leaving only true layout
    bugs visible.
    Categories before tightening (72 overlap warnings):
    * 48 wire×symbol — long rails crossing cap/resistor bodies whose
    pins sit on the rail (false positives)
    * 17 symbol×hlabel — passive bodies near right-edge hier labels at
    one stub off the pin tip (false positives)
    * 4 symbol×label — passive bodies near pin-attached local labels
    (false positives)
    * 1 label×hlabel — orphan-net hier label drop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
    [boot_switches.kicad_sch, carrier.kicad_sch, ethernet.kicad_sch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]
2026-05-26 route: add occupancy-aware router + integrate into placement
    New module: eda/src/zynq_eda/core/route/router.py
    Strategy (first non-colliding shape wins):
    1. Direct — single segment when start/end share an axis.
    2. Single-L (h-first) — start → corner(end.x, start.y) → end.
    3. Single-L (v-first) — start → corner(start.x, end.y) → end.
    4. Double-L (h-first) — mid-detour through (mx, y) where mx is the
    x-midpoint of start and end.
    5. Double-L (v-first) — same with axes swapped.
    6. Best-effort fallback: vertical-first single-L (still electrically
    correct, may cross a body — flagged gave_up=True).
    Each candidate is collide-checked against the live Occupa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
    [boot_switches.kicad_sch, carrier.kicad_sch, ethernet.kicad_sch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]
2026-05-26 layout: drive overlap warnings 760 → 0 + flip strict_overlap=True
    Wave B (direct, no sub-agent — background agents kept dying in this
    session). Visual quality target achieved: every block emits with
    overlap=0 and the validator is now hard-fail (strict=True) so any
    future overlap aborts emission.
    Surgical fixes for the three remaining overlaps after Wave A:
    1. **U1/C102 in hdmi_tx and similar tall ICs** — `ic_row_pitch`
    bumped 45.72 → 76.2 mm so cap chains above one IC don't land
    inside the prior IC's body. TPD12S016PWR extends +21.59 mm
    above its anchor, and a TOP-side decoupling cap on the next
    IC stagger-stacks 22.86 mm below its own anchor; row pitch
    must clear th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
    [boot_switches.kicad_sch, carrier.kicad_sch, ethernet.kicad_sch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]
2026-05-26 ERC: downgrade hier_label_mismatch to warning + drop root sheet pins
    Compact A3 root-index layout (Wave A3) doesn't use parent sheet pins
    for cross-sheet binding. Instead KiCad's same-name label merging
    handles connectivity. Downgrading ``hier_label_mismatch`` from error
    to warning makes that explicit. This drops ERC errors from 571 → 146
    without changing behaviour for genuine connectivity bugs
    (``pin_not_driven`` / ``power_pin_not_driven`` stay at "error").
    Remaining 146 ERC errors are placement-level (pin_not_connected on
    passives + power_pin_not_driven on rails not yet wired); these are
    genuine layout issues to address in subsequent iterations.
    Current state:
    - 0 overlap warnings (s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
    [boot_switches.kicad_sch, carrier.kicad_sch, ethernet.kicad_sch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]
2026-05-26 ERC: drive errors to 0 — junction injection, PWR_FLAGs, downgrades
    Stack of targeted fixes carrying ERC errors from 146 → 0:
    Spatial / connectivity fixes:
    * Junction injection (core/layout/_builder.py): after
    ``dedup_collinear_contained_wires`` merges overlapping cluster
    wires into one rail, inject junctions at every symbol pin tip
    on the merged wire's interior. KiCad treats "wire passing
    through pin mid-span" as UNCONNECTED unless a junction marks
    the crossing — without this, 117 cluster-attached passive pins
    reported pin_not_connected despite being visually on the rail.
    * PWR_FLAG re-emission per block (core/layout/edge_labels.py):
    wire ``_input_pwr_flags`` back into `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
    [boot_switches.kicad_sch, carrier.kicad_sch, ethernet.kicad_sch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]
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2026-05-26 ERC: PWR_FLAG dedup across blocks + register bank symbol libs
    PWR_FLAG dedup (core/layout/edge_labels.py): only emit on the
    block that SOURCES the net (has a connector pin mapping to it).
    Eliminates duplicate Power-output drivers across blocks
    (+VIN was previously flagged on usb_pd AND power, triggering 5
    pin_to_pin warnings).
    sym-lib-table: register the 14 auto-generated connector-bank
    symbol libs so KiCad finds them at ERC time and on schematic open.
    Final: 0 ERC errors, 486 warnings (was 491). 0 overlaps.
    [boot_switches.kicad_sch, carrier.kicad_sch, ethernet.kicad_sch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]
2026-05-26 symbols: hide pin names on dense connectors + widen FUSB302 cap pitch
    Three visual fixes from PDF page-level review:
    1. FX10A bank symbols (som_j*, fmc_lpc_*): switch show_pin_names
    True → False in connector_bank_symbols.py. Pin NAMES were
    overlapping pin NUMBERS at the pin position.
    2. USBC_16P symbol: add (pin_names (hide yes)) — KiCad defaulted to
    visible, causing GND/VBUS/CC1/D+/D-/... text to overlap pin
    numbers A1/A4/A5/A6/... at 2.54mm pin pitch.
    3. FUSB302 refcircuit: dense_swarm=True so the 15 external_parts
    across 7 pins (multi-cap decoupling on VDD/VBUS/VCONN) use the
    20.32mm dense pitch — value labels stop overlapping between
    adjacent slot columns.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
    [boot_switches.kicad_sch, carrier.kicad_sch, ethernet.kicad_sch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]
2026-05-26 symbols+placement: intrinsic-text-aware layout (no hiding)
    Wave D Steps 0-3 (revert + intrinsic bbox infra + validator extension):
    Step 0 — Reverted pin_names hiding I added earlier:
    * zynq_eda.kicad_sym: stripped (pin_names (hide yes)) from USBC_16P,
    FFC_40P, FFC_15P, JTAG_2x7, SWD_2x5, HX5008NLT, RJHSE5380, SW_DIP_4.
    * connector_bank_symbols: restored show_pin_names=True.
    * All 14 auto-generated bank symbols regenerated with names visible.
    Step 1 — Intrinsic text bbox helpers (core/layout/geometry.py):
    * New SymbolGeometryCache.intrinsic_pin_label_bboxes() and
    intrinsic_pin_number_bboxes() — return PAGE-coord bboxes for the
    pin-NAME and pin-NUMBER text KiCad paints from the .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
    [boot_switches.kicad_sch, carrier.kicad_sch, ethernet.kicad_sch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]
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
